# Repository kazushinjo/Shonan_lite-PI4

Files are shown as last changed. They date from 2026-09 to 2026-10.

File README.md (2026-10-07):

# Shonan for RasPI4

Raspberry Pi 4 + ADALM-Pluto+によるDVB-S2 DATV送受信タッチGUIシステム。
本体は`pi4/`配下(Python/PyQt5。DFRobot DFR0550は`linuxfb`、公式DSIタッチ画面は`eglfs`で描画)。同系統の別プラットフォーム
移植版(Android/iOS)は別リポジトリ(`Shonan_Lite-android`/`Shonan_Lite-iPad`等)
で管理している。

A touch-GUI DVB-S2 DATV transceiver system using a Raspberry Pi 4 and an ADALM-Pluto+.
The application lives under `pi4/` (Python/PyQt5; drawn with `linuxfb` on the DFRobot DFR0550 and with `eglfs` on the
official DSI touch display). Ports to other platforms (Android/iOS) are maintained in separate repositories
(`Shonan_Lite-android`, `Shonan_Lite-iPad`, etc.).

> [!IMPORTANT]
> **Plutoのユーザー名(`root`)・パスワード(`analog`)はデフォルト値のまま変更しないでください。**
> 本アプリとLangstone V2Modifyは、SSHでPlutoにログインしてリブートや設定ファイルの書き込みを行っています
> (アプリ再起動・機器試験・送受信開始時・Langstone終了時)。変更するとPlutoをリブートできなくなります。
>
> **Keep the Pluto's username (`root`) and password (`analog`) at their default values.**
> This app and Langstone V2Modify log in to the Pluto via SSH to reboot it and write its settings file
> (at app restart, equipment test, TX/RX start and Langstone exit). If they are changed, the Pluto cannot be rebooted.

## 主な機能 / Features

- **送信**: 周波数・シンボルレート(250k〜2 Msym/s)・FEC・変調方式(QPSK/8PSK)・出力減衰量を画面で設定し、
  UDP-TSでPluto+へ送ってPluto内蔵の変調器(`pluto_dvb`)で送信する(Plutoの設定はSSHで`/www/settings.txt`へ
  書き込み、送信先ポートは8282固定)。FECは変調方式ごとに動作する組み合わせだけを選べる
  (QPSK: 1/2・3/5・8/9、8PSK: 3/5・8/9)。H.264はPi 4内蔵のハードウェアエンコーダ(`h264_v4l2m2m`)で符号化し、
  送信映像はフルHD(1920x1080)固定。音声はカメラ内蔵マイクをAAC(モノラル16kbps)で映像と一緒に送信する(マイクが無ければ無音)。送信画面には出力減衰(dB)、
  Plutoへ送ったUDPパケット数、符号化したフレーム数を表示する。
- **映像ソース**: USBカメラ・画像ファイル(静止画を反復送信)・テストパターンから選ぶ。USBカメラは
  1280x720で取り込む(対応していればMJPEG・30fps、非対応カメラは既定の解像度)。カメラ選択時は
  「撮影」ボタンで静止画(JPG、`~/Pictures/Shonan_Lite/`)を撮り、そのまま送信画像に使える。
  コールサイン・備考を文字サイズ・文字色を選んで映像へ焼き込める(日時も表示)。
- **受信**: 外部復調機器からのUDP-TS受信、またはGNU Radio(gr-dvbs2rx)によるPi 4上でのオンデバイス復調。
- **RSSI測定**: 周波数を掃引して受信レベルをグラフ表示する。オンデバイス復調OFF(通常運用)では
  相手局の電波を測り、ON(テスト用)では自局もテストパターンで自動送信して自分の信号を測る。
- **プリセット**: 現在の設定を5件まで登録・呼び出し(プリセット1は未登録の間RFループバック試験用)。
- **機器試験**: 「全体試験」でPlutoを再起動したうえで、Pluto SDR接続・送信テスト・受信テスト・
  温度センサー(Pi 4のCPU温度)の4項目を順に確認し、TX/RXの総合結果を表示する。実行中のボタンは赤で表示する。
- **10GHz受信(LNB)**: Home画面の衛星をタップすると、Langstone V2Modifyを10236.5 MHz表示・
  Pluto受信486.5 MHz(LNB局部発振9750 MHz)の受信専用バンドで開く。Shonan_Lite(DATV)でも、
  周波数画面で「10GHz帯」を押すとLNBを使用するか確認し、使用する場合は表示周波数10.2365 GHz・
  Pluto受信486.5 MHzで受信する(受信専用、送信不可。「いいえ」なら従来どおり10180 MHz)。下記参照。
- **PA/LNAの送受信切替**: 送信中はPi 4のGPIO21(40番ピン)がHIGHになる。ESP32 W5500
  (PA_Power/PTTコントローラ)を使わなくても、この信号でPA・LNAを切り替えられる。下記参照。
- **その他**: Pluto URIの自動検出、日本語/英語表示、日本語オンスクリーンキーボード、アプリ内Help、
  起動時のアプリ選択(Shonan_Lite / Langstone)。DFRobot DFR0550(`linuxfb`)と公式DSIタッチ画面(`eglfs`)に対応。

<!-- English -->

- **Transmit**: Set the frequency, symbol rate (250k–2 Msym/s), FEC, modulation (QPSK/8PSK) and attenuation on screen,
  send UDP-TS to the Pluto+ and transmit with the Pluto's built-in modulator (`pluto_dvb`) (the Pluto settings are
  written to `/www/settings.txt` via SSH; the destination port is fixed at 8282). Only FEC rates that work with each
  modulation can be selected (QPSK: 1/2, 3/5, 8/9; 8PSK: 3/5, 8/9). H.264 is encoded with the Pi 4's hardware encoder
  (`h264_v4l2m2m`), and the transmitted video is fixed at Full HD (1920x1080). Audio from the camera's built-in microphone is sent with the video as AAC (mono, 16 kbps); silence if no microphone is found. The TX screen shows
  the attenuation (dB), the number of UDP packets sent to the Pluto and the number of encoded frames.
- **Video source**: Choose from a USB camera, an image file (a still image transmitted repeatedly) or a test pattern.
  The USB camera is captured at 1280x720 (MJPEG at 30 fps if supported, otherwise the camera's default resolution).
  With the camera selected, the "Capture" button takes a still image (JPG, `~/Pictures/Shonan_Lite/`) that can be used
  directly as the transmit image. A callsign and a note can be burned into the video with a selectable text size and
  color (the date and time are shown as well).
- **Receive**: UDP-TS reception from an external demodulator, or on-device demodulation on the Pi 4 with GNU Radio (gr-dvbs2rx).
- **RSSI measurement**: Sweeps the frequency and graphs the received level. With on-device demodulation OFF (normal
  operation) it measures the other station's signal; with it ON (for testing) the station also transmits a test
  pattern automatically and measures its own signal.
- **Presets**: Save and recall up to 5 sets of settings (preset 1 is used for the RF loopback test while it is empty).
- **Equipment test**: "Full test" reboots the Pluto and then checks the Pluto SDR connection, TX test, RX test and
  temperature sensor (Pi 4 CPU temperature) in turn, and shows the overall TX/RX result. The running button is shown in red.
- **10 GHz reception (LNB)**: Tapping the satellite on the Home screen opens Langstone V2Modify on a receive-only band
  showing 10236.5 MHz, with the Pluto receiving at 486.5 MHz (LNB local oscillator 9750 MHz). In Shonan_Lite (DATV) as
  well, pressing "10GHz Band" on the Frequency screen asks whether to use an LNB; if so, it receives with the displayed
  frequency 10.2365 GHz and the Pluto receiving at 486.5 MHz (receive only, no transmit; "No" keeps 10180 MHz as before). See below.
- **PA/LNA TX/RX switching**: GPIO21 (pin 40) of the Pi 4 goes HIGH while transmitting. The PA and LNA can be switched
  with this signal even without the ESP32 W5500 (PA_Power/PTT controller). See below.
- **Other**: Automatic Pluto URI detection, Japanese/English display, Japanese on-screen keyboard, in-app Help, and
  application selection at boot (Shonan_Lite / Langstone). Supports the DFRobot DFR0550 (`linuxfb`) and the official DSI
  touch display (`eglfs`).

## スクリーンショット / Screenshots

実機(DFR0550、800x480)の画面(2026-09-25撮影)。映像はすべてテストパターンで撮影している。
送信画面は送信中、RSSI測定はオンデバイス復調ONで「1回」実行した結果(自局のテストパターン信号)。

Screens on the device (DFR0550, 800x480, taken on 2026-09-25). All video was taken with the test pattern.
The TX screen is shown while transmitting, and RSSI measurement shows the result of a "Once" run with on-device
demodulation ON (the station's own test-pattern signal).

| Home画面 / Home | 送信画面 / TX | 受信画面 / RX | RSSI測定 / RSSI |
| --- | --- | --- | --- |
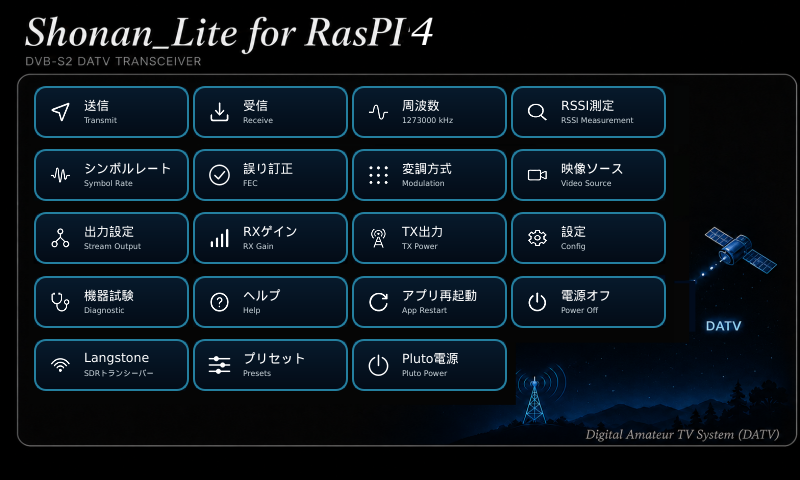
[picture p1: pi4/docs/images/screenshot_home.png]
Home画面
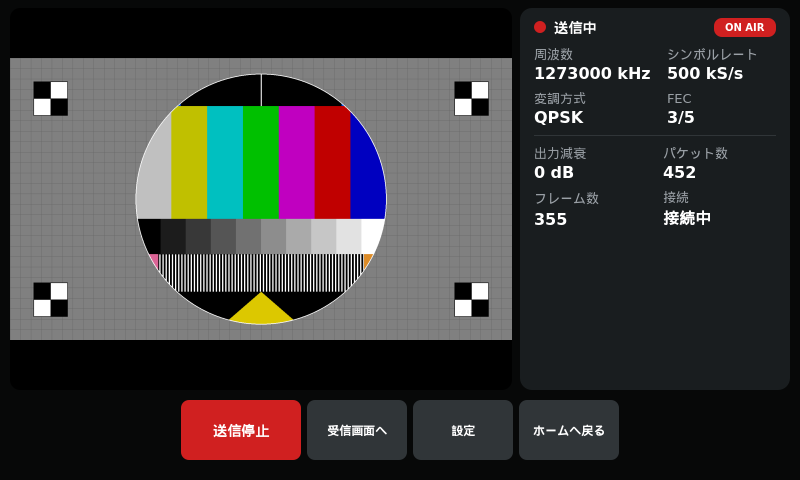
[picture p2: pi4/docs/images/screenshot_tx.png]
送信画面
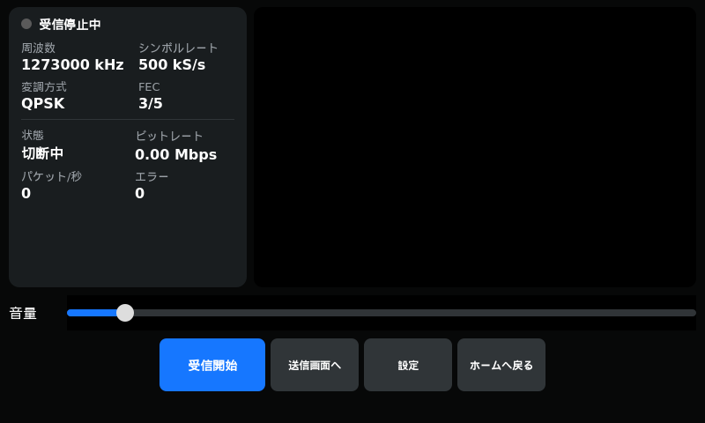
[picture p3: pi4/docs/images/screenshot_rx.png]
受信画面
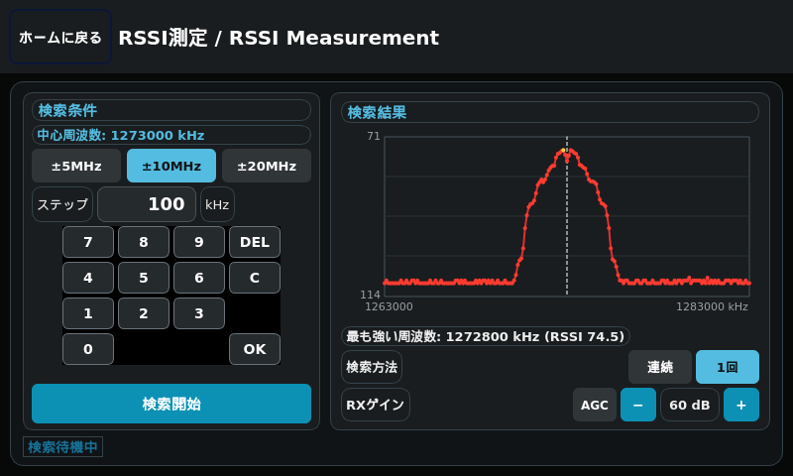
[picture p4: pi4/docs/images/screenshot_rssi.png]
RSSI測定
|  |  |  |  |

| 映像ソース / Video Source | 変調方式 / Modulation | 出力設定 / Stream Output | プリセット / Presets |
| --- | --- | --- | --- |
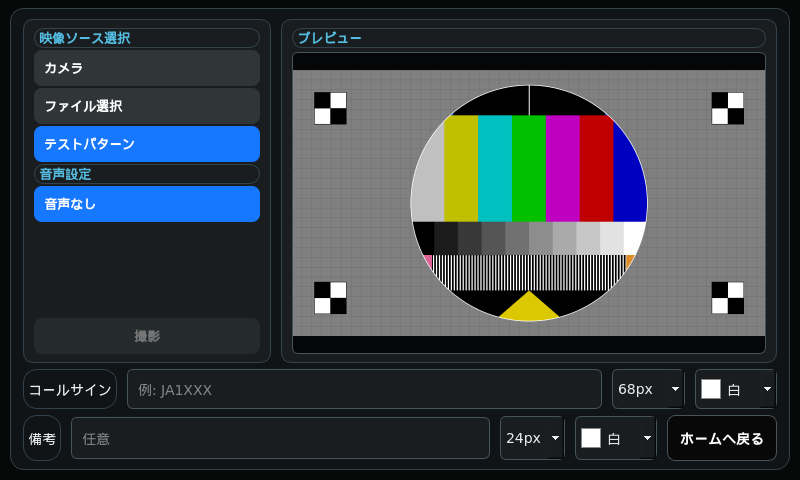
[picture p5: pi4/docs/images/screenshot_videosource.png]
映像ソース
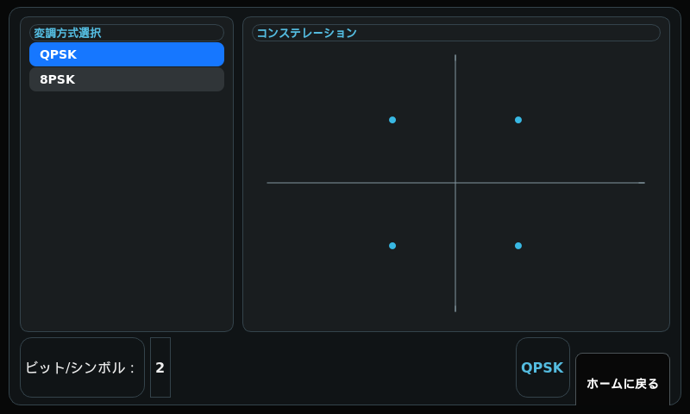
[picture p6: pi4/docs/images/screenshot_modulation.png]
変調方式
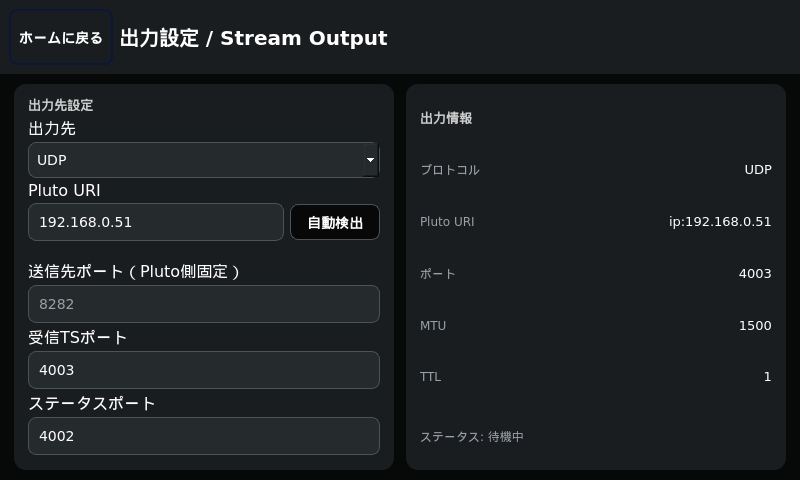
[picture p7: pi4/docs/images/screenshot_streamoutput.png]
出力設定
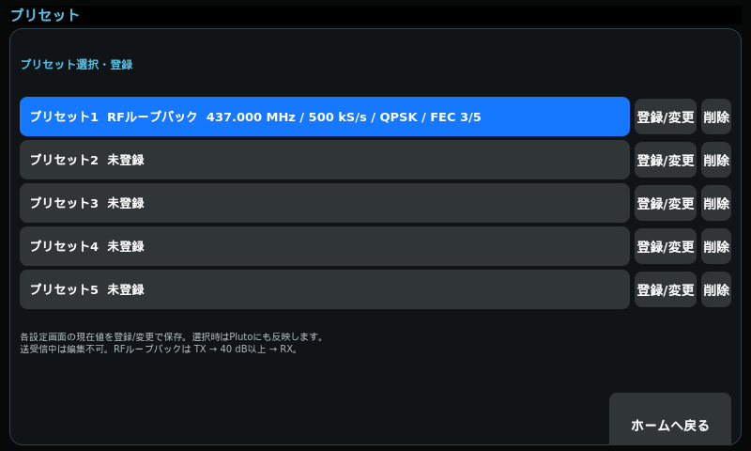
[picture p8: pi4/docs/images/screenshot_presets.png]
プリセット
|  |  |  |  |

| 機器試験 / Diagnostic | 設定 / Config | 周波数 / Frequency | 電源オフ / Power Off |
| --- | --- | --- | --- |
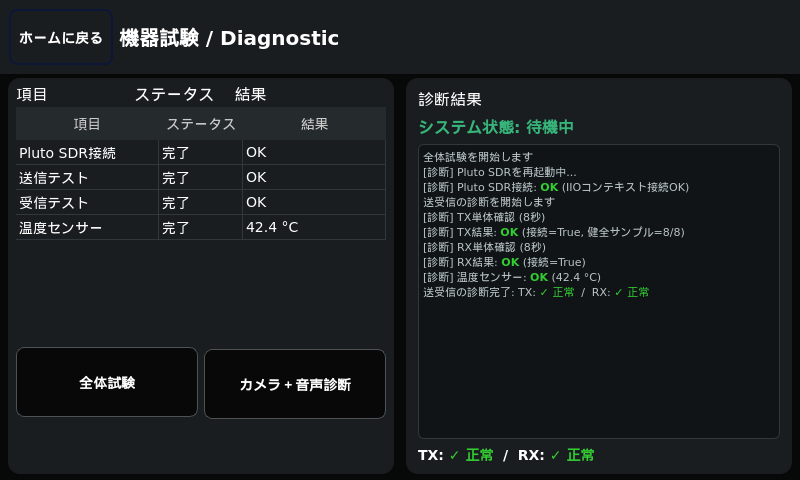
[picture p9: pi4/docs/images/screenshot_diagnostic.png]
機器試験
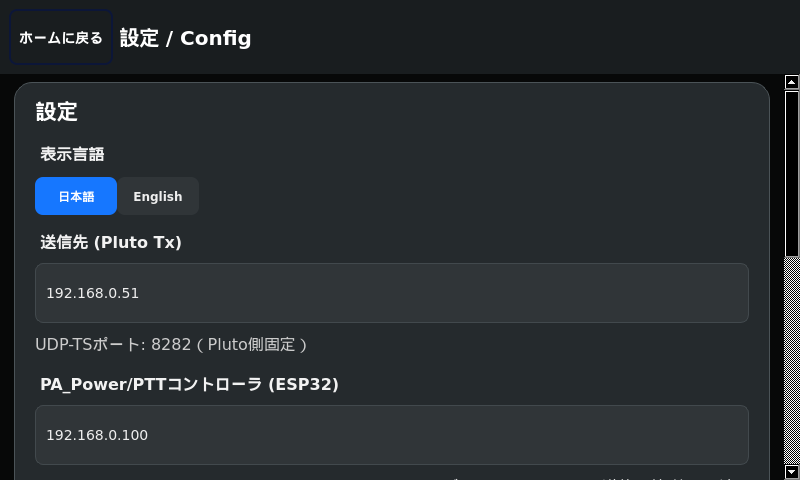
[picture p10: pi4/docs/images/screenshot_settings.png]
設定
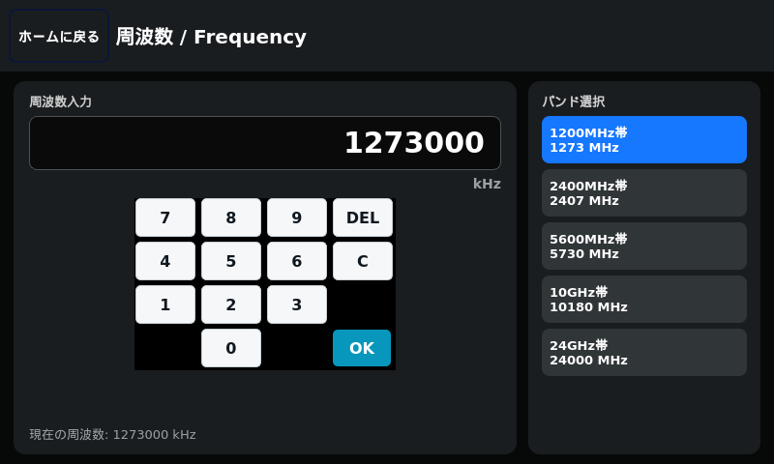
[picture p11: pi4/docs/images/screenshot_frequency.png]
周波数
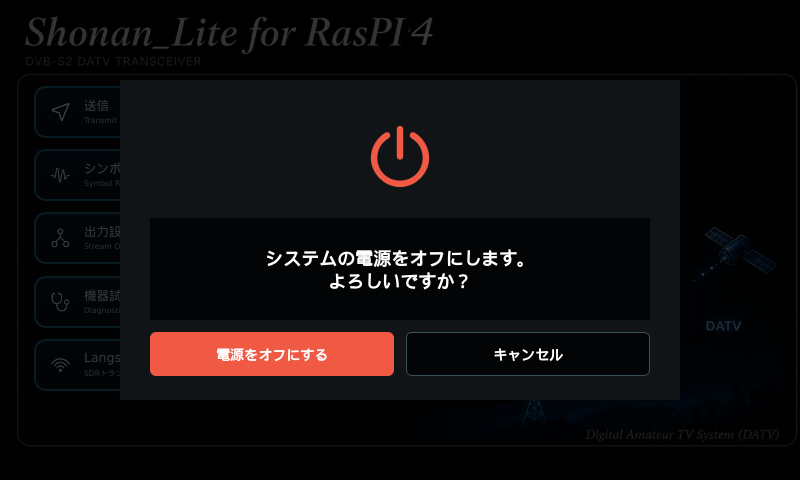
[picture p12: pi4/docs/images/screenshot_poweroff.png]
電源オフ
|  |  |  |  |

各画面の操作方法は、アプリ内の「ヘルプ」または操作説明書
[`pi4/docs/shonan_pi4_operation_manual.docx`](pi4/docs/shonan_pi4_operation_manual.docx)を参照。

For how to operate each screen, see the in-app "Help" or the operation manual
[`pi4/docs/shonan_pi4_operation_manual.docx`](pi4/docs/shonan_pi4_operation_manual.docx).

## インストール / Installation

### 0. Raspberry Pi OSのインストール / Installing Raspberry Pi OS

Pi4本体に、あらかじめRaspberry Pi OSをインストールしておく。

1. PCで[Raspberry Pi Imager](https://www.raspberrypi.com/software/)を起動する。
2. 「デバイスを選択」で **Raspberry Pi 4** を選ぶ。
3. 「OSを選択」で **Raspberry Pi OS (64-bit)** を選ぶ
   (★32bit版は不可。下記「実行条件」参照)。
4. 「ストレージを選択」で書き込み先のmicroSD/NVMeを選ぶ。
5. 歯車アイコン(詳細設定)で、ホスト名・ユーザー名/パスワード・Wi-Fi・SSH有効化を
   事前設定しておくと、初回起動後すぐSSH接続できる。
6. 「書き込む」を実行し、完了後microSD/NVMeをPi4に取り付けて起動する。
7. PCから`ssh <ユーザー名>@<ホスト名>.local`で接続できることを確認する。

Install Raspberry Pi OS on the Pi 4 beforehand.

1. Start [Raspberry Pi Imager](https://www.raspberrypi.com/software/) on a PC.
2. Under "Choose Device", select **Raspberry Pi 4**.
3. Under "Choose OS", select **Raspberry Pi OS (64-bit)**
   (★the 32-bit version does not work; see "Requirements" below).
4. Under "Choose Storage", select the microSD/NVMe to write to.
5. In the gear icon (advanced options), pre-configure the hostname, username/password, Wi-Fi and SSH
   so that you can connect via SSH right after the first boot.
6. Run "Write", then attach the microSD/NVMe to the Pi 4 and boot it.
7. Check that you can connect from the PC with `ssh <username>@<hostname>.local`.

### 1. install.shの実行 / Running install.sh

SSH接続したPi4上で / On the Pi 4 connected via SSH:

```sh
git clone https://github.com/kazushinjo/Shonan_lite-PI4.git
cd Shonan_lite-PI4
./pi4/scripts/install.sh          # HTTPSでclone(既定) / clone via HTTPS (default)
# ./pi4/scripts/install_ssh.sh    # GitHubにSSH鍵を登録済みならこちらでも可 / or this if your SSH key is registered on GitHub
```

日本語入力ビルド・受信(RX)用GNU Radio/gr-dvbs2rxビルド・Langstone V2Modifyビルドは
それぞれ省略して時間短縮できる(省略した機能は使えなくなる):

The Japanese input build, the GNU Radio/gr-dvbs2rx build for RX and the Langstone V2Modify build can each be
skipped to save time (the skipped features will not be available):

```sh
SKIP_JA_KEYBOARD=1 SKIP_GNURADIO_BUILD=1 SKIP_LANGSTONE_BUILD=1 ./pi4/scripts/install.sh
```

★OSを新規インストールした直後の初回実行では、DFR0550をfirmwareのレガシーDSI表示で
動かすため、`install.sh`が最初に`/boot/firmware/config.txt`の`dtoverlay=vc4-kms-v3d`・
`display_auto_detect=1`・`disable_fw_kms_setup=1`をコメントアウトし、`dtparam=i2c_arm=on`を
追記して終了する。案内に従ってPi4を再起動(`sudo reboot`)し、同じコマンドを再実行すると
ビルドへ進む(KMS有効のままビルドすると画面・タッチが使えないうえ、実機が再起動して
パッケージが破損することを確認している)。

★On the first run right after a fresh OS install, to drive the DFR0550 with the firmware's legacy DSI display,
`install.sh` first comments out `dtoverlay=vc4-kms-v3d`, `display_auto_detect=1` and `disable_fw_kms_setup=1` in
`/boot/firmware/config.txt`, adds `dtparam=i2c_arm=on`, and exits. Reboot the Pi 4 as instructed (`sudo reboot`) and
run the same command again to proceed to the build (building with KMS enabled leaves the display and touch unusable,
and we confirmed that the device reboots and packages get corrupted).

完了後、`shonan-gui.service`がsystemdに登録されGUIが自動起動する。あわせて
`/boot/firmware/config.txt`へ`avoid_warnings=1`(電源電圧警告アイコンの表示抑制)
を未設定なら自動で追記する(反映には再起動が必要)。

When finished, `shonan-gui.service` is registered with systemd and the GUI starts automatically. It also adds
`avoid_warnings=1` (suppresses the under-voltage warning icon) to `/boot/firmware/config.txt` if not already set
(a reboot is required for it to take effect).

### 実行条件 / Requirements

一般ユーザーが実行して`install.sh`が正常完了するには、以下が必要。

- **Raspberry Pi OS 64bit(aarch64)であること**(32bit版不可)
- **`git`が事前にインストール済み**であること
- **GitHub/apt配布ミラーへのインターネット到達性**
- **sudoが使える対話的な実行**(パスワード入力に応答できるtty)
- **`patch`コマンドが使えること**

For `install.sh` to complete successfully when run as a normal user, the following are required.

- **Raspberry Pi OS 64-bit (aarch64)** (the 32-bit version does not work)
- **`git` installed beforehand**
- **Internet access to GitHub and the apt mirrors**
- **Interactive execution with sudo** (a tty that can answer the password prompt)
- **The `patch` command available**

詳細な各手順の解説・トラブルシュートは
[`pi4/docs/install_script_guide.md`](pi4/docs/install_script_guide.md)
(DOCX版: `pi4/docs/install_script_guide.docx`)を参照。

For a detailed explanation of each step and troubleshooting, see
[`pi4/docs/install_script_guide.md`](pi4/docs/install_script_guide.md)
(DOCX version: `pi4/docs/install_script_guide.docx`).

## オプション: ESP32 W5500(PA_Power/PTTコントローラ) / Option: ESP32 W5500 (PA_Power/PTT controller)

ESP32とW5500(有線LAN)で、PA等の12 V電源とPTTをLAN経由でON/OFFするオプションの制御基板。
使わなくてもShonan_Liteは動作する(PTTだけなら下記のPi 4 GPIO21で切替できる)。
ファームウェアは[`hardware/W5500_PA_PTT_Control/W5500_PA_PTT_Control.ino`](hardware/W5500_PA_PTT_Control/W5500_PA_PTT_Control.ino)、
基板は[`hardware/W5500_PA_PTT_Control/kicad/`](hardware/W5500_PA_PTT_Control/kicad/)(KiCad、Rev.1.0)。基板とファームウェアはShonan_Lite-RasPI5版と共通。

| 基板の3D表示 / 3D view of the board | 基板レイアウト(KiCad) / PCB layout (KiCad) | ケース(OpenSCAD) / Case (OpenSCAD) |
| --- | --- | --- |
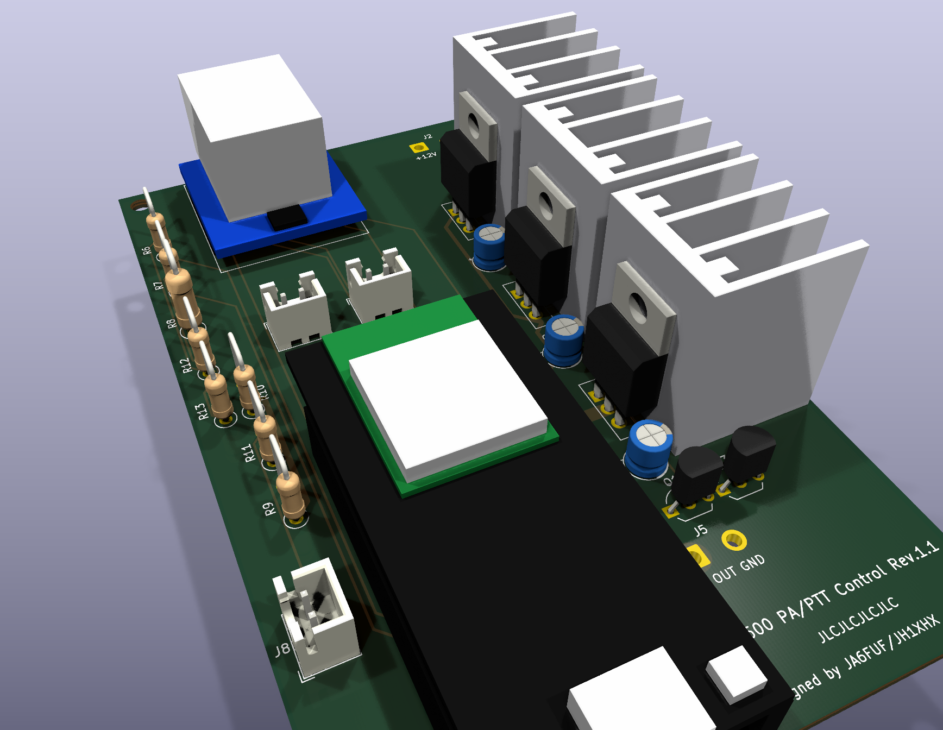
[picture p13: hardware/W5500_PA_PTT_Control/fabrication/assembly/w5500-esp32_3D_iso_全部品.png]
基板の3D表示
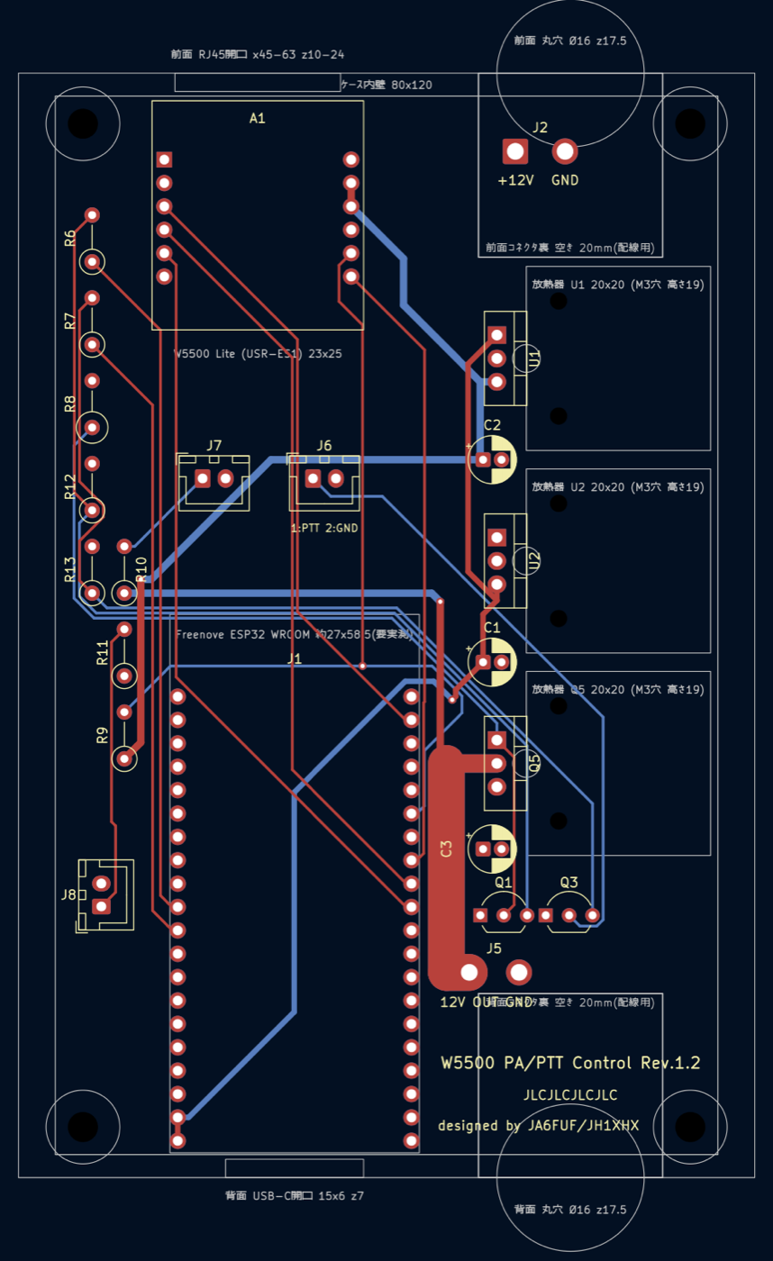
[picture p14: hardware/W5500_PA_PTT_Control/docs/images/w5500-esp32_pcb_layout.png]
基板レイアウト
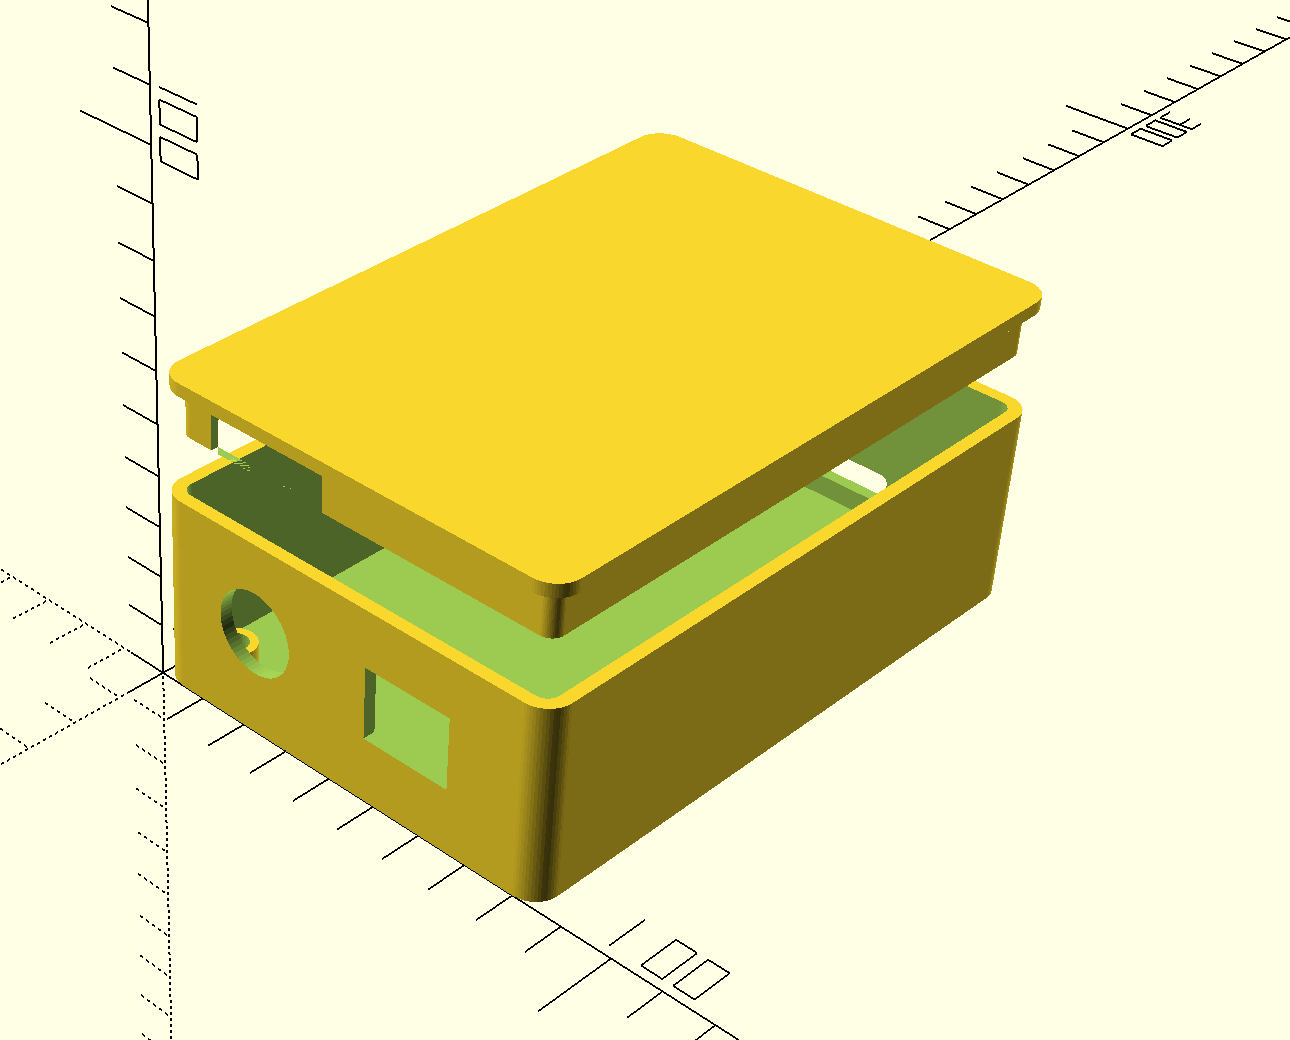
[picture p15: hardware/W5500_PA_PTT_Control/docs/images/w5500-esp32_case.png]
ケース
|  |  |  |

| 項目<br>Item | 内容<br>Details |
| --- | --- |
| 構成<br>Configuration | Freenove ESP32-WROOM-32E DevKitC(ソケットに差し込み)+W5500 Lite(SPI接続)<br>Freenove ESP32-WROOM-32E DevKitC (plugged into a socket) + W5500 Lite (SPI) |
| 12 V電源<br>12 V power | 2SJ334(Pチャネル MOSFET)のハイサイドスイッチでJ5の12 V出力をON/OFF。放熱器付きで目安は約7 Aまで<br>J5's 12 V output is switched by a 2SJ334 (P-channel MOSFET) high-side switch; with its heatsink, up to about 7 A |
| PTT<br>PTT | 2SC1815で無線機のPTT端子をGNDへ落とす(J6)<br>A 2SC1815 pulls the radio's PTT line to GND (J6) |
| 電源入力<br>Power input | +12 V(13.8 V系)をJ2へ。L7805で5 V(ESP32)、TA48033Sで3.3 V(W5500)を作る<br>+12 V (13.8 V class) to J2; an L7805 makes 5 V (ESP32) and a TA48033S makes 3.3 V (W5500) |
| 表示LED<br>Indicator LEDs | 外付け。J7=12 V出力(赤)、J8=12 V入力(緑)(JST XH)<br>External; J7 = 12 V output (red), J8 = 12 V input (green) (JST XH) |
| ネットワーク<br>Network | 固定IP(初期値`192.168.0.100`)。ブラウザで`http://<IP>/`を開くと手動でON/OFFでき、`http://<IP>/config`でIPや遅延時間を変更できる<br>Static IP (default `192.168.0.100`); open `http://<IP>/` in a browser to switch ON/OFF manually, and `http://<IP>/config` to change the IP and delays |
| 基板<br>Board | 72×115 mm、4層(内層はGNDと+12Vのベタ)、部品はすべてスルーホール。JLCPCBの発注データは[`fabrication/jlcpcb/`](hardware/W5500_PA_PTT_Control/fabrication/jlcpcb/)<br>72×115 mm, 4 layers (inner layers are GND and +12 V planes), all through-hole parts. JLCPCB order data is in [`fabrication/jlcpcb/`](hardware/W5500_PA_PTT_Control/fabrication/jlcpcb/) |
| ケース<br>Case | OpenSCAD(LAN_PTT.scad)、内寸80×120×35 mm。前面にRJ45の角穴と+12V入力の丸型コネクタ、背面にUSBの穴と12 V出力・PTTの丸型コネクタ<br>OpenSCAD (LAN_PTT.scad), inside 80×120×35 mm. RJ45 opening and +12 V input circular connector on the front; USB opening and 12 V output/PTT circular connector on the back |

Shonan_Liteでの使い方:

- 設定画面の「PA_Power/PTTコントローラ (ESP32)」で「ESP32 W5500を使用する」をONにし、ESP32のIPアドレスを入力する。
- アプリの起動/終了に連動して12 V電源(Pluto含む)を、送信開始/終了に連動してPTTを自動でON/OFFする(Langstone V2Modifyの送信でもPTTが切り替わる)。
- ホーム画面の「Pluto電源」カードで、12 V系統を手動で電源サイクル(OFF→3秒待機→ON)できる。

詳しくは[仕様書](hardware/W5500_PA_PTT_Control/docs/W5500_PA_PTT_Control_仕様書.md)と
[接続一覧](hardware/W5500_PA_PTT_Control/docs/MCU1_J1_W5500_接続一覧.md)を参照(どちらも日英併記。Word版・PDF版も同じフォルダにある)。
回路図: [`w5500-esp32.pdf`](hardware/W5500_PA_PTT_Control/kicad/w5500-esp32.pdf)、
実装図: [`w5500-esp32_実装図_部品番号.pdf`](hardware/W5500_PA_PTT_Control/fabrication/assembly/w5500-esp32_実装図_部品番号.pdf)。

> [!NOTE]
> ESP32への書き込みと起動は確認済み。12 V電源・PTTの駆動回路と無線機をつないだ実地試験はまだ行っていない。

<!-- English -->

An optional control board that uses an ESP32 and a W5500 (wired LAN) to switch the 12 V power for the PA etc.
and the PTT ON/OFF over the LAN. Shonan_Lite works without it (PTT alone can be switched with the Pi 4 GPIO21 below).
The firmware is [`hardware/W5500_PA_PTT_Control/W5500_PA_PTT_Control.ino`](hardware/W5500_PA_PTT_Control/W5500_PA_PTT_Control.ino)
and the board is in [`hardware/W5500_PA_PTT_Control/kicad/`](hardware/W5500_PA_PTT_Control/kicad/) (KiCad, Rev.1.0). The board and firmware are shared with the
Shonan_Lite-RasPI5 edition.

How to use it with Shonan_Lite:

- On the Settings screen, turn on "Use ESP32 W5500" under "PA_Power/PTT Controller (ESP32)" and enter the ESP32's IP address.
- The 12 V power (including the Pluto) is switched ON/OFF with app start/exit, and the PTT with TX start/stop (PTT also follows TX in Langstone V2Modify).
- The "Pluto Power" card on the Home screen power-cycles the 12 V line manually (OFF → wait 3 s → ON).

For details, see the [specification](hardware/W5500_PA_PTT_Control/docs/W5500_PA_PTT_Control_仕様書.md) and the
[connection list](hardware/W5500_PA_PTT_Control/docs/MCU1_J1_W5500_接続一覧.md) (both in Japanese and English;
Word and PDF versions are in the same folder).
Schematic: [`w5500-esp32.pdf`](hardware/W5500_PA_PTT_Control/kicad/w5500-esp32.pdf);
assembly drawing: [`w5500-esp32_実装図_部品番号.pdf`](hardware/W5500_PA_PTT_Control/fabrication/assembly/w5500-esp32_実装図_部品番号.pdf).

> [!NOTE]
> Flashing and booting the ESP32 have been confirmed. A field test with the 12 V power/PTT drive circuits
> connected to a radio has not been done yet.

## PA/LNAの送受信切替(ESP32 W5500なしでも可) / PA/LNA TX/RX switching (possible without ESP32 W5500)

ESP32 W5500(PA_Power/PTTコントローラ、[`hardware/W5500_PA_PTT_Control`](hardware/W5500_PA_PTT_Control))は
使わなくても、RasPI4からのPTT ON信号でPA・LNAの送受信切替を制御できる。

| 項目<br>Item | 内容<br>Details |
| --- | --- |
| 出力ピン<br>Output pin | Pi 4 GPIO21(40番ピン)、GNDは39番ピン<br>Pi 4 GPIO21 (pin 40), GND on pin 39 |
| 論理<br>Logic | 送信中HIGH(3.3 V)、受信中LOW<br>HIGH (3.3 V) while transmitting, LOW while receiving |
| 対象<br>Applies to | Shonan_Liteの送信・Langstone V2Modifyの送信(Langstone標準のTx Output)のどちらも同じピン<br>Both Shonan_Lite TX and Langstone V2Modify TX (Langstone's standard Tx Output) use the same pin |

- GPIO21は3.3 Vロジックで電流を取れないため、トランジスタやリレードライバ等でバッファしてから
  PA・LNA(同軸リレー等)を駆動すること。
- Shonan_Liteは送信開始時(映像送出の前)にHIGH、送信停止時とアプリ起動時にLOWにする
  ([`pi4/gui/backend.py`](pi4/gui/backend.py)の`_set_pi_tx_gpio()`、`pinctrl`で出力)。
- ESP32 W5500を併用する場合は、送信の開始/停止に連動してESP32のPTT出力(J6)も同時に切り替わる
  (`/tx?state=on|off`)。12 V電源のON/OFFとホーム画面の「Pluto電源」カードはESP32 W5500が必要。
  ESP32を使うかどうかは設定画面の「ESP32 W5500を使用する」で選ぶ(OFFにしてもIPアドレスは保持される)。

<!-- English -->

The PA and LNA can be switched between TX and RX by the PTT ON signal from the RasPI4, even without the
ESP32 W5500 (PA_Power/PTT controller, [`hardware/W5500_PA_PTT_Control`](hardware/W5500_PA_PTT_Control)).

- GPIO21 is a 3.3 V logic output that cannot supply current. Buffer it with a transistor, relay driver or
  similar before driving the PA and LNA (coax relays, etc.).
- Shonan_Lite sets it HIGH when TX starts (before the video is sent) and LOW when TX stops and at app startup
  (`_set_pi_tx_gpio()` in [`pi4/gui/backend.py`](pi4/gui/backend.py), driven with `pinctrl`).
- When the ESP32 W5500 is also used, its PTT output (J6) switches together with TX start/stop (`/tx?state=on|off`).
  Switching the 12 V power ON/OFF and the "Pluto Power" card on the Home screen require the ESP32 W5500. Whether to use
  the ESP32 is selected with "Use ESP32 W5500" on the Settings screen (the IP address is kept even when OFF).

## Langstone V2Modify(SDRトランシーバー)への切替 / Switching to Langstone V2Modify (SDR transceiver)

Home画面の「Langstone」カードから、`kazushinjo/Langstone-V2Modify`
(VHF/UHF/マイクロ波帯SDRトランシーバー、ADALM-Pluto対応)へ切り替えられる。
Langstone V2ModifyはQt eglfsとは別に`/dev/fb0`を直接描画する独立アプリのため、
DATV送受信アプリとは同時起動できない。`shonan-gui.service`/`langstone.service`/
`shonan-boot-menu.service`はsystemdの`Conflicts=`で互いに排他制御されるため、
Pi4自体は再起動せず、サービスを直接切り替える。

- Shonan_Lite Home画面の「Langstone」カード → DATVの送受信を止めてLangstone V2Modifyが起動
- Langstone V2Modifyの設定メニュー内「GOTO SHONAN_LITE」ボタン → Shonan_Lite Home画面に戻る

切替時間を短くするため、切替のときはPluto+を再起動しない(Pi5版で、再起動しなくても両アプリの
送受信が正常に動くことを確認済み)。ただしLangstoneは受信中に送信LOを止めたまま終了するため、
戻るときはLangstone側・Shonan_Lite側の両方で送信LOを元に戻す。Shonan_Liteは起動時(電源投入時を含む)に
Pluto+を再起動しない(ホーム画面の「アプリ再起動」と、Langstoneを「GOTO SHONAN_LITE」以外で終了したときは再起動する)。
Langstone側は`/tmp/langstone_goto_shonan`、Shonan_Lite側は`/tmp/shonan_switch_from_langstone`
の印で切替かどうかを判断する。

Langstone V2Modify is a standalone app that draws directly to `/dev/fb0` separately from Qt eglfs, so it cannot run at
the same time as the DATV app. `shonan-gui.service`, `langstone.service` and `shonan-boot-menu.service` are mutually
exclusive through systemd's `Conflicts=`, so the services are switched directly without rebooting the Pi 4.

- "Langstone" card on the Shonan_Lite Home screen → DATV TX/RX is stopped and Langstone V2Modify starts
- "GOTO SHONAN_LITE" button in the Langstone V2Modify settings menu → returns to the Shonan_Lite Home screen

To shorten the switching time, the Pluto+ is not rebooted when switching (confirmed on the Pi 5 version that both apps
transmit and receive normally without a reboot). However, Langstone exits with the TX LO powered down while receiving,
so the TX LO is restored on both the Langstone side and the Shonan_Lite side when returning. Shonan_Lite does not
reboot the Pluto+ when it starts (including at power-up); it is rebooted by "App Restart" on Home and when Langstone
exits other than via "GOTO SHONAN_LITE".
The Langstone side uses the `/tmp/langstone_goto_shonan` marker and the Shonan_Lite side uses
`/tmp/shonan_switch_from_langstone` to tell whether it is a switch.

内部的には`~/.pi4_boot_mode_langstone`マーカーファイルの有無をsystemdの
`ConditionPathExists`で判定し、`shonan-gui.service`/`langstone.service`の
どちらを起動すべきかを決める。

Internally, systemd's `ConditionPathExists` checks for the `~/.pi4_boot_mode_langstone` marker file to decide whether
`shonan-gui.service` or `langstone.service` should start.

ウォーターフォール/スペクトラム表示は幅約512px→約790pxへ拡張済み
(FFT点数自体はGNU Radio側のfft_size=512のまま、SCALEPX()マクロで描画のみ
引き伸ばしている。帯域インジケータ・目盛り・タッチ判定も含め一貫して変換)。
横方向にはSQLボタン(x=30〜130)/Volボタン(x=660〜)と同じY帯で重なり広げる
余地が無かったため、スペクトラム欄の高さ(80→55px)とウォーターフォールの
表示履歴行数(130→90行)を縮めて表示位置を上に詰め、SQL/Vol/RITいずれとも
Y方向に重ならない帯(Y=130〜295)に収めることで横方向をほぼ画面全幅まで
広げた(実機で確認)。
統合元は`kazushinjo/Langstone-V2Modify`で、Pi 4 + DFRobot DFR0550 +
ADALM-Pluto向けの修正を含む。

The waterfall/spectrum display has been widened from about 512 px to about 790 px (the number of FFT points stays at
fft_size=512 on the GNU Radio side; only the drawing is stretched by the SCALEPX() macro, applied consistently to the
bandwidth indicator, scale and touch detection). Since there was no room to widen it horizontally in the same Y band as
the SQL button (x=30–130) and Vol button (x=660–), the spectrum area height (80 → 55 px) and the number of waterfall
history rows (130 → 90) were reduced and the display moved up into a band (Y=130–295) that does not overlap SQL/Vol/RIT
vertically, which allows it to extend to nearly the full screen width (confirmed on the device). It is integrated from
`kazushinjo/Langstone-V2Modify` and includes fixes for the Pi 4 + DFRobot DFR0550 + ADALM-Pluto.

`kazushinjo/Langstone-V2Modify`が更新された場合は、
[`pi4/scripts/update_langstone_from_upstream.sh`](pi4/scripts/update_langstone_from_upstream.sh)
で同梱コピーを更新できる。更新後はShonan切替用のマーカー処理・受信専用バンド(`bandRxOnly`)など、
統合固有の差分を確認してから使用すること。

When `kazushinjo/Langstone-V2Modify` is updated, the bundled copy can be updated with
[`pi4/scripts/update_langstone_from_upstream.sh`](pi4/scripts/update_langstone_from_upstream.sh).
After updating, check the integration-specific differences, such as the Shonan switching markers and the receive-only
band (`bandRxOnly`), before use.

### 10GHz受信(LNB) — Home画面の衛星をタップ / 10 GHz reception (LNB) — tap the satellite on the Home screen

Home画面の背景右側の衛星をタップすると、Langstone V2Modifyを**10GHz受信用のバンド**で
開く(普通の「Langstone」カードと同じく、Plutoは再起動しない)。アンテナ側で
LNB(局部発振9750 MHz)を使い、10 GHz帯を486.5 MHzへ下げて受信する前提。

Tapping the satellite on the right side of the Home screen background opens Langstone V2Modify on a
**band for 10 GHz reception** (as with the normal "Langstone" card, the Pluto is not rebooted).
This assumes an LNB (local oscillator 9750 MHz) on the antenna side that converts the 10 GHz band down to 486.5 MHz.

| 項目<br>Item | 値<br>Value |
| --- | --- |
| 画面の表示周波数<br>Displayed frequency | 10236.500 MHz(10.2365 GHz)<br>10236.500 MHz (10.2365 GHz) |
| Plutoの受信周波数<br>Pluto receive frequency | 486.5 MHz(= 10236.5 − 9750) |
| 受信オフセット<br>Receive offset | −9750 MHz(LNB 局部発振 9750 MHz)<br>−9750 MHz (LNB local oscillator 9750 MHz) |
| 送信<br>Transmit | **不可**(受信専用)<br>**Not possible** (receive only) |

- Langstoneの24バンドのうち、通常使われない最後のバンド(番号23、画面上は24番目)を
  このために使う。衛星をタップするたびに、Shonan_Liteが`~/Langstone/Langstone_Pluto.conf`
  のこのバンドを上の値に設定し直してから開く([`pi4/gui/langstone_config.py`](pi4/gui/langstone_config.py))。
- 486.5 MHzはアマチュアバンド外のため、このバンドは**受信専用**
  (設定ファイルの`bandRxOnly23 1`、Langstone側の改造)。画面のPTT・ハードウェアPTT・
  CWキー・ビーコンのいずれでも送信せず、PA_Power/PTTコントローラも送信に切り替えない。
  PTTボタンは灰色の「RX ONLY」表示になり、Plutoの送信LOも停止させる。
- 普通の「Langstone」カードで開いたときは、衛星から開く前に使っていたバンドに戻して開く
  (Langstone上で別のバンドに切り替えていた場合は、そのバンドのまま)。
- Shonan_Lite(DATV)で10GHzをLNB受信する場合は、衛星ではなく周波数画面の「10GHz帯」を押し、
  「LNBを使用しますか?」で「はい」を選ぶ(表示10.2365 GHz、Pluto受信486.5 MHz、受信専用で送信不可。
  受信画面・RSSI測定もPluto受信周波数で動作する)。他のバンドを選ぶとLNBは解除される。
- LNBへの電源供給(同軸経由のバイアスT、12〜18 V)はShonan_Lite/Langstoneでは扱わない。
  別途用意すること。

<!-- English -->

- Of Langstone's 24 bands, the last one, which is not normally used (number 23, the 24th on screen), is used for this.
  Every time the satellite is tapped, Shonan_Lite resets this band in `~/Langstone/Langstone_Pluto.conf` to the values
  above before opening ([`pi4/gui/langstone_config.py`](pi4/gui/langstone_config.py)).
- Because 486.5 MHz is outside the amateur bands, this band is **receive only** (`bandRxOnly23 1` in the configuration
  file, a modification on the Langstone side). It does not transmit from the on-screen PTT, hardware PTT, CW key or
  beacon, and does not switch the PA_Power/PTT controller to transmit. The PTT button is shown grayed out as "RX ONLY",
  and the Pluto's TX LO is also stopped.
- When opened from the normal "Langstone" card, it returns to the band that was in use before opening from the
  satellite (if you switched to another band in Langstone, it stays on that band).
- To receive 10 GHz via an LNB in Shonan_Lite (DATV), press "10GHz Band" on the Frequency screen (not the satellite)
  and answer "Yes" to "Use an LNB?" (displayed 10.2365 GHz, Pluto RX 486.5 MHz, receive only with no transmit; the RX
  screen and RSSI measurement also use the Pluto RX frequency). Selecting another band cancels the LNB.
- Power for the LNB (bias-T over the coax, 12–18 V) is not handled by Shonan_Lite/Langstone. Provide it separately.

## 関連ドキュメント / Related documents

- [`pi4/docs/install_script_guide.md`](pi4/docs/install_script_guide.md) — install.shの詳細ガイド / Detailed guide to install.sh(英語版 / English: [`install_script_guide_en.md`](pi4/docs/install_script_guide_en.md))
- [`pi4/docs/qtvirtualkeyboard_ja_build.md`](pi4/docs/qtvirtualkeyboard_ja_build.md) — 日本語オンスクリーンキーボードのビルド手順・ハマりどころ / Build steps and pitfalls for the Japanese on-screen keyboard
- [`pi4/docs/shonan_pi4_operation_manual.docx`](pi4/docs/shonan_pi4_operation_manual.docx) / [`pi4/gui/manual_content.py`](pi4/gui/manual_content.py) — GUIの操作説明書(アプリ内Helpと同内容。英語のHelpは`pi4/gui/screens/manual.py`) / Operation manual for the GUI (same content as the in-app Help; the English Help is in `pi4/gui/screens/manual.py`)
- [`pi4/docs/build_operation_manual.py`](pi4/docs/build_operation_manual.py) — 操作説明書(DOCX)の生成スクリプト(`python pi4/docs/build_operation_manual.py`、python-docxが必要) / Script that generates the operation manual (DOCX) (requires python-docx)
- [`hardware/W5500_PA_PTT_Control/docs/W5500_PA_PTT_Control_仕様書.md`](hardware/W5500_PA_PTT_Control/docs/W5500_PA_PTT_Control_仕様書.md) — ESP32 W5500(PA_Power/PTTコントローラ)の仕様書 / Specification of the ESP32 W5500 (PA_Power/PTT controller)(日英併記 / Japanese and English)
  - 仕様書・接続一覧のWord版・PDF版は[`hardware/W5500_PA_PTT_Control/docs/tools/build_docs.py`](hardware/W5500_PA_PTT_Control/docs/tools/build_docs.py)でMarkdownから作る(macOSで実行) / The Word and PDF versions of the specification and connection list are generated from Markdown with this script (run on macOS)
- [`hardware/W5500_PA_PTT_Control/docs/MCU1_J1_W5500_接続一覧.md`](hardware/W5500_PA_PTT_Control/docs/MCU1_J1_W5500_接続一覧.md) — ESP32・W5500の接続一覧 / Connection list of the ESP32 and W5500(日英併記 / Japanese and English)
- [`hardware/W5500_PA_PTT_Control/kicad/`](hardware/W5500_PA_PTT_Control/kicad/) — ESP32 W5500制御基板のKiCad回路図・基板 / KiCad schematic and PCB of the ESP32 W5500 control board
- [`pi4/third_party/rpi-dvbs2-receiver-gui/`](pi4/third_party/rpi-dvbs2-receiver-gui/) — GNU Radio/gr-dvbs2rx受信フローグラフの参考実装(kazushinjo/rpi-dvbs2-receiver-guiより取り込み) / Reference implementation of the GNU Radio/gr-dvbs2rx receive flowgraph (imported from kazushinjo/rpi-dvbs2-receiver-gui)

## 免責事項 / Disclaimer

1. **無保証・自己責任 / No warranty; use at your own risk**  
   本ソフトウェアは現状のまま(AS IS)で提供され、動作、品質、特定の目的への適合性を含め、いかなる保証もありません。本ソフトウェアの使用または使用できないことによって生じた、機器の破損、データの消失、電波障害、その他一切の損害について、開発者は責任を負いません。ご自身の責任においてご利用ください。  
   This software is provided "AS IS" without warranty of any kind, including any warranty of operation, quality or fitness for a particular purpose. The developers accept no liability for any damage arising from the use of, or inability to use, this software, including damage to equipment, loss of data and radio interference. Use it at your own risk.
2. **免許と法令の順守 / Licensing and compliance with the law**  
   本ソフトウェアは、アマチュア無線のDATV(デジタルATV)実験のための送受信ソフトウェアです。電波を送信するには、運用する国・地域の法令に基づく免許が必要です(日本国内ではアマチュア局の免許)。周波数、空中線電力、電波の型式、運用できる範囲などの法令(日本国内では電波法および関係規則)を守ってください。免許のない送信や、免許の範囲を超えた送信は、法令違反となることがあります。本ソフトウェアは、設定された周波数・出力・変調方式が法令に適合していることを確認も保証もしません。送信の内容と結果は、すべて使用者の責任です。  
   This software is for amateur-radio DATV (digital ATV) experiments. Transmitting requires a license under the laws of the country or region where you operate (in Japan, an amateur station license). Observe the applicable laws on frequency, transmitter power, emission type and permitted operation (in Japan, the Radio Act and related regulations). Transmitting without a license, or beyond the scope of your license, may violate the law. This software neither checks nor guarantees that the configured frequency, power and modulation comply with the law. You are solely responsible for what you transmit and for the results.
3. **機器の取り扱い / Handling of equipment**  
   PlutoのTXとRXの接続、外部アンプ(PA)・アッテネータ・アンテナの接続、送信出力の設定、GPIO21やPA_Power/PTTコントローラ(ESP32 W5500)の12 V電源・PTTの配線を誤ると、機器を破損したり、他の無線局へ障害を与えたりするおそれがあります。機器の仕様を確認し、使用者の責任で行ってください。特に、TXをRXへ直接接続せず、40 dB以上の減衰器を介してください。  
   Wrong connections between the Pluto's TX and RX, wrong external amplifier (PA), attenuator or antenna connections, wrong transmit power settings, or wrong wiring of GPIO21 or of the 12 V power/PTT of the PA_Power/PTT controller (ESP32 W5500) may damage equipment or interfere with other stations. Check the specifications of your equipment and do this at your own responsibility. In particular, never connect TX directly to RX; use an attenuator of 40 dB or more.
4. **第三者ソフトウェアとライセンス / Third-party software and license**  
   本ソフトウェアは、GNU Radio、gr-dvbs2rx、libiio、FFmpeg、Qt(PyQt5・Qt Virtual Keyboard)、Langstone V2(Langstone-V2Modify)などの第三者ソフトウェアを利用・同梱します。それぞれのライセンスに従います。本ソフトウェア自体は GNU General Public License v3.0(GPLv3)の下で提供されます(下記「License」参照)。  
   This software uses and bundles third-party software such as GNU Radio, gr-dvbs2rx, libiio, FFmpeg, Qt (PyQt5, Qt Virtual Keyboard) and Langstone V2 (Langstone-V2Modify), each under its own license. This software itself is provided under the GNU General Public License v3.0 (GPLv3); see "License" below.
5. **動作について / About behavior**  
   ご使用のRaspberry Pi・環境によって動作が異なる場合や、未発見の不具合が含まれる可能性があります。  
   Behavior may differ depending on your Raspberry Pi and environment, and undiscovered defects may remain.

## クレジット / Credits

- 受信部の方式考案・受信部原システム設計: 山崎慎慈氏(JE1BTA)
  rpi-dvbs2-receiver-guiの設計に基づきます
- 受信部安定化調査修正・再捕捉修正・本アプリ開発: 真城和一
- 本アプリは、Dave Crump氏(G8GKQ)が開発したDATV送受信機プロジェクト「Portsdown」に啓発され、開発したものです。同氏の先駆的な取り組みに感謝いたします。
- Langstone V2(SDRトランシーバー): Colin Durbridge氏(G4EML)の[g4eml/Langstone-V2](https://github.com/g4eml/Langstone-V2)
  (Pi 4 + DFRobot DFR0550 + ADALM-Pluto向けに改造した`kazushinjo/Langstone-V2Modify`を
  [`pi4/third_party/Langstone-V2Modify/`](pi4/third_party/Langstone-V2Modify/)に同梱)

<!-- English -->

- Reception method and original reception system design: Shinji Yamazaki (JE1BTA),
  based on the design of rpi-dvbs2-receiver-gui
- Reception stability investigation and fixes, re-acquisition fixes, and development of this app: Kazuichi Shinjo
- This application was developed inspired by "Portsdown", the DATV transceiver project created by Dave Crump (G8GKQ). We extend our deep gratitude for his pioneering work.
- Langstone V2 (SDR transceiver): [g4eml/Langstone-V2](https://github.com/g4eml/Langstone-V2) by Colin Durbridge (G4EML)
  (`kazushinjo/Langstone-V2Modify`, modified for the Pi 4 + DFRobot DFR0550 +
  ADALM-Pluto, is bundled in [`pi4/third_party/Langstone-V2Modify/`](pi4/third_party/Langstone-V2Modify/))

## License

本ソフトウェアはGNU General Public License v3.0(GPLv3)の下で提供されます。
ライセンス全文: [LICENSE](LICENSE)

This software is licensed under the GNU General Public License v3.0 (GPLv3).
Full license text: [LICENSE](LICENSE)

- Langstone V2 (SDR transceiver, [g4eml/Langstone-V2](https://github.com/g4eml/Langstone-V2); bundled as `kazushinjo/Langstone-V2Modify`): GPLv3
- Reception subsystem design (Shinji Yamazaki, JE1BTA): GPLv3
- Application development, reception stability fixes (Kazuichi Shinjo): GPLv3

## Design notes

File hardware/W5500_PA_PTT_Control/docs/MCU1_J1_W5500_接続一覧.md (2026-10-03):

---
title: MCU1 / J1 / W5500(A1) 接続一覧 / MCU1 / J1 / W5500 (A1) Connection List
---

# MCU1 / J1 / W5500(A1) 接続一覧 / MCU1 / J1 / W5500 (A1) Connection List

本書は日本語と英語を併記している。各節で日本語の後に英語が続く。表は各欄に日本語と英語を並べて書く。

This document is written in both Japanese and English. In each section, the Japanese text is followed by the English text.
In the tables, each cell gives the Japanese and then the English.

KiCad回路図(`hardware/W5500_PA_PTT_Control/kicad/w5500-esp32.kicad_sch`)の
netlistから抽出した、MCU1(ESP32 DevKitC、参考表示のみ・DNP)・J1(実体のDevKitC
ソケット)・A1(W5500_Lite)間の対応表。

MCU1は回路図上の参考表示シンボルでDNP(実装しない)。実体はJ1に挿し込むFreenove
DevKitC基板のため、SPI信号(CS/SCK/MISO/MOSI)はMCU1側では別ネット名(ラベルのみ)
であり、実際の結線はJ1-A1間の直接ワイヤ。

J1は2026-08-30に実機(Freenove ESP32-WROOM-32E DevKitC)の実ピン配列に合わせて
2x19(38ピン)から2x20(40ピン)へ修正した。さらに2026-08-31、MCU1もJ1と同じ
`project_symbols:ESP32_DevKitC_Socket_40P`シンボルに置き換え、**MCU1のピン番号・
信号名はJ1と完全に一致**するようになった（従来はMCU1がESP32-WROOM-32モジュール
自体のパッド番号(KiCad標準`RF_Module:ESP32-WROOM-32`ライブラリ)を使っていたため、
J1のソケットピン番号と一致しなかった）。以下の表のピン番号はMCU1・J1共通。

A mapping table between MCU1 (ESP32 DevKitC, reference display only, DNP), J1 (the actual DevKitC socket) and A1
(W5500_Lite), extracted from the netlist of the KiCad schematic (`hardware/W5500_PA_PTT_Control/kicad/w5500-esp32.kicad_sch`).

MCU1 is a reference-display symbol on the schematic and is DNP (not populated). The actual part is the Freenove
DevKitC board plugged into J1, so the SPI signals (CS/SCK/MISO/MOSI) have separate net names (labels only) on the MCU1
side, and the actual wiring is direct wires between J1 and A1.

On 2026-08-30, J1 was corrected from 2x19 (38 pins) to 2x20 (40 pins) to match the actual pinout of the real board
(Freenove ESP32-WROOM-32E DevKitC). Furthermore, on 2026-08-31 MCU1 was also replaced with the same
`project_symbols:ESP32_DevKitC_Socket_40P` symbol as J1, so **MCU1's pin numbers and signal names now match J1
exactly** (previously MCU1 used the pad numbers of the ESP32-WROOM-32 module itself (KiCad standard
`RF_Module:ESP32-WROOM-32` library), which did not match J1's socket pin numbers). The pin numbers in the table below
are common to MCU1 and J1.

> 2026-09-30、フットプリントを実物の資料に合わせて2点修正した。
> - A1(W5500 Lite)は、USR-ES1データシート(Jinan USR IOT「3.3 Dimensions」)に合わせて、ピン列の間隔を15.24mmから20.32mmへ、
>   7〜12番の並びを1〜6番と同じくRJ45側から数える順に修正した(従来は7番がRJ45と反対側で、右列の信号が逆につながっていた)。
>   フットプリント名は`W5500_Lite_USR-ES1_2x06_P2.54mm_20.32mm`。
> - J1(DevKitCソケット)は、Freenove公式のピン配置図(部品面から見た図)に合わせて、ピンの並びを上下反転した。
>   1番(5V)・21番(GND)がUSB-C側、20番(3V3)・40番(GND)がアンテナ側になる(従来は鏡像の並びで、5Vが3V3やGNDのピンにつながる配置だった)。

> On 2026-09-30, two footprints were corrected to match the documentation of the actual parts.
> - A1 (W5500 Lite): per the USR-ES1 datasheet (Jinan USR IOT, "3.3 Dimensions"), the row spacing was changed from 15.24 mm to 20.32 mm,
>   and pins 7–12 now count from the RJ45 end like pins 1–6 (previously pin 7 was at the end opposite the RJ45, so the right-row signals were
>   connected in reverse). The footprint name is `W5500_Lite_USR-ES1_2x06_P2.54mm_20.32mm`.
> - J1 (DevKitC socket): per Freenove's official pinout diagram (seen from the component side), the pin order was flipped vertically.
>   Pins 1 (5V) and 21 (GND) are at the USB-C end and pins 20 (3V3) and 40 (GND) at the antenna end (previously the order was a mirror image,
>   placing 5V on the 3V3 or GND pins).

| 信号<br>Signal | MCU1/J1ピン<br>MCU1/J1 pin | W5500(A1)ピン<br>W5500 (A1) pin | 備考<br>Notes |
|---|---|---|---|
| SPI CS | GPIO5 (31) | CS (5) | MCU1側は別ネット名(ラベルのみ)、実配線はJ1-A1間<br>Separate net name on the MCU1 side (label only); actual wiring is between J1 and A1 |
| SPI SCK | GPIO18 (32) | SCK (4) | 同上<br>Same as above |
| SPI MISO | GPIO19 (33) | MISO (12) | 同上<br>Same as above |
| SPI MOSI | GPIO23 (39) | MOSI (3) | 同上<br>Same as above |
| W5500 RST | GPIO21 (35) | RST (11) | 3者同一ネット(GPIO制御リセット。ファームウェアで起動時にパルス送出)。R9(10kΩ)で+3V3_Aへプルアップ<br>Same net for all three (GPIO-controlled reset; the firmware sends a pulse at startup). Pulled up to +3V3_A by R9 (10 kΩ) |
| POWER(12V電源)制御<br>POWER (12 V power) control | GPIO26 (11) | — | W5500非接続。ネットラベルは`GPIO26_PA`だが、実体は12V電源のON/OFF制御（下表参照）<br>Not connected to the W5500. The net label is `GPIO26_PA`, but it actually controls the 12 V power ON/OFF (see the table below) |
| PTT制御<br>PTT control | GPIO27 (10) | — | W5500非接続。ネットラベルは`GPIO27_PTT`。無線機PTT端子をGND側へ落とす方式（下表参照）<br>Not connected to the W5500. The net label is `GPIO27_PTT`. Pulls the radio's PTT terminal to GND (see the table below) |
| GND | GND (7, 21〜24, 40) | 1, 2, 7 | 共通GND。J1は7・21〜24・40番をGNDに接続(34番のみ未結線。ボード内部でつながっている)<br>Common GND. On J1, pins 7, 21–24 and 40 are connected to GND (only pin 34 is left unconnected; it is connected inside the board) |
| +5V(`+5v0`、DevKitC基板給電)<br>+5 V (`+5v0`, DevKitC board supply) | 5V (1, 2) | — | U2(L7805、+12V→+5V)から供給。MCU1(ESP32モジュール自体)は3.3V駆動のため対応ピンなし。DevKitC基板上のオンボードLDOがこの5VをESP32モジュール用3.3Vへ変換する<br>Supplied from U2 (L7805, +12 V → +5 V). MCU1 (the ESP32 module itself) runs on 3.3 V and has no corresponding pin. The on-board LDO of the DevKitC board converts this 5 V to 3.3 V for the ESP32 module |
| +3.3V(ESP32系)<br>+3.3 V (ESP32 side) | 3.3V (3) | — | DevKitC基板のオンボードLDO出力(上記+5Vから生成)。MCU1(ESP32モジュール)のVDDピンへの供給元。J1・MCU1とも他に3.3Vピンが4,5,20にあるが未結線<br>Output of the DevKitC board's on-board LDO (generated from the +5 V above). The supply for the VDD pin of MCU1 (the ESP32 module). J1 and MCU1 also have 3.3 V pins at 4, 5 and 20, which are unconnected |
| +3V3_A(W5500専用)<br>+3V3_A (W5500 only) | — | VCC (8, 9) | 上記と同じ`+5v0`(U2の出力)をU1(LM2940T-3.3、+5V→+3.3V)が受けて生成。ESP32側3.3V(DevKitC基板内蔵LDO経由)とは生成回路が別だが、元の5Vは共通<br>Generated by U1 (LM2940T-3.3, +5 V → +3.3 V) from the same `+5v0` (U2 output) as above. The generating circuit is separate from the ESP32 side's 3.3 V (via the DevKitC board's built-in LDO), but the source 5 V is common |

未使用: A1のINT(6)・NC(10)、J1・MCU1の残りGPIOピン(GPIO13,GPIO12,GPIO14,GPIO33,GPIO32,
GPIO35,GPIO34,VN,VP,EN,GPIO15,GPIO2,GPIO0,GPIO4,GPIO16,GPIO17,RX,TX,GPIO22)は
今回未接続。

Unused: A1's INT (6) and NC (10), and the remaining GPIO pins of J1/MCU1 (GPIO13, GPIO12, GPIO14, GPIO33, GPIO32,
GPIO35, GPIO34, VN, VP, EN, GPIO15, GPIO2, GPIO0, GPIO4, GPIO16, GPIO17, RX, TX, GPIO22) are not connected this time.

> MCU1シンボルは回路図上「参考表示のみ・DNP」であり、実体はJ1に挿さるFreenove
> DevKitC基板そのものを表す。2026-08-31以降はJ1と同じ`project_symbols:
> ESP32_DevKitC_Socket_40P`シンボルを使っており、DevKitC基板自体には無いESP32
> モジュール固有のフラッシュ用ピン(SD0〜SD3/CMD/CLK等)は表示されない。
>
> ESP32モジュールチップ自体は3.3V駆動で5V入力ピンを持たないため、+5V系統に
> MCU1側の対応ピンは存在しない……という制約は旧シンボルの話であり、現行の
> DevKitCソケット表示では「5V」ピンも(実際にDevKitC基板が受電する電源として)
> 表示されるが、本回路では未結線のまま。実際に+5Vを受電するのはJ1に挿さる
> Freenove DevKitC基板側であり、基板上のオンボードLDOでの5V→3.3V変換は
> この回路図の範囲外（DevKitC基板内部）である。
>
> W5500(A1)用の+3V3_Aは、MCU1(DevKitC基板)用の+5Vと**同じ`+5v0`ネット**
> （U2=L7805の出力）をU1(LM2940T-3.3)がさらに3.3Vへ降圧して生成する。
> すなわち12V→5Vへの降圧はU2(L7805)1系統のみで、そこからMCU1用とW5500用の
> 2方向に分岐する構成（外付けDCDCバックコンバータモジュールは使用しない）。

> The MCU1 symbol is "reference display only, DNP" on the schematic and represents the Freenove DevKitC board itself
> plugged into J1. Since 2026-08-31 it uses the same `project_symbols:ESP32_DevKitC_Socket_40P` symbol as J1, so the
> ESP32-module-specific flash pins (SD0–SD3/CMD/CLK, etc.) that the DevKitC board itself does not have are not shown.
>
> The constraint that "the ESP32 module chip itself runs on 3.3 V and has no 5 V input pin, so there is no corresponding
> MCU1 pin for the +5 V system" applied to the old symbol. With the current DevKitC socket display, the "5V" pin is also
> shown (as the power the DevKitC board actually receives), but it remains unconnected in this circuit. What actually
> receives the +5 V is the Freenove DevKitC board plugged into J1, and the 5 V → 3.3 V conversion by its on-board LDO is
> outside the scope of this schematic (inside the DevKitC board).
>
> The +3V3_A for the W5500 (A1) is generated by U1 (LM2940T-3.3) further stepping down to 3.3 V **the same `+5v0` net**
> (U2 = L7805 output) as the +5 V for MCU1 (DevKitC board). In other words, the 12 V → 5 V step-down is a single system
> through U2 (L7805), which branches in two directions from there, for MCU1 and for the W5500 (no external DC-DC buck
> converter module is used).

GPIO25(J1・MCU1ピン12)はRev.1.1時点でLNA制御用ネット(`GPIO25_LNA`)としてラベル付けされていたが、
本表・下表いずれの駆動回路にも接続されておらず、現行回路では未使用（PA_Power/PTTコントローラ
の対象外）。2026-10-01、回路図に残っていた`GPIO25_LNA`ラベルを削除し、J1・MCU1の12番ピンを未接続(×)にした。

GPIO25 (J1/MCU1 pin 12) was labeled as the LNA control net (`GPIO25_LNA`) as of Rev.1.1, but it is not connected to any
drive circuit in this table or the table below and is unused in the current circuit (outside the scope of the
PA_Power/PTT controller). On 2026-10-01 the leftover `GPIO25_LNA` label was removed from the schematic, and pin 12 of J1
and MCU1 was marked as no-connect (×).

## POWER(12V電源)・PTT 駆動回路の接続詳細 / POWER (12 V Power) and PTT Drive Circuit Connection Details

GPIO26・GPIO27はW5500とは独立に、以下の駆動回路経由でJ5(Power)・J6(PTT_ON)へ接続される。

GPIO26 and GPIO27 are connected to J5 (Power) and J6 (PTT_ON) through the following drive circuits, independently of
the W5500.

| GPIO | 経路<br>Path | 部品<br>Parts | 備考<br>Notes |
|---|---|---|---|
| GPIO26 (POWER) | GPIO26 → R6 → Q1(B)、R12でGNDへプルダウン<br>GPIO26 → R6 → Q1 (B), pulled down to GND by R12 | R6: 510Ω、R12: 10kΩ、Q1: 2SC1815(NPN)<br>R6: 510 Ω, R12: 10 kΩ, Q1: 2SC1815 (NPN) | GPIO26 HIGHでQ1がONし、Q5のゲートをGND側へ引く。GPIO26が確定しない間はR12でQ1をOFFに保つ<br>When GPIO26 is HIGH, Q1 turns ON and pulls Q5's gate toward GND. While GPIO26 is undetermined, R12 keeps Q1 OFF |
| ↳ | Q1(C) → Q5(G)、R8でプルアップ<br>Q1 (C) → Q5 (G), pulled up by R8 | R8: 1kΩ(+12Vへプルアップ、1/2W)、Q5: 2SJ334(PMOS, TO-220、足は1=G・2=D・3=S、放熱器付き)<br>R8: 1 kΩ (pull-up to +12 V, 1/2 W), Q5: 2SJ334 (PMOS, TO-220, pins 1 = G, 2 = D, 3 = S, with heatsink) | Q1 OFF時はR8でゲートが+12Vにプルアップされ、Q5(ハイサイドスイッチ)はOFF<br>When Q1 is OFF, R8 pulls the gate up to +12 V and Q5 (high-side switch) is OFF |
| ↳ | Q5(S)=+12V、Q5(D) → J5(Power)<br>Q5 (S) = +12 V, Q5 (D) → J5 (Power) | J5: Power出力コネクタ<br>J5: Power output connector | Q5 ONで+12VがJ5(Power)へ導通（旧リレーK3の置き換え）<br>When Q5 is ON, +12 V conducts to J5 (Power) (replaces the former relay K3) |
| GPIO27 (PTT) | GPIO27 → R7 → Q3(B)、R13でGNDへプルダウン<br>GPIO27 → R7 → Q3 (B), pulled down to GND by R13 | R7: 510Ω、R13: 10kΩ、Q3: 2SC1815(NPN)<br>R7: 510 Ω, R13: 10 kΩ, Q3: 2SC1815 (NPN) | GPIO27 HIGHでQ3がONする。GPIO27が確定しない間はR13でQ3をOFFに保つ<br>When GPIO27 is HIGH, Q3 turns ON. R13 keeps Q3 OFF while GPIO27 is undetermined |
| ↳ | Q3(C) → J6(PTT_ON)<br>Q3 (C) → J6 (PTT_ON) | — | Q3(オープンコレクタ的動作)ONでJ6(PTT_ON)をGND側へ落とす（無線機PTT端子への接続を想定。Q3 OFF時はハイインピーダンス）<br>When Q3 (acting like an open collector) is ON, it pulls J6 (PTT_ON) to GND (intended for connection to the radio's PTT terminal; high impedance when Q3 is OFF) |

Q1・Q3のエミッタ(pin1)は共通GNDに接続。

The emitters (pin 1) of Q1 and Q3 are connected to the common GND.

## 電源系統の接続詳細 / Power System Connection Details

外部から供給される+12V(13.8V)を起点に、**U2(L7805)が生成する+5V(`+5v0`)を
MCU1(DevKitC基板)とU1(LM2940T-3.3)の両方に分岐供給**する。12V→5Vへの降圧は
U2の1系統のみで、外付けのDCDCバックコンバータモジュールは使用しない。

Starting from the externally supplied +12 V (13.8 V), **the +5 V (`+5v0`) generated by U2 (L7805) is branched to both
MCU1 (DevKitC board) and U1 (LM2940T-3.3)**. The 12 V → 5 V step-down is a single system through U2, and no external DC-DC
buck converter module is used.

| 経路<br>Path | 部品<br>Parts | 備考<br>Notes |
|---|---|---|
| 電源入力: J2(DC_IN_13V8) → +12Vネット<br>Power input: J2 (DC_IN_13V8) → +12 V net | J2: 2ピン(+12V, GND)<br>J2: 2 pins (+12 V, GND) | 外部電源(13.8V)の入力コネクタ<br>Input connector for the external power supply (13.8 V) |
| +12V → U2(IN) → U2(OUT)=`+5v0` | U2: L7805(TO-220、12V→5V) | C3(0.33µF、25V以上)が+12V-GND間のバイパス<br>C3 (0.33 µF, 25 V or higher) bypasses +12 V to GND |
| `+5v0` → J1(1,2) | — | MCU1(DevKitC基板)へ供給。基板上のオンボードLDOで3.3Vに変換されESP32モジュールへ渡る<br>Supplies MCU1 (DevKitC board). Converted to 3.3 V by the on-board LDO and passed to the ESP32 module |
| `+5v0` → U1(IN) → U1(OUT)=`+3V3_A` → A1(VCC) | U1: LM2940T-3.3(TO-220、5V→3.3V) | C1(0.47µF)が`+5v0`-GND間のバイパス(LM2940の入力コンデンサ)、C2(33µF電解、10V以上)が`+3V3_A`-GND間の出力コンデンサ(LM2940の発振防止に必要。22µF以上・ESR 0.1〜1Ω)<br>C1 (0.47 µF) bypasses `+5v0` to GND (the LM2940 input capacitor), and C2 (33 µF electrolytic, 10 V or higher) is the output capacitor on `+3V3_A` (needed to keep the LM2940 from oscillating: at least 22 µF, ESR 0.1–1 Ω) |

`+5v0`(U2の出力)は、J1(MCU1用)とU1(W5500用3.3Vレギュレータの入力)の**共通の
供給源**であり、この2つは同一ネットで並列に分岐している点に注意（Rev.2.0時点
では外付けDCDCバックコンバータ用のJ3が別系統として存在したが、2026-08-30の
Rev.2.1で廃止しU2からの単一系統に統合した）。

Note that `+5v0` (U2 output) is the **common supply** for J1 (for MCU1) and U1 (input of the 3.3 V regulator for the
W5500), and the two branch in parallel from the same net (as of Rev.2.0, J3 for an external DC-DC buck converter
existed as a separate system, but it was removed in Rev.2.1 on 2026-08-30 and merged into the single system from U2).

## 関連ファイル / Related Files

- 回路図 / Schematic: `hardware/W5500_PA_PTT_Control/kicad/w5500-esp32.kicad_sch`
- SPI配線の簡易表(ESP32 GPIO番号のみ) / Simple SPI wiring table (ESP32 GPIO numbers only): [`W5500_PA_PTT_Control_仕様書.md`](W5500_PA_PTT_Control_仕様書.md) 2.2節 / section 2.2
- ファームウェア / Firmware: `hardware/W5500_PA_PTT_Control/W5500_PA_PTT_Control.ino`

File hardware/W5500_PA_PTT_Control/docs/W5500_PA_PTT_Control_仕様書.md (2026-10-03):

---
title: ESP32+W5500 12V電源/PTT制御 開発仕様書 / ESP32+W5500 12 V Power/PTT Control Development Specification
---

# ESP32+W5500 12V電源/PTT制御 開発仕様書 / ESP32+W5500 12 V Power/PTT Control Development Specification

本書は日本語と英語を併記している。各節で日本語の後に英語が続く。表は各欄に日本語と英語を並べて書く。

This document is written in both Japanese and English. In each section, the Japanese text is followed by the English text.
In the tables, each cell gives the Japanese and then the English.

本書はShonan_Lite-RasPI5の同名文書(同じ基板・同じファームウェア)を、Shonan_lite-PI4向けに連携部分を置き換えたものである。

This document is the same-named document of Shonan_Lite-RasPI5 (same board, same firmware) with the integration parts replaced for Shonan_lite-PI4.

| 項目<br>Item | 内容<br>Details |
|---|---|
| 版数<br>Revision | Rev.2.8 |
| 基板の版数(シルク表記)<br>Board revision (silkscreen) | Rev.1.2(仕様書の版数とは別の番号。対応は下の「版数の対応表」を参照)<br>Rev.1.2 (a number separate from this document's revision; see "Revision Correspondence" below) |
| 作成日<br>Created | 2026-08-07（Rev.2.0更新: 2026-08-30、実機回路(KiCad)に合わせて全面改訂／Rev.2.1更新: 2026-08-30、電源系統を訂正。J3(外付けDCDCバックコンバータ)は廃止し、U2(L7805)の+5VをMCU1とU1(TA48033S)の両方に供給する単一系統に修正／Rev.2.2更新: 2026-08-31、J1をFreenove実機の40pin DevKitCソケット配列に修正しMCU1もJ1と同じピン番号・信号名に統一。Power(スイッチ後12V)系統に赤色LED(D1)、+12V(入力側)系統に緑色LED(D2)の表示回路を追加／Rev.2.3更新: 2026-09-30、R8を100Ωに変更(KiCad回路図に合わせる)しR9を追記、IPアドレスの記述を固定IP方式に統一、12V電源ONまでの遅延を実装値(5秒)に訂正、Shonan_lite-PI4側の「ESP32 W5500を使用する」設定とPi4 GPIO21によるPTT出力を追記／Rev.2.4更新: 2026-09-30、R8を1kΩ(1/2W推奨)に変更、Q1のベースをGNDへプルダウンするR12(10kΩ)を追加、KiCadのQ5シンボルを2SJ334の足の並び(1=G、2=D、3=S)に合わせて修正、U1・U2・Q5に放熱器を追加／Rev.2.5更新: 2026-09-30、前面・背面の丸型コネクタの裏に配線用の空き(内壁から20mm)を確保するため、放熱器の列を下へ移し(間隔22mm)、トランジスタ・LED・J5・J6を空きの手前へ移動／Rev.2.6更新: 2026-09-30、回路図の一部のGND記号の値が空で別ネットになっていたのを修正、内層をGND・+12Vの全面ベタにし12V出力を幅4mmで引いたうえで残りを自動配線、Q1・Q3を足の間隔2.54mmのTO-92に変更、Power表示LED(D1)・+12V表示LED(D2)を外付けにしてそれぞれJ7・J8で接続、J6・J7・J8をJST XHコネクタ(B2B-XH-A)に変更、R8の基板の穴を1/2W抵抗用に変更、C2をTA48033Sのデータシートどおり33µF・C1とC3を0.33µFに変更、Q3のベースにプルダウン抵抗R13(10kΩ)を追加、J1のGNDピン21〜24・40を接続、Q5の発熱の目安を高温時のオン抵抗で見直し／2026-10-01追記: J1の35番ピン(W5500 RST)の配線が+5Vのビアに0.3mmまで近づいていたため、+5V(`/+5v0`)を信号線から0.5mm以上離し(線幅0.6mm)、J1のピンとピンの間に配線を通さないよう再配線(基板の版数表記はRev.1.0)／Rev.2.7更新: 2026-10-01、放熱器(20PB020)の取付ピン(φ1.4mm、間隔12.5mm)用のめっき無し穴(φ1.8mm、周囲1mmは全層で銅箔なし)を追加し、M3穴の高さを基板から19mmに訂正(基板の版数をRev.1.1に変更)／Rev.2.8更新: 2026-10-03、3.3VレギュレータU1をTA48033SからLM2940T-3.3(TO-220、1=IN・2=GND・3=OUT)に変更。足の並びが違うためU1の2番をGND・3番を+3V3_Aにつなぎ替えて裏面の配線を引き直し、C1をLM2940のデータシートどおり0.47µFに変更(基板の版数をRev.1.2に変更)）<br>2026-08-07 (Rev.2.0 update: 2026-08-30, fully revised to match the actual circuit (KiCad) / Rev.2.1 update: 2026-08-30, power system corrected: J3 (external DC-DC buck converter) removed, and the +5 V from U2 (L7805) now feeds both MCU1 and U1 (TA48033S) as a single system / Rev.2.2 update: 2026-08-31, J1 corrected to the pinout of the actual Freenove 40-pin DevKitC socket and MCU1 unified with J1's pin numbers and signal names; indicator circuits added: a red LED (D1) on the Power (switched 12 V) line and a green LED (D2) on the +12 V (input side) line / Rev.2.3 update: 2026-09-30, R8 changed to 100 Ω (to match the KiCad schematic) and R9 added, IP address description unified to the fixed-IP method, the delay until the 12 V power turns ON corrected to the implemented value (5 seconds), and the "Use ESP32 W5500" setting and PTT output via Pi 4 GPIO21 on the Shonan_lite-PI4 side added / Rev.2.4 update: 2026-09-30, R8 changed to 1 kΩ (1/2 W recommended), R12 (10 kΩ) added to pull Q1's base down to GND, the KiCad symbol of Q5 corrected to the 2SJ334 pinout (1 = G, 2 = D, 3 = S), and heatsinks added to U1, U2 and Q5 / Rev.2.5 update: 2026-09-30, to leave 20 mm of wiring space (from the inner wall) behind the front and back round connectors, the heatsink column moved down (22 mm pitch) and the transistors, LEDs, J5 and J6 moved in front of that space / Rev.2.6 update: 2026-09-30, fixed GND symbols in the schematic whose value was empty (they formed a separate net), made the inner layers full GND and +12 V planes, laid the 12 V output as a 4 mm trace and autorouted the rest, changed Q1 and Q3 to the TO-92 footprint with 2.54 mm lead pitch, made the Power indicator LED (D1) and the +12 V indicator LED (D2) external, connected through J7 and J8, changed J6, J7 and J8 to JST XH connectors (B2B-XH-A), changed the R8 footprint to one for a 1/2 W resistor, changed C2 to 33 µF as in the TA48033S datasheet and C1 and C3 to 0.33 µF, added a pull-down resistor R13 (10 kΩ) on Q3's base, connected J1's GND pins 21–24 and 40, and revised the Q5 heat estimate using the on-resistance at high temperature / added 2026-10-01: because the trace from J1 pin 35 (W5500 RST) came within 0.3 mm of a +5 V via, re-routed so that +5 V (`/+5v0`) is at least 0.5 mm from signal traces (0.6 mm wide) and no trace passes between the pins of J1 (the board is marked Rev.1.0) / Rev.2.7 update: 2026-10-01, added non-plated holes (1.8 mm, no copper on any layer within 1 mm) for the heatsink (20PB020) mounting pins (1.4 mm dia., 12.5 mm pitch), and corrected the M3 hole height to 19 mm above the board (board revision changed to Rev.1.1) / Rev.2.8 update: 2026-10-03, the 3.3 V regulator U1 changed from the TA48033S to the LM2940T-3.3 (TO-220, 1 = IN, 2 = GND, 3 = OUT); because the pinout differs, U1 pin 2 was reconnected to GND and pin 3 to +3V3_A and the bottom-layer trace re-routed, and C1 changed to 0.47 µF as in the LM2940 datasheet (board revision changed to Rev.1.2)) |
| 対象ボード<br>Target board | ESP32 (WROVER系、無印ESP32) + W5500 イーサネットモジュール<br>ESP32 (WROVER family, plain ESP32) + W5500 Ethernet module |
| 対象スケッチ<br>Target sketch | `hardware/W5500_PA_PTT_Control/W5500_PA_PTT_Control.ino` |
| 連携先<br>Connected apps | shonan-android（DATV送信アプリ）、Shonan_lite-PI4（pi4/gui、送信画面のTX開始/終了およびアプリ起動/終了に連動）<br>shonan-android (DATV transmit app), Shonan_lite-PI4 (pi4/gui; linked to TX start/stop on the transmit screen and to app start/exit) |
| ステータス<br>Status | 実機ESP32(ESP32-D0WD-V3)へ書き込み・起動確認済み（2026-08-30）。無線機を含めた実地テスト（12V電源/PTT駆動回路との結合試験）は未実施<br>Written to and boot-confirmed on an actual ESP32 (ESP32-D0WD-V3) (2026-08-30). Field testing including the radio (integration test with the 12 V power/PTT drive circuits) not yet done |

---

## 版数の対応表 / Revision Correspondence

仕様書の版数と基板の版数(シルク表記)は別の番号で管理する。基板を変更して製造し直すときは基板の版数を上げ、
この表に行を追加する。

The revision of this document and the revision of the board (silkscreen) are managed as separate numbers. When the
board is changed and manufactured again, raise the board revision and add a row to this table.

| 仕様書の版数<br>Document revision | 日付<br>Date | 基板の版数(シルク表記)<br>Board revision (silkscreen) | 備考<br>Notes |
|---|---|---|---|
| Rev.1.0〜1.1 | 2026-08-07〜 | —(プリント基板なし)<br>— (no PCB) | LNA/PTT/PAの3チャンネル構成の旧仕様。KiCadで回路図を作る前<br>Old specification with three channels (LNA/PTT/PA), before the schematic was drawn in KiCad |
| Rev.2.0〜2.5 | 2026-08-30〜2026-09-30 | —(未製造)<br>— (not manufactured) | KiCadで回路図・基板を設計中<br>Schematic and PCB being designed in KiCad |
| Rev.2.6 | 2026-09-30(2026-10-01追記を含む)<br>2026-09-30 (including the 2026-10-01 additions) | Rev.1.0 | 放熱器の取付ピン用の穴なし<br>No holes for the heatsink mounting pins |
| Rev.2.7 | 2026-10-01 | Rev.1.1 | 放熱器の取付ピン用のめっき無し穴を追加。U1はTA48033S(1=IN・2=OUT・3=GND)の足の並び<br>Non-plated holes for the heatsink mounting pins added. U1 uses the TA48033S pinout (1 = IN, 2 = OUT, 3 = GND) |
| Rev.2.8 | 2026-10-03 | **Rev.1.2** | U1をLM2940T-3.3(1=IN・2=GND・3=OUT)に変更し配線を引き直し、C1を0.47µFに変更。`fabrication/jlcpcb/`の発注データはこの版。Rev.1.1の基板にLM2940T-3.3を載せると出力とGNDが逆になるので使わない<br>U1 changed to the LM2940T-3.3 (1 = IN, 2 = GND, 3 = OUT) with re-routed traces, and C1 changed to 0.47 µF. The order data in `fabrication/jlcpcb/` is for this revision. Do not fit an LM2940T-3.3 on a Rev.1.1 board, as its output and GND would be swapped |

---

## 1. 目的・スコープ / Purpose and Scope

shonan-android の送信ボタン操作に連動して **PTT** を、Shonan_lite-PI4(pi4/gui)アプリの起動/終了操作に連動して **12V電源(PA等の外部機器用)** を、それぞれイーサネット経由でON/OFF制御する。

Rev.1.1まではLNA/PTT/PAの3ch・シーケンス制御（送信時にLNAを切り離してからPTT/PAを立ち上げる等）を想定していたが、実機回路(KiCad)ではLNA用の駆動回路が存在せず、**12V電源ON/OFF（2SJ334によるハイサイドスイッチ）とPTT ON/OFFの2機能のみ**が実装されている。本書はこの実機回路に合わせて全面改訂した。

Control, via Ethernet, **PTT** in conjunction with the transmit button of shonan-android, and the **12 V power (for external equipment such as a PA)** in conjunction with starting/exiting the Shonan_lite-PI4 (pi4/gui) app.

Up to Rev.1.1, 3-channel LNA/PTT/PA sequence control was assumed (e.g. disconnecting the LNA before raising PTT/PA when transmitting), but the actual circuit (KiCad) has no LNA drive circuit and implements **only two functions: 12 V power ON/OFF (high-side switch with a 2SJ334) and PTT ON/OFF**. This document has been fully revised to match the actual circuit.

**スコープに含むもの / In scope**
- ESP32 + W5500 による12V電源／PTT 2チャンネルのON/OFF制御 / 2-channel ON/OFF control of 12 V power / PTT with ESP32 + W5500
- shonan-androidからのHTTPリクエストによるPTTのTX/RX切替 / PTT TX/RX switching by HTTP requests from shonan-android
- Shonan_lite-PI4(pi4/gui)アプリの起動/終了に連動した12V電源のON/OFF / 12 V power ON/OFF linked to starting/exiting the Shonan_lite-PI4 (pi4/gui) app
- ブラウザによる手動確認・デバッグ用UI / Browser UI for manual checking and debugging

**スコープに含まないもの / Out of scope**
- shonan-androidアプリ側での送信ボタン実装・HTTPリクエスト送出処理（別途アプリ側での対応が必要） / Implementing the transmit button and sending HTTP requests in the shonan-android app (must be handled separately on the app side)
- 12V電源の供給先となるPA・LNA等自体の回路設計（利用者の無線機構成に依存） / Circuit design of the PA, LNA, etc. that receive the 12 V power (depends on the user's radio configuration)

---

## 2. ハードウェア構成 / Hardware Configuration

### 2.1 使用部品 / Parts

| 部品<br>Part | 備考<br>Notes |
|---|---|
| ESP32 (WROVERモジュール等)<br>ESP32 (WROVER module, etc.) | 無印ESP32。ESP32-C3等のネイティブUSBチップとは別物<br>Plain ESP32. Not the same as native-USB chips such as the ESP32-C3 |
| W5500 イーサネットモジュール<br>W5500 Ethernet module | SPI接続。MACアドレス内蔵なしのためスケッチ内で任意設定<br>SPI connection. Has no built-in MAC address, so it is set arbitrarily in the sketch |
| Q5 (2SJ334) | P-ch パワーMOSFET。12V電源のハイサイドスイッチ（旧リレーK3を置き換え）<br>P-channel power MOSFET. High-side switch for the 12 V power (replaces the former relay K3) |
| Q1 (2SC1815) | Q5のゲート駆動用NPNトランジスタ（GPIO26でON/OFF）<br>NPN transistor driving Q5's gate (switched by GPIO26) |
| R8 (1kΩ、1/2W)<br>R8 (1 kΩ, 1/2 W) | Q5のゲートを+12Vへプルアップする抵抗（Q1 OFF時にQ5をOFFに保つ）。Q1 ON中は約12〜14mAが流れ、約0.14〜0.2Wを消費するため1/2Wとする(1/4Wでは定格の約8割で余裕がない)。基板の穴は直径3.2mm・長さ9mmの1/2W抵抗の縦置き用(足の間隔5.08mm)<br>Pull-up resistor from Q5's gate to +12 V (keeps Q5 OFF while Q1 is OFF). About 12–14 mA flows while Q1 is ON, dissipating about 0.14–0.2 W, so a 1/2 W part is used (a 1/4 W part would run at about 80% of its rating, with no margin). The PCB footprint is for a 1/2 W resistor 3.2 mm in diameter and 9 mm long, mounted vertically (5.08 mm lead pitch) |
| R12 (10kΩ)<br>R12 (10 kΩ) | Q1のベースをGNDへプルダウンする抵抗(ESP32の起動中などGPIO26が確定しない間もQ1を確実にOFFにする)<br>Pull-down resistor from Q1's base to GND (keeps Q1 reliably OFF even while GPIO26 is undetermined, e.g. during ESP32 startup) |
| R13 (10kΩ)<br>R13 (10 kΩ) | Q3のベースをGNDへプルダウンする抵抗(ESP32の起動中や書き込み中などGPIO27が確定しない間もQ3をOFFにし、PTTが勝手にONにならないようにする)<br>Pull-down resistor from Q3's base to GND (keeps Q3 OFF, so PTT does not turn ON by itself, even while GPIO27 is undetermined, e.g. during ESP32 startup or programming) |
| Q3 (2SC1815) | PTT_ON信号駆動用NPNトランジスタ（GPIO27でON/OFF、オープンコレクタ的にGND側へ落とす）<br>NPN transistor driving the PTT_ON signal (switched by GPIO27; pulls down to GND like an open collector) |
| R9 (10kΩ)<br>R9 (10 kΩ) | W5500(A1)のRST(GPIO21と同一ネット)を+3V3_Aへプルアップする抵抗<br>Pull-up resistor from the W5500 (A1) RST (same net as GPIO21) to +3V3_A |
| J2 (DC_IN_13V8) | 外部電源(13.8V/12V系)の入力コネクタ<br>Input connector for the external power supply (13.8 V/12 V) |
| U2 (L7805) | +12V→+5Vのリニアレギュレータ(TO-220)。生成した+5V(`+5v0`)はMCU1(J1)とU1の両方に供給される<br>+12 V → +5 V linear regulator (TO-220). The generated +5 V (`+5v0`) feeds both MCU1 (J1) and U1 |
| U1 (LM2940T-3.3) | U2出力の+5V→+3.3Vのリニアレギュレータ(TO-220、1A、足は1=IN・2=GND・3=OUT)。W5500(A1)のVCC(+3V3_A)専用<br>+5 V (U2 output) → +3.3 V linear regulator (TO-220, 1 A, pins 1 = IN, 2 = GND, 3 = OUT). Dedicated to the W5500 (A1) VCC (+3V3_A) |
| C3 (0.33µF、25V以上)<br>C3 (0.33 µF, 25 V or higher) | U2(L7805)の入力(+12V)側コンデンサ<br>Input (+12 V) capacitor of U2 (L7805) |
| C1 (0.47µF、16V以上)<br>C1 (0.47 µF, 16 V or higher) | U2の出力・U1の入力(+5V)側コンデンサ(LM2940データシートのCIN=0.47µF。U1が電源のフィルタから離れているときは必要)<br>Capacitor on U2's output / U1's input (+5 V) (CIN = 0.47 µF in the LM2940 datasheet; required when U1 is far from the supply filter) |
| C2 (33µF、10V以上の電解コンデンサ)<br>C2 (33 µF, electrolytic, 10 V or higher) | U1(LM2940T-3.3)の出力(+3.3V)側コンデンサ。LM2940は出力コンデンサが22µF以上でESRが0.1〜1Ωでないと発振するおそれがあるため、33µFの電解コンデンサとする(0.1µFのセラミックでは不足)。+側が+3.3V<br>Output (+3.3 V) capacitor of U1 (LM2940T-3.3). The LM2940 may oscillate unless the output capacitor is at least 22 µF with an ESR of 0.1–1 Ω, so a 33 µF electrolytic capacitor is used (a 0.1 µF ceramic is not enough). The + side goes to +3.3 V |
| J1 (ESP32_DevKitC_Socket_40P) | Freenove ESP32-WROOM-32E DevKitC(40pin、25.4mm幅)を直接プラグインするメスソケット<br>Female socket into which a Freenove ESP32-WROOM-32E DevKitC (40 pins, 25.4 mm wide) plugs directly |
| J7 (LED_PWR) + R10 (10kΩ)<br>J7 (LED_PWR) + R10 (10 kΩ) | Power(Q5出力・スイッチ後12V)系統の通電表示。表示LED(赤)は基板に載せず外付けとし、JST XHコネクタ(J7)で接続する。J7の1番=LEDのアノード(R10(10kΩ)で電流制限)、2番=カソード(GND)<br>Power indicator for the Power line (Q5 output, switched 12 V). The indicator LED (red) is not mounted on the board; it is external and connected through J7, a JST XH connector. J7 pin 1 = LED anode (current-limited by R10, 10 kΩ), pin 2 = cathode (GND) |
| J8 (LED_12V) + R11 (10kΩ)<br>J8 (LED_12V) + R11 (10 kΩ) | +12V(J2入力・未スイッチ)系統の通電表示。表示LED(緑)は基板に載せず外付けとし、JST XHコネクタ(J8)で接続する。J8の1番=LEDのアノード(R11(10kΩ)で電流制限)、2番=カソード(GND)<br>Power indicator for the +12 V line (J2 input, unswitched). The indicator LED (green) is not mounted on the board; it is external and connected through J8, a JST XH connector. J8 pin 1 = LED anode (current-limited by R11, 10 kΩ), pin 2 = cathode (GND) |

### 2.2 SPI配線（ESP32 ⇔ W5500） / SPI Wiring (ESP32 ⇔ W5500)

| W5500 | ESP32 GPIO |
|---|---|
| SCK | GPIO 18 |
| MISO | GPIO 19 |
| MOSI | GPIO 23 |
| CS (SS) | GPIO 5 |
| RST | GPIO 21（active-LOW。起動時にESP32からパルスを出してハードリセット）<br>GPIO 21 (active-LOW. The ESP32 sends a pulse at startup for a hard reset) |
| VCC | 3.3V |
| GND | GND |

### 2.3 出力ピン割り当て / Output Pin Assignment

| チャンネル<br>Channel | ESP32 GPIO | 論理<br>Logic | 起動時状態<br>State at startup | 駆動回路<br>Drive circuit | 出力先<br>Output |
|---|---|---|---|---|---|
| POWER (12V電源)<br>POWER (12 V power) | GPIO 26 | active-HIGH | OFF | R6→Q1(2SC1815、ベースはR12でGNDへプルダウン)→Q5(2SJ334, PMOSハイサイドスイッチ、ゲートはR8で+12Vへプルアップ)<br>R6 → Q1 (2SC1815, base pulled down to GND by R12) → Q5 (2SJ334, PMOS high-side switch, gate pulled up to +12 V by R8) | J5 (Power) |
| PTT | GPIO 27 | active-HIGH | OFF | R7→Q3(2SC1815)<br>R7 → Q3 (2SC1815) | J6 (PTT_ON、無線機PTT端子をGND側へ落とす方式)<br>J6 (PTT_ON; pulls the radio's PTT terminal to GND) |

> GPIO25は旧仕様(Rev.1.1)でLNA制御用として予約されていたが、実機回路では駆動回路が実装されておらず未接続(回路図でもJ1の12番ピンを未接続(×)にしている)。現行スケッチ・本書では扱わない。
>
> POWER(GPIO26)・PTTともにラッチ式のON/OFF出力であり、送信/受信の自動切替シーケンス（100ms待機等）は行わない。POWERとPTTは完全に独立したチャンネルとして扱う。
>
> GPIO25 was reserved for LNA control in the old specification (Rev.1.1), but the actual circuit has no drive circuit for it and it is unconnected (pin 12 of J1 is marked as no-connect (×) in the schematic). It is not handled by the current sketch or this document.
>
> Both POWER (GPIO26) and PTT are latched ON/OFF outputs; no automatic TX/RX switching sequence (such as a 100 ms wait) is performed. POWER and PTT are treated as completely independent channels.

### 2.4 電源系統 / Power System

外部から供給される+12V(13.8V)を起点に、**U2(L7805)が生成する+5V(`+5v0`)を
MCU1(DevKitC基板)とU1(LM2940T-3.3)の両方に分岐供給**する、単一系統の構成である。

Starting from the externally supplied +12 V (13.8 V), it is a single-system configuration in which **the +5 V (`+5v0`)
generated by U2 (L7805) is branched to both MCU1 (DevKitC board) and U1 (LM2940T-3.3)**.

```
J2(+12V,13.8V)
   │
   U2(L7805、12V→5V)
   │
   +5V(`+5v0`ネット / net) ──┬── J1(1) → MCU1(DevKitC基板 / board) ※基板内蔵LDOで3.3Vに変換しESP32モジュールへ
                               │                                     (converted to 3.3 V by the on-board LDO for the ESP32 module)
                               └── U1(LM2940T-3.3、5V→3.3V) → A1(VCC、W5500)
```

| 供給先<br>Supplied to | 経路<br>Path | 備考<br>Notes |
|---|---|---|
| MCU1(DevKitC)用<br>MCU1 (DevKitC) | +12V → U2(L7805、12V→5V) → J1(1) | DevKitC基板上のオンボードLDOがこの5Vを3.3Vに変換しESP32モジュールへ供給する<br>The on-board LDO of the DevKitC converts this 5 V to 3.3 V for the ESP32 module |
| W5500用<br>W5500 | +12V → U2(L7805、12V→5V) → U1(LM2940T-3.3、5V→3.3V) → A1(VCC) | U2出力の`+5v0`をU1がさらに3.3Vへ降圧しW5500(A1)のVCCへ供給<br>U1 further steps the `+5v0` output of U2 down to 3.3 V for the W5500 (A1) VCC |

MCU1用・W5500用いずれも起点はU2(L7805)の+5V出力であり、外付けのDCDCバックコンバータ
モジュールは使用しない（旧Rev.2.0で存在したJ3は廃止）。詳細な接続関係は
[`MCU1_J1_W5500_接続一覧.md`](MCU1_J1_W5500_接続一覧.md)「電源系統の接続詳細」を参照。

Both the MCU1 and W5500 supplies start from the +5 V output of U2 (L7805); no external DC-DC buck converter module is
used (J3, which existed in the old Rev.2.0, has been removed). For detailed connections, see "Power System Connection
Details" in [`MCU1_J1_W5500_接続一覧.md`](MCU1_J1_W5500_接続一覧.md).

### 2.5 放熱器 / Heatsinks

U2(L7805)・U1(LM2940T-3.3)・Q5(2SJ334)には、それぞれ放熱器を付ける。

A heatsink is attached to each of U2 (L7805), U1 (LM2940T-3.3) and Q5 (2SJ334).

| 項目<br>Item | 内容<br>Details |
|---|---|
| 放熱器<br>Heatsink | 秋月電子 [105054] 放熱器(ヒートシンク)20×20×25mm(型番20PB020-01025)<br>Akizuki Denshi [105054] heatsink 20×20×25 mm (part number 20PB020-01025) |
| 寸法<br>Dimensions | 20×20mm、高さ25mm。部品取付用のM3タップ穴は、基板から19mm・横は端から10mm(幅の中央)の位置にあり、M3ねじで部品のタブを固定する。TO-220のタブの穴は本体下端から約13mm(品種により差があり、実物で要確認)なので、部品は本体下端が基板から約6mm浮いた高さで取り付ける。基板取付用の金属ピン(φ1.4mm、基板下へ約4.5mm)が2本あり、間隔は12.5mm(幅の中央から±6.25mm)、部品取付面から3.5mm奥の位置。基板にはφ1.8mmのめっき無し穴を開け、ピンが内層のGND・+12Vのベタや配線とショートしないよう、穴の縁から1mm以内は全層で銅箔を置かない(ピンははんだ付けしない。放熱器はM3ねじと部品の足で固定)。U1・U2はタブがGNDのため放熱器もGND電位、Q5(TO-220NIS)は絶縁。基板上では、放熱器の部品側の面をタブの裏面にそろえ、放熱器の中央(穴の位置)が各部品の中央の足に来るように置いた<br>20×20 mm, 25 mm high. With pins for PCB mounting. The M3 tapped hole for the part is 19 mm above the board and 10 mm from the side (center of the width), and the part's tab is fixed with an M3 screw. The tab hole of a TO-220 is about 13 mm above the bottom of the body (varies by part; check against the actual part), so each part is mounted with the bottom of its body about 6 mm above the board. The heatsink has two metal mounting pins (1.4 mm dia., about 4.5 mm below the board) at 12.5 mm pitch (±6.25 mm from the center of the width), 3.5 mm behind the part-mounting face. The board has 1.8 mm non-plated holes for them, and no copper is placed on any layer within 1 mm of the hole edge so the pins cannot short to the inner GND/+12 V planes or traces (the pins are not soldered; the heatsink is held by the M3 screw and the part's leads). The tabs of U1 and U2 are GND, so their heatsinks are at GND potential; Q5 (TO-220NIS) is isolated. On the PCB, the part-side face of each heatsink is aligned with the back of the tab, and the center of the heatsink (the hole position) is aligned with the part's middle lead |
| 熱抵抗<br>Thermal resistance | 15.8℃/W |
| 基板上の配置<br>Placement on the PCB | 基板外形は横72mm×縦115mm(従来の手配線基板95×72mmを縦に20mm延長)。左上にW5500モジュール(RJ45は上端側)、その下にESP32 DevKitC(J1、USBは下端側)、右側にTO-220の3部品(U1・U2・Q5)を22mm間隔で縦に並べて放熱タブを右端側に向け、放熱器(20×20mm)を右端側に置く。左端に抵抗、右下にトランジスタ・LEDを配置。大電流の外部配線は電線はんだ付け用パッドで、J2(+12V入力、1mm²線用)は右上(前面の丸型コネクタ側)、J5(12V出力、1mm²線用)は右下(背面の丸型コネクタ側)に置く。小電流のJ6(PTT出力)・J7(外付けPower表示LED)・J8(外付け+12V表示LED)はJST XHコネクタ(B2B-XH-A、2ピン、ピッチ2.5mm、定格3A)とし、J7(左)・J6(右)はW5500モジュールとESP32ソケットの間の空きに横に並べ、J8は左端(R11の下)に置く(KiCadの基板データのDwgs.Userレイヤーに各範囲を記入。W5500モジュール等の寸法は実物のデータで更新予定)。4層基板で、内層1をGNDの全面ベタ、内層2を+12V(入力側)の全面ベタとし、GNDと+12Vは配線せずに内層で接続する。スイッチ後の12V出力(/Power、5A以上)はQ5のドレインからJ5まで表裏両面に幅4mm(Q5の足の間は2mm)の太いパターンで引く。J2・J5・Q5のパッドはベタ面へ直結(サーマルなし)。それ以外の信号はFreerouting(自動配線)で表裏2層に配線した(信号0.3mm、+3.3V・LED用の/Power分岐は0.8mm、+5Vは0.6mm)。+5V(`/+5v0`)はネットクラスSupply5Vで信号線から0.5mm以上離す(C1自身の足の間だけは部品の寸法で0.4mmのため、`kicad/w5500-esp32.kicad_dru`の例外ルールで0.25mmとする)。J1(ESP32ソケット)のピンとピンの間には、はんだブリッジを避けるため表裏とも配線禁止領域を置き、配線を通さない(同じ+5Vの1番・2番の間だけは除く)。Q1・Q3は足の間隔2.54mmのTO-92(Inline_Wide)。放熱器の取付ピンはめっき無し穴(φ1.8mm、周囲1mm銅箔なし)<br>The board outline is 72 mm wide × 115 mm tall (the previous hand-wired 95×72 mm board extended by 20 mm vertically). The W5500 module is at the top left (RJ45 toward the top edge), the ESP32 DevKitC (J1, USB toward the bottom edge) below it, and the three TO-220 parts (U1, U2, Q5) are stacked vertically on the right at 22 mm pitch with their tabs facing the right edge and the heatsinks (20×20 mm) on the right-edge side. The resistors are on the left edge and the transistors and LEDs at the bottom right. High-current external wiring uses solder-wire pads: J2 (+12 V input, for 1 mm² wire) is at the top right (front round connector side), and J5 (12 V output, for 1 mm² wire) is at the bottom right (back round connector side). The low-current J6 (PTT output), J7 (external Power indicator LED) and J8 (external +12 V indicator LED) are JST XH connectors (B2B-XH-A, 2-pin, 2.5 mm pitch, rated 3 A); J7 (left) and J6 (right) are placed side by side in the space between the W5500 module and the ESP32 socket, and J8 is on the left edge (below R11) (each area is drawn on the Dwgs.User layer of the KiCad PCB data; the dimensions of the W5500 module, etc. will be updated with data from the actual parts). The board is 4-layer: inner layer 1 is a full GND plane and inner layer 2 is a full +12 V (input side) plane, so GND and +12 V are connected through the inner layers without traces. The switched 12 V output (/Power, 5 A or more) runs from Q5's drain to J5 as a wide trace on both outer layers (4 mm, narrowing to 2 mm between Q5's leads). The J2, J5 and Q5 pads connect to the planes solidly (no thermal relief). All other signals are routed on the two outer layers with Freerouting (autorouter): 0.3 mm for signals, 0.8 mm for +3.3 V and the /Power branch to the LED, and 0.6 mm for +5 V. +5 V (`/+5v0`) is kept at least 0.5 mm from signal traces by the Supply5V net class (only between C1's own pads, which are 0.4 mm apart by the part's dimensions, an exception rule in `kicad/w5500-esp32.kicad_dru` allows 0.25 mm). Between the pins of J1 (ESP32 socket), keepout areas on both layers prevent traces from passing, to avoid solder bridges (except between pins 1 and 2, which are both +5 V). Q1 and Q3 use the TO-92 footprint with 2.54 mm lead pitch (Inline_Wide). The heatsink mounting pins go into non-plated holes (1.8 mm, no copper within 1 mm) |
| ケースと取付穴<br>Case and mounting holes | ケース(OpenSCAD「LAN_PTT.scad」)は内寸80×120×35mm。底のボス(外径8mm、高さ5mm)にM3インサートを埋め込み、基板をM3ねじで固定する。基板の取付穴はM3用φ3.2mmで、ボスと同じ66×109mm間隔(基板の各辺から3mm内側)。ボスが当たる穴の周り半径4mmには部品の足を置かない。前面(基板上端側)にRJ45用の角穴とφ16の丸穴、背面(基板下端側)にUSB用の角丸穴とφ16の丸穴があり、W5500のRJ45とDevKitCのUSBがそれぞれの開口に来るよう配置した。前面の丸型コネクタ(WTN-11-1253 8P)には+12VとGND、背面の丸型コネクタには12V出力・GND・PTTをつなぐ。丸型コネクタはパネルの裏へ約10mm出るため、配線の余裕を含めて内壁から20mm(基板の上端・下端から17.5mm)、幅20mm(基板のx=46〜66mm、左端基準)の範囲には背の高い部品を置かない。この範囲にあるのは前面側のJ2(電線はんだ付け用パッド)だけ<br>The case (OpenSCAD "LAN_PTT.scad") has inner dimensions of 80×120×35 mm. M3 inserts are embedded in the bosses on the bottom (8 mm OD, 5 mm high), and the board is fixed with M3 screws. The mounting holes on the board are φ3.2 mm for M3 at the same 66×109 mm pitch as the bosses (3 mm inside each board edge). No component leads within a 4 mm radius around the holes where the bosses touch. The front (board top edge side) has a rectangular opening for RJ45 and a φ16 round hole, and the back (board bottom edge side) has a rounded opening for USB and a φ16 round hole; the board is laid out so that the W5500's RJ45 and the DevKitC's USB line up with their openings. The front round connector (WTN-11-1253 8P) carries +12 V and GND, and the back round connector carries the 12 V output, GND and PTT. Because each round connector extends about 10 mm behind the panel, an area 20 mm deep from the inner wall (17.5 mm from the board's top and bottom edges) and 20 mm wide (board x = 46–66 mm from the left edge) is kept free of tall parts to leave room for wiring. The only item in that area is J2 (solder-wire pads) on the front side |

発熱の目安(入力14V時):

- U2(L7805): 出力電流を最大約0.25A(ESP32 DevKitCとW5500の合計の目安)とすると、損失は(14V−5V)×0.25A≒2.3W。
  放熱器15.8℃/W+接合部〜ケース間(約5℃/W)で温度上昇は約50℃。
- U1(LM2940T-3.3): (5V−3.3V)×約0.13A(W5500)≒0.2Wと小さい。
- Q5(2SJ334): 損失はオン抵抗(最大38mΩ@VGS=−10V)×電流²。放熱器15.8℃/W+接合部〜ケース間2.78℃/Wで約19℃/Wとして、5Aで約1W。高温時はオン抵抗が約1.5倍になるので約1.4Wとみると、温度上昇は約27℃。閉じたケース内の気温を約45℃(室温30℃+L7805等の発熱による上昇約15℃)として、接合部は約70℃(上限150℃)、放熱器表面は約65〜70℃で余裕がある。
  10Aでは高温時に約5.7W・温度上昇約110℃となりこの放熱器では不足するため、この放熱器での目安は約7Aまで。タブと放熱器の間には放熱グリスを塗る。PA等の実際の負荷電流に合わせて確認すること。

Rough heat estimate (at 14 V input):

- U2 (L7805): with a maximum output current of about 0.25 A (rough total of the ESP32 DevKitC and the W5500), the loss is
  (14 V − 5 V) × 0.25 A ≈ 2.3 W. With the heatsink's 15.8 °C/W plus junction-to-case (about 5 °C/W), the temperature rise is about 50 °C.
- U1 (LM2940T-3.3): (5 V − 3.3 V) × about 0.13 A (W5500) ≈ 0.2 W, which is small.
- Q5 (2SJ334): the loss is on-resistance (max 38 mΩ at VGS = −10 V) × current². Taking about 19 °C/W (heatsink 15.8 °C/W plus junction-to-case 2.78 °C/W),
  about 1 W at 5 A. The on-resistance rises to about 1.5 times at high temperature, so taking about 1.4 W, the rise is about 27 °C. Assuming the air inside the closed case is about 45 °C (30 °C room plus about 15 °C from the heat of L7805, etc.), the junction is about 70 °C (limit 150 °C) and the heatsink surface about 65–70 °C, which leaves margin.
  At 10 A the loss at high temperature is about 5.7 W with a rise of about 110 °C, which this heatsink cannot handle, so the guideline with this heatsink is up to about 7 A. Apply thermal grease between the tab and the heatsink. Check against the actual load current of the PA, etc.

---

## 3. 動作仕様 / Operation

Rev.1.1までの「LNA off→100ms待機→PTT/PA on」のようなシーケンス制御は廃止し、POWERとPTTはそれぞれ独立したON/OFFイベントに連動する。

Sequence control such as "LNA off → wait 100 ms → PTT/PA on" used up to Rev.1.1 has been abolished; POWER and PTT each follow independent ON/OFF events.

### 3.1 PTT（shonan-android 送信ボタン連動） / PTT (linked to the shonan-android transmit button)

- 送信ボタンON: `GET /tx?state=on` → 設定した遅延時間(`ptt_delay_ms`、デフォルト50ms)後にPTT(GPIO27) ON
- 送信ボタンOFF: `GET /tx?state=off` → PTT(GPIO27) 即時OFF（保留中のON遅延はキャンセルされる）
- 12V電源には一切触れない。

- Transmit button ON: `GET /tx?state=on` → PTT (GPIO27) ON after the configured delay (`ptt_delay_ms`, default 50 ms)
- Transmit button OFF: `GET /tx?state=off` → PTT (GPIO27) OFF immediately (a pending ON delay is cancelled)
- The 12 V power is never touched.

### 3.2 12V電源（Shonan_lite-PI4アプリ起動/終了連動） / 12 V Power (linked to Shonan_lite-PI4 app start/exit)

- アプリ起動から5秒後: `GET /ch?idx=0&state=on` → 設定した遅延時間(`power_delay_sec`、デフォルト3秒)後にPOWER(GPIO26) ON
- アプリ終了時: 先に `GET /ch?idx=0&state=off` → POWER(GPIO26) 即時OFF（保留中のON遅延はキャンセルされる）、その後3秒待ってからアプリを終了

- 5 seconds after app start: `GET /ch?idx=0&state=on` → POWER (GPIO26) ON after the configured delay (`power_delay_sec`, default 3 seconds)
- At app exit: first `GET /ch?idx=0&state=off` → POWER (GPIO26) OFF immediately (a pending ON delay is cancelled), then the app exits after waiting 3 seconds

### 3.3 設計意図 / Design Intent

- LNA駆動回路が実機に存在しないため、送受信切替に伴う保護シーケンス（LNA切り離し等）は不要と判断し廃止した。
- 12V電源はPA等の外部機器向けの主電源に相当するため、TX/RXの都度切り替えるのではなく、アプリの起動/終了という粒度の大きいタイミングでON/OFFする運用とする。
- PTTのみを送信ボタンに連動させることで、TX切替の応答を遅延なく行う。
- ON要求のみ設定した遅延時間を挟み、OFF要求は安全のため常に即時反映する（保留中のON遅延もOFF要求でキャンセルされる）。

- Since the actual hardware has no LNA drive circuit, the protective sequence accompanying TX/RX switching (such as disconnecting the LNA) was judged unnecessary and abolished.
- The 12 V power corresponds to the main power for external equipment such as a PA, so it is switched ON/OFF at coarse-grained timing (app start/exit) rather than on every TX/RX change.
- Linking only PTT to the transmit button makes TX switching respond without delay.
- Only ON requests are preceded by the configured delay; OFF requests always take effect immediately for safety (a pending ON delay is also cancelled by an OFF request).

---

## 4. ネットワーク・HTTP API仕様 / Network and HTTP API Specification

### 4.1 ネットワーク設定 / Network Settings

- 固定IPアドレス方式（初期値 `192.168.0.100`/24、ゲートウェイ `192.168.0.1`）。DHCPは使用しない
- IP/ゲートウェイ/サブネットはNVS(Preferences)に保存され、電源断後も保持される。`/config/network`（下記4.2）で変更可能で、保存後は自動再起動して新設定を反映する
- MACアドレスはスケッチ内で固定値を指定（同一LAN内で重複しないこと）

- Fixed IP address (default `192.168.0.100`/24, gateway `192.168.0.1`). DHCP is not used
- The IP/gateway/subnet are stored in NVS (Preferences) and retained after power loss. They can be changed with `/config/network` (see 4.2 below); after saving, the ESP32 restarts automatically to apply the new settings
- The MAC address is fixed in the sketch (it must not be duplicated on the same LAN)

### 4.2 API一覧 / API List

| エンドポイント<br>Endpoint | メソッド<br>Method | 説明<br>Description | レスポンス<br>Response |
|---|---|---|---|
| `/` | GET | ステータス確認用HTML（手動ON/OFFボタン付き）<br>HTML status page (with manual ON/OFF buttons) | HTML |
| `/tx?state=on` | GET | **PTT ON**（shonan-androidから呼び出し）<br>**PTT ON** (called from shonan-android) | `TX`（プレーンテキスト）<br>`TX` (plain text) |
| `/tx?state=off` | GET | **PTT OFF**（shonan-androidから呼び出し）<br>**PTT OFF** (called from shonan-android) | `RX`（プレーンテキスト）<br>`RX` (plain text) |
| `/toggle?ch=0..1` | GET | 個別チャンネル手動トグル（配線確認用デバッグ機能。0=POWER,1=PTT）<br>Manual toggle of an individual channel (debug feature for checking wiring; 0 = POWER, 1 = PTT) | `/` へリダイレクト<br>Redirect to `/` |
| `/ch?idx=0..1&state=on\|off` | GET | 個別チャンネル明示ON/OFF（0=POWER,1=PTT。Shonan_lite-PI4 GUI起動/終了時のGPIO26制御用）<br>Explicit ON/OFF of an individual channel (0 = POWER, 1 = PTT; used for GPIO26 control at Shonan_lite-PI4 GUI start/exit) | `ON`/`OFF`（プレーンテキスト）<br>`ON`/`OFF` (plain text) |
| `/api/status` | GET | 現在状態をJSONで取得<br>Get the current state as JSON | `{"power":bool,"ptt":bool,"tx_active":bool}` |
| `/config` | GET | 遅延時間・IP設定画面（HTML）<br>Delay time and IP settings page (HTML) | HTML |
| `/config/delay?power_delay_sec=..&ptt_delay_ms=..` | GET | POWER/PTTのON遅延時間を保存<br>Save the ON delay times for POWER/PTT | 設定画面へリダイレクト等<br>Redirect to the settings page, etc. |
| `/config/network?ip=..&gateway=..&subnet=..` | GET | 固定IPアドレスを保存し自動再起動<br>Save the fixed IP address and restart automatically | 設定画面へリダイレクト等<br>Redirect to the settings page, etc. |

### 4.3 呼び出し例 / Call Examples

```
送信開始時 / At TX start: GET http://<ESP32のIPアドレス / ESP32 IP address>/tx?state=on
送信終了時 / At TX end:   GET http://<ESP32のIPアドレス / ESP32 IP address>/tx?state=off
```

ESP32のIPアドレスは固定IP(初期値`192.168.0.100`、4.1参照)のため、shonan-android・Shonan_lite-PI4(pi4/gui)
いずれも設定画面で利用者が同じIPアドレスを入力・保持する運用とする。ESP32側のIPを`/config/network`で
変更した場合は、アプリ側の設定も合わせて変更すること（★DDNS/mDNS等による自動検出は本版では未実装）。

Since the ESP32 uses a fixed IP address (default `192.168.0.100`, see 4.1), the user enters and keeps the same IP address
on the settings screen of both shonan-android and Shonan_lite-PI4 (pi4/gui). If the ESP32's IP is changed with
`/config/network`, change the app settings accordingly (★automatic discovery via DDNS/mDNS, etc. is not implemented in
this revision).

### 4.4 Shonan_lite-PI4(pi4/gui)側の連携 / Integration on the Shonan_lite-PI4 (pi4/gui) Side

- 設定画面(`pi4/gui/screens/settings.py`)の「PA_Power/PTTコントローラ (ESP32)」欄で「ESP32 W5500を使用する」を
  ONにし、ESP32のIPアドレスを設定する。OFFまたは空欄の場合は連携自体を行わない（OFFにしてもIPアドレスは
  保持される。未接続環境でもTX/RXの動作に影響しない）。
- `pi4/gui/backend.py` の `TxController.start()` 冒頭で `/tx?state=on`、`stop()` 冒頭で
  `/tx?state=off` をGETする（PTTのみをON/OFFする）。タイムアウトは短く(1.5秒)設定し、
  ESP32が未接続/未応答でも例外を握りつぶしてTX本体の動作を妨げない（ログにのみ記録）。
- ESP32(MCU1)とPluto+の間に直接の通信経路はない。Pi4(pi4/gui)がPluto+へはSSHで`/www/settings.txt`を
  書き込み(`_push_pluto_settings()`)、ESP32へはHTTPで`/tx?state=`(`_send_ptt_request()`)を送る、
  それぞれ独立した構成であり、ESP32はPi4からのTX開始/終了通知のみを扱う。
- 上記PTT切替とは別に、Pi4アプリ(`pi4/gui/main.py`)自体の起動/終了に連動して
  GPIO26(POWERチャンネル、idx=0)を明示的に制御する（`_send_ptt_channel_state()`、
  `/ch?idx=0&state=on|off`を使用）。
  - アプリ起動から5秒後にGPIO26をON(Langstone V2Modifyへの切替時・起動メニューでLangstoneを選んだ時もON)
  - アプリ終了時、先にGPIO26をOFFにしてから3秒待って実際に終了
  - 12V電源の制御にPi4本体(Raspberry Pi4)のGPIOは使用しない。あくまでMCU1側のGPIO26を
    ネットワーク経由で制御する。
- ★ESP32 W5500(本コントローラ)は必須ではない。Pi4本体のGPIO21(40番ピン、GNDは39番ピン)が
  送信中HIGH(3.3V)・受信中LOWになるため、これをトランジスタ/リレードライバ等でバッファすれば
  ESP32なしでもPA・LNAの送受信切替ができる(Langstone V2ModifyのTx Outputと同じピン。Shonan_Lite側は
  `pi4/gui/backend.py`の`_set_pi_tx_gpio()`で`pinctrl`により出力)。ESP32を併用する場合は
  本コントローラのPTT(J6)も同時に切り替わる。12V電源のON/OFFは本コントローラが必要。

- In the "PA_Power/PTT Controller (ESP32)" field of the settings screen (`pi4/gui/screens/settings.py`), turn ON
  "Use ESP32 W5500" and set the ESP32's IP address. When it is OFF or the address is empty, no integration is performed
  (the IP address is kept even when OFF; TX/RX operation is not affected even without a controller connected).
- `TxController.start()` in `pi4/gui/backend.py` sends GET `/tx?state=on` at its beginning and `stop()` sends
  `/tx?state=off` at its beginning (only PTT is switched ON/OFF). The timeout is short (1.5 seconds), and even if the
  ESP32 is not connected or does not respond, the exception is swallowed so that TX itself is not disturbed (it is only logged).
- There is no direct communication path between the ESP32 (MCU1) and the Pluto+. The Pi 4 (pi4/gui) writes `/www/settings.txt`
  on the Pluto+ via SSH (`_push_pluto_settings()`) and sends `/tx?state=` (`_send_ptt_request()`) to the ESP32 via HTTP,
  independently of each other; the ESP32 only handles the TX start/stop notifications from the Pi 4.
- Separately from the PTT switching above, GPIO26 (POWER channel, idx=0) is explicitly controlled in conjunction with
  starting/exiting the Pi 4 app (`pi4/gui/main.py`) itself (`_send_ptt_channel_state()`, using `/ch?idx=0&state=on|off`).
  - GPIO26 is turned ON 5 seconds after app start (also when switching to Langstone V2Modify and when Langstone is selected in the boot menu)
  - At app exit, GPIO26 is turned OFF first, and the app actually exits after waiting 3 seconds
  - The Pi 4's own (Raspberry Pi 4) GPIO is not used for controlling the 12 V power. Only GPIO26 on the MCU1 side is
    controlled over the network.
- ★The ESP32 W5500 (this controller) is not required. GPIO21 of the Pi 4 (pin 40; GND on pin 39) is HIGH (3.3 V) while
  transmitting and LOW while receiving, so by buffering it with a transistor/relay driver, etc., the PA and LNA can be
  switched between TX and RX without the ESP32 (the same pin as Langstone V2Modify's Tx Output; on the Shonan_Lite side it is
  driven with `pinctrl` by `_set_pi_tx_gpio()` in `pi4/gui/backend.py`). When the ESP32 is also used, this controller's
  PTT (J6) switches at the same time. This controller is required for switching the 12 V power ON/OFF.

---

## 5. 未確定・今後の課題 / Open Items and Future Work

- ★ 12V電源／PTTの実際の駆動回路との結合試験（Q1/Q3/Q5の実機動作確認）は未実施。
- ★ mDNS対応（`http://shonan-ptt.local/` 等）による自動検出は未実装（IPアドレスは固定IP方式で、アプリ側に手入力する）。運用上必要であれば追加検討。
- ★ shonan-androidアプリ側でのHTTPリクエスト送出実装は本スケッチのスコープ外。アプリ側の送信ボタンハンドラに追加が必要。
- 実機ESP32への書き込みは完了（2026-08-30、MAC: `70:4b:ca:7b:eb:94`）。ただしW5500・12V電源/PTT駆動回路を実際に接続した結合試験、Pi4(pi4/gui)側との通信確認は未実施。
- GPIO25(旧LNA)は物理的に未接続のまま。今後LNA制御が必要になった場合は、駆動回路の追加とスケッチ・本書の再改訂が必要。

- ★ Integration testing with the actual 12 V power/PTT drive circuits (checking Q1/Q3/Q5 on real hardware) has not been done.
- ★ Automatic discovery via mDNS (such as `http://shonan-ptt.local/`) is not implemented (the IP address uses the fixed-IP method and is entered manually in the app). To be considered if needed in operation.
- ★ Sending HTTP requests from the shonan-android app is outside the scope of this sketch. It must be added to the app's transmit button handler.
- Writing to the actual ESP32 is complete (2026-08-30, MAC: `70:4b:ca:7b:eb:94`). However, the integration test with the W5500 and the 12 V power/PTT drive circuits actually connected, and the communication check with the Pi 4 (pi4/gui) side, have not been done.
- GPIO25 (former LNA) remains physically unconnected. If LNA control becomes necessary in the future, a drive circuit must be added and the sketch and this document revised again.

---

## 6. 関連ファイル / Related Files

- スケッチ本体 / Sketch: `hardware/W5500_PA_PTT_Control/W5500_PA_PTT_Control.ino`
- 回路図 / Schematic: `hardware/W5500_PA_PTT_Control/kicad/w5500-esp32.kicad_sch`（KiCad原本 / KiCad original）／`hardware/W5500_PA_PTT_Control/docs/W5500_PA_PTT_Control_回路図.svg`（KiCadから書き出したSVG。旧Rev.1.0の手書き概略図は実機と内容が乖離していたため2026-08-30に廃止し、KiCad原本からの書き出しに置き換えた / SVG exported from KiCad. The hand-drawn outline schematic of the old Rev.1.0 diverged from the actual hardware, so it was abolished on 2026-08-30 and replaced with an export from the KiCad original）
- MCU1/J1/W5500ピン対応の詳細表 / Detailed MCU1/J1/W5500 pin mapping table: [`MCU1_J1_W5500_接続一覧.md`](MCU1_J1_W5500_接続一覧.md)

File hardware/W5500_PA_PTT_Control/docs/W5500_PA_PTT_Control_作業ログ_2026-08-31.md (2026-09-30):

---
title: W5500_PA_PTT_Control 作業ログ（2026-08-31）
---

# W5500_PA_PTT_Control 作業ログ（2026-08-31）

本書は2026-08-31のセッションで行った作業内容の記録である。恒久的な仕様は
`W5500_PA_PTT_Control_仕様書.md`（Rev.2.2、本書作成時点）を正とし、本書は
その後の変更点と作業経緯のログとして扱う。仕様書側は本書の内容を踏まえて
別途Rev.3として改訂予定。

---

## 1. 経緯・調査

### 1.1 raspi5側の設定画面調査

「raspi5の設定画面にPAのIPアドレスを設定する項目を追加してほしい」という
依頼を受けて調査した結果、**既に実装済み**であることが判明した。

- `pi5/gui/screens/settings.py`（91〜101行目）に「PA_Power/PTTコントローラ
  (ESP32)」セクションがあり、`ptt_controller_ip_edit`（QLineEdit）でIPを
  入力・保存できる。
- 保存先は `~/.config/shonan-pi5/settings.json` の `ptt_controller_host`
  キー（`pi5/gui/settings_store.py`）。空欄なら連携無効。

→ 追加作業は不要と判断し、この件はクローズ。

### 1.2 ファームウェアの不整合の発覚

作業開始時点で使っていた独立検証用ディレクトリ
`/Users/kazuichishinjo/AppDev/W5500_PA_PTT_Control/`（本リポジトリ外）と、
本リポジトリの本番ファームウェア `hardware/W5500_PA_PTT_Control/W5500_PA_PTT_Control.ino`
とでGPIOピン配置・HTTP API名が食い違っていることが判明した。

| | 独立検証版（リポジトリ外） | 本番版（本リポジトリ） |
|---|---|---|
| GPIO25 | LNA（受信プリアンプ） | 未接続・廃止 |
| GPIO26 | PTT | POWER（12V電源） |
| GPIO27 | 12V電源 | PTT |
| API | `/power`, `/ptt`（新設） | `/tx`, `/ch`（既存仕様） |
| IP | 固定IP化 | DHCP（当時） |

**方針決定：本番版（本リポジトリのファイル）を正とし、以後の作業は本番版に対して行う。**
独立検証版ディレクトリには以後手を加えない。

---

## 2. 本番ファームウェアへの機能追加

`hardware/W5500_PA_PTT_Control/W5500_PA_PTT_Control.ino` に対し、以下の機能を追加した。

### 2.1 12V電源 / PTT の遅延ON機能

- `GET /ch?idx=0&state=on`（12V電源ON要求）を受信してから、設定した秒数
  （既定 **3秒**）待ってから実際にGPIO26をONにする。
- `GET /tx?state=on` および `GET /ch?idx=1&state=on`（PTT ON要求）を受信
  してから、設定したミリ秒（既定 **50ms**）待ってから実際にGPIO27をONにする。
- OFF要求（`state=off`）は安全のため**常に即時反映**し、保留中のON要求は
  キャンセルする。
- 実装は `delay()` によるブロッキングではなく、`millis()` を使った
  非ブロッキングのタイマー予約方式（`servicePendingOutputs()` を `loop()`
  内で毎回呼び出す）。HTTPサーバーは遅延待ち中も他のリクエストに応答できる。

### 2.2 遅延時間の設定機能（Web UI / HTTP API）

- `GET /config` … 遅延時間・IPアドレス設定用のHTML設定画面。
- `GET /config/delay?power_delay_sec=<秒>&ptt_delay_ms=<ms>` … 遅延時間を
  変更しNVS(Preferences、namespace `w5500cfg`)に保存。以後はNVSの値が
  優先され、電源断・再起動後も保持される。

### 2.3 IPアドレス変更機能（DHCP廃止・固定IP化）

- 従来のDHCP方式を廃止し、**固定IP方式**に変更した。初期値は
  `IP=192.168.0.100` / `Gateway=192.168.0.1` / `Subnet=255.255.255.0`。
- `GET /config/network?ip=<IP>&gateway=<GW>&subnet=<MASK>` でIP設定を
  変更しNVSに保存。保存後は `ESP.restart()` で自動再起動し新しいIPで
  起動し直す（Ethernetライブラリの制約上、動的な再初期化ではなく再起動で
  反映する方式とした）。
- MACアドレスは変更していない（`02:AA:BB:CC:DE:01`のまま。既存仕様書
  2.1節参照）。

### 2.4 `/api/status` の拡張

JSONレスポンスに以下のキーを追加した。

```json
{
  "power": true,
  "power_pending": false,
  "ptt": false,
  "ptt_pending": false,
  "tx_active": false,
  "power_delay_ms": 3000,
  "ptt_delay_ms": 50,
  "ip": "192.168.0.100"
}
```

`*_pending` は遅延ON待ち中（要求は受けたがまだGPIOに反映していない状態）
であることを示す。ステータスページ（`/`）の表示にも「ON待ち」状態を
反映済み。

---

## 3. WiFiテスト版の新規追加

W5500（イーサネットモジュール）が未実装の段階でもHTTPロジック
（GPIO制御・遅延処理・設定画面）だけを実機で検証できるよう、通信層のみ
ESP32内蔵WiFi（APモード）に置き換えたテスト用スケッチを新規に追加した。

- 配置場所: `hardware/W5500_PA_PTT_Control_WiFiTest/W5500_PA_PTT_Control_WiFiTest.ino`
- GPIO制御・HTTPハンドラ・遅延設定・NVS保存のロジックは本番版と完全に同一。
  Ethernet(W5500) → WiFi(ESP32内蔵AP) の置き換えのみ。
- 接続情報:
  - SSID: `PA-PTT-Test`
  - パスワード: `ptttest123`
  - 既定IP: `192.168.4.1`（`/config`から変更可、`WiFi.softAPConfig()`使用）
- W5500実装後は本番版に書き込み直すこと。本ディレクトリは削除して構わない。

### 3.1 動作確認結果

MacをSSID `PA-PTT-Test` に接続し、`http://192.168.4.1/` へのアクセスに
成功。ステータス画面・`/config`設定画面・`/api/status`のJSON取得を確認済み。

---

## 4. 実機書き込み作業

使用ツール: `arduino-cli`（`esp32:esp32:esp32` ボード、ESP32-D0WD-V3、
MAC(Wi-Fi/BT側チップMAC): `70:4b:ca:7b:eb:94`）。

### 4.1 転送速度のトラブルシューティング

初回、既定の転送速度（921600bps）で書き込みを試みたところ、
`A fatal error occurred: The chip stopped responding.` で失敗した。
`UploadSpeed=115200` を明示指定して再試行したところ成功した。以後の
書き込みはすべて115200bpsで実施している。

```
arduino-cli upload -p /dev/cu.usbserial-110 \
  --fqbn "esp32:esp32:esp32:UploadSpeed=115200" \
  <スケッチディレクトリ>
```

### 4.2 書き込み履歴

1. 本番版（旧・遅延/IP変更機能追加前）を書き込み、動作確認。
2. 遅延設定・IP変更機能を追加したWiFiテスト版を書き込み、
   `http://192.168.4.1/` にアクセスして動作確認（3節参照）。
3. 遅延設定・IP変更機能を追加した**本番版**を書き込み。起動ログは以下の通り
   （W5500未接続のため想定通りリンクアップに失敗している）。

```
=== W5500_PA_PTT_Control 起動 ===
[CFG] 12V電源ON遅延=3000ms, PTT ON遅延=50ms
[OUT] POWER 12V (GPIO26) -> OFF
[OUT] PTT (GPIO27) -> OFF
固定IPで初期化中... IP=192.168.0.100 GW=192.168.0.1 MASK=255.255.255.0
W5500が検出できません。配線を確認してください。
IPアドレス: 0.0.0.0
Webサーバー起動 (port 80)
```

設定値（遅延3000ms/50ms、固定IP 192.168.0.100/24）は正しく読み込まれて
いる。W5500配線完了後、同一LAN上のPCから `http://192.168.0.100/` への
アクセスで動作確認を行う必要がある（本書作成時点で未実施）。

---

## 5. Git操作

以下の変更をコミット・pushした（リポジトリ: `kazushinjo/Shonan_Lite-RasPI5`、
ブランチ: `main`）。

- コミット: `26137ba`
  - `hardware/W5500_PA_PTT_Control/W5500_PA_PTT_Control.ino`（変更）
  - `hardware/W5500_PA_PTT_Control_WiFiTest/W5500_PA_PTT_Control_WiFiTest.ino`（新規）
- push: `8dada17..26137ba main -> main`

---

## 6. 現状と今後の課題

- 本番ファームウェアはESP32実機に書き込み済み。ただしW5500ハードウェアの
  配線が未完了のため、実際のEthernet通信（`http://192.168.0.100/`への
  アクセス）は本書作成時点でまだ確認できていない。
- W5500配線完了後にやるべきこと:
  1. Macを192.168.0.0/24のLAN（ESP32と同一LAN）に接続。
  2. `http://192.168.0.100/` にアクセスし、ステータス画面・`/config`・
     `/api/status`が本番仕様書通りに動作することを確認。
  3. 12V電源／PTTの実駆動回路（Q1/Q3/Q5）との結合試験（仕様書5節の
     既存の未確定事項）。
- `W5500_PA_PTT_Control_仕様書.md`（Rev.2.2）は本書の変更内容
  （DHCP→固定IP化、遅延設定機能、`/config`系API追加）を反映していない。
  次回改訂時にRev.3として統合することが望ましい。
- WiFiテスト版（`hardware/W5500_PA_PTT_Control_WiFiTest/`）はW5500実装・
  結合試験が完了した時点で削除して構わない。

---

## 7. 関連ファイル

- 本番スケッチ: `hardware/W5500_PA_PTT_Control/W5500_PA_PTT_Control.ino`
- WiFiテスト用スケッチ: `hardware/W5500_PA_PTT_Control_WiFiTest/W5500_PA_PTT_Control_WiFiTest.ino`
- 既存仕様書（Rev.2.2、本書作成時点で本番版と一部内容が乖離）:
  `hardware/W5500_PA_PTT_Control/docs/W5500_PA_PTT_Control_仕様書.md`
- raspi5側の連携設定: `pi5/gui/screens/settings.py`（IP入力欄）、
  `pi5/gui/backend.py`（`_send_ptt_request()`, `_send_ptt_channel_state()`）

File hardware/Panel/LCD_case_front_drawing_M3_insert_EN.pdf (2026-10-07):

# LCD Case Drawing (15 mm bezel, back cover, 1 mm panel)

Front part of the case for a 5-inch LCD. The bezel border, from the window edge to the outline as
seen from the front, is 15 on all four sides. The four corner bosses take M3 threaded inserts, and
the back cover screws into them. L-shaped guides locate a DFR0550. All dimensions in mm.
5_in_lcd_case_front_bezel15.scad 2026-10-07

Window (display area)

front 111.55 × 68.29 / back 109.55 × 66.29 (C1)

4× Ø5.0 × 5 deep (from boss top) For M3 threaded inserts

Boss Ø6.62 ×4 (corners, merged into both inner walls)

A A

141.55
131.93

98.29
88.67

4.81
15
111.55

15

4.81
15

68.29

15

DFR0550 outline 120.8 × 75.8 (top toward −Y, FPC side toward +Y)

guide inside 121.4

guide inside 76.4

### Section A-A (top-right boss)

Ø5.0
for M3 insert

Ø6.62

depth 5

1.5

1.5

8

6.5

0.81 1.5

front face (Z=0)

back side (Z=8)

Ø5.0 × 5 deep holes are for M3 threaded inserts. All four bosses are the same.

The plan view is seen from the back (boss side, +Z). The dashed line in the section marks the inner wall. Coordinates match the STL / OpenSCAD model; the origin is offset from the outline center by X −1.365, Y −1.49.

### Bosses and insert holes

Item | Dimension | Notes
Insert hole | 4× Ø5.0 × 5 deep | For M3 threaded inserts. From boss top (Z=8) down to Z=3
Boss | Ø6.62 × 6.5 high | From plate top (Z=1.5) to Z=8. Corner side filled square and merged into the walls
Hole pitch | 131.93 × 88.67 | 4.81 from each outer edge to the boss center

Boss centers
(STL)

(67.331, 45.824) (−64.601, 45.824) (67.331, −42.844) (−64.601, −42.844)

| | Top right, top left, bottom right, bottom left

Material under
hole

### 1.5 Hole bottom Z=3 to plate top Z=1.5 (3.0 to the front face)

Boss wall | 0.81 | On the window side. The corner side is joined to the walls

### Outline

Item | Dimension | Notes
Outline | 141.55 × 98.29 × 8 | Corners R1, front outer edge C1
Inner wall | 138.55 × 95.29 | Wall 1.5 thick
Front plate | 1.5 thick
Window | back 109.55 × 66.29 front 111.55 × 68.29 | C1 chamfer. From outer edges: 15 on all sides (front), 16 (back). Window center (1.365, 1.49)

### DFR0550 locating guides

L-shaped guides that hold a DFRobot DFR0550 (5-inch DSI touchscreen) in line with the window. The DFR0550 mounting holes (113 × 68, M2.5) are covered by the LCD on the front, and two of them fall inside the display area, so the panel has no holes for them. Use them from the back through the standoffs.

Item | Dimension | Notes
Guides | 4× L, arm 12 / 1.2 thick / 4 high | At the four DFR0550 corners, from plate top (Z=1.5) to Z=5.5. Lower than the 5.7 LCD stack
Inside of guides | 121.4 × 76.4 | X −59.335 to 62.065, Y −34.35 to 42.05. 0.3 clearance per side around the 120.8 × 75.8 outline
DFR0550 center | (1.365, 3.85) | Center of the 113 × 68 holes. Puts the 108 × 64.8 display area in the middle of the window (about 0.75 margin)
Orientation | top → −Y | Narrow display margin (3.14) toward −Y, FPC and connector side toward +Y
FPC and connectors | 27 to 94 from left | Stick out up to 1.2 from the +Y edge. Guides are only at the corners, so they clear
DFR0550 holes (reference) | X −55.135 / 57.865 Y −30.15 / 37.85 | Dotted circles in the drawing. Not drilled in the panel

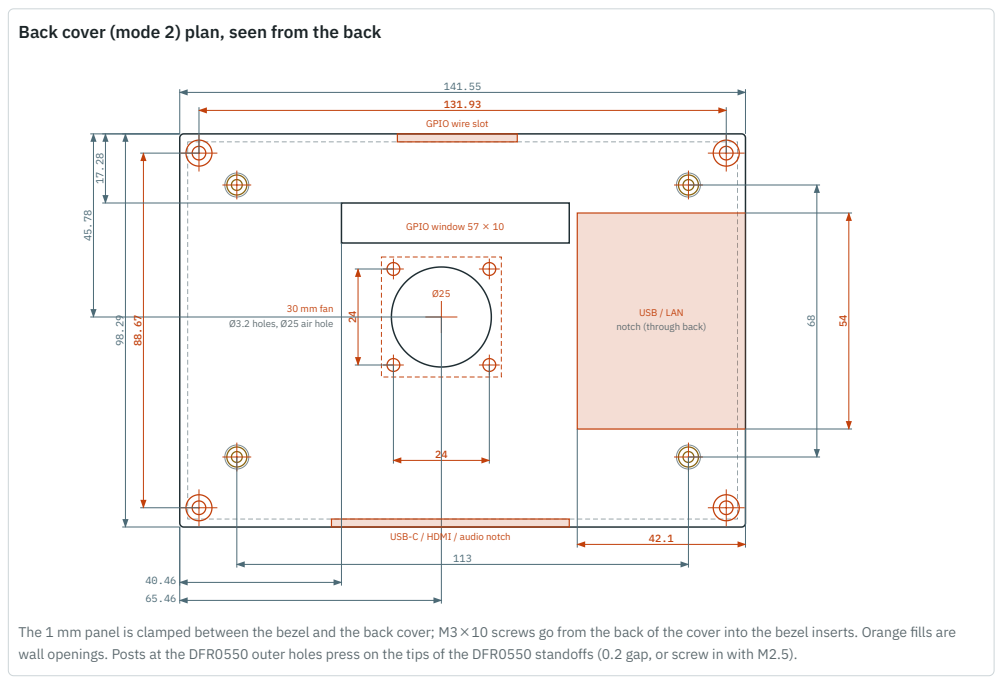
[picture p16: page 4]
GPIO window 57 × 10; 30 mm fan; GPIO wire slot

Back cover (mode 2) plan, seen from the back

USB / LAN
notch (through back)

Ø3.2 holes, Ø25 air hole

USB-C / HDMI / audio notch

The 1 mm panel is clamped between the bezel and the back cover; M3×10 screws go from the back of the cover into the bezel inserts. Orange fills are
wall openings. Posts at the DFR0550 outer holes press on the tips of the DFR0550 standoffs (0.2 gap, or screw in with M2.5).

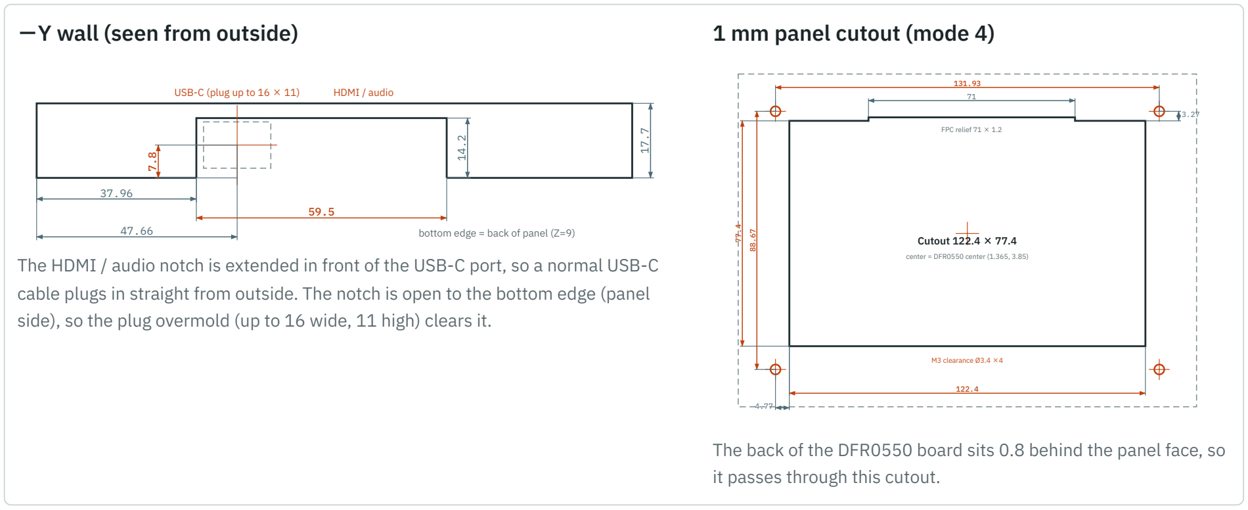
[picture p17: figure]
−Y wall (seen from outside); USB-C (plug up to 16 × 11); HDMI / audio; bottom edge = back of panel (Z=9); 1 mm panel cutout (mode 4); Cutout 122.4 × 77.4; center = DFR0550 center (1.365, 3.85); FPC relief 71 × 1.2; M3 clearance Ø3.4 ×4; it passes through this cutout.

The HDMI / audio notch is extended in front of the USB-C port, so a normal USB-C cable plugs in straight from outside. The notch is open to the bottom edge (panel side), so the plug overmold (up to 16 wide, 11 high) clears it.

The back of the DFR0550 board sits 0.8 behind the panel face, so

### Back cover and assembly

Item | Dimension | Notes
Back cover outline | 141.55 × 98.29 × 17.7 | Same outline as the bezel. Walls 2, back plate 2. Depth set by the GPIO header
M3 screw holes | Ø3.4, counterbore Ø6.5 | 131.93 × 88.67. 5 under the counterbore, counterbore 12.7 deep
M3 screws (cover → bezel) | M3 × 10 (11 max) | 5 under the head + 1 panel + 4 into the insert. 12 or longer hits the bottom of the 5-deep insert hole
M2.5 screws (DFR0550 hold- down, optional) | M2.5 × 6 | 3 post + 0.2 gap + about 2.8 into the DFR0550 standoff. Counterbore Ø5, 9.7 deep
DFR0550 hold-down posts | Ø6, hole Ø2.7, counterbore Ø5 113 × 68. Post ends 0.2 from the DFR0550 standoff tips (Z=13.8)
USB-C / HDMI / audio | 59.5 × 14.2 | −Y wall, open to the bottom edge. USB-C plugs in straight from outside (center X −21.755, Z 16.8, about 22 to the port)
USB / LAN | 42.1 × 54 notch | Back plate and wall cut away from the +X edge (Y −23.15 to 30.85). USB/LAN stick out about 4.5 past the back
GPIO window | 57 × 10 | Back plate, right above the header. Plug connectors in from outside with the cover on
30 mm fan | Ø3.2 holes × 4, 24 pitch | Mounted on the outside of the back. Center (−3.955, 4.85), over the Pi4 CPU. Ø25 air hole under the fan
GPIO wire slot | 30 × 6.5 | +Y wall (Z 17.7 to 24.2)
Panel cutout | 122.4 × 77.4 | Center (1.365, 3.85). FPC relief 71 × 1.2 on the +Y edge, M3 clearance Ø3.4 ×4
Height (from front, Z=0) | Z | Notes
Bezel rim, panel front face | 8

Height (from front, Z=0) | Z | Notes
Panel back, back cover seat | 9 | Panel 1 thick
Back of DFR0550 board | 8.8 | LCD 5.7 + board 1.6 (DFRobot CAD)
DFR0550 standoff tips, Pi4 board underside | 13.8 | Standoffs 5
Top of GPIO header | 23.7 | Board 1.4 + 8.5. Tallest part inside the cover
Back face of cover | 26.7 | 1 clearance + 2 plate

ThTeopPio4fiPsia4sUsuSmB/eLdAtNo sit on the DFR0550 inner holes (58 × 4391) .w2ith its Bcoomarpdo1ne.4nt+s1fa6c.inSgticokust,oUuStB4/.L5ApNastotwthaerdb+aXck, UthSrBo-uCg/hHDthMeIntootwcahrd −Y and GPIO toward +Y (check on the real hardware). SCAD mode: 1 bezel, 2 back cover, 3 assembly check, 4 panel cutout (DXF).

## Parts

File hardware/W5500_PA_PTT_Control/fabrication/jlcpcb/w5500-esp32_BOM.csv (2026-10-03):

Comment | Designator | Footprint | Qty | Note
W5500_Lite | A1 | W5500_Lite_USR-ES1_2x06_P2.54mm_20.32mm | 1 | W5500 Lite (USR-ES1互換) 2x6ピン
0.47uF | C1 | CP_Radial_D5.0mm_P2.00mm | 1 | 0.47µF 16V以上(LM2940データシートの入力コンデンサ。フィルムまたはセラミック、電解でも可)
0.33uF | C3 | CP_Radial_D5.0mm_P2.00mm | 1 | 0.33µF 25V以上(フィルムまたはセラミック、電解でも可)
33uF | C2 | CP_Radial_D5.0mm_P2.00mm | 1 | 33µF 10V以上 電解(極性あり、+側=+3.3V。LM2940は22µF以上・ESR 0.1〜1Ωが必要)
ESP32_DevKitC_Socket_40P_25.4mm | J1 | Socket_2x20_P2.54mm_25.4mm_DevKitC | 1 | 2.54mm 1x20 ピンソケット×2(列間隔25.4mm)でFreenove ESP32 WROOMを挿す
DC_IN_13V8 | J2 | SolderWire-1sqmm_1x02_P5.4mm_D1.4mm_OD2.7mm | 1 | 電線直付け(1mm²)
Power | J5 | SolderWire-1sqmm_1x02_P5.4mm_D1.4mm_OD2.7mm | 1 | 電線直付け(1mm²)
PTT_ON | J6 | JST_XH_B2B-XH-A_1x02_P2.50mm_Vertical | 1 | JST B2B-XH-A
LED_PWR | J7 | JST_XH_B2B-XH-A_1x02_P2.50mm_Vertical | 1 | JST B2B-XH-A(外付け赤LED)
LED_12V | J8 | JST_XH_B2B-XH-A_1x02_P2.50mm_Vertical | 1 | JST B2B-XH-A(外付け緑LED)
2SC1815 | Q1,Q3 | TO-92_Inline_Wide | 2
2SJ334 | Q5 | TO-220-3_Vertical | 1 | 放熱器 秋月105054(TO-220NIS)
510 | R6,R7 | R_Axial_DIN0207_L6.3mm_D2.5mm_P5.08mm_Vertical | 2
1k | R8 | R_Axial_DIN0309_L9.0mm_D3.2mm_P5.08mm_Vertical | 1 | 1/2W
10k | R9,R10,R11,R12,R13 | R_Axial_DIN0207_L6.3mm_D2.5mm_P5.08mm_Vertical | 5
LM2940T-3.3 | U1 | TO-220-3_Vertical | 1 | 3.3V 1A LDO(足 1=IN/2=GND/3=OUT)。放熱器 秋月105054
L7805 | U2 | TO-220-3_Vertical | 1 | 放熱器 秋月105054

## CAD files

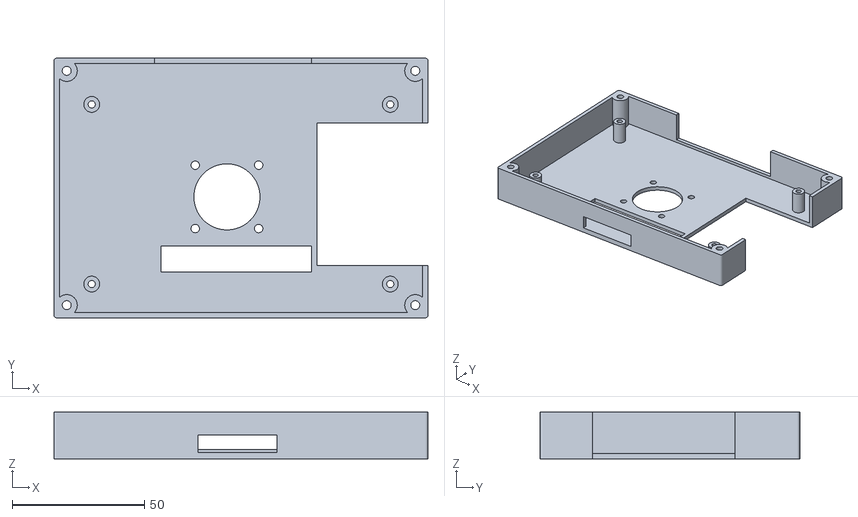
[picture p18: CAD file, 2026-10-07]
hardware/Panel/5_in_lcd_case_back_cover.stl
141.6 x 98.3 x 17.7

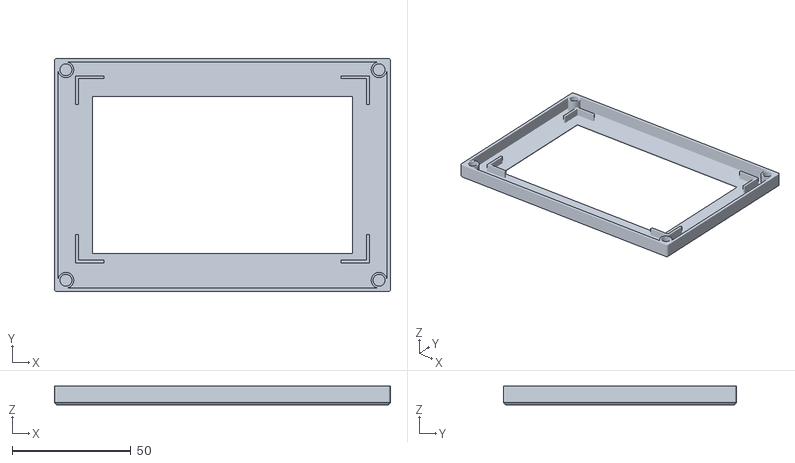
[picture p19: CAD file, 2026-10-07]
hardware/Panel/5_in_lcd_case_front_bezel15.stl
141.6 x 98.3 x 8.00

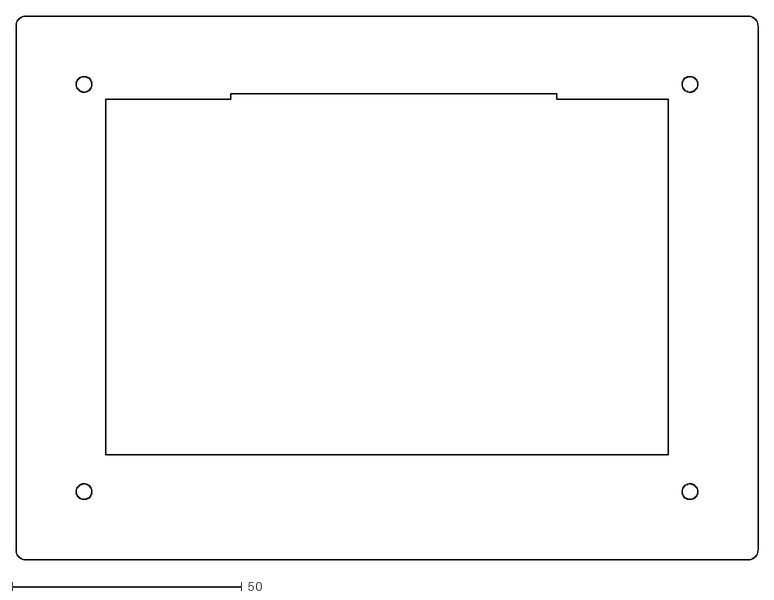
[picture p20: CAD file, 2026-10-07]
hardware/Panel/5_in_lcd_panel_cutout_1mm.dxf
161.6 x 118.3

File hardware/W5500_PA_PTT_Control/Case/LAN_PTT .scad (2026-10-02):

// ==========================================
// パラメータ設定
// ==========================================

// --- ケースのパラメータ ---

//  - mode = 1：本体のみ
//  - mode = 2：蓋のみ
//  - mode = 3：組立状態
//  - mode = 4：分解図

mode = 2;            // 1:本体のみ 2:蓋のみ 3:組立状態 4:分解図
inner_x = 80;       // 内寸 X (幅)
inner_y = 120;      // 内寸 Y (奥行)
inner_z = 35;       // 内寸 Z (高さ)
thickness = 2.5;    // 肉厚
corner_r = 5.0;     // 外側の角丸の半径 (R)

// --- ボスのパラメータ ---
pitch_x = 66;       // ボス配置のX方向間隔
pitch_y = 109;      // ボス配置のY方向間隔
boss_od = 8.0;      // ボス外径
boss_id = 5.0;      // ボス内径（ビス穴）
boss_h  = 5.0;      // ボスの高さ

// --- 穴のパラメータ ---
hole_d  = 16.0;     // 丸穴の直径

// 1つ目の穴 (前面の丸穴)
hole1_x = 20.0;     // X座標 (内寸基準)
hole1_z = 17.5;     // Z座標 (内寸基準)

// 2つ目の穴 (背面の丸穴)
hole2_x = 20.0;     // X座標 (内寸基準)
hole2_y = 120.0;    // Y座標 (内寸基準・背面の壁)
hole2_z = 17.5;     // Z座標 (内寸基準)

// --- 角穴のパラメータ (前面の切り欠き) ---
notch_x_start = 45.0; // X開始位置
notch_z_start = 10.6; // Z開始位置 RJ45下端=基板面+5 → Z11.6、下に1.0mm余裕
notch_w       = 18.0; // 幅 (63 - 45)
notch_h       = 14.9; // 高さ (25.5 - 10.6) RJ45上端=基板面+18 → Z24.6、上に0.9mm余裕

// --- はめ込み蓋のパラメータ ---
lid_top_t       = 2.5; // 蓋の天板厚
lid_lip_h       = 9.0; // 差し込みリップの高さ
lid_lip_wall    = 1.5; // リップの壁厚
lid_clearance   = 0.0; // 本体との片側クリアランス
explode_offset  = 20.0; // 分解図で蓋を持ち上げる距離

// --- 蓋リップの切り欠き ---
lid_notch_x = 20.0;     // X中心座標（内寸基準）
lid_notch_w = 25.0;     // 横幅
lid_notch_h = 8.0;      // 高さ（リップ下端から上方向）

// --- 蓋のエンボス文字 ---
// [文字, X座標(左端), Y座標, 縦の揃え, 文字の大きさ] 座標は内寸基準。
// 縦の揃え "baseline"=Yが文字の下端、"top"=Yが文字の上端（背面の縁で外へはみ出さないように）
lid_labels = [
    ["+12V INPUT",         3.0,  10.0, "baseline", 4.0],  // 前面側 (+12V入力コネクタの上)
    ["PA/PTT Control",  5.0,  60.0, "baseline", 7.0],  // 中央
    ["+12V OUTPUT",        3.0, 115.0, "top",      4.0],  // 背面側 (12V出力コネクタの上)
];
// 文字の大きさはOpenSCADのtext()のsize (大文字の高さはその約0.7倍)
lid_text_h      = 1.0;    // 天板からの盛り上げ高さ
lid_text_font   = "Liberation Sans:style=Bold";

// 3つ目の穴 (背面の角丸長方形穴・中心座標)
hole3_x = 50.0;
hole3_y = 120.0;
hole3_z = 13.6;       // ボス5 + 基板1.6 + 基板面からType-C中心7 (旧7.0)
hole3_w = 15.0;       // 横幅
hole3_h = 6.0;        // 高さ
hole3_r = 1.5;        // 角丸半径

$fn = 60;           // 円や角丸の滑らかさ

// ==========================================
// 自動計算される値
// ==========================================
outer_x = inner_x + (thickness * 2);
outer_y = inner_y + (thickness * 2);
outer_z = inner_z + thickness;

inner_corner_r = max(0.1, corner_r - thickness);

// ボス群をケース中央に配置するためのX/Yオフセット量
offset_x = thickness + (inner_x - pitch_x) / 2;
offset_y = thickness + (inner_y - pitch_y) / 2;

// ==========================================
// モジュール定義
// ==========================================

// --- 角丸の直方体 ---
module rounded_box(w, d, h, r) {
    translate([r, r, 0])
    linear_extrude(height = h)
    offset(r = r)
    square([w - 2*r, d - 2*r]);
}

// --- ボス単体 ---
module mounting_boss() {
    difference() {
        cylinder(d=boss_od, h=boss_h);
        // 内側のくり抜き
        translate([0, 0, -0.5])
            cylinder(d=boss_id, h=boss_h + 1.0);
    }
}

// --- XZ面の角丸長方形をY方向に押し出した穴あけ用形状 ---
module rounded_hole_xz(w, depth, h, r) {
    hull() {
        for (x = [r, w - r])
            for (z = [r, h - r])
                translate([x, 0, z])
                    rotate([-90, 0, 0])
                    cylinder(r = r, h = depth);
    }
}

// --- 4隅のボスレイアウト ---
module boss_layout() {
    translate([0,       0,       0]) mounting_boss(); // 左下
    translate([pitch_x, 0,       0]) mounting_boss(); // 右下
    translate([pitch_x, pitch_y, 0]) mounting_boss(); // 右上
    translate([0,       pitch_y, 0]) mounting_boss(); // 左上
}

// ==========================================
// 本体
// ==========================================
module body() {
    union() {
    // 1. ケース本体
    difference() {
        // 外形
        rounded_box(outer_x, outer_y, outer_z, corner_r);
        
        // 内側のくり抜き
        translate([thickness, thickness, thickness])
            rounded_box(inner_x, inner_y, inner_z + 1, inner_corner_r); 
            
        // --- 1つ目の穴あけ (前面の丸穴) ---
        translate([thickness + hole1_x, -1, thickness + hole1_z])
            rotate([-90, 0, 0])
            cylinder(d=hole_d, h=thickness + 2);
            
        // --- 2つ目の穴あけ (背面の丸穴) ---
        translate([thickness + hole2_x, thickness + hole2_y - 1, thickness + hole2_z])
            rotate([-90, 0, 0])
            cylinder(d=hole_d, h=thickness + 2);

        // --- 3つ目の穴あけ (背面の角丸長方形穴) ---
        translate([
            thickness + hole3_x - hole3_w / 2,
            thickness + hole3_y - 1,
            thickness + hole3_z - hole3_h / 2
        ])
            rounded_hole_xz(hole3_w, thickness + 2, hole3_h, hole3_r);

        // --- 4つ目の穴あけ (前面の角穴) ---
        translate([thickness + notch_x_start, -1, thickness + notch_z_start])
            cube([notch_w, thickness + 2, notch_h]);
    }
    
        // 2. ボス部品の配置
        translate([offset_x, offset_y, thickness]) {
            boss_layout();
        }
    }
}

// ==========================================
// はめ込み蓋
// ==========================================
module lid() {
    lid_outer_x = outer_x + lid_clearance * 2;
    lid_outer_y = outer_y + lid_clearance * 2;
    lid_outer_r = corner_r + lid_clearance;

    // 差し込みリップは本体の内側に入るリング状の形状
    lip_outer_x = inner_x - lid_clearance * 2;
    lip_outer_y = inner_y - lid_clearance * 2;
    lip_outer_r = max(0.1, inner_corner_r - lid_clearance);

    difference() {
        union() {
            // 蓋の天板（z=0から上向き）
            rounded_box(lid_outer_x, lid_outer_y, lid_top_t, lid_outer_r);

            // 天板の上面に盛り上げた文字（前面側から読める向き）
            for (label = lid_labels)
                translate([thickness + label[1], thickness + label[2], lid_top_t - 0.01])
                    linear_extrude(height = lid_text_h + 0.01)
                    text(label[0], size = label[4], font = lid_text_font,
                         halign = "left", valign = label[3]);

            // 蓋の裏側へ伸びる差し込みリップ（z=0より下）
            translate([lid_clearance + (outer_x - inner_x) / 2,
                       lid_clearance + (outer_y - inner_y) / 2,
                       -lid_lip_h])
                difference() {
                    rounded_box(lip_outer_x, lip_outer_y, lid_lip_h, lip_outer_r);
                    translate([lid_lip_wall, lid_lip_wall, -0.5])
                        rounded_box(lip_outer_x - lid_lip_wall * 2,
                                    lip_outer_y - lid_lip_wall * 2,
                                    lid_lip_h + 1,
                                    max(0.1, lip_outer_r - lid_lip_wall));
                }
        }

        // 前面リップの切り欠き（X=20、Y=0）
        translate([thickness + lid_notch_x - lid_notch_w / 2,
                   -1,
                   -lid_lip_h])
            cube([lid_notch_w, lid_lip_wall + 4, lid_notch_h]);

        // 背面リップの切り欠き（X=20、Y=120）
        translate([thickness + lid_notch_x - lid_notch_w / 2,
                   lid_outer_y - lid_lip_wall - 4,
                   -lid_lip_h])
            cube([lid_notch_w, lid_lip_wall + 4, lid_notch_h]);
    }
}

// ==========================================
// 表示モード
// ==========================================
if (mode == 1) {
    body();
} else if (mode == 2) {
    // 蓋だけを正のZ範囲に表示
    translate([0, 0, lid_lip_h])
        lid();
} else if (mode == 3) {
    // 組立状態
    body();
    translate([0, 0, outer_z])
        lid();
} else if (mode == 4) {
    // 分解図：蓋を本体の上方へ移動
    body();
    translate([0, 0, outer_z + explode_offset])
        lid();
}

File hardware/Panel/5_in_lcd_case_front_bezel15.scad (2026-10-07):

// 5インチLCDケース前面(ベゼル) 縁15mm版
// 窓は v18+2mm と同じ大きさ・位置。窓の縁から外形まで(前面から見た幅)を上下左右とも bezel にし、
// 4隅のボスに M3 インサートナット用の穴をあける。DFR0550 用に4隅の L 字ガイドを付ける。
// 裏蓋は 1mm のパネルを挟んでベゼルのインサートに M3 で締める。DFR0550 の裏に Pi4 を載せる前提。座標は元の STL と同じ(窓の中心 = (1.365, 1.49))

/* [出力] */
// 1: ベゼル(印刷用)  2: 裏蓋(印刷用、背面を下に置いた向き)  3: 組み立て確認(パネル・DFR0550・Pi4 は半透明)
// 4: 1mm パネルの切り抜き(2D、DXF 書き出し用)
mode = 1;

/* [ベゼル] */
bezel_x = 15;        // 左右の縁の幅 (窓の表面側の縁から外形まで)
bezel_y = 15;        // 上下の縁の幅

/* [取り付け穴] */
hole_d     = 5;      // 穴径 (M3 インサートナット用)
hole_depth = 5;      // 穴深さ (ボス上面から)
boss_d     = 6.62;   // ボス外径
wall_gap   = 0;      // 壁とボスのすき間 (0 で壁に接し、隅を四角く埋める)

/* [DFR0550 位置決めガイド] */
dfr_guide = true;            // DFR0550 (DFRobot 5" DSI) の位置決めガイドを付ける
dfr_size  = [120.8, 75.8];   // DFR0550 の外形
dfr_c     = [1.365, 3.85];   // DFR0550 の中心 (= 取付穴 113×68 の中心)。表示領域が窓の中央に来る位置
guide_gap = 0.3;             // DFR0550 とガイドのすき間 (片側)
guide_t   = 1.2;             // ガイドの厚さ
guide_len = 12;              // L字の腕の長さ (外側の角から)
guide_h   = 4;               // ガイドの高さ (板の上面から。液晶部の厚さ 5.7 より低くする)

/* [裏蓋 (1mm パネルを挟んで M3 で締める)] */
panel_t     = 1;       // 挟むパネルの厚さ
bc_wall     = 2;       // 裏蓋の壁厚
bc_plate    = 2;       // 裏蓋の背面の板の厚さ
bc_clear    = 1;       // 裏蓋の中で一番高い部品と背面の板のすき間
m3_clear_d  = 3.4;     // M3 ネジの通し穴
m3_head_d   = 6.5;     // M3 ネジ頭の座ぐり
m3_seat     = 5;       // 座ぐりの底の厚さ (ネジは M3×10。座ぐり底 5 + パネル 1 + インサートに 4。最長 11)
col_d       = 8;       // M3 ネジ用の柱の径
dfr_post    = true;    // DFR0550 の外側取付穴(113×68)の支柱を裏から押さえる柱を付ける
post_d      = 6;       // その柱の径
post_gap    = 0.2;     // 柱の先と DFR0550 の支柱の先のすき間
m25_clear_d = 2.7;     // M2.5 ネジの通し穴 (柱から DFR0550 の支柱にネジ止めもできる)
m25_head_d  = 5;       // M2.5 ネジ頭の座ぐり
vent        = false;   // 背面の板に通気用の小さい丸穴をあける (千鳥配置)。ファンの φ25 の穴だけにするので使わない
vent_d      = 3;       // 丸穴の径
vent_pitch  = 5;       // 丸穴の間隔
fan         = true;    // 背面に 30mm ファンを付ける穴 (ネジ穴 4 つと、風を通す大きな丸穴)
fan_hole_d  = 25;      // ファンの下の風を通す丸穴の径
fan_size    = 30;      // ファンの外形
fan_pitch   = 24;      // ファンのネジ穴の間隔
fan_screw_d = 3.2;     // ファンのネジ穴 (M3 の通し穴。タッピングなら 2.6 くらい)
fan_keepout = 6;       // ファンのネジ穴の中心からこの半径の中には通気穴をあけない (ファンの外形の中にも小さい通気穴はあけない)
gpio_slot   = true;    // GPIO の配線を出すスリット (+Y の壁)
gpio_window = true;    // GPIO ヘッダーの真上の背面に窓をあけ、裏蓋を付けたまま外からコネクタを差せるようにする
usb_notch   = true;    // 裏蓋を浅くし、背の高い USB/LAN の上は背面ごと切り欠いて外へ出す (false で USB/LAN が入る深さ)
usbc_notch  = true;    // HDMI・音声の切り欠きを USB-C の前まで延ばし、外からまっすぐ差せるようにする
usbc_direct = false;   // 切り欠きの代わりに、USB-C の正面に筒状の穴を作る
usbc_tunnel = [16, 11];// 筒の内側の幅・高さ (プラグの根元のモールドが通る大きさ)
usbc_tube_t = 1.5;     // 筒の壁厚
usbc_panel  = false;   // パネル取り付け型 USB-C 延長ケーブルのメス側を -Y の壁に付ける穴 (筒を使わないとき)
usbc_cut    = [11, 5]; // メス側の本体を通す穴 (角丸の長穴)。使う延長ケーブルに合わせて変える
usbc_pitch  = 28;      // 固定ネジの間隔 (0 でネジ穴なし)
usbc_screw  = 3.2;     // 固定ネジの穴径
usbc_x      = -42;     // 取り付け位置 X。Pi4 の USB-C の正面を避け、ケーブルを曲げて回せる位置にする

/* [DFR0550・Pi4 の高さ (DFRobot 公式 CAD の値)] */
dfr_lcd_t = 5.7;       // 液晶部の厚さ (パネルに当たる面から基板まで)
dfr_pcb_t = 1.6;       // 基板の厚さ
dfr_so_h  = 5;         // 裏の支柱の長さ (M2.5)
pi_pcb_t  = 1.4;       // Pi4 の基板の厚さ
pi_tall   = 16;        // Pi4 の一番高い部品 (USB) の基板からの高さ
pi_low    = 8.5;       // USB/LAN 以外で一番高い部品 (GPIO ヘッダー) の基板からの高さ
pi_usb_l  = 21;        // USB/LAN の部分の長さ (基板の +X 端から)
// Pi4 は DFR0550 の内側取付穴(58×49)に、部品面を裏蓋側に向けて付ける。
// DSI コネクタが DFR0550 の DISPLAY コネクタ(-X 側)に近い向きで、USB/LAN は +X、USB-C/HDMI は -Y を向く。
pi_org = [dfr_c[0] - 34.32, dfr_c[1] - 28.0];   // Pi4 の基板の角 (USB-C/HDMI 側・DSI 側) の位置

/* [固定値: 元形状] */
win_c     = [1.365, 1.49];     // 窓の中心
win_front = [111.552, 68.288]; // 窓 表面側 (Z=0)
win_cham  = 1;                 // 窓の面取り C1 (奥側は 109.552 × 66.288)
plate     = 1.5;               // 前面の板の厚さ
wall      = 1.5;               // 壁厚
height    = 8;                 // 全高 (ボス上面)
edge_cham = 1;                 // 前面外周の面取り C1
corner_r  = 1;                 // 外形の角 R
$fn = 72;

outer = [win_front[0] + 2*bezel_x, win_front[1] + 2*bezel_y];
inner = [outer[0] - 2*wall, outer[1] - 2*wall];
off   = boss_d/2 + wall_gap;
boss_pos = [for (sx=[1,-1], sy=[1,-1]) [win_c[0] + sx*(inner[0]/2 - off), win_c[1] + sy*(inner[1]/2 - off)]];
echo(str("外形 = ", outer[0], " x ", outer[1], " x ", height));
echo(str("穴ピッチ = ", inner[0] - 2*off, " x ", inner[1] - 2*off));
for (p=boss_pos) echo(str("ボス中心 = ", p));
if (dfr_guide) echo(str("DFR0550 ガイドの内側 = X ", dfr_c[0]-dfr_size[0]/2-guide_gap, " 〜 ", dfr_c[0]+dfr_size[0]/2+guide_gap,
                        "  Y ", dfr_c[1]-dfr_size[1]/2-guide_gap, " 〜 ", dfr_c[1]+dfr_size[1]/2+guide_gap));

module rrect(size, r) {
  if (r <= 0) square(size, center=true);
  else offset(r=r) square([size[0]-2*r, size[1]-2*r], center=true);
}

module outer_body() {   // 前面外周 C1、角 R1
  hull() {
    linear_extrude(0.01) rrect([outer[0]-2*edge_cham, outer[1]-2*edge_cham], max(corner_r-edge_cham, 0));
    translate([0,0,edge_cham]) linear_extrude(height-edge_cham) rrect(outer, corner_r);
  }
}

module window_cut() {   // 表面側が広い C1 の面取り
  hull() {
    translate([0,0,-0.01]) linear_extrude(0.01) square(win_front, center=true);
    translate([0,0,win_cham]) linear_extrude(0.01) square([win_front[0]-2*win_cham, win_front[1]-2*win_cham], center=true);
  }
  translate([0,0,win_cham]) linear_extrude(plate) square([win_front[0]-2*win_cham, win_front[1]-2*win_cham], center=true);
}

// DFR0550 の4隅に置く L 字のガイド。下側(+Y、FPC 側)の FPC・コネクタ(左端から 27〜94)を避けるため隅だけにする
module dfr_guides() {
  g = [dfr_size[0]/2 + guide_gap, dfr_size[1]/2 + guide_gap];
  for (sx=[1,-1], sy=[1,-1]) translate([dfr_c[0] + sx*g[0], dfr_c[1] + sy*g[1], plate-0.01])
    mirror([sx<0 ? 1 : 0, 0, 0]) mirror([0, sy<0 ? 1 : 0, 0]) {
      translate([-(guide_len-guide_t), 0, 0]) cube([guide_len, guide_t, guide_h+0.01]);
      translate([0, -(guide_len-guide_t), 0]) cube([guide_t, guide_len, guide_h+0.01]);
    }
}

module bezel() {
  difference() {
    union() {
      if (dfr_guide) dfr_guides();
      translate(win_c) difference() {
        outer_body();
        translate([0,0,plate]) linear_extrude(height) square(inner, center=true);   // 内側の空間
        window_cut();
      }
      for (p=boss_pos) translate([p[0],p[1],plate-0.01]) {
        cylinder(d=boss_d, h=height-plate+0.01);                                     // ボス
        if (wall_gap == 0)   // 隅側を四角く埋めて壁と一体にする
          let(sx=sign(p[0]-win_c[0]), sy=sign(p[1]-win_c[1]))
            translate([sx<0 ? -off-0.05 : 0, sy<0 ? -off-0.05 : 0, 0]) cube([off+0.05, off+0.05, height-plate+0.01]);
      }
    }
    for (p=boss_pos) translate([p[0],p[1],height-hole_depth]) cylinder(d=hole_d, h=hole_depth+0.1);  // M3 インサート穴
  }
}

// ---------------- 裏蓋 ----------------
z_panel  = height;                                   // パネルの表面 (ベゼルの縁)
z_bc     = height + panel_t;                         // 裏蓋がパネルに当たる面
z_dfr_so = plate + dfr_lcd_t + dfr_pcb_t + dfr_so_h; // DFR0550 の支柱の先 (Pi4 の基板の下面)
z_pi_top = z_dfr_so + pi_pcb_t + pi_tall;            // Pi4 の一番高い部品の上
z_bc_in  = (usb_notch ? z_dfr_so + pi_pcb_t + pi_low : z_pi_top) + bc_clear;   // 裏蓋の内側の天井
z_bc_top = z_bc_in + bc_plate;                       // 裏蓋の背面
dfr_holes = [for (sx=[1,-1], sy=[1,-1]) [dfr_c[0] + sx*56.5, dfr_c[1] + sy*34]];
echo(str("裏蓋の高さ = ", z_bc_top - z_bc, "  (パネル裏から背面まで)"));

// 開口 [x0, x1, y0, y1, z0, z1] (STL の座標)
pi_x1 = pi_org[0] + 85;
// プラグの根元のモールドが当たらないよう、壁の開口は下の縁(パネル側)まで切り欠く
op_usb   = [pi_x1 - 1, outer[0], pi_org[1] + 1, pi_org[1] + 55, z_bc - 1, z_pi_top + 1.3];                    // USB/LAN (+X)
op_power = [pi_org[0] + (usbc_notch ? 1.5 : 21.5), pi_org[0] + 61, -outer[1], pi_org[1] + 1, z_bc - 1, z_dfr_so + pi_pcb_t + 8];      // USB-C・HDMI・音声 (-Y)
fan_c    = [pi_org[0] + 29, pi_org[1] + 29];                  // ファンの中心 (Pi4 の CPU の上。GPIO の窓から 3.5 離す)
vent_area = [pi_org[0] + 12, pi_org[0] + 60, pi_org[1] + 6, pi_org[1] + 44.5];   // 丸穴をあける範囲 [x0, x1, y0, y1]
z_usbc   = (z_bc + z_bc_in) / 2;                                                                               // USB-C 延長のメス側の高さ
usbc_c   = [pi_org[0] + 11.2, z_dfr_so + pi_pcb_t + 1.6];   // Pi4 の USB-C の中心 (X, Z)
usbc_y1  = pi_org[1] - 1.5;                                  // 筒の奥の端 (Pi4 の基板の縁の少し手前)
op_gpio  = [pi_org[0] + 18, pi_org[0] + 48, pi_org[1] + 40, outer[1], z_bc_in - 7, z_bc_in - 0.5];          // GPIO の配線 (+Y)

module box_cut(o) { translate([o[0], o[2], o[4]]) cube([o[1]-o[0], o[3]-o[2], o[5]-o[4]]); }
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

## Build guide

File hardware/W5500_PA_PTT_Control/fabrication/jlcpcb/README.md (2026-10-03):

# JLCPCB 発注データ (W5500 PA/PTT 制御基板 Rev.1.2)

基板 Rev.1.2 は仕様書 Rev.2.8 に対応する(版数の対応表は `docs/W5500_PA_PTT_Control_仕様書.md` を参照)。

KiCad 10 の `kicad/w5500-esp32.kicad_pcb` から出力した JLCPCB 向けの製造データ。
部品はスルーホールだけなので、基板のみを発注して手はんだで組み立てる想定(PCBA は使わない)。

## ファイル

| ファイル | 内容 |
|---|---|
| `w5500-esp32_jlcpcb_gerber.zip` | **JLCPCB にアップロードするファイル**(下記 `gerber/` の中身をまとめたもの) |
| `gerber/*.gtl` / `*.gbl` | 銅箔 表(F.Cu) / 裏(B.Cu) |
| `gerber/*.g1` / `*.g2` | 内層1(GND 全面ベタ) / 内層2(+12V 全面ベタ) |
| `gerber/*.gts` / `*.gbs` | レジスト 表 / 裏 |
| `gerber/*.gto` / `*.gbo` | シルク 表 / 裏 |
| `gerber/*.gm1` | 基板外形(Edge.Cuts) |
| `gerber/*-PTH.drl` / `*-NPTH.drl` | ドリル(Excellon、mm)。スルーホール103穴(部品99+ビア4) / めっきなし10穴(取付穴φ3.2が4穴、放熱器ピン用φ1.8が6穴) |
| `w5500-esp32_BOM.csv` | 部品表(手配用。JLCPCB の部品実装には使わない) |

## 発注時の設定

| 項目 | 設定 |
|---|---|
| Base Material | FR-4 |
| Layers | **4** |
| Dimensions | 72 × 115 mm(自動で読み取られる値を確認) |
| PCB Qty | 任意(最小5枚) |
| Product Type | Industrial/Consumer electronics |
| Different Design | 1 |
| Delivery Format | Single PCB |
| PCB Thickness | 1.6 mm |
| PCB Color | 任意(緑が最安・最短) |
| Silkscreen | 白 |
| Surface Finish | HASL(with lead) または LeadFree HASL |
| Outer Copper Weight | **1 oz**(12V出力は表裏とも幅4mmのパターン。1ozで5A以上に対応) |
| Inner Copper Weight | 0.5 oz(標準)。+12V/GND は全面ベタなので標準で足りる。余裕を持たせるなら 1 oz |
| Impedance Control | 不要 |
| Layer Stackup | 標準(JLC04161H-7628 など、既定のもの) |
| Via Covering | Tented(ビアは4個だけ、すべて信号・電源の細い配線用) |
| Min via hole size/diameter | 0.3mm/(0.4/0.45mm)(設計のビアは穴0.4mm・外径0.8mm) |
| Board Outline Tolerance | ±0.2mm(標準) |
| Confirm Production file | 任意 |
| Remove Order Number | **Specify a location**(シルクの `JLCJLCJLCJLC` の位置に注文番号が入る。背面側の空き領域) |
| Castellated Holes / Edge Plating など | 不要 |

## 設計ルール(JLCPCB の4層の製造能力内)

- 配線幅 最小 0.3mm(信号) / 0.8mm(+5V・+3.3V) / 2〜4mm(12V出力)
- クリアランス 最小 0.25mm、ベタとのクリアランス 0.4mm
- ビア 穴0.4mm / 外径0.8mm(4個)、最小の部品穴 0.8mm(抵抗・トランジスタ等)
- 基板端から銅箔まで 0.5mm以上
- 放熱器(秋月 105054)の取付ピン(φ1.4mm、間隔12.5mm)用の穴はφ1.8mmのめっき無しで、穴の縁から1mm以内は全層で銅箔なし(ピンと内層ベタのショート防止)
- KiCad の DRC(回路図との照合を含む)で違反0件・未接続0件を確認済み

## 発注前に確認すること(未確認の項目)

- **Freenove ESP32 WROOM ボードの外形と USB-C の位置**は公式ピン配置図から読み取った推定値(約27×58.5mm)。実物を測って、ケースの USB 開口と合うか確認すること。
- **W5500 Lite モジュールの寸法**もデータシートからの値。RJ45 がケース前面の角穴に合うか実物で確認すること。
- ESP32 ソケット(ピンソケット)の高さと、ケースの USB 開口の高さ(z=7mm)が合うか確認すること。

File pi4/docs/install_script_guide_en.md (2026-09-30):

# pi4/scripts/install.sh Detailed Guide

English translation of [`install_script_guide.md`](install_script_guide.md) (Japanese original).
If the two differ, the Japanese original takes precedence.

`install.sh` is a single script that sets up the whole shonan-pi4 suite (Shonan_Lite itself, GNU Radio for receiving,
Langstone V2Modify and the boot menu) on a fresh Raspberry Pi OS (Debian trixie based). This document explains in
detail what each step does and why it is needed. For primary information on the steps themselves, also see
`docs/qtvirtualkeyboard_ja_build.md` (the Qt Virtual Keyboard build part).

## Assumed Environment

- Raspberry Pi 4 + Raspberry Pi OS 64-bit (equivalent to Debian trixie; assumes apt/systemd)
- Display: DFRobot DFR0550 (5-inch DSI, 800x480), drawn with `linuxfb` (direct drawing to `/dev/fb0`)
- ADALM-Pluto+ (DATV firmware) connected to the same Ethernet network
- Run as a user who can use `sudo`, such as `pi` (the script runs `sudo` in front of individual commands, so the script
  itself does not need to be started as root)

## Requirements (Prerequisites)

For `install.sh` to complete successfully when run as a normal user, all of the following must be in place.

**Required**

1. **Raspberry Pi OS 64-bit (aarch64)** — the script hard-codes `/usr/lib/aarch64-linux-gnu/` as the destination for
   replacing the Qt libraries, so it does not work on the 32-bit (armhf) OS.
2. **`git` installed beforehand** — needed to clone the repository (the pi4 `install.sh` does not install git
   automatically). If it is missing, run `sudo apt-get install -y git` first.
3. **Internet access** — both GitHub (cloning Qt Virtual Keyboard, gr-dvbs2rx and the libraries for Langstone) and the
   Debian apt mirrors must be reachable.
4. **Interactive execution with sudo** — `sudo` is called many times for apt/tee/systemctl, etc., so it assumes a tty
   that can answer password prompts (no problem over SSH as long as there is an interactive tty).
5. **The `patch` command available** — used to apply the dark theme patch in 3/9.

The repository is public, so no GitHub authentication is needed (to clone via SSH, use `install_ssh.sh`).

**Time and resources**

6. The Japanese input build (when `SKIP_JA_KEYBOARD=1` is not specified), the gr-dvbs2rx build and the Langstone
   V2Modify build (including LimeSuite and libiio) each take from a few minutes to tens of minutes, so the network and
   power must not be cut off during them.

**Not required**

- The Pluto+ device does not need to be on the network at the time of running (this only installs software; it is
  needed separately for actual operation).
- A USB camera and audio devices are also not needed at installation time.

## How to Run

```sh
git clone https://github.com/kazushinjo/Shonan_lite-PI4.git
cd Shonan_lite-PI4
./pi4/scripts/install.sh          # clone/pull via HTTPS (default)
./pi4/scripts/install_ssh.sh      # clone/pull via SSH (if your SSH key is registered on GitHub)
```

- `install_ssh.sh` is a thin wrapper that only sets `REPO_URL` to `git@github.com:kazushinjo/Shonan_lite-PI4.git` and
  then calls `install.sh`; all other processing is exactly the same.
- By default the install directory is **the clone the script lives in** (`~/Shonan_lite-PI4` in the example above).
  The services also run `pi4/gui` directly inside this clone.

The behavior can be changed with environment variables.

| Variable | Default | Effect |
| --- | --- | --- |
| `REPO_URL` | `https://github.com/kazushinjo/Shonan_lite-PI4.git` | Where to clone from when the install directory has no source |
| `SHONAN_INSTALL_DIR` | The clone the script lives in | Install directory |
| `QTVK_BUILD_DIR` | `/tmp/qtvirtualkeyboard-src` | Working directory for building Qt Virtual Keyboard |
| `GR_DVBS2RX_BUILD_DIR` | `$HOME/gr-dvbs2rx` | Working directory for building gr-dvbs2rx |
| `LANGSTONE_INSTALL_DIR` | `$HOME/Langstone` | Where Langstone V2Modify is placed |
| `SKIP_JA_KEYBOARD` | `0` | Set to `1` to skip the whole Japanese input build (3/9) |
| `SKIP_GNURADIO_BUILD` | `0` | Set to `1` to skip the whole GNU Radio/gr-dvbs2rx build for RX (4/9) (the receive function will not work) |
| `SKIP_LANGSTONE_BUILD` | `0` | Set to `1` to skip the Langstone V2Modify build (5/9) and the creation of `langstone.service` (Langstone on the Home screen will not work) |

Because `set -euo pipefail` is at the top, the script stops immediately when any command fails (it does not continue in
a half-finished state).

---

## Preparation: Installing Raspberry Pi OS

Raspberry Pi OS must be installed beforehand on the Pi 4 on which `install.sh` will be run (this installation itself is
outside the scope of `install.sh`).

### What you need

- A Raspberry Pi 4
- A microSD card or NVMe SSD (the Pi 4's boot storage)
- A PC for writing (Windows/Mac/Linux) and a microSD card reader, etc.
- Raspberry Pi Imager (the official writing tool, available from https://www.raspberrypi.com/software/)

### Steps

1. Start Raspberry Pi Imager on the PC.
2. Under "Choose Device", select **Raspberry Pi 4**.
3. Under "Choose OS", select **Raspberry Pi OS (64-bit)** (★the 32-bit version does not work; see "Requirements
   (Prerequisites)"). Always choose one whose OS name shows "64-bit" (both 32-bit and 64-bit may appear in the list).
4. Under "Choose Storage", select the microSD/NVMe to write to.
5. Open the gear icon (advanced options) and pre-configure the following so that you can connect via SSH and run
   `install.sh` right after the first boot.
   - Hostname
   - Username and password
   - Wi-Fi (not needed if using wired LAN only)
   - Enable SSH (public-key or password authentication)
6. Run "Write" and wait for it to finish.
7. Attach the microSD/NVMe to the Pi 4 and power it on. The first boot takes a few minutes.
8. Check that you can connect from the PC with `ssh <username>@<hostname>.local` (or the IP address assigned to the
   Pi 4).

The following steps (display settings check to 9/9) are run on the Pi 4, which you can now connect to via SSH.

## Checking the Display Settings (DFRobot DFR0550)

With the default `/boot/firmware/config.txt` of the 2026-09 Raspberry Pi OS (`dtoverlay=vc4-kms-v3d`,
`display_auto_detect=1`, `disable_fw_kms_setup=1`), panel initialization on the KMS side (backlight and touch I2C) times
out on the DFR0550, and neither `/dev/fb0` nor the touch (`raspberrypi-ts`) can be used (confirmed on the device).
Moreover, putting the heavy build load on it in this state made the device reboot and corrupted packages being written
(libcairo2, etc.).

Therefore, it first comments out these three lines and adds `dtparam=i2c_arm=on` if missing, aligning the settings to
use the firmware's legacy DSI display (BCM2708 FB 800x480). **If it changes the settings, it shows "reboot the Pi 4 and
run this script again" and exits**, so run `sudo reboot` and then the same command again (the second time nothing
changes, so it proceeds to 1/9).

## 1/9 Getting the Source

```sh
if [ -d "$INSTALL_DIR/.git" ]; then
  git -C "$INSTALL_DIR" pull --ff-only
elif [ -f "$INSTALL_DIR/pi4/gui/main.py" ]; then
  echo "Using the locally transferred source: $INSTALL_DIR"
else
  git clone "$REPO_URL" "$INSTALL_DIR"
fi
```

- If the install directory is a git clone, it is updated with `git pull --ff-only`. `--ff-only` stops with an error
  when a fast-forward is not possible (e.g. there are local commits), a safety measure to avoid unintentionally
  overwriting or merging local changes.
- If there is no `.git` but `pi4/gui/main.py` exists, it is used as is as source transferred with scp, etc.
- Otherwise it clones fresh from `REPO_URL`.

## 2/9 Runtime Dependency Packages

Installs, with `apt`, the set of Debian packages needed to run the GUI itself (`pi4/gui/main.py`).

| Package | Purpose |
| --- | --- |
| `git`, `curl` | Used for getting the source and HTTP communication |
| `python3-pyqt5` | Qt bindings for the GUI |
| `python3-pyqt5.qtquick` | `QQuickWidget` (used to embed the on-screen keyboard) |
| `python3-pyqt5.sip` | Internal dependency of PyQt5 |
| `python3-pil` | Pillow. Used to composite the callsign/note overlay onto the camera video |
| `ffmpeg` | All video encoding (with the Pi 4's built-in H.264 hardware encoder `h264_v4l2m2m`), multiplexing, overlay compositing and decoding of received video |
| `v4l-utils` | Checking the USB camera's resolution and format (`v4l2-ctl`) |
| `alsa-utils` | Listing audio devices and adjusting volume (`aplay`/`arecord`/`amixer`) |
| `sshpass` | Used to SSH into the Pluto+ with a password to reboot it and write its settings file |
| `fonts-droid-fallback` | Font for drawing Japanese glyphs in the overlay (DroidSansFallbackFull) |
| `fonts-dejavu-core` | Font for drawing alphanumeric glyphs in the overlay (DejaVuSans-Bold) |
| `qtvirtualkeyboard-plugin`, `qml-module-qtquick-virtualkeyboard` | The on-screen keyboard itself (apt version; replaced with the Japanese-capable version in 3/9) |
| `qml-module-qt-labs-folderlistmodel`, `qml-module-qtquick-window2`, `qml-module-qtquick-layouts`, `qml-module-qtquick-controls2`, `qml-module-qtquick2` | Auxiliary modules the on-screen keyboard's QML implementation depends on (if missing, loading the keyboard panel's QML fails) |

★2/9 always runs even with `SKIP_JA_KEYBOARD=1` (the English keyboard itself works with the apt version installed here).

## 3/9 Building Qt Virtual Keyboard with Japanese Input (OpenWnn)

With `SKIP_JA_KEYBOARD=1`, this whole block is skipped; it only shows the message "only the English layout is available"
and proceeds to 4/9.

### Why it must be built from source

The `qtvirtualkeyboard-plugin` distributed via apt by Debian (Raspberry Pi OS) does not include a Japanese input engine
(the engines confirmed on the device were only Hangul, Hunspell (Western languages) and Thai). Even the OSS version of
Qt Virtual Keyboard can include OpenWnn (an open-source kana-kanji conversion engine from Android, Apache license) in
the build, but the Debian package build does not enable it. Therefore the official Qt source is fetched, built
ourselves with `CONFIG+=openwnn`, and the apt version's files are replaced.

### Installing additional development packages for the build

```sh
sudo apt-get install -y \
  qtbase5-dev qtbase5-private-dev qtdeclarative5-dev qtdeclarative5-private-dev \
  qtquickcontrols2-5-dev qt5-qmake build-essential libqt5svg5-dev
```

`libqt5svg5-dev` is especially important. The top-level `.pro` file of Qt Virtual Keyboard declares
`requires(qtHaveModule(svg))`, and if this is not satisfied the whole build silently does nothing **without even an
error message** (`qmake` only prints `Some of the required modules (qtHaveModule(svg)) are not available. Skipped.`, and
the following `make` finishes successfully in an instant). We got stuck on this once on the device, so do not remove
it from the package list.

### Matching the Qt version

```sh
QT_VERSION="$(qmake -query QT_VERSION)"
QT_TAG="v${QT_VERSION}-lts-lgpl"
```

The Qt installed on the Pi 4 (`libQt5Core`, etc.) and the Qt Virtual Keyboard build must be **exactly the same version
at the ABI level**. If the versions differ, it crashes at run time or does not even start. Therefore, instead of a
hard-coded tag, the device's Qt version is obtained dynamically with `qmake -query QT_VERSION`, and the corresponding
`v<version>-lts-lgpl` tag (the naming convention for the LTS/LGPL-license branches of the official Qt repository) is
cloned.

### Applying the dark theme patch

```sh
STYLE_PATCH="$INSTALL_DIR/pi4/docs/patches/qtvirtualkeyboard_style_dark_language_popup.patch"
if [ -f "$STYLE_PATCH" ]; then
  patch -p1 -d "$QTVK_BUILD_DIR" < "$STYLE_PATCH"
fi
```

The language-switching popup that appears when tapping the globe icon on Qt Virtual Keyboard's on-screen keyboard
(by default it lists as many entries as the fallback layouts included in the build, such as British English / American
English / Japanese / Korean / Thai; the list actually shown in the app is narrowed down to three, English GB/US and
Japanese, by `pi4/gui/qml/InputPanelWrapper.qml`; see "Narrowing down the language list" below) is **green text on a
white background** by default, which does not match the dark theme (white text on black) of the whole shonan-pi4 app.
`pi4/docs/patches/qtvirtualkeyboard_style_dark_language_popup.patch` is a diff that rewrites `languageListDelegate`
(text color), `languageListBackground` (background color) and the highlight color of the selected item in Qt Virtual
Keyboard's `src/virtualkeyboard/content/styles/default/style.qml` to the same dark colors as the app. If the `patch`
command is not available or the patch file cannot be found, it is simply skipped and the build continues with the
default colors (not a fatal problem).

★Even when this patch file does not exist in the repository (= e.g. an old commit just cloned locally), it is safely
skipped thanks to the `if [ -f ... ]` guard.

### The build itself

```sh
(
  cd "$QTVK_BUILD_DIR"
  qmake CONFIG+=openwnn CONFIG+=lang-ja_JP CONFIG+=lang-en_GB CONFIG+=lang-en_US \
    qtvirtualkeyboard.pro
  make -j"$(nproc)"
)
```

- `CONFIG+=openwnn`: include the Japanese kana-kanji conversion engine (OpenWnn). By the rule
  `contains(CONFIG, lang-ja.*)|lang-all: CONFIG += openwnn` in `src/config.pri`, specifying `lang-ja_JP` enables it
  implicitly as well, but it is specified explicitly to make the intent clear.
- `CONFIG+=lang-ja_JP CONFIG+=lang-en_GB CONFIG+=lang-en_US`: narrow down the keyboard layouts included in the build
  (if not specified, all languages = `lang-all` are built by default, which takes extra time and resources).
- The subshell `( ... )` keeps the change of the script's current directory by `cd` from leaking outside this step.
- `make -j"$(nproc)"` builds in parallel with as many jobs as there are cores. On the Pi 4 (4 cores), including the
  examples, it takes roughly 10–20 minutes (based on actual measurements on the device).

★Japanese does not become the keyboard's default selected language (it is English right after startup); this is known
behavior, detailed under "pitfalls" in `docs/qtvirtualkeyboard_ja_build.md`. Switch manually with the globe icon.

### Narrowing down the language list

Even with `CONFIG+=lang-ja_JP CONFIG+=lang-en_GB CONFIG+=lang-en_US`, the build still includes fallback layouts for
Korean and Thai, and these two appear unnecessarily in the globe icon's language popup. They cannot be excluded by the
build settings, so the displayed languages are narrowed down at run time with the
`VirtualKeyboardSettings.activeLocales` property of `QtQuick.VirtualKeyboard.Settings`.

`pi4/gui/main.py` loads `pi4/gui/qml/InputPanelWrapper.qml` as the keyboard panel instead of the plain
`InputPanel.qml`. This QML inherits `InputPanel` and sets
`VirtualKeyboardSettings.activeLocales = ["en_GB", "en_US", "ja_JP"]` in `Component.onCompleted`, limiting the language
popup list to three: English GB/US and Japanese.

★This narrowing is not done by `install.sh` but by the code in the repository (`pi4/gui/qml/InputPanelWrapper.qml` and
`pi4/gui/main.py`). Since `install.sh` only does `git clone`/`pull` of the repository, it is reflected as is (no change to
`install.sh` itself is needed).

### Backing up and replacing the apt version's files

```sh
BACKUP_DIR="$HOME/qtvk_backup_$(date +%Y%m%d%H%M%S)"
...
sudo cp -a "$QT5_LIB_DIR"/libQt5VirtualKeyboard.so* "$BACKUP_DIR/" 2>/dev/null || true
...
```

Before replacing, the existing files installed by apt in 2/9 are copied to `~/qtvk_backup_<timestamp>/`. The `|| true`
keeps `set -e` from stopping the whole script in the (normally impossible) case that a source file does not exist.

The following are replaced:

1. `libQt5VirtualKeyboard.so.<version>` — the core shared library itself (the keyboard's layout and style QML are also
   compiled into it as resources)
2. `qml/QtQuick/VirtualKeyboard/libqtquickvirtualkeyboardplugin.so` and `plugins.qmltypes` — the QML module
   `QtQuick.VirtualKeyboard` itself
3. `qml/QtQuick/VirtualKeyboard/Settings/libqtquickvirtualkeyboardsettingsplugin.so` —
   `QtQuick.VirtualKeyboard.Settings` (for settings such as the active locales)
4. `qml/QtQuick/VirtualKeyboard/Styles/libqtquickvirtualkeyboardstylesplugin.so` — `QtQuick.VirtualKeyboard.Styles`
5. `plugins/platforminputcontexts/libqtvirtualkeyboardplugin.so` — the platform input context plugin itself, loaded with
   `QT_IM_MODULE=qtvirtualkeyboard`
6. `plugins/virtualkeyboard/libqtvirtualkeyboard_openwnn.so` — the Japanese input engine itself, the main purpose of
   this step (it does not exist in the apt version, so it is newly placed after `mkdir -p`)

Finally, `sudo ldconfig` updates the shared library cache so that the change takes effect immediately.

### To restore (roll back)

```sh
BK=~/qtvk_backup_<timestamp>   # replace with the actual directory name
sudo cp -a $BK/libQt5VirtualKeyboard.so* /usr/lib/aarch64-linux-gnu/
sudo cp -a $BK/VirtualKeyboard_qml/. /usr/lib/aarch64-linux-gnu/qt5/qml/QtQuick/VirtualKeyboard/
sudo cp -a $BK/libqtvirtualkeyboardplugin.so /usr/lib/aarch64-linux-gnu/qt5/plugins/platforminputcontexts/
sudo cp -a $BK/virtualkeyboard_plugins/. /usr/lib/aarch64-linux-gnu/qt5/plugins/virtualkeyboard/
sudo ldconfig
sudo systemctl restart shonan-gui.service
```

Alternatively, simply `sudo apt-get install --reinstall qtvirtualkeyboard-plugin qml-module-qtquick-virtualkeyboard
libqt5virtualkeyboard5` also returns to the apt version (in this case Japanese input will no longer be available).

## 4/9 Installing GNU Radio + gr-dvbs2rx for Receive (RX)

With `SKIP_GNURADIO_BUILD=1`, this whole block is skipped (the receive function will not work).

```sh
sudo apt-get install -y gnuradio gnuradio-dev cmake pkg-config
git clone https://github.com/igorauad/gr-dvbs2rx.git "$GR_DVBS2RX_BUILD_DIR"   # pull --ff-only if it already exists
git -C "$GR_DVBS2RX_BUILD_DIR" submodule update --init --recursive
git -C "$GR_DVBS2RX_BUILD_DIR" apply "$RX_PATCH"   # only if it exists and is not yet applied
cmake .. -DCMAKE_BUILD_TYPE=Release && make -j"$(nproc)" && sudo make install
```

`pi4/rx/shonan_rx.py` needs `from gnuradio import gr, analog, blocks, iio, dvbs2rx` at run time. `gnuradio` itself
(including `libgnuradio-iio*` with the gr-iio functions) can be installed with Debian's apt, but `dvbs2rx` (the OOT
module for DVB-S2 demodulation, [igorauad/gr-dvbs2rx](https://github.com/igorauad/gr-dvbs2rx)) is not distributed via apt,
so its source is fetched, built and installed. The fixes made for stable reception on the device are applied as
`pi4/docs/patches/gr-dvbs2rx_pi4_bringup.patch` (automatically skipped if already applied). Also see
`pi4/third_party/rpi-dvbs2-receiver-gui/` (imported from kazushinjo/rpi-dvbs2-receiver-gui) as a reference implementation.

★Without this, reception fails at RX start with `ModuleNotFoundError: No module named 'gnuradio'` or
`ImportError: cannot import name 'dvbs2rx'` (found and fixed during a fresh installation on the device).

## 5/9 Building Langstone V2Modify (SDR Transceiver)

With `SKIP_LANGSTONE_BUILD=1`, this whole block is skipped.

- It copies `pi4/third_party/Langstone-V2Modify/` (kazushinjo/Langstone-V2Modify with modifications for integration with
  Shonan_Lite) to `~/Langstone` and runs the bundled installer for Pi 4/DFR0550/ADALM-Pluto, `install_dfr0550.sh`, with
  `SHONAN_INTEGRATION=1`.
- `install_dfr0550.sh` installs the apt packages needed for the build, wiringPi, LimeSuite and libiio 0.25, enables I2C
  and sets up sudoers entries for some commands Langstone uses (`/etc/sudoers.d/langstone`), then builds `GUI_Pluto`.
  With `SHONAN_INTEGRATION=1`, it does not set Langstone to start automatically at login (appending to `.bashrc`);
  starting is handled by the boot menu and `langstone.service`.
- ★`~/Langstone` is overwritten as a whole. Langstone's settings file (`~/Langstone/Langstone_Pluto.conf`) is written by
  Langstone when it exits and is not included in the repository, so it is not overwritten.

## 6/9 Suppressing the Boot Console Output

With a plain Raspberry Pi OS, the kernel boot log and the login prompt appear on the device's LCD when the Pi 4 boots
(confirmed on the device). It does the following three things (a reboot is needed for them to take effect).

- Disables `getty@tty1`.
- Adds `quiet loglevel=3 logo.nologo vt.global_cursor_default=0` to `/boot/firmware/cmdline.txt` (does nothing if
  `quiet` is already there).
- Changes `console=tty1` in `cmdline.txt` to `console=tty3`. With KMS disabled (`linuxfb`), systemd's boot log was
  written directly to the framebuffer and overlapped the Shonan_Lite/Langstone screens (confirmed on the device), so
  nothing is output to the device's LCD (tty1).

## 7/9 Allowing Reboot/Shutdown/App Switching Without a Password

"Power Off" on the Home screen, choosing an app in the boot menu, and switching between Shonan_Lite and Langstone run
`sudo` from systemd services without a TTY. With the standard sudo settings a password is requested, the PAM
conversation fails (`pam_unix: conversation failed`) and the action is not performed — a bug confirmed on the device.
Therefore a rule is written to `/etc/sudoers.d/shonan-pi4-reboot` that lets the running user execute only the following
commands without a password, and it is validated with `visudo -c`.

- `/sbin/reboot`, `/sbin/shutdown`
- `/bin/systemctl start --no-block shonan-gui.service`
- `/bin/systemctl start --no-block langstone.service`
- `/bin/systemctl stop shonan-display-off.service`

## 8/9 Suppressing the Under-Voltage Warning (Lightning Icon)

```sh
if [ -f "$BOOT_CONFIG" ] && ! grep -q '^avoid_warnings=' "$BOOT_CONFIG"; then
  echo "avoid_warnings=1" | sudo tee -a "$BOOT_CONFIG" > /dev/null
fi
```

Adds `avoid_warnings=1` to `/boot/firmware/config.txt` if it is not there (does nothing if it already is; idempotent).
`sudo reboot` is needed for it to take effect. This only suppresses the on-screen lightning icon and log warnings; it does
not solve the actual under-voltage itself (the permanent fix is to use a genuine 27 W USB-C PD power supply and a
good-quality USB cable; `vcgencmd get_throttled` shows whether throttling actually occurs).

## 9/9 Registering the systemd Services

The following four services are created in `/etc/systemd/system/` (`sudo tee` is used because the redirection `>`
itself does not inherit `sudo`'s privileges).

| Service | Contents | Auto start |
| --- | --- | --- |
| `shonan-boot-menu.service` | Full-screen menu at boot for choosing "Shonan_Lite / Langstone" (`pi4/gui/boot_menu.py`). Starts the chosen service with `systemctl start` | Enabled |
| `shonan-gui.service` | Shonan_Lite itself (`pi4/gui/main.py`). Restarted after 3 seconds if it exits abnormally | Disabled (started from the boot menu) |
| `langstone.service` | Langstone V2Modify (`~/Langstone/run_pluto`). Not created with `SKIP_LANGSTONE_BUILD=1` | Disabled (started from the boot menu or by switching) |
| `shonan-display-off.service` | Turns off the DSI display and backlight at shutdown (the DSI LCD keeps showing the last frame after the OS stops) | Enabled |

- `shonan-gui.service` and `shonan-boot-menu.service` run with `QT_QPA_PLATFORM=linuxfb:fb=/dev/fb0:nocursor` (direct
  drawing to `/dev/fb0`). With eglfs (KMS/DRM), panel initialization on the DFR0550 DSI panel could conflict depending on
  the combination with Langstone (legacy framebuffer), and it failed to start due to backlight initialization timeouts,
  garbled colors, `no screens available`, etc. (confirmed on the device).
- `shonan-gui.service`, `langstone.service` and `shonan-boot-menu.service` are mutually exclusive through `Conflicts=`.
  Only one process can use the display, so starting any one of them with `systemctl start` automatically stops the
  others. Apps are switched through this mechanism, without rebooting the Pi 4.
- `ConditionPathExists` checks for the marker file `~/.pi4_boot_mode_langstone`, and the side that should not start does
  nothing and is treated as a successful exit (skipped).
- `langstone.service` embeds the actual value in `Environment=HOME=...` and starts `run_pluto` via `/bin/bash` (because
  the first line of `run_pluto` is not a shebang; confirmed on the device).
- Finally, it runs `daemon-reload`, `stop`s a running `shonan-gui.service`/`langstone.service`, and then `enable`s and
  `restart`s `shonan-boot-menu.service` and `shonan-display-off.service`.

## Display After Completion

It shows the state of `shonan-boot-menu.service` and then the following notes.

1. **Assumption of passwordless sudo/ssh**: the "System Date & Time" setting on the settings screen (`timedatectl`) and
   screenshots of the device's LCD, etc., assume that `sudo` can be run without a password. 7/9 allows only the commands
   above, and no other changes are made to `/etc/sudoers.d/` (`/etc/sudoers.d/langstone` for Langstone is created by
   `install_dfr0550.sh` in 5/9). If needed, the operator decides and configures it individually.
2. **Default language for Japanese input**: the on-screen keyboard starts with the English layout, and can be switched to
   Japanese (romaji input) by tapping the globe icon (it does not switch automatically; known behavior).
3. **avoid_warnings**: if it was newly added in 8/9, `sudo reboot` is needed for it to take effect.

## Related Documents

- `pi4/docs/qtvirtualkeyboard_ja_build.md` — primary information on the 3/9 build steps and details of the pitfalls
  encountered on the device
- `pi4/docs/patches/qtvirtualkeyboard_style_dark_language_popup.patch` — the dark theme patch applied in 3/9 (unified
  diff format, equivalent to `git diff`)
- `pi4/docs/patches/gr-dvbs2rx_pi4_bringup.patch` — the RX stabilization patch applied in 4/9
- `pi4/third_party/Langstone-V2Modify/install_dfr0550.sh` — the Langstone V2Modify installer run in 5/9
- `pi4/docs/shonan_pi4_operation_manual.docx` / `pi4/gui/manual_content.py` — how to operate the GUI itself (how to use
  it after installation)
- `pi4/third_party/rpi-dvbs2-receiver-gui/` — reference implementation of the GNU Radio/gr-dvbs2rx receive flowgraph
  (imported from kazushinjo/rpi-dvbs2-receiver-gui)

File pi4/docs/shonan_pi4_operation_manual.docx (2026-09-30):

Shonan_Lite for RasPI4

DVB-S2 DATV送受信システム 操作説明書
Operation Manual

対象 / Target: Pi 4 + 無印ADALM-Pluto (plain ADALM-Pluto)
推奨運用 / Recommended: 500 kS/s / QPSK / FEC 3/5
版 / Edition: 2026-09-30
日本語編のあとに英語編(English)があります。 / The English edition follows the Japanese edition.

# 目次 / Contents

1. 重要
- Plutoのユーザー名・パスワード
2. 1. 画面構成
- このアプリでできること
- ホーム画面
- 画面の共通操作
3. 2. 起動と終了
- 起動前の接続
- 電源投入後の動作
- アプリの終了
- 安全上の注意
4. 3. 共通設定
- 設定を始める前に
- 1. 設定画面：基本設定
- ESP32 W5500なしでのPA/LNA制御
- 2. 周波数画面
- 10GHz帯とLNB
- 3. シンボルレート画面
- 4. 変調方式画面
- 5. 誤り訂正(FEC)画面
- 6. 映像ソース画面
- 7. 出力設定画面
- 8. RXゲイン画面
- 9. TX出力画面
- 10. オンデバイス復調と通常運用
- 設定完了の確認
5. 4. プリセット
- プリセットの適用
- 新規登録
- 既存プリセットの変更
6. 5. 送信
- 送信開始
- 送信中の確認
- 送信停止
7. 6. 受信
- 受信開始
- 受信中の確認
- 映像が表示されない場合
- 受信停止
8. 7. 通常運用の手順
- 相手局と接続する手順
- RSSI測定(相手局の周波数を探す)
- 送信運用
- 受信運用
- 送受信運用
9. 8. 送受信・RFループバック試験
- 試験前の設定値
- 設定の意味
- 試験手順
- 合格の目安
10. 9. Langstone
- 起動と切替
- 基本操作
- Shonan_Liteへ戻る
- 10GHz受信(衛星をタップ)
11. 10. Help・診断・アプリ再起動
- Help
- 機器試験
- アプリ再起動
12. 11. トラブルシューティング
- 送信できない
- 受信できない
- SOF・パケット数が増えない
- Plutoに接続できない
- 映像が黒い
13. 12. Plutoと接続情報
- Pluto設定の確認
- Pi4
- 試験の標準値
14. 13. 注意事項と検証範囲
- 検証について
- RF安全
- クレジット
15. English
- Important
- 1. Overview
- 2. Startup and shutdown
- 3. Operating parameters
- 4. Presets
- 5. Transmit
- 6. Receive
- 7. Normal operation
- 8. TX/RX and RF loopback test
- 9. Langstone
- 10. Help, diagnostics, and restart
- 11. Troubleshooting
- 12. Pluto and connection information
- 13. Notes and validation scope

# クイックスタート

本書に記載の内容は、実際に動作させて動作確認した内容です。ただし、まだバグが内在している可能性はあります。

16. Plutoを起動し、Pi 4とEthernet接続する。PlutoのURIは設定画面で指定する。
17. 設定画面で、周波数、シンボルレート、変調方式、FEC、映像ソース、出力、RXゲイン、TX出力を順に設定する。
18. 送信側と受信側の周波数437.000 MHz、500 kS/s、QPSK、FEC 3/5を一致させる。
19. 送信画面で映像を確認して送信開始を押し、受信画面で受信開始を押す。
20. 受信ではLOCK、SOF、パケット数、エラー数、映像表示を順に確認する。
21. 終了時は受信停止を先に押し、その後に送信停止を押す。RF試験の手順は後半の試験章を参照する。

# 重要

## Plutoのユーザー名・パスワード

Plutoのユーザー名(root)とパスワード(analog)は、デフォルト値のまま変更しないでください。本アプリとLangstoneは、SSHでPlutoにログインしてリブートや設定ファイルの書き込みを行っています(アプリ起動時・アプリ再起動・機器試験・送受信開始時・Langstone終了時)。変更するとPlutoをリブートできなくなります。

# 1. 画面構成


図: 1. 画面構成（Pi4画面）


図: 1. 画面構成（Pi4画面）

## このアプリでできること

Shonan_Liteは、無印ADALM-Plutoを使ってDVB-S2 DATVの送信・受信・RFループバック試験を行うアプリです。ホーム画面から各機能へ移動します。

## ホーム画面

「送信」「受信」「周波数」「RSSI測定」「シンボルレート」「誤り訂正(FEC)」「変調方式」「映像ソース」「出力設定」「RXゲイン」「TX出力」「設定」「機器試験」「ヘルプ」「アプリ再起動」「電源オフ」「Langstone」「プリセット」「Pluto電源」を表示します。各カードはアイコン・日本語名・英語名を同じ配置で表示します(英語表示では英語名のみ)。周波数カードには現在の周波数を表示します。背景右側の衛星をタップすると、Langstoneを10GHz受信用のバンドで開きます(9章参照)。

## 画面の共通操作

カードまたはボタンをタップして画面を開きます。各画面の「ホームへ戻る」でホーム画面へ戻ります。送受信中に設定を変更する場合は、先に送信・受信を停止してください。

# 2. 起動と終了


図: 2. 起動と終了（Pi4画面）

## 起動前の接続

Plutoを起動し、Pi 4とEthernet接続します。PlutoのIPアドレスは環境に合わせて設定します。TXとRXを試験する場合は、TXとRXを直結せず、必ず外部アッテネータを用意します。

## 電源投入後の動作

電源投入後は起動メニューでShonan_LiteまたはLangstoneを選択します。Shonan_Lite起動時は、ホーム画面表示前にPlutoの再起動、オフライン確認、再接続確認、設定再適用を行います。Pluto確認に20秒以上かかる場合は確認をスキップしてホーム画面を表示します。

## アプリの終了

送信中・受信中の場合は、先にそれぞれの停止ボタンを押します。停止を確認してからホーム画面の「電源オフ」を使用します。

## 安全上の注意

送信出力を受信入力へ直結しないでください。RFループバックでは TX → 40 dB以上の外部アッテネータ → RX の順に接続します。

# 3. 共通設定


図: 3. 共通設定（Pi4画面）


図: 3. 共通設定（Pi4画面）

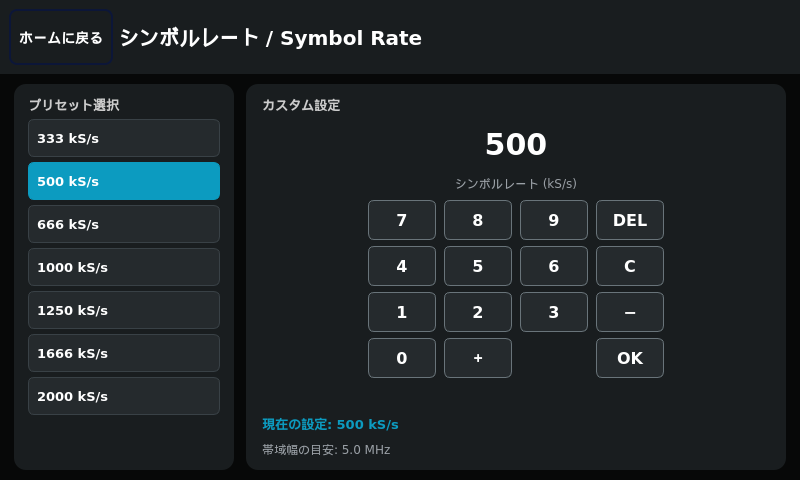
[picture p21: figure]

図: 3. 共通設定（Pi4画面）

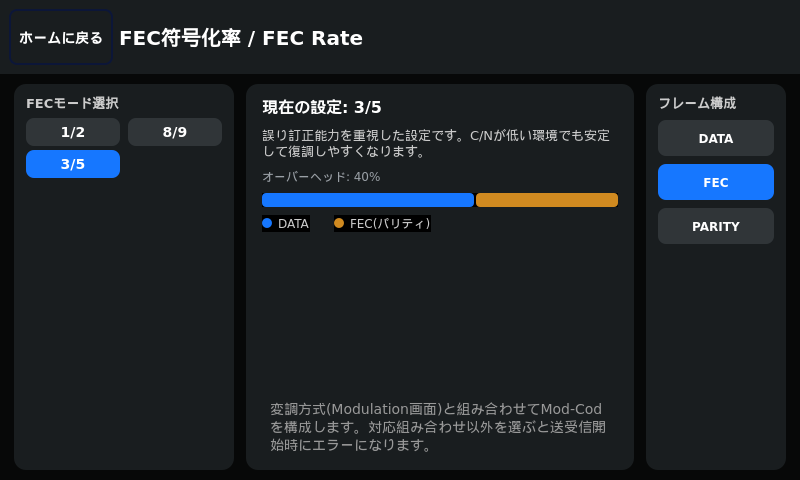
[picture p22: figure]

図: 3. 共通設定（Pi4画面）


図: 3. 共通設定（Pi4画面）


図: 3. 共通設定（Pi4画面）


図: 3. 共通設定（Pi4画面）

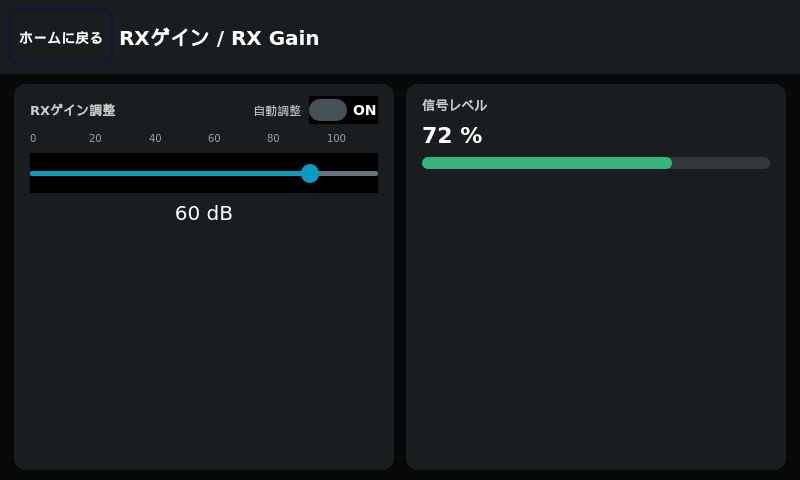
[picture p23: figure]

図: 3. 共通設定（Pi4画面）

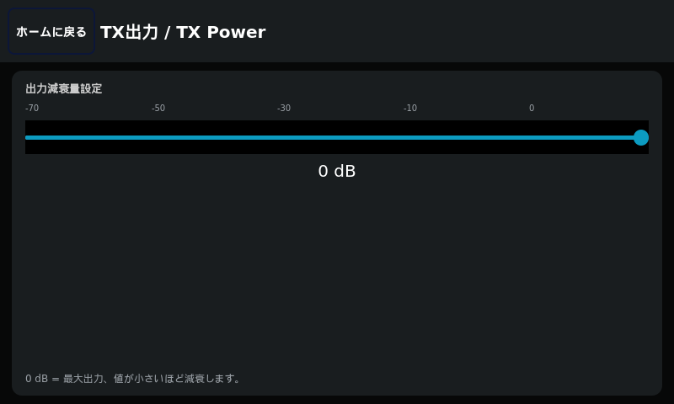
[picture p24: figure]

図: 3. 共通設定（Pi4画面）

## 設定を始める前に

相手局と先に次の共通値を決めます。周波数437.000 MHz、シンボルレート500 kS/s、変調QPSK、FEC 3/5、パイロットONを標準例とします。送信側と受信側でこの5項目が一致しないと受信できません。

## 1. 設定画面：基本設定

ホーム画面で「設定」をタップします。表示言語(日本語/English)を選び、送信先(Pluto Tx)にPlutoのIPアドレスを入力します(UDP-TSポートは8282固定)。PA_Power/PTTコントローラ(ESP32)を使う場合は「ESP32 W5500を使用する」をONにしてIPアドレスを入力します(OFFまたは空欄なら連携しません。OFFにしてもIPアドレスは保持されます)。使用する場合、送信開始/終了に連動してPTTを、アプリ起動/終了に連動して12V電源を自動でON/OFFします。入力後にキーボードを閉じ、入力欄からフォーカスが外れたことを確認します。PlutoのIPアドレスを相手局と混同しないようにしてください。

## ESP32 W5500なしでのPA/LNA制御

ESP32 W5500(PA_Power/PTTコントローラ)を使わなくても、RasPI4からのPTT ON信号でPA・LNAの送受信切替を制御できます。送信中はPi 4のGPIO21(40番ピン、GNDは39番ピン)がHIGH(3.3V)、受信中はLOWになります。Shonan_Liteの送信とLangstoneの送信(Langstone標準のTx Output)のどちらでも同じピンに出力されます。GPIO21は電流を取れないため、トランジスタやリレードライバ等でバッファしてからPA・LNA(同軸リレー等)を駆動してください。12V電源のON/OFFとホーム画面の「Pluto電源」カードはESP32 W5500が必要です。

## 2. 周波数画面

ホーム画面で「周波数」をタップします。相手局と決めた周波数を入力し、「OK」または確定ボタンをタップします。ホーム画面の周波数カードが同じ値に変わったことを確認します。標準例は437.000 MHzです。

## 10GHz帯とLNB

周波数画面のバンド選択で「10GHz帯」を押すと、LNBを使用するかどうかを確認します。「はい」を選ぶと表示周波数は10.2365 GHz(10,236,500 kHz)になり、受信時はLNB局部発振9750 MHzを引いた486.5 MHzでPlutoが受信します(受信画面・RSSI測定も同じ)。LNB使用中は受信専用で、送信はできません。「いいえ」を選ぶと従来どおり10,180 MHz(LNBなし)です。「10GHz帯」を押し直すと選び直せ、他のバンドを選ぶとLNBは解除されます。LNBへの電源供給(同軸経由のバイアスT)は別途用意してください。

## 3. シンボルレート画面

ホーム画面で「シンボルレート」をタップし、500 kS/sを選択します。確定後、カード表示が500 kS/sになったことを確認します。相手局と異なる値にしないでください。

## 4. 変調方式画面

ホーム画面で「変調方式」をタップし、相手局と同じ方式を選択します。初めて接続する場合はQPSKを使用します。選択肢はQPSK・8PSKです。選択後にホームへ戻り、変調方式カードを確認します。

## 5. 誤り訂正(FEC)画面

ホーム画面で「誤り訂正」をタップし、相手局と同じFECを選択します。標準例は3/5です。選択肢は選択中の変調方式で実際に動作する組み合わせのみに絞り込まれます(QPSK: 1/2・3/5・8/9、8PSK: 3/5・8/9)。FECだけを変更しても変調方式が合わなければ受信できません。

## 6. 映像ソース画面

ホーム画面で「映像ソース」をタップします。実映像を送る場合は「カメラ」(USBカメラを接続してから選択)、映像系を先に確認する場合は「テストパターン」を選びます。「ファイル選択」では静止画(png/jpg/jpeg/bmp)を選び、反復して送信します。右側のプレビューで選んだ映像を確認できます。カメラは1280x720で取り込みます(対応していればMJPEG・30fps。1280x720に対応しないカメラは既定の解像度)。暗い場所ではカメラが露出を優先してフレームレートを下げることがあります。カメラ選択時は「撮影」ボタンでカメラ映像をJPG(1920x1080)として撮影でき、ホームフォルダのPictures/Shonan_Liteに保存されます。保存した画像は「ファイル選択」(このフォルダから開きます)で送信画像として選べます。送信中は撮影できません。画面下部の「コールサイン」「備考」(任意)に入力した文字は映像に焼き込まれ、日時も右下に表示されます。各入力欄の右で文字サイズ(コールサイン36〜256px、備考16〜64px)と文字色(白・黄・赤・緑・青・水色・橙・黒)を選べます。カメラ映像と画像ファイルに適用され、テストパターンには適用されません。送信映像はフルHD(1920x1080)固定で、縦横比が異なる映像は黒帯を付けて収めます。送信は映像のみで、音声は送りません(音声なし)。

## 7. 出力設定画面

ホーム画面で「出力設定」をタップします。「Pluto URI」にPlutoのIPアドレスを入力するか、「自動検出」を押して同一LAN上のPlutoを探します(見つかると入力欄へ自動で反映します。見つからない場合は電源とLAN配線を確認してください)。「送信先ポート(Pluto側固定)」は8282固定で変更できません。「受信TSポート」「ステータスポート」は必要に応じて変更します。

## 8. RXゲイン画面

ホーム画面で「RXゲイン」をタップします。自動調整する場合はAGCをON、相手局と固定条件で試験する場合はAGCをOFFにして手動ゲインを設定します。標準試験値は60 dBです。

## 9. TX出力画面

ホーム画面で「TX出力」をタップし、接続するアンテナまたはアッテネータに合わせて出力減衰量を設定します。0 dBが最大出力で、値を小さく(-側に)するほど出力が下がります。設定値は送信画面の「出力減衰」にdBで表示されます。RFループバックでは必ず40 dB以上の外部アッテネータを使用します。

## 10. オンデバイス復調と通常運用

ホーム画面の「設定」でオンデバイス復調をONにするとTX/RX同時動作も自動的にONになります。ONにする操作をすると、PlutoのTX端子とRX端子の間に40 dB以上の外部アッテネータが入っているかを確認するポップアップが表示され、「はい」を選んだ場合のみONになります。受信開始時にTXは自動開始しません。通常の別々の送信・受信ではOFFにします。OFFではTXとRXは排他的に動作します。

## 設定完了の確認

ホーム画面に戻り、周波数、シンボルレート、FEC、変調方式、映像ソース、RXゲイン、TX出力のカードを順番に読み上げて確認します。相手局にも同じ値を読み上げてもらい、1項目ずつ一致を確認してから送信・受信を開始します。

# 4. プリセット

## プリセットの適用

ホーム画面の「プリセット」を開き、プリセット1～5から選択します。プリセット1は初期状態でRFループバック（437.000 MHz / 500 kS/s / QPSK / FEC 3/5）です。選択すると設定値を一括適用し、Plutoにも反映します。送信・受信は自動開始しません。

## 新規登録

各設定画面で周波数、シンボルレート、変調、FEC、映像ソースなどを手動設定します。プリセット画面へ戻り、登録したい行の「登録/変更」を押します。キーボードからプリセット名を入力して保存します。

## 既存プリセットの変更

設定値を手動で変更した後、変更したいプリセット行の「登録/変更」を押すと、現在の設定値で上書きできます。削除は「削除」ボタンを押します。登録・変更・削除は送受信停止中に行ってください。

# 5. 送信


図: 5. 送信（Pi4画面）

## 送信開始

ホーム画面の「送信」は送信画面を開くだけです。送信画面で映像プレビューと設定値を確認し、「送信開始」を押します。受信も動作中の場合は、アプリがRX停止 → TX設定反映 → TX開始 → RX再開の順で切り替えます。

## 送信中の確認

送信画面で映像プレビューと、周波数・シンボルレート・変調方式・FEC・出力減衰(dB)を確認します。「パケット数」はPlutoへ送ったUDPパケットの累計、「フレーム数」は符号化した映像フレーム数で、送信中は増え続けます(送信停止で0に戻ります)。「接続」が「接続中」ならPlutoへ送出できています。送信開始を押しても受信は自動開始しません。

## 送信停止

送信終了時は「送信停止」を押します。停止表示を確認してから設定や配線を変更します。

# 6. 受信


図: 6. 受信（Pi4画面）

## 受信開始

送信側と周波数、シンボルレート、変調方式、FEC、パイロットを一致させます。ホーム画面の「受信」を開き、「受信開始」を押します。

## 受信中の確認

LOCK、SOF、パケット数、ビットレート、エラー数を確認します。パケット数とSOFが増え、エラーが増えないことを確認してから映像表示を確認します。

## 映像が表示されない場合

まずLOCKとパケット数を確認します。RF受信が正常なら、映像ソース、H.264映像、送信開始状態、テストパターン設定を確認します。画面が黒い場合は、周波数、シンボルレート、FEC、変調方式、配線も再確認します。

## 受信停止

受信終了時は「受信停止」を押します。送信も行っている場合は、受信停止後に送信停止を押します。

# 7. 通常運用の手順


図: 7. 通常運用の手順（Pi4画面）

## 相手局と接続する手順

1) 相手局と共通値を決めます。2) 3章の各設定画面をPi 4側で順番に設定します。3) ホーム画面のカードを相手局と照合します。4) 相手局が送信する場合は、先に受信開始を押して待機します。5) 自局が送信する場合は、送信開始を押してから相手局へ送信開始を連絡します。6) 受信画面でLOCK、SOF、パケット数、エラー数、映像を確認します。

## RSSI測定(相手局の周波数を探す)

ホーム画面の「RSSI測定」で、中心周波数(周波数画面の値)の前後を±5/±10/±20MHzの範囲でスキャンし、受信レベル(RSSI)をグラフ表示します。ステップ(kHz)はテンキーで入力します。「検索開始」でスキャンし、「最も強い周波数」を表示します(RSSIは値が小さいほど強い信号です)。「検索方法」は「連続」(検索停止まで繰り返す)と「1回」から選び、RXゲイン(AGC/手動)も画面右側で調整できます。設定画面の「オンデバイス復調」がOFF(通常運用)のときは送信せず、相手局の電波を測ります(相手局が送信していなければグラフは平らです)。ONのときはテスト用の機能で、自局も映像ソースに関係なくテストパターンで自動送信し、自分の信号を測ります(必ず40 dB以上のアッテネータを介してください)。

## 送信運用

1) 3章の設定を完了します。2) ホーム画面で送信を開きます。3) 映像プレビューを確認します。4) 送信開始を押します。5) 送信中表示と映像を確認します。6) 終了時は送信停止を押します。

## 受信運用

1) 送信側と全パラメータを一致させます。2) ホーム画面で受信を開きます。3) 受信開始を押します。4) LOCK、SOF、パケット数、エラー数、映像を確認します。5) 終了時は受信停止を押します。

## 送受信運用

1) 送信を開始します。2) 受信を開始します。3) 受信画面でLOCK、SOF、パケット数、エラー数、映像を確認します。4) 終了時は受信停止、送信停止の順に停止します。

# 8. 送受信・RFループバック試験

## 試験前の設定値

周波数: 437.000 MHz、シンボルレート: 500 kS/s、変調方式: QPSK、FEC: 3/5、ロールオフ: 0.35、フレーム: Long Frame、RXゲイン: 60 dB、映像ソース: テストパターン、パイロット: ON、オンデバイス復調: ON、TX/RX同時動作: ON、RFループバック: ON。

## 設定の意味

オンデバイス復調は同一PlutoでTX/RX同時動作を許可する設定です。RFループバックは、送信RFをアッテネータ経由で受信RFへ戻す試験経路の設定です。オンデバイス復調ONだけではRF配線試験になりません。

## 試験手順

1) TX → 40 dB以上のアッテネータ → RXを接続、2) プリセット1または試験パラメータを適用、3) 送信画面で「送信開始」、4) 3～5秒待つ、5) 受信画面で「受信開始」、6) LOCK、SOF、パケット数、エラー数、映像表示を確認します。

## 合格の目安

LOCKが成立し、SOFとパケット数が継続して増加し、エラーが増えず、テストパターンが表示されればRFループバック試験は成功です。

# 9. Langstone

## 起動と切替

起動メニューまたはホーム画面のLangstoneカードを選択します。LangstoneとShonan_Liteは同じPlutoを使用するため、同時には起動しません。

## 基本操作

Langstone画面下部のBAND、MODE、SET、BEACON、PTTなどをタップして操作します。

## Shonan_Liteへ戻る

LangstoneのSET画面で「GOTO SHONAN_LITE」を押します。Langstoneを停止してShonan_Liteへ切り替えます。切替時間を短くするため、切替のときはPlutoを再起動しません(Langstoneが止めた送信LOは元に戻します)。電源投入時・アプリ再起動などでは従来どおりPlutoを再起動します。

## 10GHz受信(衛星をタップ)

ホーム画面の背景右側の衛星をタップすると、Langstoneを10GHz受信用のバンド(表示10236.5 MHz、Pluto受信486.5 MHz、LNB局部発振9750 MHz)で開きます。このバンドは受信専用で、PTTボタンは灰色の「RX ONLY」表示になり、PTT・CWキー・ビーコンのいずれでも送信しません。普通のLangstoneカードで開くと、衛星の前に使っていたバンドに戻ります。

# 10. Help・診断・アプリ再起動

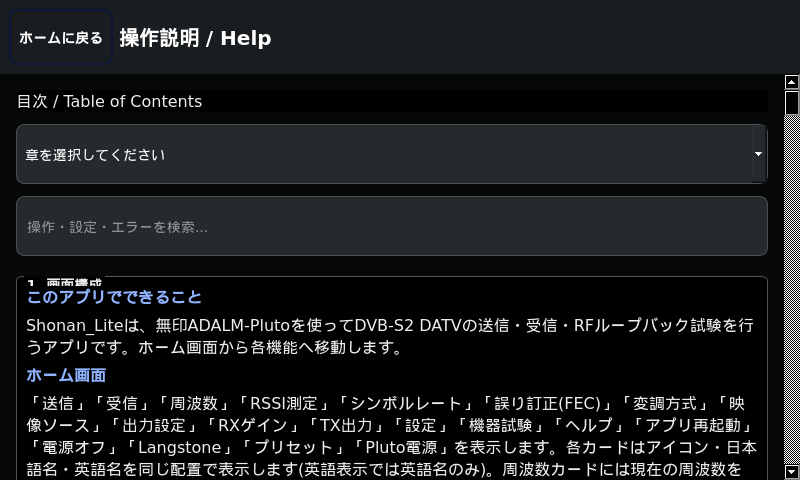
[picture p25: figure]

図: 10. Help・診断・アプリ再起動（Pi4画面）


図: 10. Help・診断・アプリ再起動（Pi4画面）

## Help

Helpでは章を選択して操作手順を確認できます。プリセットの登録・適用方法、送受信手順、RFループバック試験手順は本書と同じ順番で表示されます。

## 機器試験

機器試験の「全体試験」は、送信・受信を停止してから押します。最初にPlutoを再起動して接続を確認し、次の4項目を順に試験して結果を表に表示します: Pluto SDR接続(IIOコンテキスト接続)、送信テスト(8秒間の送出継続)、受信テスト(8秒間の受信継続)、温度センサー(Pi 4のCPU温度)。最後に「TX: 正常 / RX: 正常」のように総合結果を表示します。試験の実行中は、押したボタンが赤で表示されます。終了時は送信・受信とも自動で停止します。「カメラ＋音声診断」はUSBカメラの映像と内蔵マイクの音声を実際に取り込んで送出できるかを確認します。診断結果はアンテナ性能やRF環境を保証するものではありません。

## アプリ再起動

送受信を停止してから「アプリ再起動」を使用します。Plutoを再起動し、オフライン確認、Web UI・IIOの復旧確認、保存済み設定の再適用を順番に行います。確認できない場合はホーム画面を表示します。

# 11. トラブルシューティング

## 送信できない

送信画面へ移動しただけでは送信されません。「送信開始」を押し、Pluto IP、周波数、映像ソース、TX出力を確認します。

## 受信できない

送信側と受信側の周波数、シンボルレート、変調方式、FEC、パイロットを一致させ、TXが送信中であること、アッテネータと配線、RXゲインを確認します。

## SOF・パケット数が増えない

Plutoの設定値、周波数、シンボルレート、変調方式、FEC、パイロット、RXゲイン、TX出力、アッテネータを確認します。

## Plutoに接続できない

Plutoの電源、IPアドレス、Ethernet接続を確認します。アプリ再起動またはPluto再起動後は、設定再適用が完了してから送受信を開始します。

## 映像が黒い

LOCKとパケット数が正常なら、テストパターンへ切り替えて映像系を切り分けます。送信側のH.264エンコードと受信側の映像デコードが動作していることを確認します。

# 12. Plutoと接続情報

## Pluto設定の確認

Pluto無印でF5OEO製DATVカスタムファームウェアを使用します。周波数、変調、シンボルレート、FEC、パイロット、フレーム、ロールオフがアプリ設定と一致していることを確認します。

## Pi4

ホスト名: DVB-S2-PI4。IPアドレスとSSH接続先は使用環境に合わせて設定します。

## 試験の標準値

周波数437.000 MHz、500 kS/s、QPSK、FEC 3/5、テストパターン、RXゲイン60 dBを標準試験値とします。

# 13. 注意事項と検証範囲

## 検証について

本書の内容は実機で動作確認した内容に基づきます。ただし、使用するPluto、RF配線、電源、ネットワーク、映像機器の組み合わせによっては、まだバグが内在している可能性があります。

## RF安全

送信機と受信機の接続条件を確認し、指定値以上のアッテネータを使用してください。

## クレジット

受信部の方式考案・原システム設計: 山崎慎慈氏(JE1BTA)。受信部安定化調査・本アプリ開発: 真城和一。

# English

## Important

### Pluto username and password

Keep the Pluto's username (root) and password (analog) at their default values. This app and Langstone log in to the Pluto via SSH to reboot it and write its settings file (at app start, app restart, equipment test, TX/RX start and Langstone exit). If they are changed, the Pluto cannot be rebooted.

## 1. Overview

### What this app does

Shonan_Lite is a DVB-S2 DATV transmitter, receiver, and RF loopback test tool for ADALM-Pluto.

### Home screen

Use the cards for Transmit, Receive, Frequency, RSSI Measurement, Symbol Rate, FEC, Modulation, Video Source, Stream Output, RX Gain, TX Power, Settings, Diagnostic, Help, App Restart, Power Off, Langstone, Presets, and Pluto Power. Every card shows its icon and name in the same layout; the Frequency card also shows the current frequency. Tapping the satellite on the right of the background opens Langstone on the band for 10 GHz reception (see chapter 9).

### Common operation

Tap a card or button to open it. Use Back to Home to return. Stop transmit and receive before changing operating parameters.

## 2. Startup and shutdown

### Before startup

Power on Pluto and connect it to Pi 4 over Ethernet. Set the Pluto address for your network.

### Startup sequence

The startup menu selects Shonan_Lite or Langstone. Shonan_Lite restarts Pluto, checks the connection, and reapplies settings before showing Home. If confirmation takes over 20 seconds, it continues to Home.

### Shutdown

Stop transmit and receive, then use Power Off from Home.

### RF safety

Never connect TX directly to RX. Use TX → external attenuator of at least 40 dB → RX.

## 3. Operating parameters

### Standard example

Frequency 437.000 MHz, symbol rate 500 kS/s, QPSK, FEC 3/5, and Pilot ON. TX and RX must use the same values.

### Settings

Open Settings, choose the display language (Japanese/English), and enter the Pluto IP address under Destination (Pluto Tx); the UDP-TS port is fixed at 8282. To use the PA_Power/PTT controller (ESP32), turn on "Use ESP32 W5500" and enter its IP address (the link is disabled when it is OFF or the address is empty; the IP address is kept even when OFF). When used, PTT follows TX start/stop and the 12 V power is switched ON/OFF automatically at app start/exit.

### PA/LNA control without ESP32 W5500

Even without the ESP32 W5500 (PA_Power/PTT controller), the PA and LNA can be switched between TX and RX by the PTT ON signal from the RasPI4. GPIO21 on the Pi 4 (pin 40; GND on pin 39) is HIGH (3.3 V) while transmitting and LOW while receiving, both for Shonan_Lite and for Langstone (Langstone's standard Tx Output). GPIO21 cannot supply current, so buffer it with a transistor, relay driver or similar before driving the PA and LNA. Switching the 12 V power ON/OFF and the Pluto Power card still require the ESP32 W5500.

### Frequency

Enter the agreed frequency and press OK. Confirm that the Home card shows the same value.

### 10 GHz band and LNB

Pressing 10GHz Band in the band selection on the Frequency screen asks whether to use an LNB. Choosing Yes sets the displayed frequency to 10.2365 GHz (10,236,500 kHz), and when receiving the Pluto receives at 486.5 MHz, i.e. minus the 9750 MHz LNB local oscillator (the same applies to the RX screen and RSSI measurement). While the LNB is in use it is receive only and transmitting is not possible. Choosing No gives 10,180 MHz (no LNB) as before. Press 10GHz Band again to choose again; selecting another band cancels the LNB. Provide power for the LNB (bias-T over the coax) separately.

### Symbol Rate

Choose or enter the agreed symbol rate. The standard example is 500 kS/s.

### Modulation and FEC

Select the same modulation and FEC as the other station. Modulation is QPSK or 8PSK, and the FEC choices are limited to working combinations (QPSK: 1/2, 3/5, 8/9; 8PSK: 3/5, 8/9). QPSK and FEC 3/5 are the standard example.

### Video Source

Choose Camera for live video, Test Pattern for diagnostics, or File to send a still image (png/jpg/jpeg/bmp); the preview on the right shows the selected source. The camera is captured at 1280x720 (MJPEG at 30 fps when supported; cameras without 1280x720 use their default size), and in dim light the camera may lower its frame rate. With Camera, Capture saves a 1920x1080 JPG to Pictures/Shonan_Lite (not while transmitting), and File opens that folder. The Callsign and Note fields are burned into camera and image video with the date and time; choose their font size and color next to each field. The transmitted video is fixed at Full HD (1920x1080) with black bars when the aspect ratio differs. Only video is transmitted (No Audio).

### Stream Output

Enter the Pluto IP address in Pluto URI, or press Detect to find the Pluto on the same LAN automatically. The destination port is fixed at 8282 on the Pluto. Change the RX TS port and Status port only if needed.

### RX Gain and TX Power

Use AGC or set RX gain manually. The standard test gain is 60 dB. TX Power sets the output attenuation: 0 dB is maximum output, and the value is shown as TX Attenuation (dB) on the Transmit screen.

### On-device demodulation

ON automatically enables TX/RX simultaneous operation, but starting RX does not automatically start TX. Turning it ON first asks you to confirm that an attenuator of 40 dB or more is connected between the Pluto TX and RX ports. OFF keeps TX and RX exclusive.

### Final check

Read every Home card and compare frequency, symbol rate, modulation, FEC, source, RX gain, and TX power with the other station.

## 4. Presets

### Apply

Open Presets and select one of five entries. The values are applied to the app and Pluto; transmit and receive do not start automatically.

### Register or edit

Set values manually in the individual screens, return to Presets, press Save / Edit, and enter the preset name with the keyboard.

### Delete

Press Delete on the selected row. Edit and delete while transmit and receive are stopped.

## 5. Transmit

### Start

Open Transmit, check the preview and parameters, and press Start Transmit. Opening the screen does not start transmission.

### While transmitting

Check the preview, frequency, symbol rate, modulation, FEC, and TX attenuation (dB). Packets is the total number of UDP packets sent to the Pluto and Frames is the number of encoded video frames; both keep increasing while transmitting and return to 0 when stopped. Connection shows Connected while the stream is being sent to the Pluto.

### Stop

Press Stop Transmit before changing settings or wiring.

## 6. Receive

### Start

Match frequency, symbol rate, modulation, FEC, and Pilot with the transmitting station, then press Start Receive.

### Check

LOCK, SOF, packets, bitrate, errors, and the video image should be monitored. SOF and packets must continue to increase.

### No video

First check LOCK and packets, then check video source, H.264 encoding, transmitter state, test pattern, and wiring.

### Stop

Press Stop Receive when finished.

## 7. Normal operation

### Station-to-station procedure

Agree on all parameters, configure each screen in order, compare Home cards, start RX or TX as required, and verify LOCK, SOF, packets, errors, and video.

### RSSI Measurement

RSSI Measurement scans ±5/±10/±20 MHz around the center frequency (from the Frequency screen) and graphs the received level; a smaller RSSI value means a stronger signal. Choose Repeat or Once, and adjust RX gain (AGC/manual) on the right. With on-device demodulation OFF (normal operation) it does not transmit and measures the other station. With it ON (a test feature) your station also transmits the test pattern automatically and measures its own signal; always use an attenuator of 40 dB or more.

### TX/RX switching

When TX starts while RX is active, the app performs RX stop → TX configuration → TX start → RX restart.

## 8. TX/RX and RF loopback test

### Test values

437.000 MHz, 500 kS/s, QPSK, FEC 3/5, Long Frame, roll-off 0.35, RX gain 60 dB, Test Pattern, Pilot ON, on-device demodulation ON, and RF loopback ON.

### Important distinction

On-device demodulation permits simultaneous TX/RX in one Pluto. RF loopback describes the physical attenuated RF path; it is not enabled by on-device demodulation alone.

### Pass criteria

LOCK is established, SOF and packet counts increase continuously, errors remain stable, and the test pattern is displayed.

## 9. Langstone

### Switching

Select Langstone from the startup menu or Home. Only one application uses Pluto at a time.

### Return

Use GOTO SHONAN_LITE in Langstone to stop it and return to Shonan_Lite. To shorten the switching time, the Pluto is not rebooted when switching (the TX LO that Langstone powered down is restored). The Pluto is still rebooted at power-up and app restart.

### 10 GHz reception (tap the satellite)

Tapping the satellite on the right of the Home screen background opens Langstone on the band for 10 GHz reception (displayed 10236.5 MHz, Pluto RX 486.5 MHz, LNB local oscillator 9750 MHz). This band is receive only: the PTT button is shown grayed out as RX ONLY, and it does not transmit from PTT, the CW key or the beacon. Opening Langstone from the normal Langstone card returns to the band used before the satellite.

## 10. Help, diagnostics, and restart

### Help

Use the table of contents or search field to find an operating procedure.

### Diagnostic

Stop TX and RX, then press Full Test. It restarts the Pluto and checks four items in order: Pluto SDR connection (IIO context), TX test (8 s of continuous output), RX test (8 s of continuous reception), and temperature sensor (Pi 4 CPU temperature), then shows an overall TX/RX result. While a test is running, the pressed button is shown in red. TX and RX are stopped automatically at the end. Camera + Audio Diagnostic checks that the USB camera video and its microphone audio can actually be captured and sent. The result does not guarantee antenna or RF performance.

### App Restart

Stop TX/RX first. App Restart restarts Pluto, checks recovery, and reapplies saved settings in order.

## 11. Troubleshooting

### Cannot transmit

Check Pluto IP, frequency, video source, TX power, and that Start Transmit was pressed.

### Cannot receive

Match all five RF parameters and Pilot, confirm TX is active, and check attenuator, wiring, and RX gain.

### SOF does not increase

Recheck Pluto settings, frequency, symbol rate, modulation, FEC, Pilot, RX gain, TX power, and attenuation.

### Cannot connect to Pluto

Check power, IP address, and Ethernet. Wait for configuration reapplication after a restart.

## 12. Pluto and connection information

### Firmware

Use the F5OEO DATV custom firmware on an ADALM-Pluto. Pluto settings must match the app.

### Pi 4

Host name: DVB-S2-PI4. Configure the IP address and SSH destination for the operating environment.

### Standard test

437.000 MHz, 500 kS/s, QPSK, FEC 3/5, Test Pattern, and RX gain 60 dB.

## 13. Notes and validation scope

### Validation

This guide is based on actual equipment checks. Bugs may still exist depending on Pluto, RF wiring, power, network, and video equipment combinations.

### Credit

Receiver method and original system design: Shinji Yamazaki (JE1BTA). Receiver stabilization and application development: Kazuichi Shinjo.

# 付録A 表示メッセージ早見表 / Appendix A: Messages

表示 | 意味・対処
IIO preflight OK | RX DMAから4,096 byte取得成功。受信処理を開始できます。
IIO preflight FAILED | RF NO LOCKではなくIIO/RX DMA異常。Pluto再起動と接続確認を行います。
Sync: Locked | DVB-S2同期成功。TS packets増加も確認します。
Lost / Rate | TS continuity推定ロス数 / 直近の受信ビットレート。Lostの急増はTS欠落を示します。
Video Waiting | SPS/PPSと最初のIDRを待っています。
Video Ready (IDR) | SPS/PPS後のIDRを検出し、映像表示可能です。

受信部の方式考案・受信部原システム設計: 山崎慎慈氏(JE1BTA) rpi-dvbs2-receiver-guiの設計に基づきます 受信部安定化調査修正・再捕捉修正・本アプリ開発: 真城和一

Shonan_Lite for RasPI4 操作説明書 / Operation Manual

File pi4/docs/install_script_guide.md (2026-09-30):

# pi4/scripts/install.sh 詳細ガイド

英語版 / English version: [`install_script_guide_en.md`](install_script_guide_en.md)

`install.sh`は、まっさらなRaspberry Pi OS(Debian trixie系)にshonan-pi4一式
(Shonan_Lite本体・受信用GNU Radio・Langstone V2Modify・起動メニュー)を
セットアップするための単一スクリプトである。本ドキュメントは各処理の内容と、
なぜその手順が必要かを詳しく説明する。手順そのものの一次情報は
`docs/qtvirtualkeyboard_ja_build.md`(Qt Virtual Keyboardのビルド部分)も参照。

## 想定環境

- Raspberry Pi 4 + Raspberry Pi OS 64bit(Debian trixie相当、apt/systemd前提)
- 表示はDFRobot DFR0550(5インチDSI、800x480)。`linuxfb`(`/dev/fb0`直描画)で表示する
- ADALM-Pluto+(DATVファームウェア)がEthernet同一ネットワークに接続済み
- `pi`ユーザーなど、`sudo`が使えるユーザーで実行する(スクリプト自体は`sudo`を
  個別コマンドの前に付けて実行するので、スクリプト自体をrootで起動する必要はない)

## 実行条件(前提条件)

一般ユーザーが実行して`install.sh`が正常完了するには、以下がすべて揃っている必要がある。

**必須**

1. **Raspberry Pi OS 64bit(aarch64)であること** — スクリプト内でQtライブラリの
   差し替え先を`/usr/lib/aarch64-linux-gnu/`に決め打ちしているため、32bit
   (armhf)版OSでは動作しない。
2. **`git`が事前にインストール済み** — リポジトリをcloneするのに必要(pi4版の
   `install.sh`はgitを自動導入しない)。無ければ先に`sudo apt-get install -y git`を実行する。
3. **インターネット到達性** — GitHub(Qt Virtual Keyboard・gr-dvbs2rx・Langstone用の
   各ライブラリのclone)とDebianのapt配布ミラー両方に到達できること。
4. **sudoが使える対話的な実行** — apt/tee/systemctl等で何度も`sudo`を呼ぶため、
   パスワード入力を求められた際に応答できるttyでの実行が前提(SSH経由でも
   対話ttyがあれば問題ない)。
5. **`patch`コマンドが使えること** — 3/9のダークテーマパッチ適用に使用する。

リポジトリはpublicのため、GitHubの認証は不要(SSHでcloneしたい場合は`install_ssh.sh`を使う)。

**時間・リソース**

6. 日本語入力ビルド(`SKIP_JA_KEYBOARD=1`未指定時)・gr-dvbs2rxビルド・Langstone V2Modifyの
   ビルド(LimeSuite・libiioを含む)はそれぞれ数分〜数十分かかるため、途中で通信・電源が
   切れない環境であること。

**不要な条件**

- 実行時点でPluto+実機がネットワーク上にある必要はない(あくまでソフトウェア
  導入のみ。実運用時に別途必要)。
- USBカメラ・オーディオ機器も導入時点では不要。

## 実行方法

```sh
git clone https://github.com/kazushinjo/Shonan_lite-PI4.git
cd Shonan_lite-PI4
./pi4/scripts/install.sh          # HTTPSでclone/pull(既定)
./pi4/scripts/install_ssh.sh      # SSHでclone/pull(GitHubにSSH鍵を登録済みの場合)
```

- `install_ssh.sh`は`REPO_URL`を`git@github.com:kazushinjo/Shonan_lite-PI4.git`に
  設定してから`install.sh`を呼び出すだけの薄いラッパーで、それ以外の処理は完全に同一である。
- インストール先は、既定では**スクリプトが置かれているクローン自身**(上の例なら
  `~/Shonan_lite-PI4`)。サービスもこのクローン内の`pi4/gui`を直接起動する。

環境変数で挙動を変更できる。

| 変数 | 既定値 | 効果 |
| --- | --- | --- |
| `REPO_URL` | `https://github.com/kazushinjo/Shonan_lite-PI4.git` | インストール先にソースが無い場合のclone元 |
| `SHONAN_INSTALL_DIR` | スクリプトが置かれたクローン | インストール先ディレクトリ |
| `QTVK_BUILD_DIR` | `/tmp/qtvirtualkeyboard-src` | Qt Virtual Keyboardのビルド作業ディレクトリ |
| `GR_DVBS2RX_BUILD_DIR` | `$HOME/gr-dvbs2rx` | gr-dvbs2rxのビルド作業ディレクトリ |
| `LANGSTONE_INSTALL_DIR` | `$HOME/Langstone` | Langstone V2Modifyの配置先 |
| `SKIP_JA_KEYBOARD` | `0` | `1`にすると日本語入力ビルド(3/9)を丸ごとスキップする |
| `SKIP_GNURADIO_BUILD` | `0` | `1`にすると受信(RX)用GNU Radio/gr-dvbs2rxビルド(4/9)を丸ごとスキップする(受信機能は動作しなくなる) |
| `SKIP_LANGSTONE_BUILD` | `0` | `1`にするとLangstone V2Modifyのビルド(5/9)と`langstone.service`の作成をスキップする(Home画面のLangstoneは動作しなくなる) |

`set -euo pipefail`が先頭にあるため、いずれかのコマンドが失敗した時点でスクリプトは
即座に停止する(中途半端な状態のまま先へ進まない)。

---

## 事前準備: Raspberry Pi OSのインストール

`install.sh`実行対象のPi4に、あらかじめRaspberry Pi OSをインストールしておく
必要がある(このインストール自体は`install.sh`の範囲外)。

### 準備するもの

- Raspberry Pi 4本体
- microSDカードまたはNVMe SSD(Pi4の起動ストレージ)
- 書き込み用PC(Windows/Mac/Linuxいずれか)とmicroSDカードリーダー等
- Raspberry Pi Imager(公式書き込みツール、
  https://www.raspberrypi.com/software/ から入手)

### 手順

1. PCでRaspberry Pi Imagerを起動する。
2. 「デバイスを選択」で **Raspberry Pi 4** を選ぶ。
3. 「OSを選択」で **Raspberry Pi OS (64-bit)** を選ぶ(★32bit版は不可。
   「実行条件(前提条件)」参照)。OS名に必ず"64-bit"と表示されているものを
   選ぶこと(一覧に32bit/64bit両方が並ぶ場合があるため)。
4. 「ストレージを選択」で書き込み先のmicroSD/NVMeを選ぶ。
5. 歯車アイコン(詳細設定)を開き、以下を事前設定しておくと、初回起動後すぐ
   SSH接続して`install.sh`を実行できる。
   - ホスト名
   - ユーザー名・パスワード
   - Wi-Fi(有線LANのみで運用する場合は不要)
   - SSHを有効化(公開鍵認証 or パスワード認証)
6. 「書き込む」を実行し、完了を待つ。
7. microSD/NVMeをPi4に取り付け、電源を入れる。初回起動は数分かかる。
8. PCから`ssh <ユーザー名>@<ホスト名>.local`(またはPi4に割り当てられた
   IPアドレス)で接続できることを確認する。

以降の手順(表示設定の確認〜9/9)は、この時点でSSH接続できているPi4上で実行する。

## 表示設定の確認(DFRobot DFR0550)

2026-09版Raspberry Pi OSの既定の`/boot/firmware/config.txt`(`dtoverlay=vc4-kms-v3d`・
`display_auto_detect=1`・`disable_fw_kms_setup=1`)のままだと、DFR0550ではKMS側のパネル
初期化(バックライト・タッチのI2C)がタイムアウトし、`/dev/fb0`もタッチ(`raspberrypi-ts`)も
使えないことを実機で確認した。さらにこの状態でビルドの高負荷をかけると実機が再起動し、
書き込み途中のパッケージ(libcairo2等)が破損した。

そのため最初に、これら3行をコメントアウトし、`dtparam=i2c_arm=on`が無ければ追記して、
firmwareのレガシーDSI表示(BCM2708 FB 800x480)を使う設定にそろえる。**設定を変更した場合は
「Pi4を再起動してから再実行してください」と表示して終了する**ので、`sudo reboot`後に
同じコマンドを再実行する(2回目は変更が無いので1/9へ進む)。

## 1/9 ソース取得

```sh
if [ -d "$INSTALL_DIR/.git" ]; then
  git -C "$INSTALL_DIR" pull --ff-only
elif [ -f "$INSTALL_DIR/pi4/gui/main.py" ]; then
  echo "ローカル転送済みソースを使用します: $INSTALL_DIR"
else
  git clone "$REPO_URL" "$INSTALL_DIR"
fi
```

- インストール先がgitのクローンなら`git pull --ff-only`で最新化する。`--ff-only`は
  fast-forwardできない(ローカルに独自コミットがある等の)場合にエラーで止まり、
  意図せずローカルの変更を上書き・マージしてしまうことを防ぐ安全策。
- `.git`は無いが`pi4/gui/main.py`がある場合は、scp等で転送済みのソースとしてそのまま使う。
- どちらでもなければ`REPO_URL`から新規cloneする。

## 2/9 実行時依存パッケージ

GUI本体(`pi4/gui/main.py`)を動かすために必要な、Debianパッケージ一式を`apt`で
導入する。

| パッケージ | 用途 |
| --- | --- |
| `git`, `curl` | ソース取得・HTTP通信に使用 |
| `python3-pyqt5` | GUI本体のQtバインディング |
| `python3-pyqt5.qtquick` | `QQuickWidget`(オンスクリーンキーボードの埋め込みに使用) |
| `python3-pyqt5.sip` | PyQt5の内部依存 |
| `python3-pil` | Pillow。カメラ映像へのコールサイン・備考オーバーレイ合成に使用 |
| `ffmpeg` | 映像のエンコード(Pi 4内蔵のH.264ハードウェアエンコーダ`h264_v4l2m2m`)・多重化・オーバーレイ合成・受信映像デコード全般 |
| `v4l-utils` | USBカメラの解像度・フォーマット確認(`v4l2-ctl`) |
| `alsa-utils` | 音声デバイス列挙・音量調整(`aplay`/`arecord`/`amixer`) |
| `sshpass` | Plutoの再起動や設定ファイルの書き込みでPluto+へパスワード付きSSHするために使用 |
| `fonts-droid-fallback` | オーバーレイの日本語グリフ描画用フォント(DroidSansFallbackFull) |
| `fonts-dejavu-core` | オーバーレイの英数字グリフ描画用フォント(DejaVuSans-Bold) |
| `qtvirtualkeyboard-plugin`, `qml-module-qtquick-virtualkeyboard` | オンスクリーンキーボード本体(apt版。3/9で日本語対応版に差し替える) |
| `qml-module-qt-labs-folderlistmodel`, `qml-module-qtquick-window2`, `qml-module-qtquick-layouts`, `qml-module-qtquick-controls2`, `qml-module-qtquick2` | オンスクリーンキーボードのQML実装が依存する補助モジュール群(不足しているとキーボードパネルのQML読み込みに失敗する) |

★`SKIP_JA_KEYBOARD=1`でも2/9は必ず実行される(英語キーボード自体はここで
入るapt版で動作するため)。

## 3/9 日本語入力(OpenWnn)対応版Qt Virtual Keyboardのビルド

`SKIP_JA_KEYBOARD=1`の場合はこのブロック全体をスキップし、「英語配列のみ利用可」
というメッセージだけ表示して4/9へ進む。

### なぜソースからビルドする必要があるのか

Debian(Raspberry Pi OS)がapt配布している`qtvirtualkeyboard-plugin`には、
日本語入力エンジンが同梱されていない(実機で確認できたエンジンはHangul/
Hunspell(欧文系)/Thaiのみ)。Qt Virtual KeyboardはOSS版でもOpenWnn
(Android由来のオープンソースかな漢字変換エンジン、Apacheライセンス)を
ビルドに含めることができるが、Debianのパッケージビルドではこれが有効化
されていない。そのためQt公式ソースを取得し、`CONFIG+=openwnn`を指定して
自前でビルドし、apt版のファイルを差し替える。

### ビルド用開発パッケージの追加導入

```sh
sudo apt-get install -y \
  qtbase5-dev qtbase5-private-dev qtdeclarative5-dev qtdeclarative5-private-dev \
  qtquickcontrols2-5-dev qt5-qmake build-essential libqt5svg5-dev
```

`libqt5svg5-dev`が特に重要。Qt Virtual Keyboardのトップレベル`.pro`ファイルは
`requires(qtHaveModule(svg))`を宣言しており、これが満たされないと**エラーメッセージ
すら出さずに**ビルド全体が空振りする(`qmake`は`Some of the required modules
(qtHaveModule(svg)) are not available. Skipped.`とだけ出力し、続く`make`は
一瞬で正常終了してしまう)。実機で一度ハマった問題なので、パッケージリストから
外さないこと。

### Qtバージョンの一致

```sh
QT_VERSION="$(qmake -query QT_VERSION)"
QT_TAG="v${QT_VERSION}-lts-lgpl"
```

Pi4にインストール済みのQt本体(`libQt5Core`等)とQt Virtual Keyboardのビルドは
**ABIレベルで完全に一致するバージョン**でなければならない。バージョンがずれると
実行時にクラッシュする、または起動すらしない。そのため、決め打ちのタグではなく
`qmake -query QT_VERSION`で実機のQtバージョンを動的に取得し、対応する
`v<バージョン>-lts-lgpl`タグ(Qt公式リポジトリのLTS/LGPLライセンスブランチの
命名規則)でcloneする。

### ダークテーマパッチの適用

```sh
STYLE_PATCH="$INSTALL_DIR/pi4/docs/patches/qtvirtualkeyboard_style_dark_language_popup.patch"
if [ -f "$STYLE_PATCH" ]; then
  patch -p1 -d "$QTVK_BUILD_DIR" < "$STYLE_PATCH"
fi
```

Qt Virtual Keyboードのオンスクリーンキーボードで、globeアイコンをタップすると
出る言語切替ポップアップ(既定ではBritish English / American English / 日本語 /
한글 / ไทย等がビルドに含まれるフォールバックレイアウトの数だけ並ぶ。実際に
アプリで表示される一覧は`pi4/gui/qml/InputPanelWrapper.qml`で
English GB/US・日本語の3つに絞り込んでいる。後述「言語一覧の絞り込み」参照)は、
既定では**白背景+緑文字**で、shonan-pi4アプリ全体の黒背景+白文字のダーク
テーマと見た目が合わない。`pi4/docs/patches/
qtvirtualkeyboard_style_dark_language_popup.patch`は、Qt Virtual Keyboardの
`src/virtualkeyboard/content/styles/default/style.qml`内の
`languageListDelegate`(文字色)・`languageListBackground`(背景色)・選択中の
アイテムの強調色を、アプリと同じダーク配色に書き換える差分である。
`patch`コマンドが利用できない/パッチファイルが見当たらない場合は単にスキップし、
既定配色のままビルドを継続する(致命的な問題ではない)。

★このパッチファイルがリポジトリに存在しない状態(=手元でcloneしたばかりの
古いコミット等)でも、`if [ -f ... ]`のガードにより安全にスキップされる。

### ビルド本体

```sh
(
  cd "$QTVK_BUILD_DIR"
  qmake CONFIG+=openwnn CONFIG+=lang-ja_JP CONFIG+=lang-en_GB CONFIG+=lang-en_US \
    qtvirtualkeyboard.pro
  make -j"$(nproc)"
)
```

- `CONFIG+=openwnn`: 日本語かな漢字変換エンジン(OpenWnn)を含める。
  `src/config.pri`の`contains(CONFIG, lang-ja.*)|lang-all: CONFIG += openwnn`
  というルールにより、`lang-ja_JP`を指定すれば暗黙的にも有効化されるが、
  明示しておくことで意図を明確にしている。
- `CONFIG+=lang-ja_JP CONFIG+=lang-en_GB CONFIG+=lang-en_US`: ビルドに含める
  キーボード配列を絞り込む(指定しない場合は既定で全言語=`lang-all`が
  ビルドされ、時間もリソースも余分にかかる)。
- サブシェル`( ... )`で囲んでいるのは、`cd`によるスクリプトのカレント
  ディレクトリ変化を、この処理の外へ漏らさないため。
- `make -j"$(nproc)"`は搭載コア数ぶん並列ビルドする。Pi4(4コア)で
  examplesも含めて概ね10〜20分程度かかる(実機での実測ベース)。

★日本語がキーボードの既定選択言語にはならない(起動直後は英語)点は既知の
挙動で、`docs/qtvirtualkeyboard_ja_build.md`の「ハマりどころ」に詳細がある。
globeアイコンで手動切替が必要。

### 言語一覧の絞り込み

`CONFIG+=lang-ja_JP CONFIG+=lang-en_GB CONFIG+=lang-en_US`を指定しても、
ビルドには韓国語(한글)・タイ語(ไทย)向けのフォールバックレイアウトが
含まれてしまい、globeアイコンの言語切替ポップアップにこの2つが不要に
表示される。これはビルド設定では除外できないため、実行時に
`QtQuick.VirtualKeyboard.Settings`の`VirtualKeyboardSettings.activeLocales`
プロパティで表示対象を絞り込む。

`pi4/gui/main.py`は素の`InputPanel.qml`ではなく`pi4/gui/qml/
InputPanelWrapper.qml`をキーボードパネルとして読み込む。このQMLは
`InputPanel`を継承し、`Component.onCompleted`で
`VirtualKeyboardSettings.activeLocales = ["en_GB", "en_US", "ja_JP"]`を
設定することで、言語切替ポップアップの一覧をEnglish GB/US・日本語の3つに
限定する。

★この絞り込みは`install.sh`側の処理ではなく、リポジトリに含まれる
`pi4/gui/qml/InputPanelWrapper.qml`と`pi4/gui/main.py`のコード側の対応であり、
`install.sh`はリポジトリを`git clone`/`pull`するだけなのでそのまま反映される
(`install.sh`自体の変更は不要)。

### apt版ファイルのバックアップと差し替え

```sh
BACKUP_DIR="$HOME/qtvk_backup_$(date +%Y%m%d%H%M%S)"
...
sudo cp -a "$QT5_LIB_DIR"/libQt5VirtualKeyboard.so* "$BACKUP_DIR/" 2>/dev/null || true
...
```

差し替え前に、2/9でaptインストールされた既存ファイル一式を
`~/qtvk_backup_<タイムスタンプ>/`へコピーしておく。`|| true`が付いているのは、
(通常発生しないはずだが)コピー元ファイルが万一存在しない場合でも
`set -e`によってスクリプト全体が止まらないようにするため。

差し替え対象は次の5系統:

1. `libQt5VirtualKeyboard.so.<バージョン>` — コア共有ライブラリ本体
   (キーボードのレイアウト・スタイルQMLもリソースとしてここにコンパイルされている)
2. `qml/QtQuick/VirtualKeyboard/libqtquickvirtualkeyboardplugin.so`
   および`plugins.qmltypes` — QMLモジュール`QtQuick.VirtualKeyboard`本体
3. `qml/QtQuick/VirtualKeyboard/Settings/libqtquickvirtualkeyboardsettingsplugin.so`
   — `QtQuick.VirtualKeyboard.Settings`(アクティブロケール等の設定用)
4. `qml/QtQuick/VirtualKeyboard/Styles/libqtquickvirtualkeyboardstylesplugin.so`
   — `QtQuick.VirtualKeyboard.Styles`
5. `plugins/platforminputcontexts/libqtvirtualkeyboardplugin.so` —
   `QT_IM_MODULE=qtvirtualkeyboard`で読み込まれるプラットフォーム入力
   コンテキストプラグイン本体
6. `plugins/virtualkeyboard/libqtvirtualkeyboard_openwnn.so` — 今回の主目的である
   日本語入力エンジン本体(apt版には存在しないため`mkdir -p`してから新規配置)

最後に`sudo ldconfig`で共有ライブラリキャッシュを更新し、変更を即座に
反映させる。

### 復元(切り戻し)したい場合

```sh
BK=~/qtvk_backup_<タイムスタンプ>   # 実際のディレクトリ名に置き換える
sudo cp -a $BK/libQt5VirtualKeyboard.so* /usr/lib/aarch64-linux-gnu/
sudo cp -a $BK/VirtualKeyboard_qml/. /usr/lib/aarch64-linux-gnu/qt5/qml/QtQuick/VirtualKeyboard/
sudo cp -a $BK/libqtvirtualkeyboardplugin.so /usr/lib/aarch64-linux-gnu/qt5/plugins/platforminputcontexts/
sudo cp -a $BK/virtualkeyboard_plugins/. /usr/lib/aarch64-linux-gnu/qt5/plugins/virtualkeyboard/
sudo ldconfig
sudo systemctl restart shonan-gui.service
```

または単純に`sudo apt-get install --reinstall qtvirtualkeyboard-plugin
qml-module-qtquick-virtualkeyboard libqt5virtualkeyboard5`でもapt版へ戻せる
(この場合は日本語入力ができなくなる)。

## 4/9 受信(RX)用GNU Radio + gr-dvbs2rxの導入

`SKIP_GNURADIO_BUILD=1`の場合はこのブロック全体をスキップする(受信機能は動作しない)。

```sh
sudo apt-get install -y gnuradio gnuradio-dev cmake pkg-config
git clone https://github.com/igorauad/gr-dvbs2rx.git "$GR_DVBS2RX_BUILD_DIR"   # 既にあればpull --ff-only
git -C "$GR_DVBS2RX_BUILD_DIR" submodule update --init --recursive
git -C "$GR_DVBS2RX_BUILD_DIR" apply "$RX_PATCH"   # 存在し未適用の場合のみ
cmake .. -DCMAKE_BUILD_TYPE=Release && make -j"$(nproc)" && sudo make install
```

`pi4/rx/shonan_rx.py`は`from gnuradio import gr, analog, blocks, iio, dvbs2rx`を
実行時に必要とする。`gnuradio`本体(gr-iio機能を含む`libgnuradio-iio*`も同梱)は
Debianのaptで導入できるが、`dvbs2rx`(DVB-S2復調のOOT module、
[igorauad/gr-dvbs2rx](https://github.com/igorauad/gr-dvbs2rx))はapt未配布のため、
ソースを取得しビルド・インストールする。実機での受信安定化のために加えた修正は
`pi4/docs/patches/gr-dvbs2rx_pi4_bringup.patch`として適用する(既に適用済みなら
自動でスキップされる)。参考実装として`pi4/third_party/rpi-dvbs2-receiver-gui/`
(kazushinjo/rpi-dvbs2-receiver-guiより取り込み)も参照。

★これがないとRX開始時に`ModuleNotFoundError: No module named 'gnuradio'`または
`ImportError: cannot import name 'dvbs2rx'`で受信が失敗する(実機の新規インストール
で発見・修正)。

## 5/9 Langstone V2Modify(SDRトランシーバー)のビルド

`SKIP_LANGSTONE_BUILD=1`の場合はこのブロック全体をスキップする。

- `pi4/third_party/Langstone-V2Modify/`(kazushinjo/Langstone-V2Modifyに
  Shonan_Lite連携の改造を加えたもの)を`~/Langstone`へコピーし、同梱の
  Pi 4/DFR0550/ADALM-Pluto向けインストーラ`install_dfr0550.sh`を
  `SHONAN_INTEGRATION=1`で実行する。
- `install_dfr0550.sh`は、ビルドに必要なaptパッケージ、wiringPi、LimeSuite、libiio 0.25の
  導入、I2Cの有効化、Langstoneが使う一部コマンドのsudoers設定(`/etc/sudoers.d/langstone`)を
  行ってから`GUI_Pluto`をビルドする。`SHONAN_INTEGRATION=1`のときは、ログイン時に
  Langstoneを自動起動する設定(`.bashrc`への追記)を行わない(起動は起動メニューと
  `langstone.service`が担う)。
- ★`~/Langstone`は丸ごと上書きされる。Langstoneの設定ファイル
  (`~/Langstone/Langstone_Pluto.conf`)はLangstoneが終了時に書き出すもので、
  リポジトリには含まれないため上書きされない。

## 6/9 起動時コンソール表示の抑制

素のRaspberry Pi OSのままだと、Pi4の起動時にカーネルの起動ログやログインプロンプトが
実機LCDに映り込む(実機で確認)。次の3つを行う(いずれも反映には再起動が必要)。

- `getty@tty1`を無効化する。
- `/boot/firmware/cmdline.txt`に`quiet loglevel=3 logo.nologo vt.global_cursor_default=0`を
  追記する(既に`quiet`があれば何もしない)。
- `cmdline.txt`の`console=tty1`を`console=tty3`に変える。KMS無効(`linuxfb`)環境では
  systemdの起動ログがフレームバッファへ直接書き込まれ、Shonan_Lite/Langstoneの画面に
  文字が重なって映り込む不具合を実機で確認したため、実機LCD(tty1)には何も出さない。

## 7/9 reboot/shutdown/起動アプリ切替のパスワード無し実行を許可

Home画面の「電源オフ」、起動メニューでのアプリ選択、Shonan_Lite⇔Langstoneの切替は、
TTYの無いsystemdサービスから`sudo`を実行する。標準のsudo設定ではパスワード入力を
求められてPAM会話が成立せず(`pam_unix: conversation failed`)、処理が実行されない
不具合を実機で確認した。そこで`/etc/sudoers.d/shonan-pi4-reboot`に、実行ユーザーが
次のコマンドだけをパスワード無しで実行できるルールを書き込み、`visudo -c`で検証する。

- `/sbin/reboot`、`/sbin/shutdown`
- `/bin/systemctl start --no-block shonan-gui.service`
- `/bin/systemctl start --no-block langstone.service`
- `/bin/systemctl stop shonan-display-off.service`

## 8/9 電源電圧警告(稲妻アイコン)表示の抑制

```sh
if [ -f "$BOOT_CONFIG" ] && ! grep -q '^avoid_warnings=' "$BOOT_CONFIG"; then
  echo "avoid_warnings=1" | sudo tee -a "$BOOT_CONFIG" > /dev/null
fi
```

`/boot/firmware/config.txt`に`avoid_warnings=1`が無ければ追記する(既にあれば
何もしない、冪等)。反映には`sudo reboot`が必要。これは画面上の稲妻アイコン・
ログ警告の表示を抑制するだけで、実際の電圧不足自体を解消するものではない
(恒久対策は正規の27W USB-C PD電源・良質なUSBケーブルの使用。
`vcgencmd get_throttled`で実際のスロットリング有無を確認できる)。

## 9/9 systemdサービス登録

次の4つのサービスを`/etc/systemd/system/`に作成する(`sudo tee`を使うのは、
リダイレクト`>`自体は`sudo`の権限を引き継がないため)。

| サービス | 内容 | 自動起動 |
| --- | --- | --- |
| `shonan-boot-menu.service` | 起動時に「Shonan_Lite / Langstone」を選ぶ全画面メニュー(`pi4/gui/boot_menu.py`)。選んだ側のサービスを`systemctl start`で起動する | 有効 |
| `shonan-gui.service` | Shonan_Lite本体(`pi4/gui/main.py`)。異常終了時は3秒後に再起動 | 無効(起動メニューから起動) |
| `langstone.service` | Langstone V2Modify(`~/Langstone/run_pluto`)。`SKIP_LANGSTONE_BUILD=1`なら作らない | 無効(起動メニュー・切替から起動) |
| `shonan-display-off.service` | シャットダウン時にDSI画面とバックライトを消灯する(DSI液晶はOS停止後も最後のフレームを保持するため) | 有効 |

- `shonan-gui.service`と`shonan-boot-menu.service`は、`QT_QPA_PLATFORM=linuxfb:fb=/dev/fb0:nocursor`
  (`/dev/fb0`への直接描画)で動かす。eglfs(KMS/DRM)ではDFR0550のDSIパネルでLangstone
  (レガシーフレームバッファ)との組み合わせ次第でパネル初期化が競合し、バックライト初期化の
  タイムアウトや画面の色化け、`no screens available`等で起動できなくなる不具合を実機で確認したため。
- `shonan-gui.service`・`langstone.service`・`shonan-boot-menu.service`は`Conflicts=`で
  互いに排他制御される。画面は1つのプロセスしか使えないため、どれか1つを`systemctl start`すると
  他は自動的に停止する。アプリの切替はこの仕組みで行い、Pi4自体は再起動しない。
- マーカーファイル`~/.pi4_boot_mode_langstone`の有無を`ConditionPathExists`で見て、
  起動すべきでない側は何もせず正常終了(skipped)扱いになる。
- `langstone.service`は`Environment=HOME=...`を実際の値で埋め込み、`run_pluto`を
  `/bin/bash`経由で起動する(`run_pluto`の先頭行がシェバングでないため。実機で確認)。
- 最後に`daemon-reload`し、稼働中の`shonan-gui.service`/`langstone.service`を`stop`してから、
  `shonan-boot-menu.service`と`shonan-display-off.service`を`enable`・`restart`する。

## 完了後の表示

`shonan-boot-menu.service`の状態を表示し、続けて次の注意書きを表示する。

1. **パスワードなしsudo/sshの前提**: 設定画面の「システム日時」設定(`timedatectl`)や、
   実機LCDのスクリーンショット取得等は、`sudo`をパスワードなしで実行できることを前提に
   している。7/9で許可するのは上記のコマンドだけで、それ以外の`/etc/sudoers.d/`への変更は
   行わない(Langstone用の`/etc/sudoers.d/langstone`は5/9の`install_dfr0550.sh`が作る)。
   必要であれば運用者が判断して個別に設定する。
2. **日本語入力の既定言語**: オンスクリーンキーボードは起動直後は英語配列で、
   globeアイコンをタップすることで日本語(ローマ字入力)へ切り替えられる
   (自動では切り替わらない、既知の仕様)。
3. **avoid_warnings**: 8/9で新規に追記した場合、反映には`sudo reboot`が必要。

## 関連ドキュメント

- `pi4/docs/qtvirtualkeyboard_ja_build.md` — 3/9のビルド手順の一次情報、
  実機で遭遇したハマりどころの詳細
- `pi4/docs/patches/qtvirtualkeyboard_style_dark_language_popup.patch` —
  3/9で適用されるダークテーマパッチの実体(unified diff形式、`git diff`相当)
- `pi4/docs/patches/gr-dvbs2rx_pi4_bringup.patch` — 4/9で適用される受信安定化
  パッチの実体
- `pi4/third_party/Langstone-V2Modify/install_dfr0550.sh` — 5/9で実行するLangstone V2Modifyのインストーラ
- `pi4/docs/shonan_pi4_operation_manual.docx` / `pi4/gui/manual_content.py` —
  GUIの操作方法そのもの(インストール後の使い方)
- `pi4/third_party/rpi-dvbs2-receiver-gui/` — GNU Radio/gr-dvbs2rx受信フロー
  グラフの参考実装(kazushinjo/rpi-dvbs2-receiver-guiより取り込み)

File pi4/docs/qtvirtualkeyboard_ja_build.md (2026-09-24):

# Qt Virtual Keyboard 日本語(OpenWnn)対応ビルド手順

Raspberry Pi OS(Debian trixie)の`apt`版`qtvirtualkeyboard-plugin`には
日本語入力エンジンが同梱されていない(確認できたエンジンはHangul/Hunspell/Thaiのみ)。
`pi4/gui/main.py`のオンスクリーンキーボード(コールサイン・備考欄などのテキスト入力用)
で日本語入力を使うには、Qt公式ソースをOpenWnnエンジン有効でビルドし、
apt版のファイルを差し替える必要がある。

## 前提

- Pi4実機のQtバージョンと完全一致するタグでビルドすること(ズレるとABI不整合でクラッシュする)。
  ```
  qmake -query QT_VERSION   # 例: 5.15.15
  ```

## 手順

```sh
# 1. Qt5開発パッケージ(ビルドに必要。svgのdev版が抜けやすいので注意)
sudo apt-get install -y \
  qtbase5-dev qtbase5-private-dev qtdeclarative5-dev qtdeclarative5-private-dev \
  qtquickcontrols2-5-dev qt5-qmake build-essential libqt5svg5-dev \
  qml-module-qt-labs-folderlistmodel qml-module-qtquick-window2 \
  qml-module-qtquick-layouts qml-module-qtquick-controls2 qml-module-qtquick2

# 2. ソース取得(インストール済みQtバージョンと同じタグ)
git clone --depth 1 --branch v5.15.15-lts-lgpl \
  https://github.com/qt/qtvirtualkeyboard.git qtvirtualkeyboard-src
cd qtvirtualkeyboard-src

# 3. ビルド設定。CONFIG+=openwnnが日本語エンジンを有効化する
#    (src/config.priの`contains(CONFIG, lang-ja.*)|lang-all: CONFIG += openwnn`)。
#    requires(qtHaveModule(svg))を満たさないと全体が無言でSkippedになるので注意。
qmake CONFIG+=openwnn CONFIG+=lang-ja_JP CONFIG+=lang-en_GB CONFIG+=lang-en_US \
  qtvirtualkeyboard.pro

# 4. ビルド(examplesも一緒にビルドされるが本体には不要、examples関連の
#    ビルドだけ後でCtrl-Cしても問題ない)
make -j$(nproc)

# 5. apt版ファイルをバックアップしてから差し替え
BK=~/qtvk_backup_$(date +%Y%m%d%H%M%S)
mkdir -p $BK
sudo cp -a /usr/lib/aarch64-linux-gnu/libQt5VirtualKeyboard.so* $BK/
sudo cp -a /usr/lib/aarch64-linux-gnu/qt5/qml/QtQuick/VirtualKeyboard $BK/VirtualKeyboard_qml
sudo cp -a /usr/lib/aarch64-linux-gnu/qt5/plugins/platforminputcontexts/libqtvirtualkeyboardplugin.so $BK/
mkdir -p $BK/virtualkeyboard_plugins
sudo cp -a /usr/lib/aarch64-linux-gnu/qt5/plugins/virtualkeyboard/. $BK/virtualkeyboard_plugins/

SRC=$(pwd)
sudo cp -a $SRC/lib/libQt5VirtualKeyboard.so.5.15.15 /usr/lib/aarch64-linux-gnu/
sudo cp -a $SRC/qml/QtQuick/VirtualKeyboard/libqtquickvirtualkeyboardplugin.so \
  /usr/lib/aarch64-linux-gnu/qt5/qml/QtQuick/VirtualKeyboard/
sudo cp -a $SRC/qml/QtQuick/VirtualKeyboard/plugins.qmltypes \
  /usr/lib/aarch64-linux-gnu/qt5/qml/QtQuick/VirtualKeyboard/
sudo cp -a $SRC/qml/QtQuick/VirtualKeyboard/Settings/libqtquickvirtualkeyboardsettingsplugin.so \
  /usr/lib/aarch64-linux-gnu/qt5/qml/QtQuick/VirtualKeyboard/Settings/
sudo cp -a $SRC/qml/QtQuick/VirtualKeyboard/Styles/libqtquickvirtualkeyboardstylesplugin.so \
  /usr/lib/aarch64-linux-gnu/qt5/qml/QtQuick/VirtualKeyboard/Styles/
sudo cp -a $SRC/plugins/platforminputcontexts/libqtvirtualkeyboardplugin.so \
  /usr/lib/aarch64-linux-gnu/qt5/plugins/platforminputcontexts/
sudo mkdir -p /usr/lib/aarch64-linux-gnu/qt5/plugins/virtualkeyboard
sudo cp -a $SRC/plugins/virtualkeyboard/libqtvirtualkeyboard_openwnn.so \
  /usr/lib/aarch64-linux-gnu/qt5/plugins/virtualkeyboard/
sudo ldconfig

sudo systemctl restart shonan-gui.service
```

## 復元(切り戻し)

```sh
sudo cp -a $BK/libQt5VirtualKeyboard.so* /usr/lib/aarch64-linux-gnu/
sudo cp -a $BK/VirtualKeyboard_qml/. /usr/lib/aarch64-linux-gnu/qt5/qml/QtQuick/VirtualKeyboard/
sudo cp -a $BK/libqtvirtualkeyboardplugin.so /usr/lib/aarch64-linux-gnu/qt5/plugins/platforminputcontexts/
sudo cp -a $BK/virtualkeyboard_plugins/. /usr/lib/aarch64-linux-gnu/qt5/plugins/virtualkeyboard/
sudo ldconfig
sudo systemctl restart shonan-gui.service
```
または `sudo apt-get install --reinstall qtvirtualkeyboard-plugin qml-module-qtquick-virtualkeyboard libqt5virtualkeyboard5` でも同等。

## ハマりどころ

- **eglfsは複数トップレベルウィンドウを扱えない**: `QT_IM_MODULE=qtvirtualkeyboard`だけを
  設定してGUI本体を起動すると、キーボードが独立したQML/Quickウィンドウとして表示されようと
  し、`EGLFS: OpenGL windows cannot be mixed with others`でクラッシュする。
  `pi4/gui/main.py`では`QQuickWidget`+`InputPanel.qml`を`QMainWindow`に埋め込む方式で回避した
  (`MainWindow._build_keyboard_panel()`参照)。
- **`requires(qtHaveModule(svg))`**: `libqt5svg5-dev`が無いとqmakeが警告なしに
  ビルド全体をスキップする(`Some of the required modules (qtHaveModule(svg)) are not
  available. Skipped.`とだけ出て`make`が即0で終わる)。
- **日本語は既定の選択言語にならない**: `layoutsModel`(`en_GB,en_US,fallback,ja_JP,ko_KR,th_TH`)
  には正しく含まれるが、`Keyboard.qml`の`updateDefaultLocale()`の優先順位により起動直後は
  英語が選ばれる。キーボード左下のglobeアイコンをタップすれば日本語配列に切り替わる
  (`VirtualKeyboardSettings.activeLocales`/`.locale`をコード側で明示指定しても、
  タイミングの都合で既定選択には反映されなかった)。
- **`strings`でリソースが見えない**: Qtのコンパイル済みリソース内のパス名はUTF-16LEで
  格納されるため、`strings`で確認するときは`strings -e l`を使う(通常の`strings`では
  何も出ずヒットしない)。
- **言語切替ポップアップと単語予測ポップアップは別スタイルプロパティ**: globeアイコンで
  開く言語一覧は`style.qml`の`languageListDelegate`/`languageListBackground`
  (`Keyboard.qml`の`languagePopupList`が使用)が担当する。似た名前の
  `popupListDelegate`/`popupListBackground`は単語補完等の別ポップアップ用で、
  こちらを変更しても言語一覧の見た目は変わらない(実機で誤って前者を変更し、
  反映されず気づいた)。配色変更は`src/virtualkeyboard/content/styles/default/style.qml`の
  該当箇所(`languageListDelegate`のTextの`color`、`languageListBackground`の
  `Rectangle`の`color`、`states: State { name: "current" ... }`の選択中の色)を編集し、
  `cd src/virtualkeyboard && make`でコアライブラリだけ再ビルドすれば十分
  (openwnnプラグイン等は再ビルド不要)。

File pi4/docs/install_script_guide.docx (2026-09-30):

Shonan_Lite for RasPI4

セットアップガイド

対象: pi4/scripts/install.sh
新規Pi4への一括セットアップ手順(README.md相当)
版: 2026-09-30

# 目次

概要

0. Raspberry Pi OSのインストール

1. install.shの実行

実行条件(前提条件)

関連ドキュメント

# 概要

Raspberry Pi 4 + ADALM-Pluto+によるDVB-S2 DATV送受信タッチGUIシステム。本体はpi4/配下(Python/PyQt5、DFR0550はlinuxfb直描画)。同系統の別プラットフォーム移植版(Android/iOS)は別リポジトリ(Shonan_Lite-android/Shonan_Lite-iPad等)で管理している。

# 0. Raspberry Pi OSのインストール

Pi4本体に、あらかじめRaspberry Pi OSをインストールしておく。

1. PCでRaspberry Pi Imager(https://www.raspberrypi.com/software/)を起動する。
2. 「デバイスを選択」でRaspberry Pi 4を選ぶ。
3. 「OSを選択」でRaspberry Pi OS (64-bit)を選ぶ(32bit版は不可。「実行条件」参照)。
4. 「ストレージを選択」で書き込み先のmicroSD/NVMeを選ぶ。
5. 歯車アイコン(詳細設定)で、ホスト名・ユーザー名/パスワード・Wi-Fi・SSH有効化を事前設定しておくと、初回起動後すぐSSH接続できる。
6. 「書き込む」を実行し、完了後microSD/NVMeをPi4に取り付けて起動する。
7. PCからssh <ユーザー名>@<ホスト名>.localで接続できることを確認する。

# 1. install.shの実行

SSH接続したPi4上で:

git clone https://github.com/kazushinjo/Shonan_lite-PI4.git

cd Shonan_lite-PI4

./pi4/scripts/install.sh # HTTPSでclone/pull(既定)

# ./pi4/scripts/install_ssh.sh # GitHubにSSH鍵を登録済みならこちらでも可

日本語入力ビルド・受信(RX)用GNU Radio/gr-dvbs2rxビルド・Langstone V2Modifyビルドはそれぞれ省略して時間短縮できる(省略した機能は使えなくなる):

SKIP_JA_KEYBOARD=1 SKIP_GNURADIO_BUILD=1 SKIP_LANGSTONE_BUILD=1 ./pi4/scripts/install.sh

★OSを新規インストールした直後の初回実行では、DFR0550をfirmwareのレガシーDSI表示で動かすため、install.shが/boot/firmware/config.txtの表示設定を書き換えて終了する。案内に従ってPi4を再起動(sudo reboot)し、同じコマンドを再実行するとビルドへ進む。

処理は表示設定の確認と1/9〜9/9(ソース取得、依存パッケージ、日本語入力、受信用GNU Radio、Langstone V2Modify、起動時コンソール表示の抑制、sudoers設定、電源電圧警告の抑制、systemdサービス登録)。完了後は起動メニュー(shonan-boot-menu.service)が自動起動し、Shonan_LiteかLangstoneを選んで起動する。あわせて/boot/firmware/config.txtへavoid_warnings=1(電源電圧警告アイコンの表示抑制)を未設定なら自動で追記する(反映には再起動が必要)。

# 実行条件(前提条件)

一般ユーザーが実行してinstall.shが正常完了するには、以下が必要。

- Raspberry Pi OS 64bit(aarch64)であること(32bit版不可)
- gitが事前にインストール済みであること
- GitHub/apt配布ミラーへのインターネット到達性
- sudoが使える対話的な実行(パスワード入力に応答できるtty)
- patchコマンドが使えること

詳細な各手順の解説・トラブルシュートはpi4/docs/install_script_guide.md(英語版: install_script_guide_en.md)を参照。

# 関連ドキュメント

- pi4/docs/install_script_guide.md — install.shの詳細ガイド
- pi4/docs/qtvirtualkeyboard_ja_build.md — 日本語オンスクリーンキーボードのビルド手順・ハマりどころ
- pi4/docs/shonan_pi4_operation_manual.docx / pi4/gui/manual_content.py — GUIの操作説明書(アプリ内Helpと同内容)
- pi4/third_party/rpi-dvbs2-receiver-gui/ — GNU Radio/gr-dvbs2rx受信フローグラフの参考実装(kazushinjo/rpi-dvbs2-receiver-guiより取り込み)

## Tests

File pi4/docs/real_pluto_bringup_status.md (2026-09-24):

# Pi4実機PlutoSDRブリングアップ 調査報告書

作成日: 2026-08-09
対象: `pi4/rx/shonan_rx.py`(gr-dvbs2rx RX)+ `pi4/src/tx_main.cpp`(aff3ct TX)、
      同一PlutoSDR上でのTX→40dBアッテネータ→RXループバック試験

## 追記(2026-08-20): PL-syncロック不安定・映像デコード失敗の原因と恒久対策

### 現象
40dBアッテネータでのRFループバック試験で、RXが`locked=True`/`False`を
頻繁に繰り返し(以前は約50%の頻度で瞬断)、映像が0フレームしかデコード
できない事象が発生した。RXゲイン(45〜65dB手動/AGC)を振っても改善せず、
Pi4側送出のリアルタイム優先度(`chrt`)・`-muxrate`指定でも変化なし。

### 根本原因1: Pluto+上の`tsp`受信バッファが小さすぎる
`/root/udpts.sh`内の`tsp -r --buffer-size-mb 0.01`(=10KB)がPlutoの
Zynq(非力なARMコア)上でUDP受信→analyze/pcrextractプラグイン→
`pluto_dvb`へのパイプ、という処理チェーンに対して小さすぎ、内部で
詰まってPL-sync自体を不安定にしていた。**`0.2`(200KB)に拡大したところ
ロックがほぼ完全に安定した**(locked=True比率が劇的に改善)。
併せてtsp `-I ip`側のUDPソケット受信バッファも`--buffer-size 4194304`
(4MB)に拡大した(input側の受信キュー溢れ対策、ロック安定への寄与は
buffer-size-mbほど大きくないが実害はないため残置)。

### 根本原因2: 手動テストコマンドの`pkt_size`欠落(実機GUIには影響なし)
上記対策後もRXは安定ロックしたが映像は依然0フレームだった。原因は
**手動SSHテストで使っていたffmpeg TXコマンドに`?pkt_size=1316`が
付いていなかった**ため(実機の`backend.py`の`_build_udp_ts_url()`は
最初から`pkt_size=1316`付きで送信しており、この問題を元々抱えていない)。
`pkt_size=1316`を付けた途端に映像デコードが成功した(実機GUIでも
カラーバー映像の表示を確認済み)。**Pi4/Pi5間の違いではなく、調査時の
手動テストスクリプトの不備だった**と判断できる。

### 永続化の落とし穴: Plutoのルートファイルシステムは再起動でリセットされる
このPlutoSDR機はルートファイルシステムが`rootfs`(RAM上)で、
`/root`・`/etc`配下は電源断/再起動のたびに出荷時状態へ完全リセットされる。
`/etc/init.d/S89patchfirm`が毎起動時に唯一の永続化フラッシュ領域
`/mnt/jffs2/patch.zip`を`/`へ自動展開する仕組みが元々用意されていたが、
`patch.zip`自体が存在しなかったため機能していなかった。
**上記の`udpts.sh`修正(buffer-size-mb/UDPバッファ拡大)は
`root/udpts.sh`として`/mnt/jffs2/patch.zip`に格納し、再起動後も
自動再適用されることを確認済み。**

同様に`/www/settings.txt`(周波数/シンボルレート等のDVB-S2パラメータ)も
再起動でリセットされるが、こちらは**GUI側`TxController.start()`が
送信開始のたびに`_push_pluto_settings()`で毎回再送信する既存動作の
ため、追加対応は不要**(手動SSHテスト時のみ都度手動POSTが必要)。

### 検討したが見送った変更
- `rtmppluto.sh`(Android版が実際に使うRTMP経路、`RTMPTxController.kt`
  参照)は、Pi4/Pi5では未使用と誤認して一時無効化したが、**同一Pluto
  実機をAndroid版で使う際に支障が出るため再度有効化した**(CPU負荷は
  待受時0%で実害がないため、無効化するメリット自体がなかった)。
  複数プラットフォームで同一Pluto実機を共用する場合、片方専用の
  最適化のつもりで他方の経路を無効化しないよう注意すること。
- `pluto_dvb -L`(バッファ待機時間、既定400ms)を2000msへ拡大する案は
  効果が確認できなかったため見送り、400msのまま。

### 再発防止のポイント
- Pluto実機の設定変更(`/root/*.sh`, `/etc/init.d/*`)を行う際は、
  必ず`/mnt/jffs2/patch.zip`(`root/...`, `etc/...`の相対パス構成)に
  反映してから再起動で永続化を検証すること。ライブ編集のみで
  満足すると次回再起動で消える。
- 手動SSHでのTXテストでは`pkt_size=1316`を必ず付与すること
  (`udp://<host>:8282?pkt_size=1316`)。付け忘れると実機では
  発生しない映像破損を誤診断する。
- 複数プラットフォーム(Pi4/Pi5/Android)で同一Pluto実機を共用する
  前提を忘れず、片方の都合だけで起動スクリプトの経路を無効化しない。

## 追記(2026-08-09、同日6回目セッション追加3): パイロット有無も明確な傾向なし

ユーザーから「Android版ではパイロット信号はどうなっているか」の指摘を受け確認。
**`rtmppluto.sh`(Pluto+側、Android版が実際に使う経路)の`pluto_dvb`起動行には
`-p`フラグが一切存在しない=Android版の本番経路はパイロット信号OFFで動作している**
ことが判明した(それまでのRF検証テストは一貫してパイロットON`-p`/`--pilots`で
実施していた、報告書内の「rtmppluto.shの実際のpluto_dvb起動行」参照)。

パイロットOFF(`-p`なし・RX側`--no-pilots`、frame_len=32490)で同条件のRF
ループバック試験を実施したところ、**49件(22秒間)** — パイロットON時の
baseline(52件)とほぼ同水準だった。`errors=0`(パイロットON時は24〜164件)と
パケット単位のデータ整合性は改善したが、**周期的なロック喪失自体の頻度は
パイロット有無で変わらなかった**。

**まとめ(更新): calib_mode、RXトラッキングキャリブレーション、`pluto_dvb -q`、
unlock_thresh、TXデータ生成方法、TX/RXゲイン、パイロット有無のいずれも、
1.4秒周期のロック瞬断の原因ではないか、効果が限定的と切り分けが完了した。
Android版との設定差異(パイロット)を解消しても瞬断自体は解消しなかったため、
「Android版で問題が起きないのはパイロット設定の違いのため」という仮説も
否定された。**

---

## 追記(2026-08-09、同日6回目セッション追加2): TX/RXゲインの組み合わせも明確な傾向なし

ユーザーから「送受信のゲイン設定は影響していないか」の指摘を受け検証。ループバック
(TX SMA→40dBアッテネータ→RX SMA)構成で、TXゲイン(`-g`)とRXゲイン
(`--gain-db`)の組み合わせを振り、22秒間のロック喪失イベント数を比較した。

| TXゲイン | RXゲイン | ロック喪失イベント数 | 備考 |
|---|---|---|---|
| 0dB(既定・最大出力) | 60dB(既定) | 52件 | baseline |
| -10dB | 60dB | 58件 | |
| -20dB | 60dB | 43件 | |
| -40dB | 60dB | (ロック自体不成立) | 信号が弱すぎてmetricが閾値付近(42〜43)まで低下、SN比不足による別の失敗モード |
| 0dB | 40dB | 48件 | |

`-40dB`のような極端な減衰では信号強度不足で別の失敗モード(ロック不成立)になるが、
それ以外の組み合わせ(0/-10/-20dB × 40/60dB)は**43〜58件の狭いレンジに収まり、
単調な傾向が見られなかった**。これは、これまで確認してきた試行ごとの自然な
ばらつきの範囲内である可能性が高く、TX/RXゲインの調整では明確な改善は
得られないと判断した。ただし相関検出の`metric`値自体はAGC非依存に正規化
されているため(`pl_frame_sync.cc`参照)、信号レベルの変化を直接読み取る
指標としては使えない点に注意。

**まとめ: calib_mode、RXトラッキングキャリブレーション、`pluto_dvb -q`、
unlock_thresh、TXデータ生成方法(ライブ/静的)、TX/RXゲインの組み合わせの
いずれも、1.4秒周期のロック瞬断の決定的な原因ではないか、効果が限定的と
切り分けが完了した。実機で試せる現実的な選択肢はほぼ尽きたと考えられる。**

---

## 追記(2026-08-09、同日6回目セッション追加): TXデータ(ライブエンコード)は原因ではないと確定

ユーザーからの「TXデータの問題ではなかったのか」という指摘を受け、それまでの
RF系再検証が全てffmpegによる**ライブエンコード**(testsrc→libx264リアルタイム
変換)をTXソースに使っていたことに気づいた。エンコーダ自身のタイミング揺らぎ
(キーフレーム挿入・CBR fillerの挙動等)が原因である可能性を切り分けていなかった。

**検証: 事前に20秒分のTSファイルを1回だけ生成し(`-c:v libx264 ... /tmp/static_test.ts`)、
それを`ffmpeg -re -stream_loop -1 -i static_test.ts -c copy`で再エンコードなし・
実時間ペーシングのみでループ再生してpluto_dvbへ送信した。**

結果: **52件のロック喪失(22秒間)** — ライブエンコード時(55〜72件)とほぼ同水準。
**TXデータ生成方法(ライブエンコード有無)を変えても瞬断の頻度は変わらないことが
確定した。TXデータの内容・生成タイミングは原因ではない。**

これにより、原因は「ライブエンコードの揺らぎ」ではなく、より低レベルな要因
(RFフロントエンド・AD9361チップ内部・pluto_dvb変調プロセス自体の何らかの周期動作)
にあることがさらに裏付けられた。

---

## 追記(2026-08-09、同日6回目セッション): unlock_thresh実験も効果なし

「今後の課題」①(1.4秒周期のPLロック瞬断)の調査を再開。`gr-dvbs2rx`の
`pl_frame_sync`の`unlock_thresh`(既定3、`plsync_cc_impl.cc`で
`new frame_sync(debug_level)`と呼ばれ明示指定なし=既定値のまま使われている
ことを確認)を6に引き上げてリビルドし、同一セッション内で3と6を直接比較した。

| unlock_thresh | ロック喪失イベント数(22秒間) |
|---|---|
| 6 | 55件 |
| 3(既定) | 72件 |

閾値を上げるとやや減る(3→6でおよそ24%減)ものの、大きな改善にはならなかった。
これは基礎となるRF振幅ドロップアウト(生IQダンプで確認済み)自体が、6シンボル
分の連続ミスでも吸収しきれないほど長く/頻繁に発生していることを示唆する。
実験後はunlock_threshを既定値3に復元済み。

**AD9361の全デバイス属性(`iio_attr -d ad9361-phy`)も再確認したが
(`dcxo_tune_*`, `ensm_mode`, `gain_table_config`, `rssi_gain_step_error`,
`trx_rate_governor`等)、新たな有力な手がかりは見つからなかった。
`ensm_mode`には`pinctrl_fdd_indep`という別のFDD動作モードが存在するが、
実機を壊すリスクがあるため未検証のまま。**

**現時点の結論: calib_mode・RXトラッキングキャリブレーション・`pluto_dvb -q`
フラグ・unlock_thresh・AD9361属性一式のいずれも原因ではないか、効果が
限定的と切り分けが完了した。生IQダンプで実際のRF振幅ドロップアウトが
存在することは実証済みだが、その発生源はソフトウェア側の設定調整では
到達できない領域(AD9361チップ内部の非公開動作、FDD運用時のRFフロントエンドの
物理的な制約等)にある可能性が高い。次の一手として現実的なのは、
`pinctrl_fdd_indep`モードの慎重な検証、またはこの問題を「既知の制約」として
一旦棚上げし、Pi4のCPU実時間マージン確認など他の項目に移ることだと考えられる。**

---

## 追記(2026-08-09、同日5回目セッション): SSH直接パイプを廃止しRTMP方式へ

**下記「4回目セッション」で導入したSSH直接パイプ方式(`ffmpeg | ssh ... pluto_dvb`)は
廃止し、shonan-android版RTMPTxController.ktと全く同じRTMP方式に切り替えた。**
カメラ+音声診断で長時間悩まされたUnderflowの真因が判明したため。

### 真因判明の経緯

ユーザーから「Android版は同じPlutoでpluto_dvbを使っているのに問題ないのはなぜか」
という指摘を受け、Android版のTX実装(`RTMPTxController.kt`)を調査した。
結果、**Android版はSSHを一切使わずRTMPで
Pluto+上の`rtmppluto.sh`(常駐RTMP受信デーモン、`/etc/init.d/S90datv`起点)へ
プッシュしている**ことが判明。SSH方式ではpluto_dvbの標準入力が直接ネットワークに
晒されるのに対し、RTMP方式ではPluto上の頑丈なffmpeg(rtmppluto.sh)がネットワークの
揺らぎを吸収し、pluto_dvb自体はPluto内部のローカルパイプからしかデータを受け取らない
構造になっている。

実機調査の結果、以下が判明した:

1. **`rtmppluto.sh`は実際には機能する。** 過去のセッションで「このPlutoのffmpegには
   `"match up:"`という文字列が存在しない」と結論していたが、これは誤りだった。
   `"match up:"`はPluto独自パッチではなく、標準的なRTMPプロトコルの警告メッセージ
   `"App field don't match up: <値> <-> "`の一部で、実際に存在する。
2. **原因はFEC値に含まれる`/`だった。** DVB-S2パラメータはRTMP接続URLのパス部分
   (例: `rtmp://host:7272/,437,DVBS2,QPSK,1500,3/5,-40,nocalib,800,64,,`)に
   カンマ区切りで埋め込まれ、`rtmppluto.sh`はffmpegの上記警告メッセージに
   そのパス全体がエコーされる挙動を利用してパラメータを取り出す。しかしFEC値を
   `"3/5"`のようにスラッシュ付きで書くと、RTMPのapp/playpath区切り(`/`)と衝突し
   パラメータが分断される。Android版は`FECRate.plutoParameter`でスラッシュを
   除いた表記(`"3/5"`→`"35"`)を使っており、これが回避策になっていた。
3. **カメラ+音声診断のUnderflowの主因は、単純なビットレート不足だった。**
   `pluto_dvb -m DVBS2 -c QPSK -s 1500000 -f 3/5 -d`のdry-run出力で確認したところ、
   このシンボルレート/変調方式構成が要求する実ネットビットレートは約
   **1,782,456bps(≈1.78Mbps)**。旧診断機能の映像800kbps+音声64kbps≈864kbpsは
   これを大きく下回っており、慢性的なUnderflowの直接原因だった。通常送信
   (`start()`)は既に1.9Mbps程度を供給していたため問題が起きていなかった。
4. RTMP方式でも、テスト間でログファイルをクリアせずに累積カウントを見ていたために
   誤って「大量のUnderflowが残っている」と誤診した場面があった。ログを都度クリアし
   十分なビットレートで計測し直すと、**2回連続で0 Underflowを確認**できた。

### 実装

- `pi4/gui/backend.py`: `TxController`を全面書き換え。SSH関連コード(sshpass、
  リモートpluto_dvbのkillall等)を全て削除し、ffmpegを`setsid bash -c "..."`経由
  ではなく**直接QProcessで起動**(`-f flv rtmp://<pluto>:7272/,...`へプッシュ)する
  シンプルな構成にした。これによりプロセスグループ管理(setsid/os.killpg)も
  不要になった(ffmpeg単一プロセスなのでQProcess.terminate()がそのまま効く)。
  Pluto側のpluto_dvbライフサイクルは`rtmppluto.sh`が自律管理するため、Pi4側から
  リモートプロセスを気にする必要が一切なくなった。
  - ステータス判定: RTMP方式ではPluto側のUnderflow等がPi4から見えなくなる
    (Android版も同様の制約)ため、`status_updated`は`{"connected": bool}`のみに
    簡略化。ffmpeg自身の進捗行(`frame=...`)の出現を"connected"とみなす。
  - ウォッチドッグ再接続を追加: Android版のコメントに「Pluto+側RTMP受信が
    接続後20〜30秒程度で自発的に切断する」既知の挙動が記載されていたため、
    `stop()`が呼ばれていないのにffmpegプロセスが終了したら0.5秒後に自動的に
    再起動する仕組みを追加(RxControllerの既存ウォッチドッグと同様の設計)。
  - カメラ+音声診断のビットレートを800k/64k→symbol_rate_hzに比例した値
    (既定1.9Mbps程度)に引き上げ。
- `pi4/gui/screens/testequipment.py`/`tx.py`: `underflow_count`を参照する箇所を
  全て削除し、`connected`のみで健全性判定するよう簡略化。

### 実機検証結果

`start()`(映像のみ)・`start_camera_audio()`(カメラ+音声)とも、実機eglfs上で
`TxController`を通して複数回実行し、いずれも`connected=True`・エラーなしで
安定動作を確認した。Pluto側も`rtmppluto.sh`のループが正しく待受状態へ戻ることを
確認済み(孤児プロセスなし)。

**注意: `rtmppluto.sh`はPluto+の`/etc/init.d/S90datv`起点で起動する常駐サービス。
本セッション中に調査のため手動で何度も停止・再起動したため、既に正規の起動方法
(`/root/rtmppluto.sh >/dev/null </dev/null 2>/dev/null &`)で復旧済みだが、
Pluto+を再起動すれば通常通り自動起動する。**

---

## 追記(2026-08-09、同日4回目セッション): TX経路をaff3ctからpluto_dvbへ切り替え

**GUIのTX経路を、下記「解決」節で実証済みの`pluto_dvb`(Pluto内蔵変調器、SSH経由)を
正式経路とするよう変更した。理由: `pluto_dvb`は単独でDVB-S2符号化・変調まで完結する
独立したモジュレータであり、aff3ctが行っていた符号化+変調を丸ごと代替できる
(むしろこちらが実証済みの経路)。shonan-android版の実績あるTXパスも元々
`pluto_dvb`を使っており、Pi4版のaff3ct実装(未解決のBBHEADER CRC8不具合を抱えたまま)
の方が他の兄弟プロジェクトとは異なる独自路線だった。旧`shonan_tx`(aff3ct、
`pi4/src/tx_main.cpp`)・`run_tx.sh`はソースを削除せずGUIからの呼び出しのみ停止した
(手動CLI利用や将来の参照用に残す)。**

### 変更内容

- `pi4/gui/backend.py`: `TxController.start()`/`start_camera_audio()`を
  `run_tx.sh`(aff3ct)経由から`ffmpeg | sshpass ssh root@Pluto 'pluto_dvb ...'`
  (SSHパイプ)経由に変更。ステータス判定もaff3ct固有の`starved`/`dmaRms`から、
  pluto_dvbの出力(`PlutoDVB Init`等の起動バナー検出=`connected`、`Underflow`行の
  カウント)ベースに変更。
- `pi4/gui/settings_store.py`: `bandwidth_hz`/`rf_port`/`runtime_dir`は
  pluto_dvbが使わないため削除(GUI設定・streamoutput.py画面からも撤去)。
  `sample_rate_hz`の既定値を`1_500_000`→`3_000_000`に変更(実IQサンプルレート、
  symbol_rate=sample_rate_hz/2としてpluto_dvbの`-s`へ渡す。3.0Msps=symbol_rate
  1.5Msym/sは実機で繰り返し検証済みの値)。
- `pi4/gui/screens/testequipment.py`/`tx.py`: TX単体診断・カメラ+音声診断の
  健全性判定を`connected`かつ累積`underflow_count`が増えていないことに変更。
- `pi4/rx/shonan_rx.py`: CLI既定値を`pluto_dvb`向け(`--framesize normal`
  `--rolloff 0.35` `--sample-rate-hz 3000000`)に変更(旧aff3ct向けの
  `short`/`0.20`から)。

### 実機検証: 通常送信は解決、カメラ+音声診断は原因不明のまま残存

**通常送信(`start()`、映像のみ。testsrcまたは実カメラ、音声キャプチャなし)は
QProcess経由・実機eglfsで繰り返し`underflow_count=0`を確認**、問題なし。

**カメラ+音声同時キャプチャの診断(`start_camera_audio()`)のみ、QProcess経由だと
断続的にUnderflow(100〜160件/10秒程度)が発生する現象が残っている。** 生の
`ffmpeg | ssh ... pluto_dvb`をPi4上でbashスクリプトとして直接実行すると
毎回`Underflow=0`で安定するのに対し、全く同じコマンドをPyQt5の`QProcess`から
起動すると高頻度でUnderflowが発生する、という差が繰り返し確認された。

以下を切り分けたが、**いずれも決定的な原因ではなかった**:

- `QProcess`が既定でstdinを開いたパイプのままにする問題
  (`setStandardInputFile(QProcess.nullDevice())`で対策、単体切り分けでは
  効果があったがTxController全体に組み込むと再現)
- `status_updated`/`log_line`シグナルの発行自体(スロット未接続でも`emit()`する
  こと自体が悪影響、という切り分け結果が単体テストでは複数回再現したが、
  TxControllerへ組み込んで`quiet_mode`(シグナルを一切発行せずポーリングのみ)に
  変更しても解消しなかった)
- `refresh_camera_audio_frame_counts()`のログファイル全読み込み
  (差分読み込みに変更、さらに完全に呼ばないパターンでも試したが変化なし)
- `pluto_dvb`出力を`QProcess`のstdout(`2>&1`)へ合流させていたのをやめ、
  ffmpegログと同様ファイルへ落としてポーリングする方式に変更(有力な仮説
  だったが、実装後の実機検証でも改善しなかった)
- Pluto側の孤児プロセス(`stop()`がリモートのpluto_dvbを確実に終了できて
  おらず、`ps aux`で最大6個の`pluto_dvb`が同時残存していたことを発見。
  `killall pluto_dvb`による同期クリーンアップをTX開始時・非同期クリーンアップを
  停止時に追加。これ自体は実在する重大なバグで修正済みだが、完全クリーンな
  状態から実行してもUnderflowは再現した)
- USB Audio(C920 PRO)のカーネルレベルのサンプルレート不整合警告
  (`dmesg`に`current rate 16000 is different from the runtime rate 32000`
  `cannot set freq 32000 to ep 0x82`が多数記録されているのを発見、USBデバイスを
  unbind/rebindでリセットしたが変化なし)
- `QtWidgets.QApplication`(実機eglfs、カーソル管理あり)と`QtCore.QCoreApplication`
  (ヘッドレス)の違い(どちらでも再現)

**最終的に、「0件を安定して再現していたはずの最小テストスクリプト」自体が、
コード変更なしに同一セッション内で0件→150件に振れることを確認し、
これまでの「コードの違いが原因」という切り分け結果の少なくとも一部が
セッション中の環境/ハードウェア側の変動(時間経過・連続試験による劣化等)と
たまたま相関していただけだった可能性が高いと判断し、この方向のコード調査は
打ち切った。**

**この過程で実装した以下の修正は、原因の全容解明には至らなかったものの、
いずれも独立して正当な改善であり保持する**: stdinの明示的nullDevice化、
Pluto側孤児プロセスの確実なクリーンアップ(TX開始時の同期killall+停止時の
非同期killall)、カメラ+音声診断のシグナル発行をやめポーリング方式にした
`quiet_mode`アーキテクチャ、ffmpeg/pluto_dvb両ログの差分読み込み化。

### 次回セッションで検討すべきこと

1. カメラ+音声診断のUnderflowが真に環境要因(熱・USB劣化・電源等)なのか、
   長時間・複数回の反復試行(統計的手法)で再現性を検証する。
2. USB Audio(C920 PRO)のカーネル警告(`cannot set freq 32000 to ep 0x82`)が
   実際の音声キャプチャ品質に影響しているか、専用の切り分け試験を行う。
3. 診断機能自体の必要性を見直す(通常送信は健全なので、カメラ+音声の
   同時キャプチャという診断シナリオ自体が実運用よりも過酷すぎる可能性がある)。

**現状(2026-08-09更新): `gr-dvbs2rx`(RX)自体は完全に正しいことを実機で証明済み
(Pluto内蔵変調器`pluto_dvb`との組み合わせでTSパケット抽出・エラー0件まで到達)。
一方、`shonan_tx`(aff3ct)をTXに使った場合はBBHEADER(CRC8)以降でデータが壊れ、
TSパケット出力に至らない。原因は`gr-dvbs2rx`ではなく`aff3ct`側にある可能性が
極めて高いところまで切り分けられた(詳細は「解決: gr-dvbs2rxの正しさをPluto内蔵
変調器で実証」節を参照)。**

---

## クイックスタート(次回セッション用)

### 実機の現在の状態(2026-08-09セッション終了時点)

- Pi4の`shonan-gui.service`は**通常稼働に復元済み**(タッチGUIが使える状態)。
  今回のセッション中は表示テストのため一時停止していたが、再開している。
- Pluto上の`pluto_dvb`テスト送信は**停止済み**。`rtmppluto.sh`由来の壊れた
  待ち受けプロセス(PID 1059/1144/30080相当、無害・パラメータ空)が残っている
  可能性があるが、実害はないので放置してよい。
- `~/gr-dvbs2rx`(Pi実機)のビルド・インストールは完了済みの状態
  (`pi4/docs/patches/gr-dvbs2rx_pi4_bringup.patch`の内容が反映済み)。
  Pi実機を再起動しても`/usr/local/lib/`にインストール済みの`.so`はそのまま
  残るため、**再ビルドは不要**(`~/gr-dvbs2rx`のワークツリー自体を作り直した
  場合のみ、上記パッチを再適用してビルドし直すこと)。
- `~/shonan-pi4/pi4/rx/shonan_rx.py`はこのリポジトリの最新版と同一
  (`--framesize`/`--pilots`オプション反映済み)。

### 最後に成功した検証手順の再現(pluto_dvbリファレンスTX経由)

```sh
# 1. Pi4からSSH(パスワード: raspberry、鍵認証は使わずパスワード認証で)
ssh pi@192.168.0.142
# (毎回 -o PreferredAuthentications=password -o PubkeyAuthentication=no
#  を付けないと鍵認証の試行で固まることがある。sshpass -p raspberry推奨)

# 2. shonan-gui.serviceが起動中なら一旦停止(画面を使う場合)
sudo systemctl stop shonan-gui.service

# 3. Pluto側でpluto_dvbを起動(SSH経由でTSを直接パイプ、rtmppluto.shは使わない)
#    ffmpegはPi4側で実行し、パイプの先でPlutoへSSHログイン(root/analog)して
#    pluto_dvbへ渡す。カメラ映像を使う場合:
ffmpeg -f v4l2 -i /dev/video0 -c:v libx264 -preset ultrafast -tune zerolatency \
  -x264-params nal-hrd=cbr:force-cfr=1 -b:v 1.9M -maxrate 1.9M -bufsize 1.9M \
  -g 15 -pix_fmt yuv420p -f mpegts -muxrate 1900k -mpegts_flags +resend_headers - | \
  ssh root@192.168.2.1 "/root/pluto_dvb -s 1500000 -f 3/5 -m DVBS2 -c QPSK -p \
  -t 437000000 -g 0 -L 800 -T 8"
# (Pluto側ログイン: root/analog。-pでパイロット有効化必須。
#  nal-hrd=cbr+muxrateを付けないとUnderflowが発生するので必須)

# 4. 別ターミナル(またはPi4上の別セッション)でRX起動
python3 ~/shonan-pi4/pi4/rx/shonan_rx.py --pluto-uri ip:192.168.2.1 \
  --lo-hz 437000000 --sample-rate-hz 3000000 --mod-cod QPSK-S_3/5 \
  --framesize normal --pilots --rolloff 0.35 --no-agc --gain-db 60 \
  --output-fifo /tmp/rx.ts --status-interval-sec 2
# (sample-rate-hzはシンボルレート1.5Msym/sの2倍=3000000であること、
#  rolloffは0.35固定、gain-dbは60が反復的に最も安定)

# 5. 作業終了後はGUIサービスを再開しておく
sudo systemctl start shonan-gui.service
```

**期待される結果**: `locked=True`が断続的に出つつ`frame`/`packets`が
着実に増加、`errors`は0〜数十件程度(実行ごとに変動、詳細は
「pluto_dvb経路での映像品質改善」節参照)。約1.4秒周期で一瞬
`locked=False`に戻るのは既知の制約で、映像自体は表示可能
(視覚確認済み)。

### 次にやること(優先順)

1. ~~1.4秒周期のロック瞬断の原因調査(calib_mode manual実験)~~ →
   **2026-08-09追記: calib_mode=manualは逆効果、RX側トラッキングキャリブレーション
   無効化・`pluto_dvb -q 0`明示指定もいずれも効果なしと判明(いずれも
   実機で切り分け済み)。生IQダンプで実際のRF振幅ドロップアウトが存在する
   ことは確認済みだが、AD9361キャリブレーション周りでは説明できなかった。
   `manual_tx_quad`への自動遷移(pluto_dvb起動時に無条件発生)が本当に
   関係あるのか、それとも無関係な副産物なのか未確定のまま。次はpluto_dvb
   ソース自体の確認、またはこの方向性を打ち切ってaff3ct側TX精査へ切り替える
   ことを検討(下記「追記」節参照)。**
2. aff3ct側TX(`shonan_tx`)のBBHEADER/スクランブラ関連コード精査

---

## 追記(2026-08-09、同日後続セッション): Pluto接続がUSB→LANに変更・新規リグレッションと対処

**重要: 本セッション中にPlutoの接続方式がUSB直結(192.168.2.1)から
LAN経由(192.168.0.136、Pi4と同一eth0セグメント)に変更された。
TX SMA→40dBアッテネータ→RX SMAの物理ループバックは同一Pluto上で従前通り
接続されたまま。以降のクイックスタート手順は`--pluto-uri ip:192.168.0.136`
に読み替えること。**

### 新規リグレッション: LAN接続化でPLロックが一度も成立しなくなっていた

上記「クイックスタート」の手順をLAN接続後に再現したところ、SOF相関自体は
健全(metric≈53、閾値42を安定して上回る)にもかかわらず、`found`状態のまま
一度も`locked`に遷移しなくなっていた(旧USB接続時は安定してlocked可能だった)。

**原因: `gr-iio`の`fmcomms2_source_fc32`のIIOバッファサイズ(`0x8000`=32768
サンプル)がLAN経由の読み出しには小さすぎ、毎秒10回近くバッファオーバーフロー
(gr-iioが無改行で出す`O`マーカーがログに混入して発覚)していた。** USB-CDC-ECM
直結時はこの頻度でも問題なかったが、実Ethernet経由になったことで読み出し
オーバーヘッドが増え、サンプル取りこぼしが頻発しPLフレーム境界のシンボル
カウントが同期しなくなっていた。

**対処(コミット済み)**: `pi4/rx/shonan_rx.py`のバッファサイズを`0x8000`→
`0x40000`(262144サンプル)に拡大。これによりオーバーフロー頻度が大幅に減り、
`locked=True`への到達・複数フレーム連続デコードが再び可能になった
(ただし完全に0件にはならず、後述の1.4秒周期問題は残存)。

### 除外できた仮説: `[fsdbg]`デバッグ計装のオーバーヘッド

`pl_frame_sync.cc`の`[fsdbg]`(is_peak時に毎秒9〜10回発火するfprintf)を
一時的に無効化してリビルドしても、オーバーフロー頻度・ロック不能症状は
一切改善しなかった。**計装のオーバーヘッドが原因ではないと確定**、その後
`[fsdbg]`は復元済み(現在のビルドに反映済み)。

### 【重要・危険】calib_mode=manualはpluto_dvb自体を壊す(この方向性は放棄)

上記バッファサイズ修正後、当初の最優先課題だった「1.4秒周期のロック瞬断」の
原因調査として`ad9361-phy`の`calib_mode`を`auto`→`manual`に切り替えて
比較実験を行った。結果:

- `calib_mode=manual`にした状態で`pluto_dvb`を起動すると、TX側で
  `Underflow`カウンタが特定の値(例: 2784, 3876)に固着したまま
  進まなくなり、最終的に**`Plutodvb exiting..`で異常終了**した。
  RX側もSOF相関が一度も検出されない(`sof=0`のまま)状態になった。
- **`calib_mode`を`auto`に書き戻すだけでは復旧しなかった**(AD9361の
  ドライバは`auto`書き込み時に即座に再校正をトリガーするわけではない
  ため、キャリブレーション状態が壊れたまま残る)。
- **Plutoの`reboot`で完全復旧を確認**(起動後`calib_mode=auto`、
  `pluto_dvb`正常起動、`locked=True`まで到達)。

**結論: `calib_mode=manual`への切り替えは1.4秒周期問題の解決策ではなく、
むしろTXチェーン自体を破壊する。実機実験としてはこの1回で十分な証拠が
得られたため、この仮説は放棄する。**

### 生IQダンプでの波形観測: 実際のRFレベル振幅ドロップアウトを確認

`pl_frame_sync.cc`の`[unlockdbg]`ログにエポックms単位の絶対時刻(`t_ms`)を追加、
`shonan_rx.py`に`symbol_sync_cc`出力(plsync_ccへの直接入力、シンボルレート
1.5Msym/s)を生complex64でファイルへ記録する`--raw-iq-dump`オプションを一時的に
追加して(共に未コミットの一時計装)、アンロック発生時刻付近の波形を直接観測した。

**結果: 記録した5件のアンロックイベント全てで、該当時刻付近(±100ms窓)に
振幅(RMS)が中央値の約1%まで落ち込む区間が存在することを確認した
(dip_ratio≈0.01、全件で一致)。** これはソフトウェア/タイミング側の
問題(バーストで処理が遅延して見かけ上ロックが飛ぶ等)ではなく、**実際に
RF信号のパワーが一瞬失われている**ことを示す直接証拠であり、
「RF/AD9361チップレベルの周期性を疑う」という当初の仮説の方向性自体は
正しかったことが実機データで裏付けられた(ただし対処法としての
`calib_mode=manual`は誤りだった、という点が上記の教訓)。

### 有力な原因候補: pluto_dvbによるAD9361の自動TX直交(quadrature)再校正

上記振幅ドロップアウトの原因調査中、`pluto_dvb`を一度でも起動すると、
**明示的に触っていないにもかかわらず`ad9361-phy`の`calib_mode`が
`auto`から`manual_tx_quad`へ勝手に遷移している**ことに気づいた
(`iio_attr`で複数回再現確認)。これは`pluto_dvb`(またはその配下の
AD9361ドライバ)が動作中に**TX直交キャリブレーションを自発的に実行し、
完了後の状態を`calib_mode`に残している**ことを示唆する。

`pluto_dvb --help`には`-q {0,1} 0:Use a calibration file 1:Process
calibration (!HF peak!)`というオプションが存在し(未指定時の既定値は
未検証)、"!HF peak!"という警告文言から、有効時にRF較正用のテスト信号
(高周波ピーク)を実際に送出する動作である可能性が高い。ただし今回の
全試験で`-q`は一度も明示指定していないため、この特定のCLIオプションが
直接の引き金かどうかは未確認(既定動作の可能性、あるいはAD9361ドライバの
バックグラウンドtracking calibration機能が`pluto_dvb`の初期化と独立に
働いている可能性も残る)。Pluto上に既存の較正ファイルは見つからなかった
(`find / -iname '*calib*'`で該当ファイルなし)。

**2026-08-09追記(同日3回目セッション): 上記1・2を実施、いずれも効果なしと判明**

- **RX側トラッキングキャリブレーション3種の無効化(`quadrature_tracking_en`/
  `rf_dc_offset_tracking_en`/`bb_dc_offset_tracking_en`を`voltage0`(入力)
  チャンネルで`0`に設定)**: `calib_mode=manual`のような破壊的な影響は一切なく
  安全に切り替えられたが、`unlockdbg`件数は有効時(78件/22秒)→無効時
  (78件/22秒)と**完全に同数**。RX側トラッキングは原因ではないと確定。
- **`pluto_dvb -q 0`明示指定**: 3回試行(18件/22秒、0件/接続断で無効試行、
  150件/22秒)し、結果は有効時と同程度〜それ以上に大きくばらついた
  (既知の「同一設定でも試行ごとに大きくばらつく」現象の範囲内と判断)。
  さらに重要な点として、**`-q 0`を指定してもTX起動後の`calib_mode`は
  やはり`manual_tx_quad`へ自動遷移する**ことを確認した。つまり`-q`フラグは
  この遷移の発生条件ではない(常に発生する、`pluto_dvb`起動シーケンスに
  組み込まれた無条件の一回限りの校正と見られる)。
- **副次的に判明した既知の挙動**: `iio_attr`で`ad9361-phy`の`calib_mode`
  属性へ書き込む(`auto`書き込みも含む)と、直後の数秒間Plutoのiiodが
  一時的に無応答になることがある(ping自体は生きている場合が多く、
  ネットワーク断ではなくiiod/AD9361ドライバ側の処理待ちと見られる)。
  次回セッションでスクリプトから`iio_attr`を呼ぶ際は、書き込み直後に
  十分な待機時間を入れること。

**結論: RX側トラッキングキャリブレーション・`pluto_dvb -q`フラグのいずれも
原因ではないと切り分けられた。`manual_tx_quad`への自動遷移自体は
`pluto_dvb`起動時に無条件で発生する既知の副作用であり、これが本当に
アンロックの直接原因なのか、単に無害な副産物なのかは依然未確定。**

**残る次回セッションでの候補**:
1. pluto_dvbのソース(`fmc_perfom_calibration`/`bandwidth_calibrating`という
   シンボルがバイナリ内に存在することを確認済み)が公開されていれば、
   周期的な再校正のトリガー条件を直接確認する。

### 実機の状態(このセッション終了時点)

- Plutoは`calib_mode=auto`・`ip:192.168.0.136`で正常動作確認済み。
- `~/gr-dvbs2rx`の`pl_frame_sync.cc`は`[unlockdbg]`にt_ms(絶対時刻)を追加した
  状態でビルド・インストール済み(一時計装、`fsdbg`同様に問題解決後に
  削除すること。`pi4/docs/patches/gr-dvbs2rx_pi4_bringup.patch`は
  未更新なので、次回セッションでこの追加分も含めてエクスポートし直すこと)。
- `pi4/rx/shonan_rx.py`のIIOバッファサイズ拡大(`0x40000`)はリポジトリに
  コミット済み。Pi実機側も同期済み。`--raw-iq-dump`オプション付きの
  一時コピー(`/tmp/shonan_rx_iqdump.py`)は削除済み・未コミット
  (再度波形観測する場合は本節の記述を参考に作り直すこと)。
- `shonan-gui.service`は通常稼働に復元済み。
- テスト用一時スクリプト・ログ・生IQダンプファイル(`/tmp/rf_test*`,
  `/tmp/rf_iqdump*`)は削除済み。

---

## ハードウェア構成

- Pi4 + PlutoSDR無印(Pluto+ではない)、F5OEO製DATVカスタムファームウェア(`datvplutofrm` v0.32-dirty)
- TX SMA出力 → 40dBアッテネータ → RX SMA入力 のケーブル自己ループバック
- 周波数: 437MHz(カスタムLO設定)、帯域幅1.2MHz、サンプルレート1.5Msps
- Mod-Cod: `QPSK-S_3/5`(実体はDVB-S2 Short FECFRAME、後述)
- 映像ソース: Logicool C920 PRO(USB UVCカメラ、`/dev/video0`)
- TX送信パワー: 0dB(最大出力、アッテネータ側で減衰)
- RXゲイン: 手動55dB固定(**AGC OFF必須**、後述)

## 再現・試験コマンド

```sh
# TX(GUI外、手動起動する場合)
ffmpeg -f v4l2 -i /dev/video0 -c:v libx264 -preset ultrafast -tune zerolatency \
  -b:v 1.5M -maxrate 1.5M -bufsize 1.5M -g 15 -pix_fmt yuv420p -f mpegts \
  -mpegts_flags +resend_headers - | \
  /home/pi/shonan-pi4/pi4/scripts/run_tx.sh --pluto-uri ip:192.168.2.1 \
  --lo-hz 437000000 --bandwidth-hz 1200000 --sample-rate-hz 1500000 \
  --mod-cod QPSK-S_3/5 --rf-port A_BALANCED --tx-power-db 0.0 --tmp-dir /tmp

# RX(GUI外、手動起動する場合。--agcは絶対に付けないこと、後述)
python3 ~/shonan-pi4/pi4/rx/shonan_rx.py --pluto-uri ip:192.168.2.1 \
  --lo-hz 437000000 --sample-rate-hz 1500000 --mod-cod QPSK-S_3/5 \
  --no-agc --gain-db 55 --output-fifo /tmp/rx.ts --status-interval-sec 1
```

ステータス行 `[shonan_rx] locked=... sof=... frame=... rejected=... freq_off=... packets=... errors=...`
で状態を確認する。

---

## 修正済みの実バグ

### 1. gr-dvbs2rxのビルド済み修正が一度もインストールされていなかった

`~/gr-dvbs2rx`(third-party、`igorauad/gr-dvbs2rx`のクローン)に、PLSフィルタ誤検出を直す
未コミットのソース修正が存在していたが、`sudo make install`が一度も実行されておらず、
システムにインストールされた`.so`は修正前のまま(ビルド時刻とインストール済み`.so`の
mtimeを比較して発覚)。`make install`を実行して解消。

**教訓: `~/gr-dvbs2rx/build`でビルド成功しても、`sudo make install`を忘れると
`/usr/local/lib/aarch64-linux-gnu/libgnuradio-dvbs2rx.so.*`は更新されない。**

### 2. AGC使用時にsymbol_sync_ccがSIGSEGV

Pluto内蔵AGC(`slow_attack`)使用時、ゲイン変動により`symbol_sync_cc`のタイミング
補間ループ(`polyphase_interpolator::operator()`、`loop()`内のW1/W2/d_jump計算)が
不安定化し、バッファ範囲外アクセスでクラッシュする。

**回避策(必須)**: RXは必ず`--no-agc --gain-db <値>`で起動すること。`--agc`は使わない。

根本修正として、`portsdown5-ipad`(同じユーザーの別プロジェクト、iOS版・同じ
gr-dvbs2rxライブラリ使用)の実機ブリングアップで見つかっていた修正パッチ
(`docs/patches/gr-dvbs2rx_ios_real_pluto_bringup.patch`)を`~/gr-dvbs2rx/lib/symbol_sync_cc_impl.cc`
に移植済み(`idx_subfilt`のクランプ、W1/W2の正値クランプ、`d_jump`の`[1,4*sps]`クランプ)。

### 3. PLSフィルタのしきい値が振幅非正規化のまま

`pl_frame_sync.cc`のSOF/PLSC相関に使う差分値`diff`が、AGC/ゲインの実スケールに
直接依存する未正規化の値のまま、振幅非依存であるべき固定しきい値
(`threshold_u`/`threshold_l`)と比較されていた。これも上記iOS版で解決済みの
問題で、同じ修正を移植:

- `diff`を単位振幅に正規化(`pl_frame_sync.cc`)
- found状態(ロック確認待ち)のゲート条件を`is_locked()`単体から`is_locked_or_almost()`
  (found or locked)に変更 — found状態のまま毎シンボル相関計算し続けていたバグ
- しきい値を`30/25`→`42/36`に引き上げ(`pl_frame_sync.h`)

移植前は誤検出が秒間数十万〜100万回のオーダーで発生していたが、この修正で
解消(正常な相関ピークのみが検出されるようになった)。

### 4. 【最重要・本セッションで新規発見】RXのPLS想定が実際のTX出力と不一致

`shonan_rx.py`は「Normal FECFRAME(64800bit)・パイロットなし」を前提に
`dvbs2rx.dvbs2_pls(mod, rate, "normal", False)`を呼んでいたが、実際のTX
(`aff3ct`の`DVBS2.hpp`、`N_ldpc=16200`)は**QPSK-S_3/5に対して常にShort
FECFRAME(16200bit)・パイロット付き**で送信する(`aff3ct`側にオン/オフの
選択肢は存在せず、コードレートによって固定)。

正しいPLS値は以下で確認済み:

```python
from gnuradio import dvbs2rx
target_pls = dvbs2rx.dvbs2_pls("QPSK", "3/5", "short", True)  # => 23
```

真のPLFRAME長は8370シンボル(RXが誤って想定していた32490ではない)。
この不一致のせいで、PL相関自体は強く成立する(相関値50台後半、理論最大値57に近い)
にもかかわらず、found→locked遷移に必要な「次のSOFがちょうど1フレーム後に来る」
という条件が絶対に成立せず、**一度も真のロックに到達できなかった**。

`shonan_rx.py`側の修正(コミット済み):
```python
framesize = dvbs2rx.FECFRAME_SHORT  # 旧: FECFRAME_NORMAL
target_pls = dvbs2rx.dvbs2_pls(pls_const_str, pls_code_str, "short", True)  # 旧: "normal", False
```

この修正により、`locked=True`が安定して継続し、`frame`カウンタが理論値に近い
速度(~85fps)で増加するようになった。**PLフレーム同期はこれで実用上完全に解決**。

### 5. TXのUSBカメラが物理的に故障していた

古いカメラ(`046d:0825`)が`ioctl(VIDIOC_DQBUF): No such device`で1フレームも
取得できず、TX入力映像がほぼ空(`throughput=0.07Mbps`程度)のまま、TXリング
バッファが慢性的に`starved=100%`になっていた。これがPLロックが数十〜百数十
フレームごとに一瞬外れる不安定性の直接原因だった(TXが実際に送信データを
欠落させていたため)。

**C920 PRO(`046d:08e5`)に交換して解決**。交換後は`starved=0%`が継続し、
RXのPLロックも(#4の修正と合わせて)ほぼ完全に安定した。

### 6. RXウォッチドッグの追加

`pi4/gui/backend.py`の`RxController`に、`frame`カウンタが8秒間進まなければ
RXプロセスを自動再起動するウォッチドッグを追加(shonan-android版
`RxController.kt`のロック状態ポーリングの考え方を参考にしつつ、あちらには
なかった「実際に再起動する」動作を追加。Android版はUIフラグ更新のみで
プロセス再起動はしない)。

---
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

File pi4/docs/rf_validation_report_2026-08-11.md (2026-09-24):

# Tanzawa Pi4 DVB-S2 RF送受信評価レポート

作成日: 2026-08-11  
対象: `kazushinjo/tanzawa-pi4` Pi4送受信GUI、PlutoSDR `v0.32-dirty`

## 1. 目的

Pi4でH.264/AACを生成し、PlutoSDRでDVB-S2変調した信号を、40 dB外部アッテネータを介して同一PlutoSDRで受信する。シンボルレート、FEC、パイロット、RXゲインを変更し、DVB-S2ロック条件と映像受信可否を確認する。

## 2. 構成

```text
Raspberry Pi 4 (H.264/AACエンコード)
  -> RTMP
PlutoSDR TX (DVB-S2変調、TX出力 0 dB)
  -> 40 dB外部アッテネータ
PlutoSDR RX
  -> IIO/IP
Raspberry Pi 4 (dvbs2-rx、TS受信、映像デコード)
```

RF周波数は437 MHz。変調はQPSK、Normal FECFRAME、roll-off 0.35、2 samples/symbol、RXバッファ32768 samplesとした。

映像条件はH.264、1280×720、30 fps、400 kbps、GOP 30。音声はAAC、44.1 kHz、mono、Pi4入力16 kbps、Pluto側出力32 kbpsとした。

## 3. Pi4プログラムの修正内容

- 0.5 Msym/sを含むRXを2 samples/symbolへ統一
- Pluto RXバッファを32768 samplesに設定
- RXパイロット判定をAUTOに設定
- TSバイト数ではなく`dvbs2-rx`の`Lock=True/False`をGUIへ反映
- IIOタイムアウトをGUIログへ転送
- TSデータと診断ログを別FDへ分離
- 不足していた`udp_relay.py`をPi4へ配置
- H.264 GOPを30へ変更
- TX出力の既定値と保存設定を0 dBへ変更

Python構文確認、シェル構文確認、既存単体テスト5件はすべて成功した。

## 4. IIOタイムアウト調査

初期試験では、受信開始約3秒後に次のエラーが発生した。

```text
Unable to refill buffer: Connection timed out (110)
```

Pi4 GUI、`watchdog_rx.sh`、`dvbs2-rx`、Ethernet転送を外し、Pluto本体上で`iio_readdev`を実行しても0 byteで同じタイムアウトが再現した。このときRX DMA割り込みも増加しなかった。

Plutoを再起動した後、Pluto本体で8秒間に260,902,912 byteのIQデータを取得できた。以後の基準RF試験ではIIOタイムアウトは解消した。このことから、当該IIO障害はPluto内部RX DMAの一時的な停止・固着と判断した。

IIOエラーが発生した測定値はRFのNO LOCKとして扱わず、Pluto再起動後に再測定する必要がある。

## 5. 基準RF・映像試験

| 項目 | 結果 |
|---|---:|
| シンボルレート | 0.5 Msym/s |
| FEC | 1/2 |
| TXパイロット | OFF |
| RXパイロット | AUTO |
| TX出力 | 0 dB |
| RX | `slow_attack` AGC |
| DVB-S2ロック | 成功 |
| SNR | 約13.9 dB |
| FER / PER | 0 / 0 |
| TSサイズ | 約3.67 MB |
| TS時間 | 約61.97秒 |
| 映像 | H.264 1280×720、30 fps |
| デコードフレーム数 | 1,831 |

受信開始がH.264 GOP途中だったため、冒頭にPPS未取得と一部マクロブロックエラーが記録されたが、次のキーフレーム以降はデコードできた。

## 6. 72条件試験

次の組み合わせを各条件60秒間測定した。

```text
4 symbol rates × 3 FEC × 2 pilot modes × 3 manual RX gains = 72条件
```

- シンボルレート: 0.5、1.0、1.5、2.0 Msym/s
- FEC: 1/2、3/5、2/3
- TXパイロット: OFF、ON
- RXゲイン: manual 40、50、60 dB

合格条件は、複数回の`Lock=True`、TSデータ増加、IIOエラーなしとした。正常にロックした条件は、60回のログ取得中59回で`Lock=True`を維持した。

### 6.1 シンボルレート別集計

| シンボルレート | PASS | NO LOCK | 備考 |
|---:|---:|---:|---|
| 0.5 Msym/s | 18 | 0 | 全条件成功、最大SNR約13.99 dB |
| 1.0 Msym/s | 18 | 0 | 全条件成功、最大SNR約18.02 dB |
| 1.5 Msym/s | 0 | 18 | 全条件で60/60回Lock=False |
| 2.0 Msym/s | 0 | 18 | 全条件で60/60回Lock=False |
| 合計 | 36 | 36 | 72条件すべて確定 |

### 6.2 0.5～2.0 Msym/s全条件一覧

記号: `PASS`=60秒間の継続ロックとTS受信を確認、`NO LOCK`=60回すべてLock=False

| FEC | Pilot | RX gain | 0.5M | 1.0M | 1.5M | 2.0M |
|---|---|---:|---:|---:|---:|---:|
| 1/2 | OFF | 40 dB | PASS | PASS | NO LOCK | NO LOCK |
| 1/2 | OFF | 50 dB | PASS | PASS | NO LOCK | NO LOCK |
| 1/2 | OFF | 60 dB | PASS | PASS | NO LOCK | NO LOCK |
| 1/2 | ON | 40 dB | PASS | PASS | NO LOCK | NO LOCK |
| 1/2 | ON | 50 dB | PASS | PASS | NO LOCK | NO LOCK |
| 1/2 | ON | 60 dB | PASS | PASS | NO LOCK | NO LOCK |
| 3/5 | OFF | 40 dB | PASS | PASS | NO LOCK | NO LOCK |
| 3/5 | OFF | 50 dB | PASS | PASS | NO LOCK | NO LOCK |
| 3/5 | OFF | 60 dB | PASS | PASS | NO LOCK | NO LOCK |
| 3/5 | ON | 40 dB | PASS | PASS | NO LOCK | NO LOCK |
| 3/5 | ON | 50 dB | PASS | PASS | NO LOCK | NO LOCK |
| 3/5 | ON | 60 dB | PASS | PASS | NO LOCK | NO LOCK |
| 2/3 | OFF | 40 dB | PASS | PASS | NO LOCK | NO LOCK |
| 2/3 | OFF | 50 dB | PASS | PASS | NO LOCK | NO LOCK |
| 2/3 | OFF | 60 dB | PASS | PASS | NO LOCK | NO LOCK |
| 2/3 | ON | 40 dB | PASS | PASS | NO LOCK | NO LOCK |
| 2/3 | ON | 50 dB | PASS | PASS | NO LOCK | NO LOCK |
| 2/3 | ON | 60 dB | PASS | PASS | NO LOCK | NO LOCK |

### 6.3 0.5 Msym/s再測定結果

初回にIIOエラー、パイロット不一致、またはロックログ未取得だった8条件を、IIOプリフライトと実パイロット確認後に再測定した。全条件が1回目の再測定でPASSした。

| 元条件 | FEC | Pilot | Gain | Lock | 最大SNR | TS byte | 結果 |
|---:|---|---|---:|---:|---:|---:|---|
| 1 | 1/2 | OFF | 40 | 59/60 | 13.84 dB | 3,574,068 | PASS |
| 2 | 1/2 | OFF | 50 | 59/60 | 13.98 dB | 3,594,184 | PASS |
| 3 | 1/2 | OFF | 60 | 59/60 | 13.97 dB | 3,598,320 | PASS |
| 4 | 1/2 | ON | 40 | 59/60 | 13.97 dB | 3,509,772 | PASS |
| 5 | 1/2 | ON | 50 | 59/60 | 13.99 dB | 3,533,836 | PASS |
| 6 | 1/2 | ON | 60 | 59/60 | 13.98 dB | 3,529,888 | PASS |
| 7 | 3/5 | OFF | 40 | 59/60 | 13.99 dB | 4,290,160 | PASS |
| 8 | 3/5 | OFF | 50 | 59/60 | 13.97 dB | 4,319,112 | PASS |

### 6.4 1.0 Msym/s結果

FEC 1/2・3/5・2/3、パイロットON/OFF、RXゲイン40/50/60 dBの18条件すべてでPASSした。

- Lock: 各条件59/60
- 最大SNR: 17.47～18.02 dB
- TSサイズ: 約7.04～9.62 MB/60秒
- PER: 多くの条件で0、一部最大約2.2e-4

今回の72条件範囲では、1.0 Msym/sが最も広い条件で安定してロックした。

### 6.5 1.5および2.0 Msym/s結果

1.5 Msym/sと2.0 Msym/sは、それぞれ18条件すべてで60回のログが取得されたが、全回`Lock=False`、FECFRAME 0、TS 0 byteだった。RXゲイン、FEC、パイロットのいずれを変更してもロックしなかった。

これはIIOタイムアウトではなく、IQ受信は動作している状態でのDVB-S2 NO LOCKである。高シンボルレート時の送受信サンプルレート、Pluto FIR/帯域、`dvbs2-rx`同期条件を追加調査する必要がある。

## 7. 結論

1. Pluto RX DMA固着を再起動で解消後、0.5 Msym/s・QPSK 1/2・TX 0 dB・40 dB外部アッテネータでRFロックし、HD映像1,831フレームをデコードできた。
2. 1.0 Msym/sはFEC、パイロット、RXゲインの全18条件で安定してロックした。
3. 0.5 Msym/sは再測定を含む全18条件で安定してロックした。
4. 1.5および2.0 Msym/sは全36条件で正常な60秒測定を行ったが、ロックしなかった。
5. 最終集計はPASS 36、NO LOCK 36で、72条件すべて確定した。

## 8. 追加調査・対策結果

### 8.1 1.5/2.0 Msym/s受信設定

| Symbol rate | RX実サンプルレート | RX RF帯域 | FIR | 受信スペクトラム(-30 dB概算) | 結果 |
|---:|---:|---:|---|---:|---|
| 1.5 Msym/s | 3.0 MS/s | 2.025 MHz | ON | 約3.0 MHz | NO LOCK |
| 2.0 Msym/s | 4.0 MS/s | 2.700 MHz | ON | 約4.0 MHz | NO LOCK |

指定値はPlutoへ正しく反映され、IQも各4,194,304 byte取得できた。いずれもフレーム同期候補には一時到達するが同期を維持できず、スペクトラムはほぼNyquist幅を占有した。したがって未設定やIIO停止ではなく、高レート時の波形品質または同期処理が今後の調査対象である。

### 8.2 IIOプリフライト

GUIの受信開始前に短いIIO DMA読出しを追加した。4,096 byteを6秒以内に取得できない場合は受信処理を開始せず、`RF NO LOCK`ではなくPluto RX DMA/IIO異常として通知する。実機では4,096 byte取得に成功した。

### 8.3 H.264映像表示判定

MPEG-TS内のH.264 Annex-B NALを監視し、SPS (NAL 7) とPPS (NAL 8) の受信後、最初のIDR (NAL 5)を検出した時点で`video_ready=1`をGUIへ通知するよう変更した。RFループ試験（0.5 Msym/s、QPSK 1/2、pilot OFF、RX gain 40 dB）では、受信開始約2秒後にSPS/PPS/IDRを検出し、DVB-S2 Lock=True、20秒で約1.02 MBのTS受信を確認した。

## 9. 生データ

- 72条件初回結果: Pi4 `/home/pi/rf_sweep_72_results.csv`
- 条件1・6・8再測定: Pi4 `/home/pi/rf_retest_1_6_8.csv`
- 条件2・3・4・5・7再測定: Pi4 `/home/pi/rf_retest_remaining5.csv`

## 10. 無印ADALM-Pluto Rev.C 72条件再試験

### 10.1 試験対象

- 機種: 無印ADALM-Pluto Rev.C (Z7010/AD9363、IIO稼働時AD9364表示)
- IPアドレス: 192.168.0.136
- RF接続: TX - 40 dB外部アッテネータ - RX
- TX出力: 0 dB
- 周波数: 437 MHz
- 判定時間: 各条件60秒（送信安定待ち10秒を別途確保）

### 10.2 再試験結果

| シンボルレート | PASS | NO LOCK | IIO ERROR | 結果 |
|---:|---:|---:|---:|---|
| 0.5 Msym/s | 18 | 0 | 0 | 全条件PASS |
| 1.0 Msym/s | 18 | 0 | 0 | 全条件PASS |
| 1.5 Msym/s | 0 | 18 | 0 | 全条件NO LOCK |
| 2.0 Msym/s | 0 | 18 | 0 | 全条件NO LOCK |
| 合計 | 36 | 36 | 0 | 72条件確定 |

FEC 1/2・3/5・2/3、Pilot ON/OFF、RX gain 40/50/60 dBを組み合わせた72条件をすべて再試験した。各条件でPilot要求値と実際の`pluto_dvb`設定が一致し、不一致は0件だった。0.5/1.0 Msym/sのPASS条件では継続した`Lock=True`とTS byte増加を確認した。1.5/2.0 Msym/sは全判定で`Lock=False`、TS 0 byteだったが、IIOプリフライト異常は発生していない。

### 10.3 再試験データ

- CSV: `pi4/docs/rf_sweep_72_rerun_2026-08-11.csv`
- 行数: 72、条件番号: 1～72（一意）
- 最終集計: PASS 36、NO LOCK 36、IIO ERROR 0、Pilot不一致 0

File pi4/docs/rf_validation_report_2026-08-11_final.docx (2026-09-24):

RF VALIDATION REPORT

Tanzawa Pi5 DVB-S2
RF送受信評価レポート

Pi5 H.264/AAC送信・PlutoSDR RFループバック評価

作成日 2026年8月11日

対象 kazushinjo/tanzawa-pi5 | PlutoSDR v0.32-dirty

作成日: 2026-08-11

対象: kazushinjo/tanzawa-pi5 Pi5送受信GUI、PlutoSDR v0.32-dirty

# 1. 目的

Pi5でH.264/AACを生成し、PlutoSDRでDVB-S2変調した信号を、40 dB外部アッテネータを介して同一PlutoSDRで受信する。シンボルレート、FEC、パイロット、RXゲインを変更し、DVB-S2ロック条件と映像受信可否を確認する。

# 2. 構成

Raspberry Pi 5 (H.264/AACエンコード)
-> RTMP
PlutoSDR TX (DVB-S2変調、TX出力 0 dB)
-> 40 dB外部アッテネータ
PlutoSDR RX
-> IIO/IP
Raspberry Pi 5 (dvbs2-rx、TS受信、映像デコード)

RF周波数は437 MHz。変調はQPSK、Normal FECFRAME、roll-off 0.35、2 samples/symbol、RXバッファ32768 samplesとした。

映像条件はH.264、1280×720、30 fps、400 kbps、GOP 30。音声はAAC、44.1 kHz、mono、Pi5入力16 kbps、Pluto側出力32 kbpsとした。

# 3. Pi5プログラムの修正内容

- 0.5 Msym/sを含むRXを2 samples/symbolへ統一
- Pluto RXバッファを32768 samplesに設定
- RXパイロット判定をAUTOに設定
- TSバイト数ではなくdvbs2-rxのLock=True/FalseをGUIへ反映
- IIOタイムアウトをGUIログへ転送
- TSデータと診断ログを別FDへ分離
- 不足していたudp_relay.pyをPi5へ配置
- H.264 GOPを30へ変更
- TX出力の既定値と保存設定を0 dBへ変更

Python構文確認、シェル構文確認、既存単体テスト5件はすべて成功した。

# 4. IIOタイムアウト調査

初期試験では、受信開始約3秒後に次のエラーが発生した。

Unable to refill buffer: Connection timed out (110)

Pi5 GUI、watchdog_rx.sh、dvbs2-rx、Ethernet転送を外し、Pluto本体上でiio_readdevを実行しても0 byteで同じタイムアウトが再現した。このときRX DMA割り込みも増加しなかった。

Plutoを再起動した後、Pluto本体で8秒間に260,902,912 byteのIQデータを取得できた。以後の基準RF試験ではIIOタイムアウトは解消した。このことから、当該IIO障害はPluto内部RX DMAの一時的な停止・固着と判断した。

IIOエラーが発生した測定値はRFのNO LOCKとして扱わず、Pluto再起動後に再測定する必要がある。

# 5. 基準RF・映像試験

項目 | 結果
シンボルレート | 0.5 Msym/s
FEC | 1/2
TXパイロット | OFF
RXパイロット | AUTO
TX出力 | 0 dB
RX | `slow_attack` AGC
DVB-S2ロック | 成功
SNR | 約13.9 dB
FER / PER | 0 / 0
TSサイズ | 約3.67 MB
TS時間 | 約61.97秒
映像 | H.264 1280×720、30 fps
デコードフレーム数 | 1,831

受信開始がH.264 GOP途中だったため、冒頭にPPS未取得と一部マクロブロックエラーが記録されたが、次のキーフレーム以降はデコードできた。

# 6. 72条件試験

次の組み合わせを各条件60秒間測定した。

4 symbol rates × 3 FEC × 2 pilot modes × 3 manual RX gains = 72条件

- シンボルレート: 0.5、1.0、1.5、2.0 Msym/s
- FEC: 1/2、3/5、2/3
- TXパイロット: OFF、ON
- RXゲイン: manual 40、50、60 dB

合格条件は、複数回のLock=True、TSデータ増加、IIOエラーなしとした。正常にロックした条件は、60回のログ取得中59回でLock=Trueを維持した。

## 6.1 シンボルレート別集計

シンボルレート | PASS | NO LOCK | 備考
0.5 Msym/s | 18 | 0 | 全条件成功、最大SNR約13.99 dB
1.0 Msym/s | 18 | 0 | 全条件成功、最大SNR約18.02 dB
1.5 Msym/s | 0 | 18 | 全条件で60/60回Lock=False
2.0 Msym/s | 0 | 18 | 全条件で60/60回Lock=False
合計 | 36 | 36 | 72条件すべて確定

## 6.2 0.5～2.0 Msym/s全条件一覧

記号: PASS=60秒間の継続ロックとTS受信を確認、NO LOCK=60回すべてLock=False

FEC | Pilot | RX gain | 0.5M | 1.0M | 1.5M | 2.0M
1/2 | OFF | 40 dB | PASS | PASS | NO LOCK | NO LOCK
1/2 | OFF | 50 dB | PASS | PASS | NO LOCK | NO LOCK
1/2 | OFF | 60 dB | PASS | PASS | NO LOCK | NO LOCK
1/2 | ON | 40 dB | PASS | PASS | NO LOCK | NO LOCK
1/2 | ON | 50 dB | PASS | PASS | NO LOCK | NO LOCK
1/2 | ON | 60 dB | PASS | PASS | NO LOCK | NO LOCK
3/5 | OFF | 40 dB | PASS | PASS | NO LOCK | NO LOCK
3/5 | OFF | 50 dB | PASS | PASS | NO LOCK | NO LOCK
3/5 | OFF | 60 dB | PASS | PASS | NO LOCK | NO LOCK
3/5 | ON | 40 dB | PASS | PASS | NO LOCK | NO LOCK
3/5 | ON | 50 dB | PASS | PASS | NO LOCK | NO LOCK
3/5 | ON | 60 dB | PASS | PASS | NO LOCK | NO LOCK
2/3 | OFF | 40 dB | PASS | PASS | NO LOCK | NO LOCK
2/3 | OFF | 50 dB | PASS | PASS | NO LOCK | NO LOCK
2/3 | OFF | 60 dB | PASS | PASS | NO LOCK | NO LOCK
2/3 | ON | 40 dB | PASS | PASS | NO LOCK | NO LOCK
2/3 | ON | 50 dB | PASS | PASS | NO LOCK | NO LOCK
2/3 | ON | 60 dB | PASS | PASS | NO LOCK | NO LOCK

## 6.3 0.5 Msym/s再測定結果

初回にIIOエラー、パイロット不一致、またはロックログ未取得だった8条件を、IIOプリフライトと実パイロット確認後に再測定した。全条件が1回目の再測定でPASSした。

元条件 | FEC | Pilot | Gain | Lock | 最大SNR | TS byte | 結果
1 | 1/2 | OFF | 40 | 59/60 | 13.84 dB | 3,574,068 | PASS
2 | 1/2 | OFF | 50 | 59/60 | 13.98 dB | 3,594,184 | PASS
3 | 1/2 | OFF | 60 | 59/60 | 13.97 dB | 3,598,320 | PASS
4 | 1/2 | ON | 40 | 59/60 | 13.97 dB | 3,509,772 | PASS
5 | 1/2 | ON | 50 | 59/60 | 13.99 dB | 3,533,836 | PASS
6 | 1/2 | ON | 60 | 59/60 | 13.98 dB | 3,529,888 | PASS
7 | 3/5 | OFF | 40 | 59/60 | 13.99 dB | 4,290,160 | PASS
8 | 3/5 | OFF | 50 | 59/60 | 13.97 dB | 4,319,112 | PASS

## 6.4 1.0 Msym/s結果

FEC 1/2・3/5・2/3、パイロットON/OFF、RXゲイン40/50/60 dBの18条件すべてでPASSした。

- Lock: 各条件59/60
- 最大SNR: 17.47～18.02 dB
- TSサイズ: 約7.04～9.62 MB/60秒
- PER: 多くの条件で0、一部最大約2.2e-4

今回の72条件範囲では、1.0 Msym/sが最も広い条件で安定してロックした。

## 6.5 1.5および2.0 Msym/s結果

1.5 Msym/sと2.0 Msym/sは、それぞれ18条件すべてで60回のログが取得されたが、全回Lock=False、FECFRAME 0、TS 0 byteだった。RXゲイン、FEC、パイロットのいずれを変更してもロックしなかった。

これはIIOタイムアウトではなく、IQ受信は動作している状態でのDVB-S2 NO LOCKである。高シンボルレート時の送受信サンプルレート、Pluto FIR/帯域、dvbs2-rx同期条件を追加調査する必要がある。

# 7. 結論

1. Pluto RX DMA固着を再起動で解消後、0.5 Msym/s・QPSK 1/2・TX 0 dB・40 dB外部アッテネータでRFロックし、HD映像1,831フレームをデコードできた。

2. 1.0 Msym/sはFEC、パイロット、RXゲインの全18条件で安定してロックした。

3. 0.5 Msym/sは再測定を含む全18条件で安定してロックした。

4. 1.5および2.0 Msym/sは全36条件で正常な60秒測定を行ったが、ロックしなかった。

5. 最終集計はPASS 36、NO LOCK 36で、72条件すべて確定した。

# 8. 追加調査・対策結果

- 1.5/2.0 Msym/sの実サンプルレート、RF帯域、FIR設定、受信スペクトラムを確認済み（詳細は10章）。
- GUI受信開始時の短いIIOプリフライトを実装済み。RX DMA固着をRF NO LOCKと区別する。
- H.264のSPS/PPS受信後、最初のIDRフレーム検出以降を映像表示可能と判定する処理を実装・実機確認済み。

# 9. 生データ

- 72条件初回結果: Pi5 /home/pi/rf_sweep_72_results.csv
- 条件1・6・8再測定: Pi5 /home/pi/rf_retest_1_6_8.csv
- 条件2・3・4・5・7再測定: Pi5 /home/pi/rf_retest_remaining5.csv

# 10. 追加調査・実装確認

## 10.1 1.5/2.0 Msym/s受信設定

Symbol rate | RX sample rate | RX RF BW | FIR | Spectrum (-30 dB) | Result
1.5 Msym/s | 3.0 MS/s | 2.025 MHz | ON | 約3.0 MHz | NO LOCK
2.0 Msym/s | 4.0 MS/s | 2.700 MHz | ON | 約4.0 MHz | NO LOCK

指定値はPlutoへ正しく反映され、IQも各4,194,304 byte取得できた。いずれもフレーム同期候補には一時到達するが同期を維持できず、スペクトラムはほぼNyquist幅を占有した。未設定やIIO停止ではなく、高レート時の波形品質または同期処理が今後の調査対象である。

## 10.2 IIOプリフライト

GUIの受信開始前に短いIIO DMA読出しを追加した。4,096 byteを6秒以内に取得できない場合は受信処理を開始せず、RF NO LOCKではなくPluto RX DMA/IIO異常として通知する。実機では4,096 byte取得に成功した。

## 10.3 H.264映像表示判定

MPEG-TS内のH.264 Annex-B NALを監視し、SPS (NAL 7) とPPS (NAL 8) の受信後、最初のIDR (NAL 5)を検出した時点でvideo_ready=1をGUIへ通知するよう変更した。RFループ試験（0.5 Msym/s、QPSK 1/2、pilot OFF、RX gain 40 dB）では、受信開始約2秒後にSPS/PPS/IDRを検出し、DVB-S2 Lock=True、20秒で約1.02 MBのTS受信を確認した。

# 11. 無印ADALM-Pluto Rev.C 72条件再試験

## 11.1 試験対象

- 機種: 無印ADALM-Pluto Rev.C (Z7010/AD9363、IIO稼働時AD9364表示)
- IPアドレス: 192.168.0.136
- RF接続: TX - 40 dB外部アッテネータ - RX、TX出力: 0 dB、周波数: 437 MHz
- 判定時間: 各条件60秒（送信安定待ち10秒を別途確保）

## 11.2 再試験結果

Symbol rate | PASS | NO LOCK | IIO ERROR | Result
0.5 Msym/s | 18 | 0 | 0 | 全条件PASS
1.0 Msym/s | 18 | 0 | 0 | 全条件PASS
1.5 Msym/s | 0 | 18 | 0 | 全条件NO LOCK
2.0 Msym/s | 0 | 18 | 0 | 全条件NO LOCK
合計 | 36 | 36 | 0 | 72条件確定

FEC 1/2・3/5・2/3、Pilot ON/OFF、RX gain 40/50/60 dBを組み合わせた72条件をすべて再試験した。各条件でPilot要求値と実際のpluto_dvb設定が一致し、不一致は0件だった。0.5/1.0 Msym/sのPASS条件では継続したLock=TrueとTS byte増加を確認した。1.5/2.0 Msym/sは全判定でLock=False、TS 0 byteだったが、IIOプリフライト異常は発生していない。

## 11.3 再試験データ

CSV: pi5/docs/rf_sweep_72_rerun_2026-08-11.csv

72行、条件番号1～72（一意）。PASS 36、NO LOCK 36、IIO ERROR 0、Pilot不一致 0。

TANZAWA PI5 | DVB-S2 RF VALIDATION

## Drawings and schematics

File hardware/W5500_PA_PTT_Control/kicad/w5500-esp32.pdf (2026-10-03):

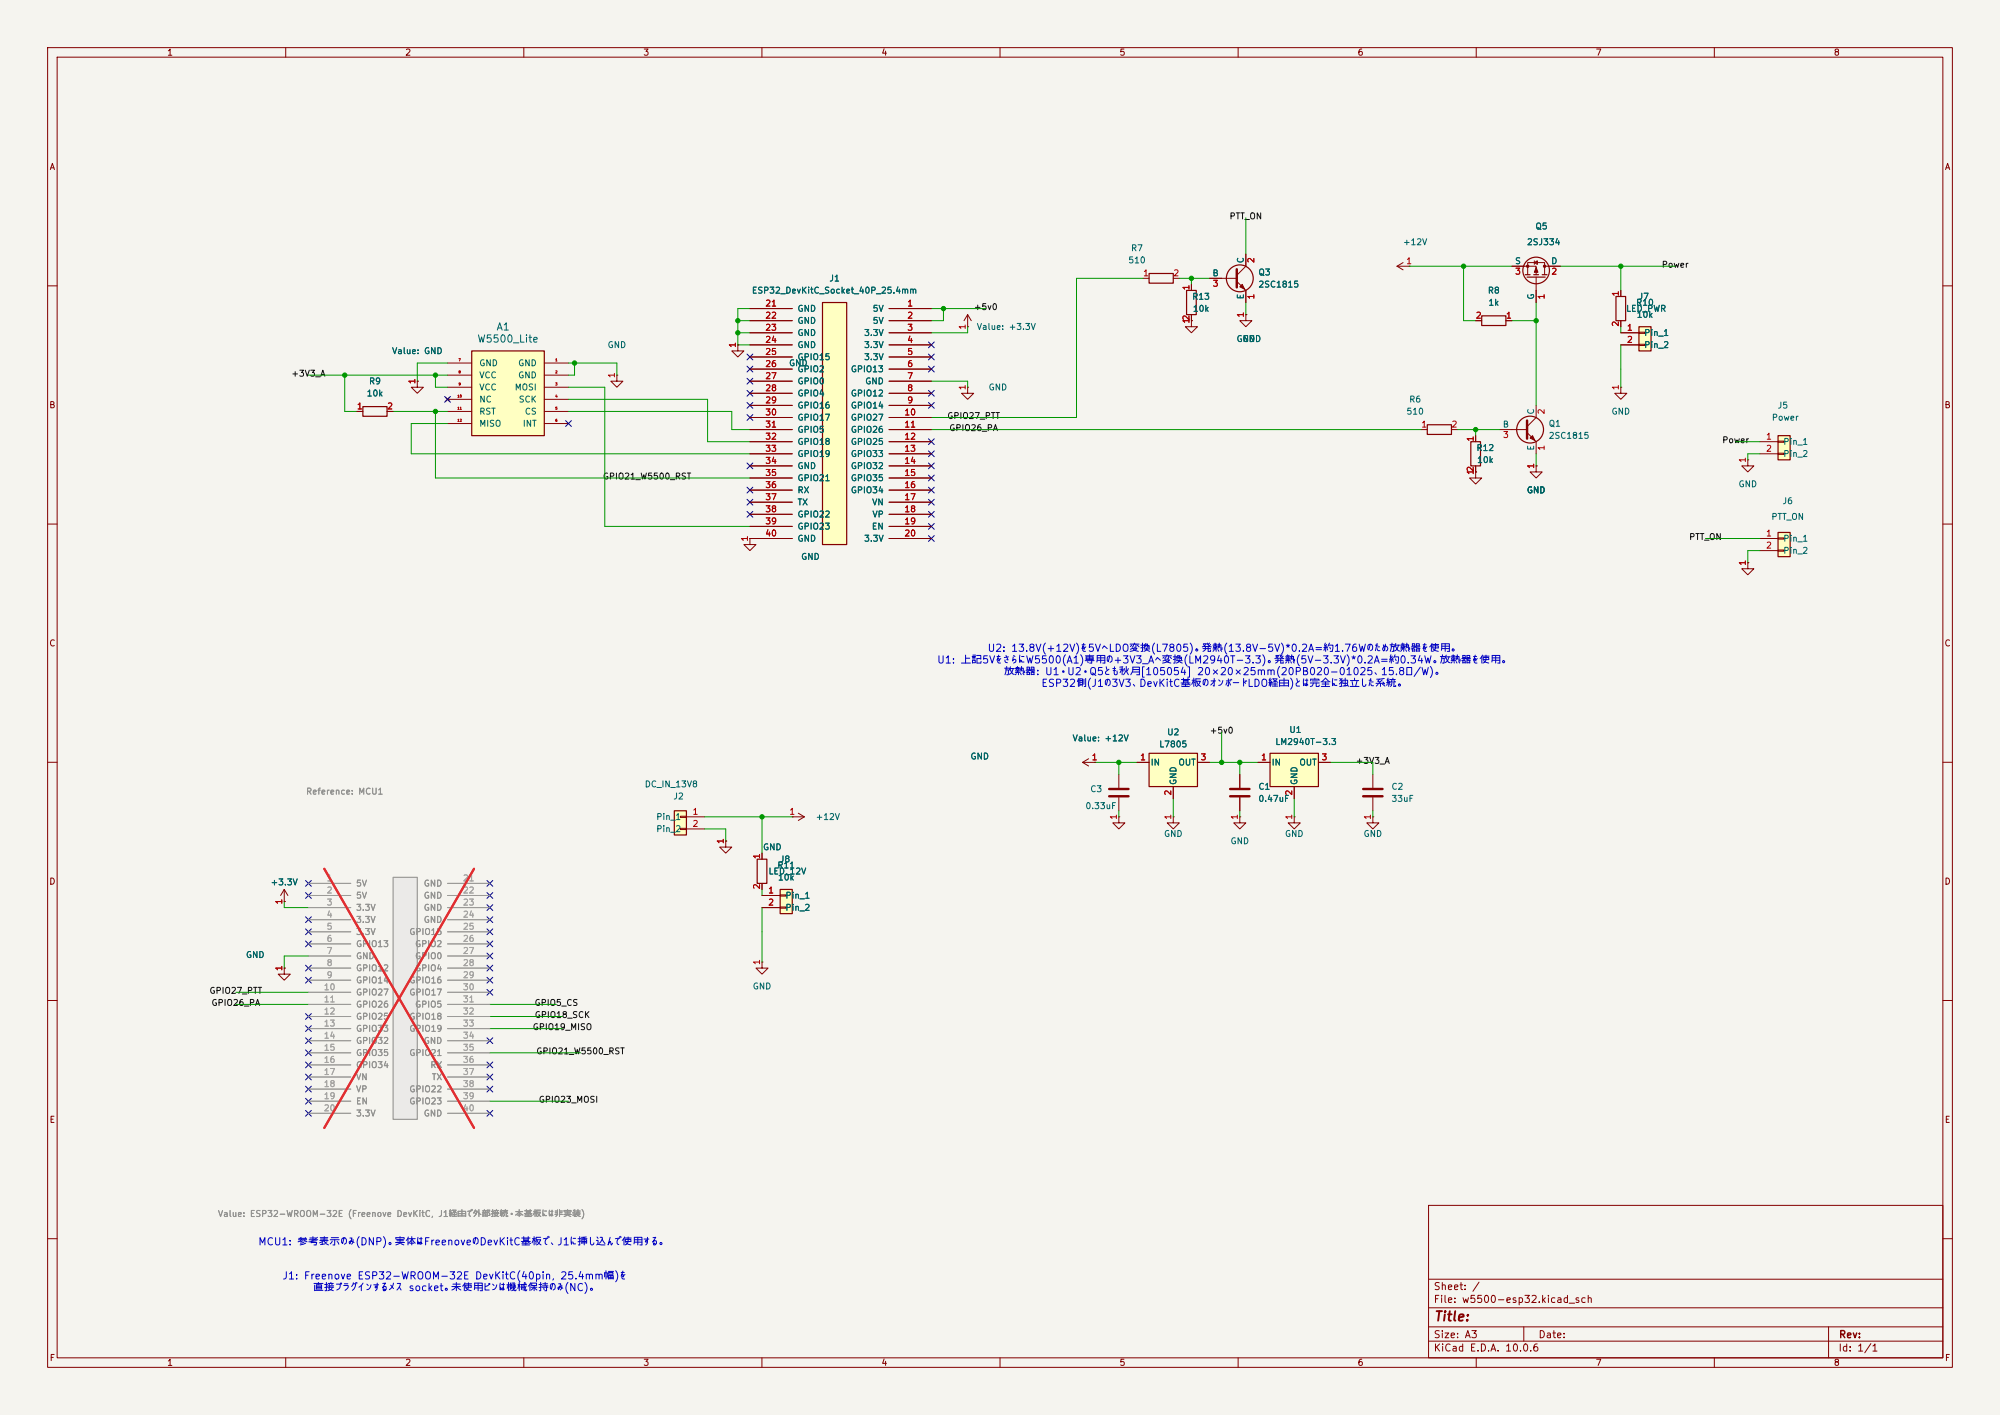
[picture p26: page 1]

U1: 上記5VをさらにW5500(A1)専用の+3V3_Aへ変換(LM2940T-3.3)。発熱(5V-3.3V)*0.2A=約0.34W。放熱器を使用。 放熱器: U1・U2・Q5とも秋月[105054] 20×20×25mm(20PB020-01025、15.8℃/W)。

Value: ESP32-WROOM-32E (Freenove DevKitC, J1経由で外部接続・本基板には非実装) 5V 1
Value: ESP32-WROOM-32E (Freenove DevKitC, J1経由で外部接続・本基板には非実装) 1 +3.3V

J1: Freenove ESP32-WROOM-32E DevKitC(40pin, 25.4mm幅)を 直接プラグインするメス socket。未使用ピンは機械保持のみ(NC)。

Size: A3 | Rev: | F Date:
KiCad E.D.A. 10.0.6 | Id: 1/1

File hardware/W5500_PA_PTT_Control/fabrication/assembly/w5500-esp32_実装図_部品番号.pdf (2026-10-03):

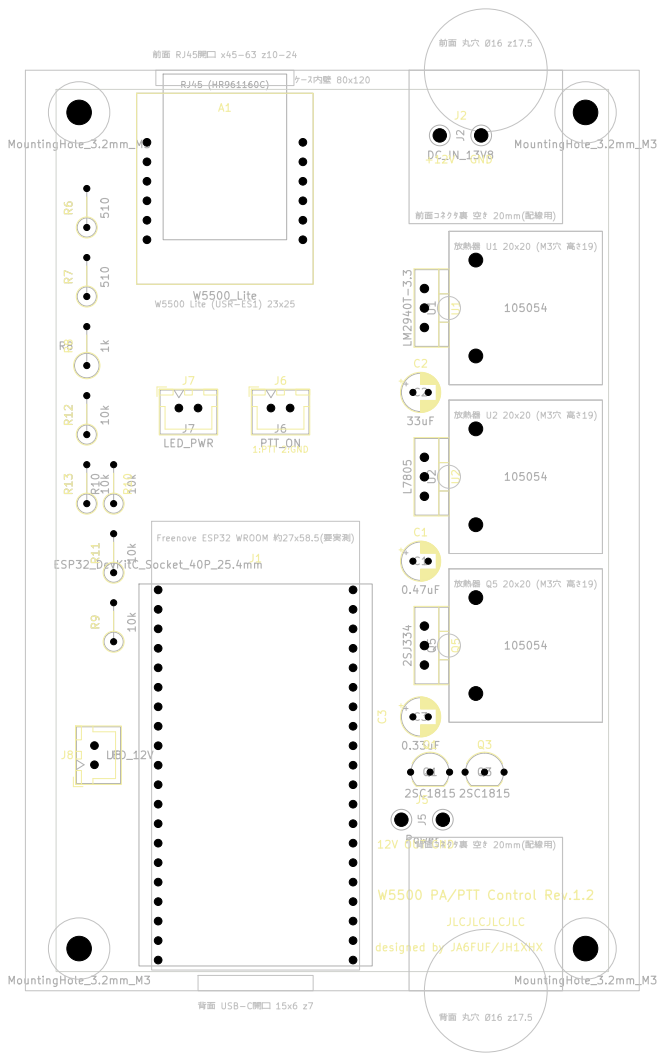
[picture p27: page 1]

Freenove ESP32 WROOM 約27x58.5(要実測) 背面 USB-C開口 15x6 z7

J2 前面コネクタ裏 空き 20mm(配線用) 背面コネクタ裏 空き 20mm(配線用)
+12V GND
放熱器 U1 20x20 (M3穴 高さ19) 放熱器 U2 20x20 (M3穴 高さ19) 放熱器 Q5 20x20 (M3穴 高さ19)

JLCJLCJLCJLC W5500 PA/PTT Control Rev.1.2

Size: A4 | Rev:
KiCad E.D.A. 10.0.6 | Id: 1/1

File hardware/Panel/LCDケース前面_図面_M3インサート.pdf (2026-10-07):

# LCDケース 図面（ベゼル縁15mm・裏蓋・1mmパネル）

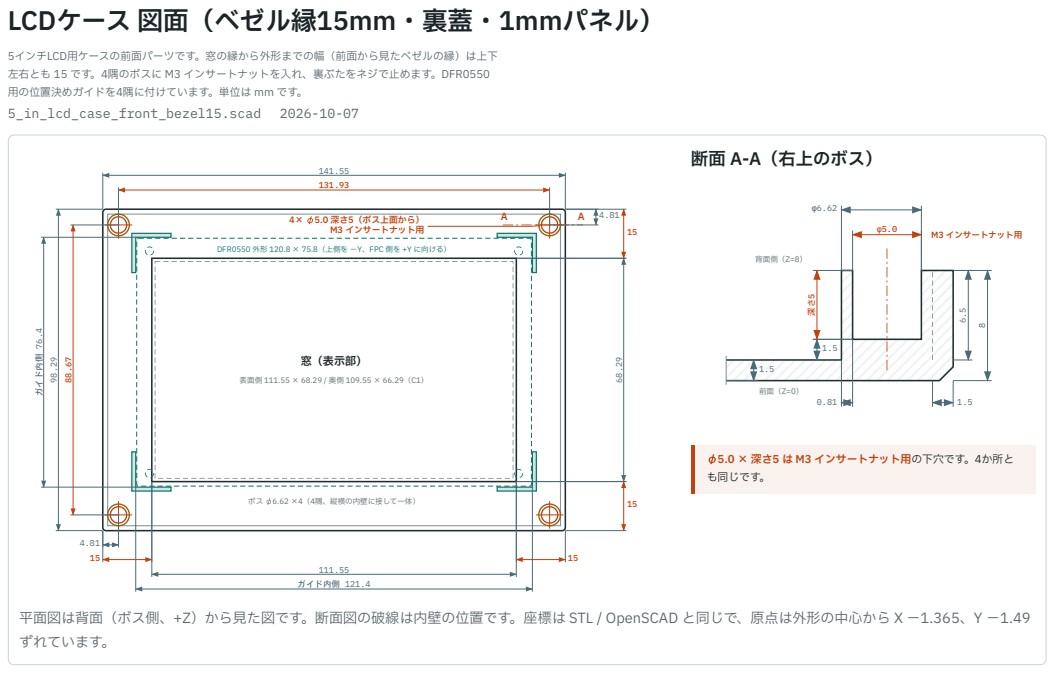
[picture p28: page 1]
窓（表示部）; 表面側 111.55 × 68.29 / 奥側 109.55 × 66.29（C1）; 4× φ5.0 深さ5（ボス上面から） M3 インサートナット用; ボス φ6.62 ×4（4隅、縦横の内壁に接して一体）; ガイド内側 121.4; イド内; 断面 A-A（右上のボス）; M3 インサートナット用; 背面側（Z=8）; φ5.0 × 深さ5 は M3 インサートナット用の下穴です。4か所と も同じです。

5インチLCD用ケースの前面パーツです。窓の縁から外形までの幅（前面から見たベゼルの縁）は上下
左右とも 15 です。4隅のボスに M3 インサートナットを入れ、裏ぶたをネジで止めます。DFR0550
用の位置決めガイドを4隅に付けています。単位は mm です。
5_in_lcd_case_front_bezel15.scad 2026-10-07

DFR0550 外形 120.8 × 75.8（上側を −Y、FPC 側を +Y に向ける）

平面図は背面（ボス側、+Z）から見た図です。断面図の破線は内壁の位置です。座標は STL / OpenSCAD と同じで、原点は外形の中心から X −1.365、Y −1.49
ずれています。

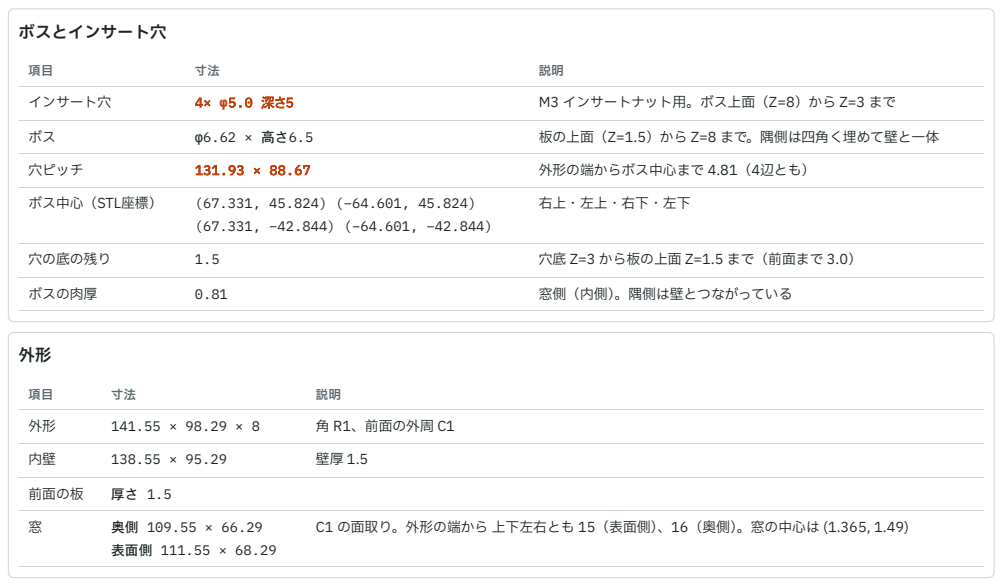
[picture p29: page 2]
ボスとインサート穴; インサート穴; M3 インサートナット用。ボス上面（Z=8）から Z=3 まで; 板の上面（Z=1.5）から Z=8 まで。隅側は四角く埋めて壁と一体; 穴ピッチ; 外形の端からボス中心まで 4.81（4辺とも）; ボス中心（STL座標）; 穴の底の残り; 穴底 Z=3 から板の上面 Z=1.5 まで（前面まで 3.0）; ボスの肉厚; 窓側（内側）。隅側は壁とつながっている; 角 R1、前面の外周 C1; 前面の板; 表面側 111.55 × 68.29

C1 の面取り。外形の端から 上下左右とも 15（表面側）、16（奥側）。窓の中心は (1.365, 1.49)

### DFR0550 位置決めガイド

DFRobot DFR0550（5インチ DSI タッチスクリーン）を窓に合わせて置くための L 字のガイドです。DFR0550 の取付穴（113 × 68、M2.5）は表側が液晶で覆われ、片側の2つは表示領域にかかるため、パネ ルには穴をあけていません。取付穴は裏側の支柱から使います。

項目 | 寸法 | 説明
ガイド | L字 ×4 腕12 / 厚さ1.2 / 高さ4 | DFR0550 の4隅。板の上面（Z=1.5）から Z=5.5 まで。液晶部の厚さ 5.7 より低い
ガイドの内側 | 121.4 × 76.4 | X −59.335 〜 62.065、Y −34.35 〜 42.05。DFR0550 外形 120.8 × 75.8 に片側 0.3 のすき間
DFR0550 の中心 | (1.365, 3.85) | 取付穴 113 × 68 の中心。表示領域 108 × 64.8 が窓の中央に来る（余白 約0.75）
向き | 上側 → −Y | 表示領域の上の余白が狭い側（3.14）を −Y に、FPC・コネクタ側を +Y に向ける
FPC・コネクタ | 左端から 27〜94 | +Y 側の辺から最大 1.2 出る。ガイドは隅だけなので当たらない
DFR0550 の取付穴（参 考） | X −55.135 / 57.865 Y −30.15 / 37.85 | 図の点線の丸。パネルには穴なし

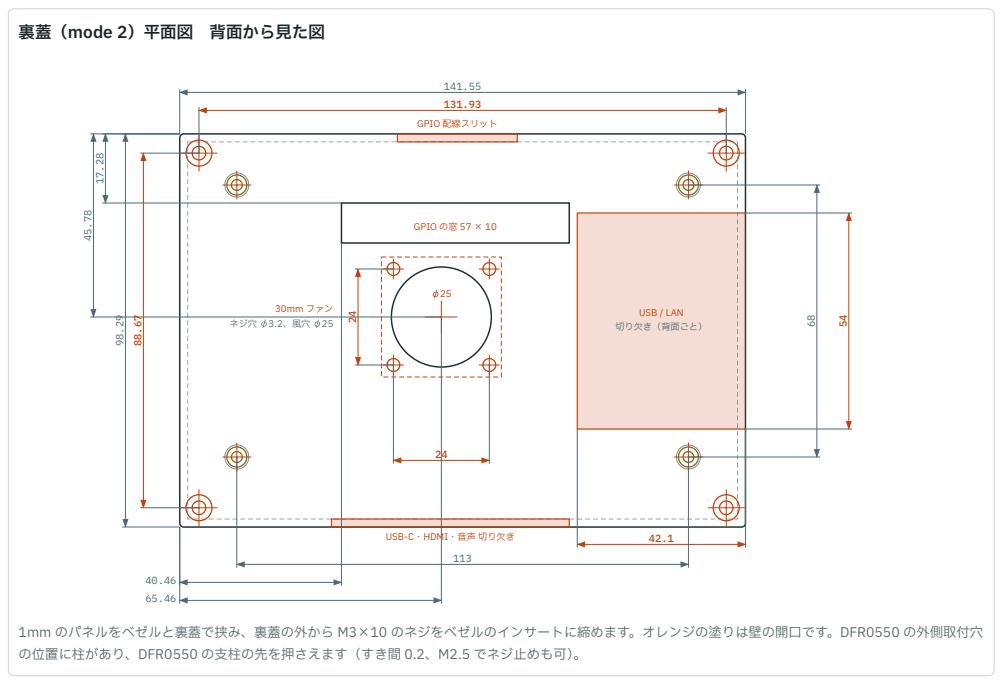
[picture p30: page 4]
GPIO の窓 57 × 10; 30mm ファン ネジ穴 φ3.2、風穴 φ25; USB / LAN 切り欠き（背面ごと）; GPIO 配線スリット

裏蓋（mode 2）平面図 背面から見た図

USB-C・HDMI・音声 切り欠き

1mm のパネルをベゼルと裏蓋で挟み、裏蓋の外から M3×10 のネジをベゼルのインサートに締めます。オレンジの塗りは壁の開口です。DFR0550 の外側取付穴
の位置に柱があり、DFR0550 の支柱の先を押さえます（すき間 0.2、M2.5 でネジ止めも可）。

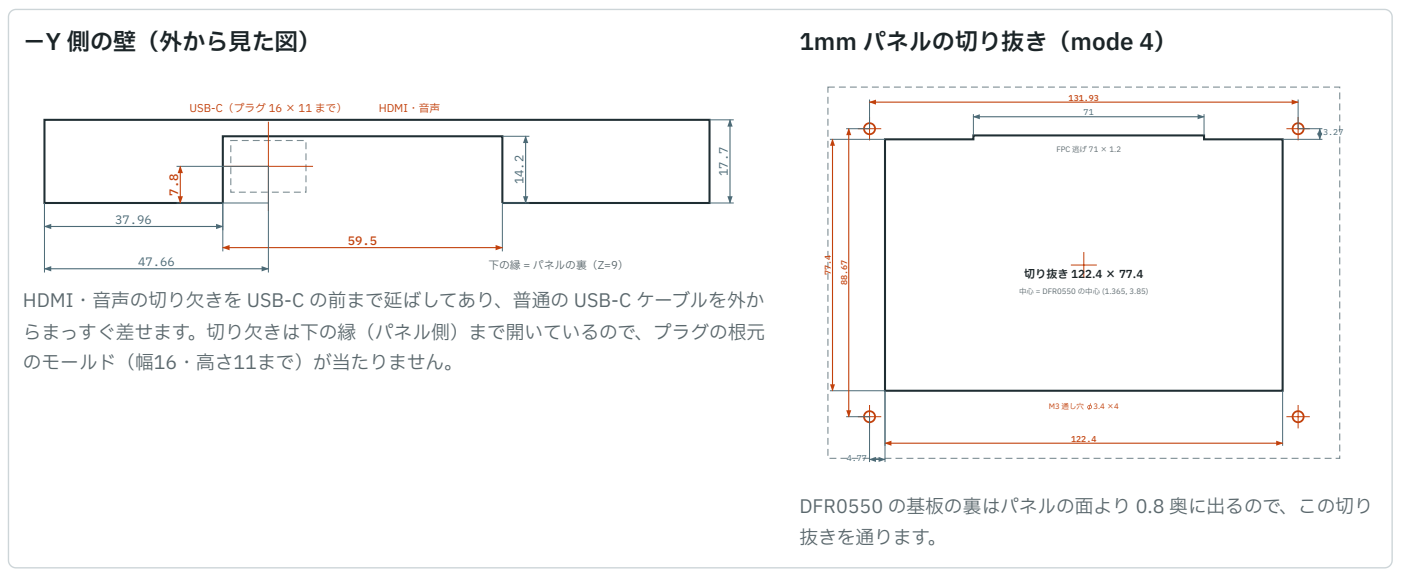
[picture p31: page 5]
−Y 側の壁（外から見た図）; USB-C（プラグ 16 × 11 まで）; HDMI・音声; 下の縁 = パネルの裏（Z=9）; 1mm パネルの切り抜き（mode 4）; 切り抜き 122.4 × 77.4; 中心 = DFR0550 の中心 (1.365, 3.85); FPC 逃げ 71 × 1.2; M3 通し穴 φ3.4 ×4

HDMI・音声の切り欠きを USB-C の前まで延ばしてあり、普通の USB-C ケーブルを外か
らまっすぐ差せます。切り欠きは下の縁（パネル側）まで開いているので、プラグの根元
のモールド（幅16・高さ11まで）が当たりません。

DFR0550 の基板の裏はパネルの面より 0.8 奥に出るので、この切り
抜きを通ります。

### 裏蓋と組み立て

項目 | 寸法 | 説明
裏蓋の外形 | 141.55 × 98.29 × 17.7 | ベゼルと同じ外形。壁厚 2、背面の板 2。深さは GPIO ヘッダーで決まる
M3 ネジ穴 | φ3.4、座ぐり φ6.5 | 131.93 × 88.67。座ぐりの底の厚さ 5、座ぐりの深さ 12.7
M3 ネジ（裏蓋 → ベゼル） | M3 × 10（最長 11） | 座ぐりの底 5 + パネル 1 + インサートに 4 かかる。12 以上はインサート穴の底（深
さ5）に当たる

M2.5 ネジ（DFR0550 押さ
え、任意）
M2.5 × 6 | 柱の底 3 + すき間 0.2 + DFR0550 の支柱に約 2.8 かかる。座ぐり φ5・深さ 9.7
DFR0550 押さえの柱 | φ6、穴 φ2.7、座ぐり φ5 | 113 × 68。柱の先は DFR0550 の支柱の先（Z=13.8）から 0.2 離す
USB-C・HDMI・音声 | 59.5 × 14.2 | −Y の壁。下の縁まで切り欠き。USB-C は外からまっすぐ差せる（中心 X
−21.755、Z 16.8、ポートまで約22）
USB / LAN | 42.1 × 54 の切り欠き | +X の縁から背面の板・壁ごと切り欠く（Y −23.15 〜 30.85）。USB/LAN は背面か
ら約4.5出る
GPIO の窓 | 57 × 10 | 背面の板。ヘッダーの真上で、裏蓋を付けたまま外からコネクタを差せる
30mm ファン | ネジ穴 φ3.2 × 4、ピッチ 24 | 背面の外側に付ける。中心 (−3.955, 4.85)＝Pi4 の CPU の上。ファンの下に風を通
す φ25 の穴
GPIO 配線スリット | 30 × 6.5 | +Y の壁（Z 17.7〜24.2）
パネルの切り抜き | 122.4 × 77.4 | 中心 (1.365, 3.85)。+Y 辺に FPC 逃げ 71 × 1.2、M3 通し穴 φ3.4 ×4
高さ（前面 Z=0 から） | Z | 説明
ベゼルの縁・パネルの表面 | 8
パネルの裏・裏蓋の当たり面 | 9 | パネル厚 1
DFR0550 の基板の裏 | 8.8 | 液晶部 5.7 + 基板 1.6（DFRobot 公式 CAD の値）

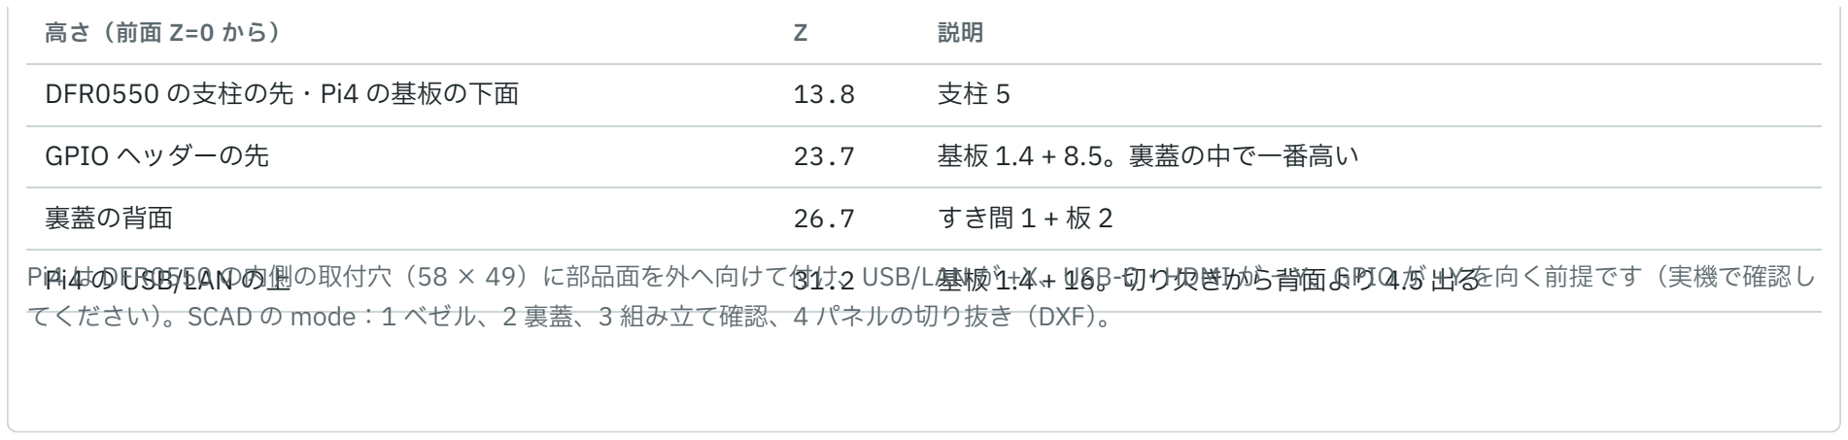
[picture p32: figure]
DFR0550 の支柱の先・Pi4 の基板の下面; GPIO ヘッダーの先; 基板 1.4 + 8.5。裏蓋の中で一番高い; 裏蓋の背面; すき間 1 + 板 2

PiP4i4はのDFURS0B5/5L0ANのの内上側の取付穴（58 × 49）に部品面を外へ向けて付31け.、2 USB/LA基N板が1+.4X、+ U16SB。-切C・りH欠DきMIかがら−背Y面、よGPりIO4.が5 出+Yるを向く前提です（実機で確認し てください）。SCAD の mode：1 ベゼル、2 裏蓋、3 組み立て確認、4 パネルの切り抜き（DXF）。

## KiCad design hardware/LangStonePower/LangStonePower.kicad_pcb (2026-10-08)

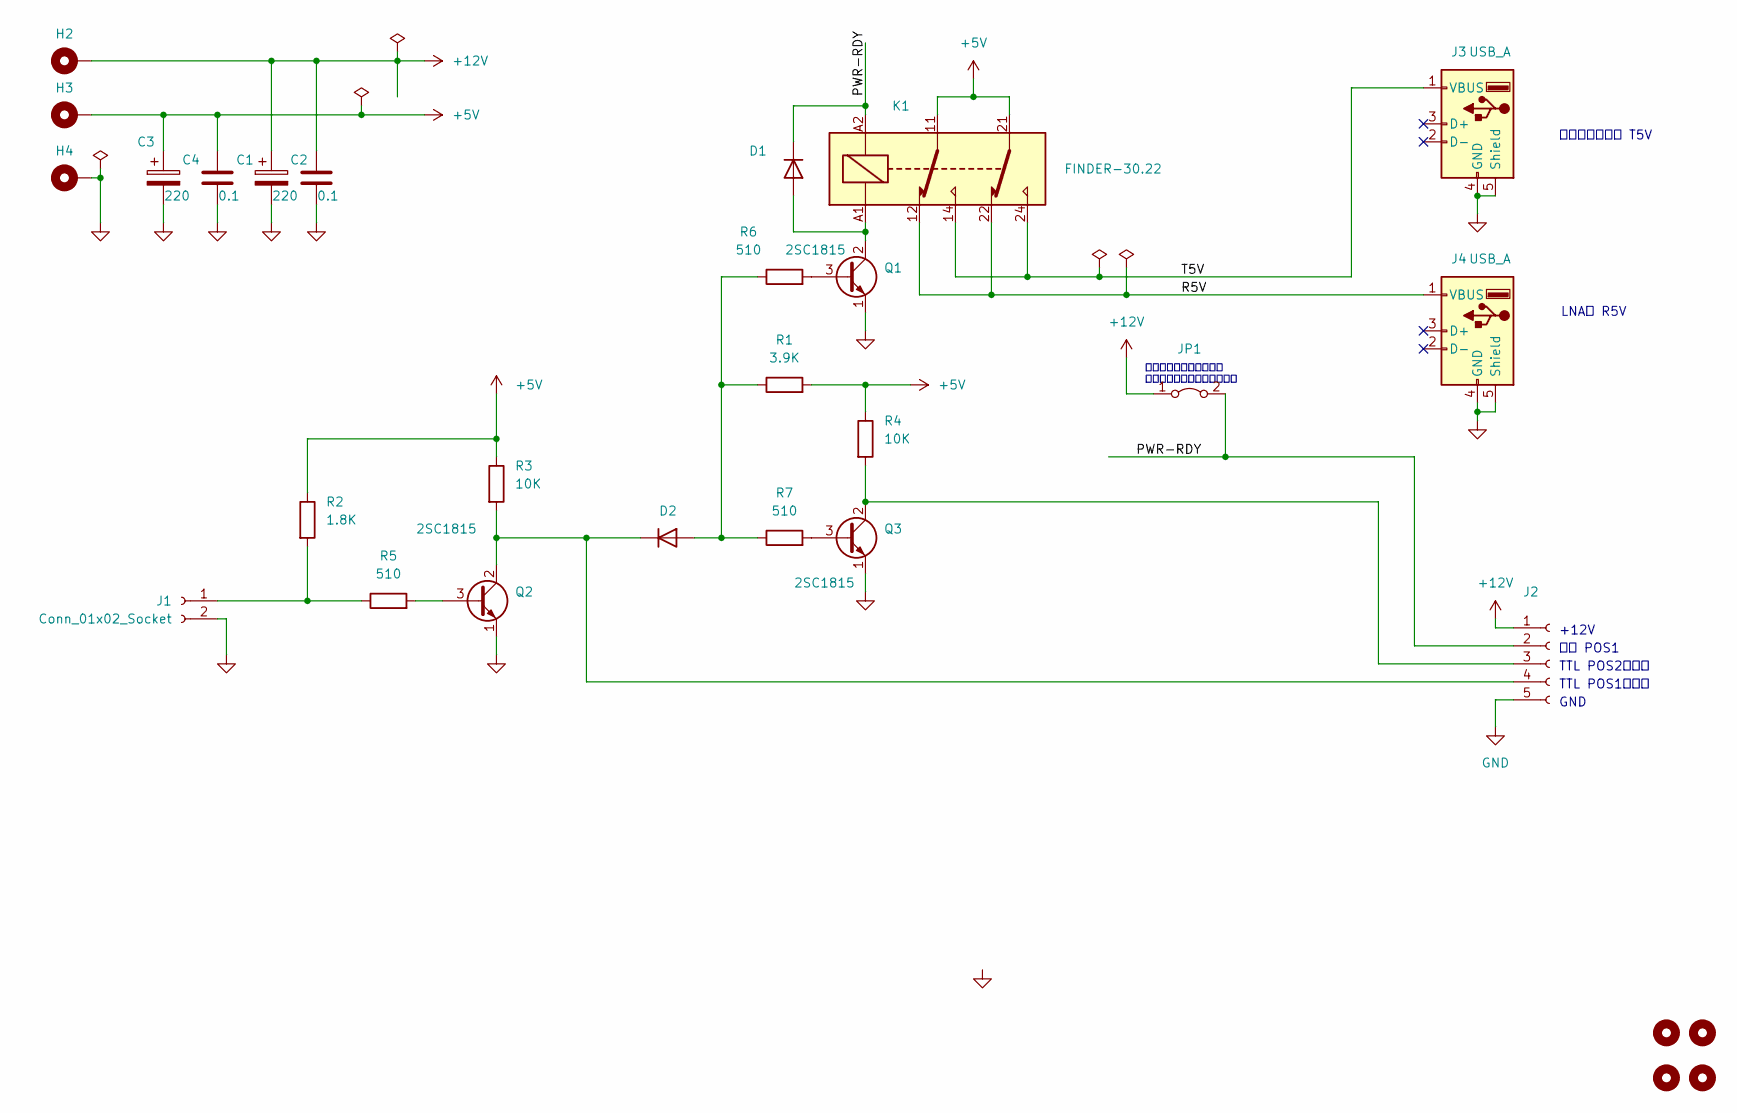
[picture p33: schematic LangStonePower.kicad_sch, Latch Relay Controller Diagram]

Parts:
C1, C3: 220; CP_Radial_D6.3mm_P2.50mm
C2, C4: 0.1; C_Disc_D4.3mm_W1.9mm_P5.00mm
D1, D2: 1N4448; D_DO-35_SOD27_P7.62mm_Horizontal
H1, H5, H6, H7: MountingHole; MountingHole_3.2mm_M3
H2, H3, H4: MountingHole_Pad; MountingHole_2.2mm_M2_DIN965_Pad_TopBottom
J1: Conn_01x02_Socket; Molex_KK-254_AE-6410-02A_1x02_P2.54mm_Vertical
J2: Conn_01x05_Female; Molex_KK-254_AE-6410-05A_1x05_P2.54mm_Vertical
J3, J4: USB_A; USB_A_Molex_67643_Horizontal
JP1: Jumper_2_Bridged; PinSocket_1x02_P2.54mm_Vertical
K1: FINDER-30.22; Relay_DPDT_Finder_30.22
Q1, Q2, Q3: 2SC1815; TO-92_Inline_Wide
R1: 3.9K; R_Axial_DIN0207_L6.3mm_D2.5mm_P5.08mm_Vertical
R2: 1.8K; R_Axial_DIN0207_L6.3mm_D2.5mm_P5.08mm_Vertical
R3, R4: 10K; R_Axial_DIN0207_L6.3mm_D2.5mm_P5.08mm_Vertical
R5, R6, R7: 510; R_Axial_DIN0207_L6.3mm_D2.5mm_P5.08mm_Vertical

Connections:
+5V: C3.1, C4.1, H3.1, K1.11, K1.21, R1.2, R2.1, R3.1, R4.1
+12V: C1.1, C2.1, H2.1, J2.1, JP1.1 (A)
/PWR-RDY: D1.1 (K), J2.2, JP1.2 (B), K1.A2
/R5V: J4.1 (VBUS), K1.12, K1.22
/T5V: J3.1 (VBUS), K1.14, K1.24
GND: C1.2, C2.2, C3.2, C4.2, H4.1, J1.2, J2.5, J3.4 (GND), J3.5 (Shield), J4.4 (GND), J4.5 (Shield), Q1.1 (E), Q2.1 (E), Q3.1 (E)
unnamed: D1.2 (A), K1.A1, Q1.2 (C)
unnamed: D2.2 (A), R1.1, R6.1, R7.1
unnamed: D2.1 (K), J2.4, Q2.2 (C), R3.2
unnamed: J1.1, R2.2, R5.1
unnamed: J2.3, Q3.2 (C), R4.2
unnamed: Q1.3 (B), R6.2
unnamed: Q2.3 (B), R5.2
unnamed: Q3.3 (B), R7.2

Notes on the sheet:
テスト時ジャンパー接続 通常使用時はジャンパー除去
表示 POS1
TTL POS1 送信
TTL POS2 受信
+12V
GND
パワーアンプ用 T5V
LNA用 R5V

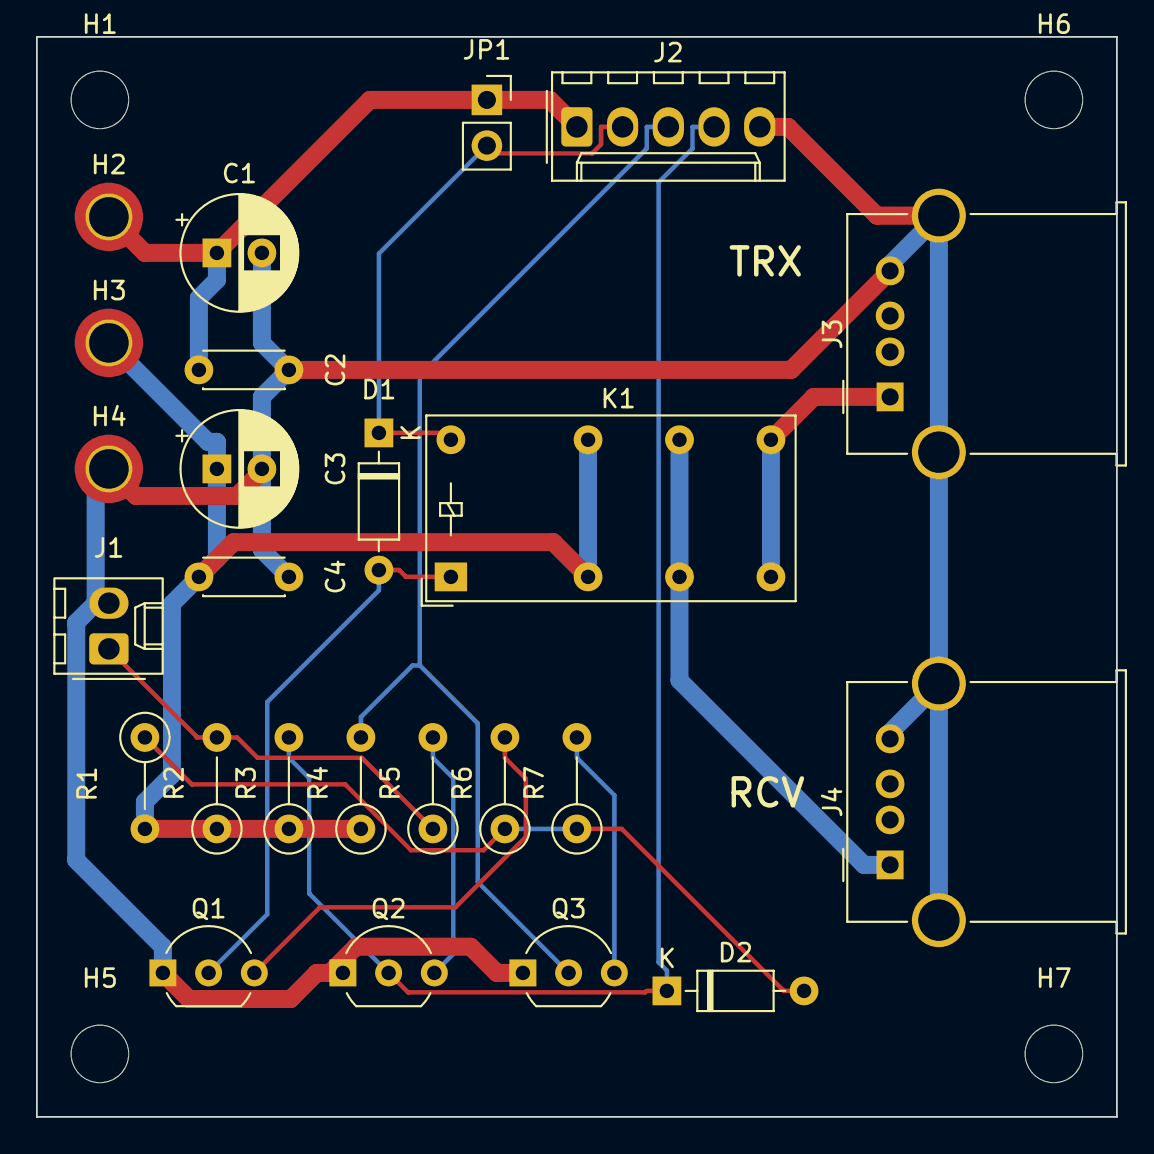
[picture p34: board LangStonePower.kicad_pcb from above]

Board: 2 copper layers, 60.0 x 60.0 mm, 29 parts (0 on the bottom side), 14 nets.

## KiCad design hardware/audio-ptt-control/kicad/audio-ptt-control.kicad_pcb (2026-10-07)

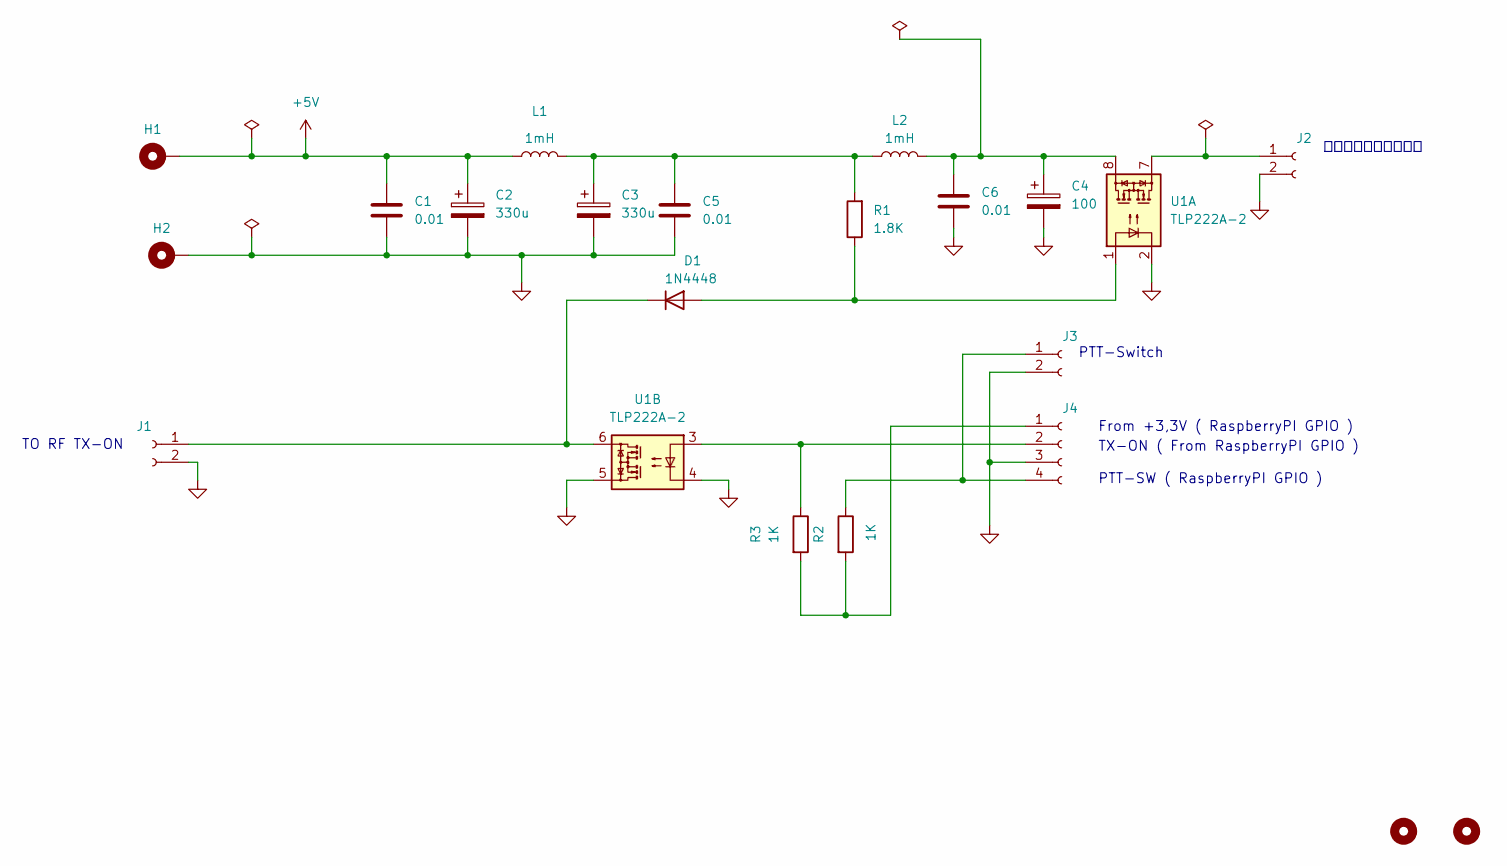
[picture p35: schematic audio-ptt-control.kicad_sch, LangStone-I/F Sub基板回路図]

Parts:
C1, C5, C6: 0.01; C_Disc_D4.3mm_W1.9mm_P5.00mm
C2, C3: 330u; CP_Radial_D8.0mm_P5.00mm
C4: 100; CP_Radial_D6.3mm_P2.50mm
D1: 1N4448; D_DO-35_SOD27_P7.62mm_Horizontal
H1, H2: MountingHole_Pad; MountingHole_2.5mm_Pad
H3, H4: MountingHole; MountingHole_3.2mm_M3
J1, J2, J3: Conn_01x02_Female; Molex_KK-254_AE-6410-02A_1x02_P2.54mm_Vertical
J4: Conn_01x04_Female; Molex_KK-254_AE-6410-04A_1x04_P2.54mm_Vertical
L1, L2: 1mH; L_Radial_D10.5mm_P5.00mm_Abacron_AISR-01
R1: 1.8K; R_Axial_DIN0207_L6.3mm_D2.5mm_P5.08mm_Vertical
R2, R3: 1K; R_Axial_DIN0207_L6.3mm_D2.5mm_P5.08mm_Vertical
U1: TLP222A-2; DIP-8_W7.62mm

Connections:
+5V: C1.1, C2.1, H1.1, L1.1
GND: C1.2, C2.2, C3.2, C4.2, C5.2, C6.2, H2.1, J1.2, J2.2, J3.2, J4.3, U1.2, U1.4, U1.5
unnamed: C3.1, C5.1, L1.2, L2.1, R1.2
unnamed: C4.1, C6.1, L2.2, U1.8
unnamed: D1.2 (A), R1.1, U1.1
unnamed: D1.1 (K), J1.1, U1.6
unnamed: J2.1, U1.7
unnamed: J3.1, J4.4, R2.1
unnamed: J4.1, R2.2, R3.2
unnamed: J4.2, R3.1, U1.3

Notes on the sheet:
TO RF TX-ON
オーディオアンプ電源
TX-ON ( From RaspberryPI GPIO )
PTT-Switch
From +3,3V ( RaspberryPI GPIO )
PTT-SW ( RaspberryPI GPIO )

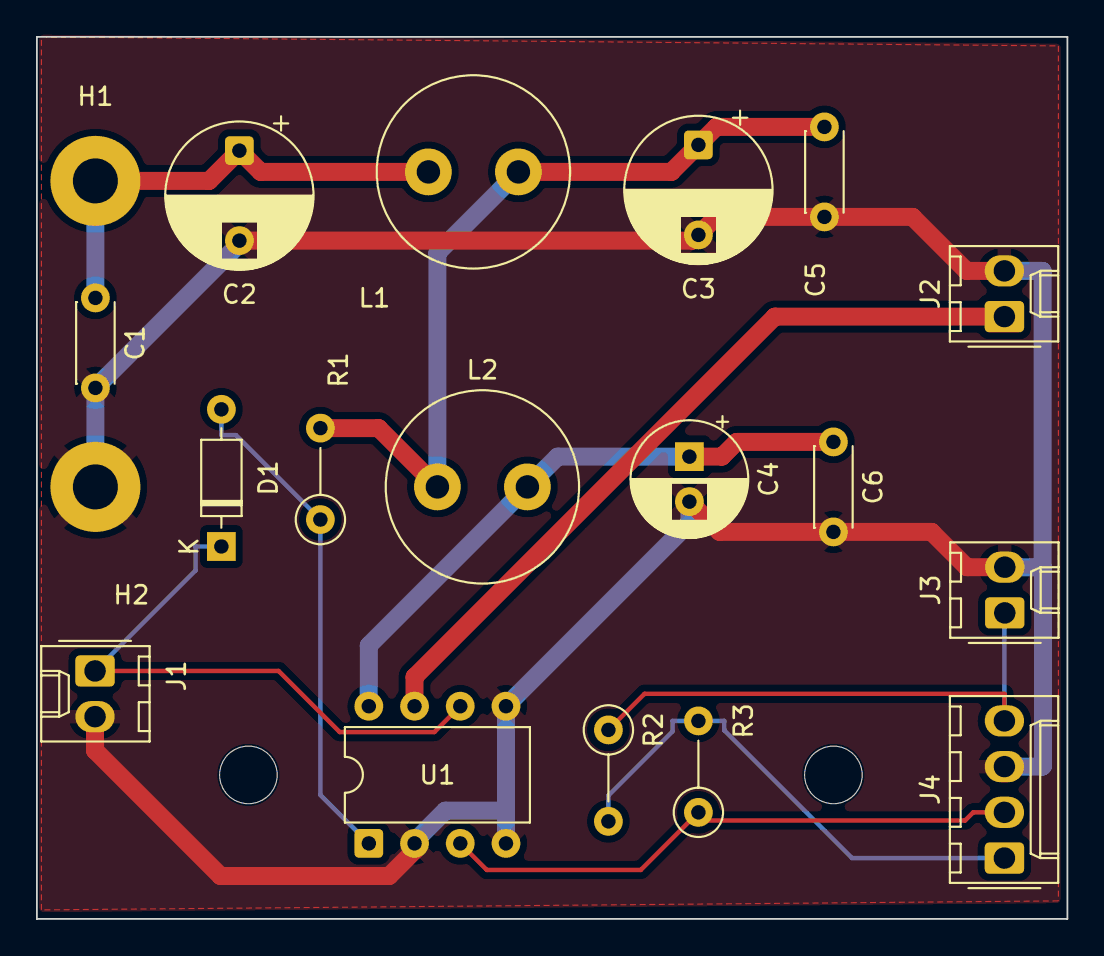
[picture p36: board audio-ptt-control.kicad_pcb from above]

Board: 2 copper layers, 57.2 x 49.0 mm, 21 parts (0 on the bottom side), 10 nets.

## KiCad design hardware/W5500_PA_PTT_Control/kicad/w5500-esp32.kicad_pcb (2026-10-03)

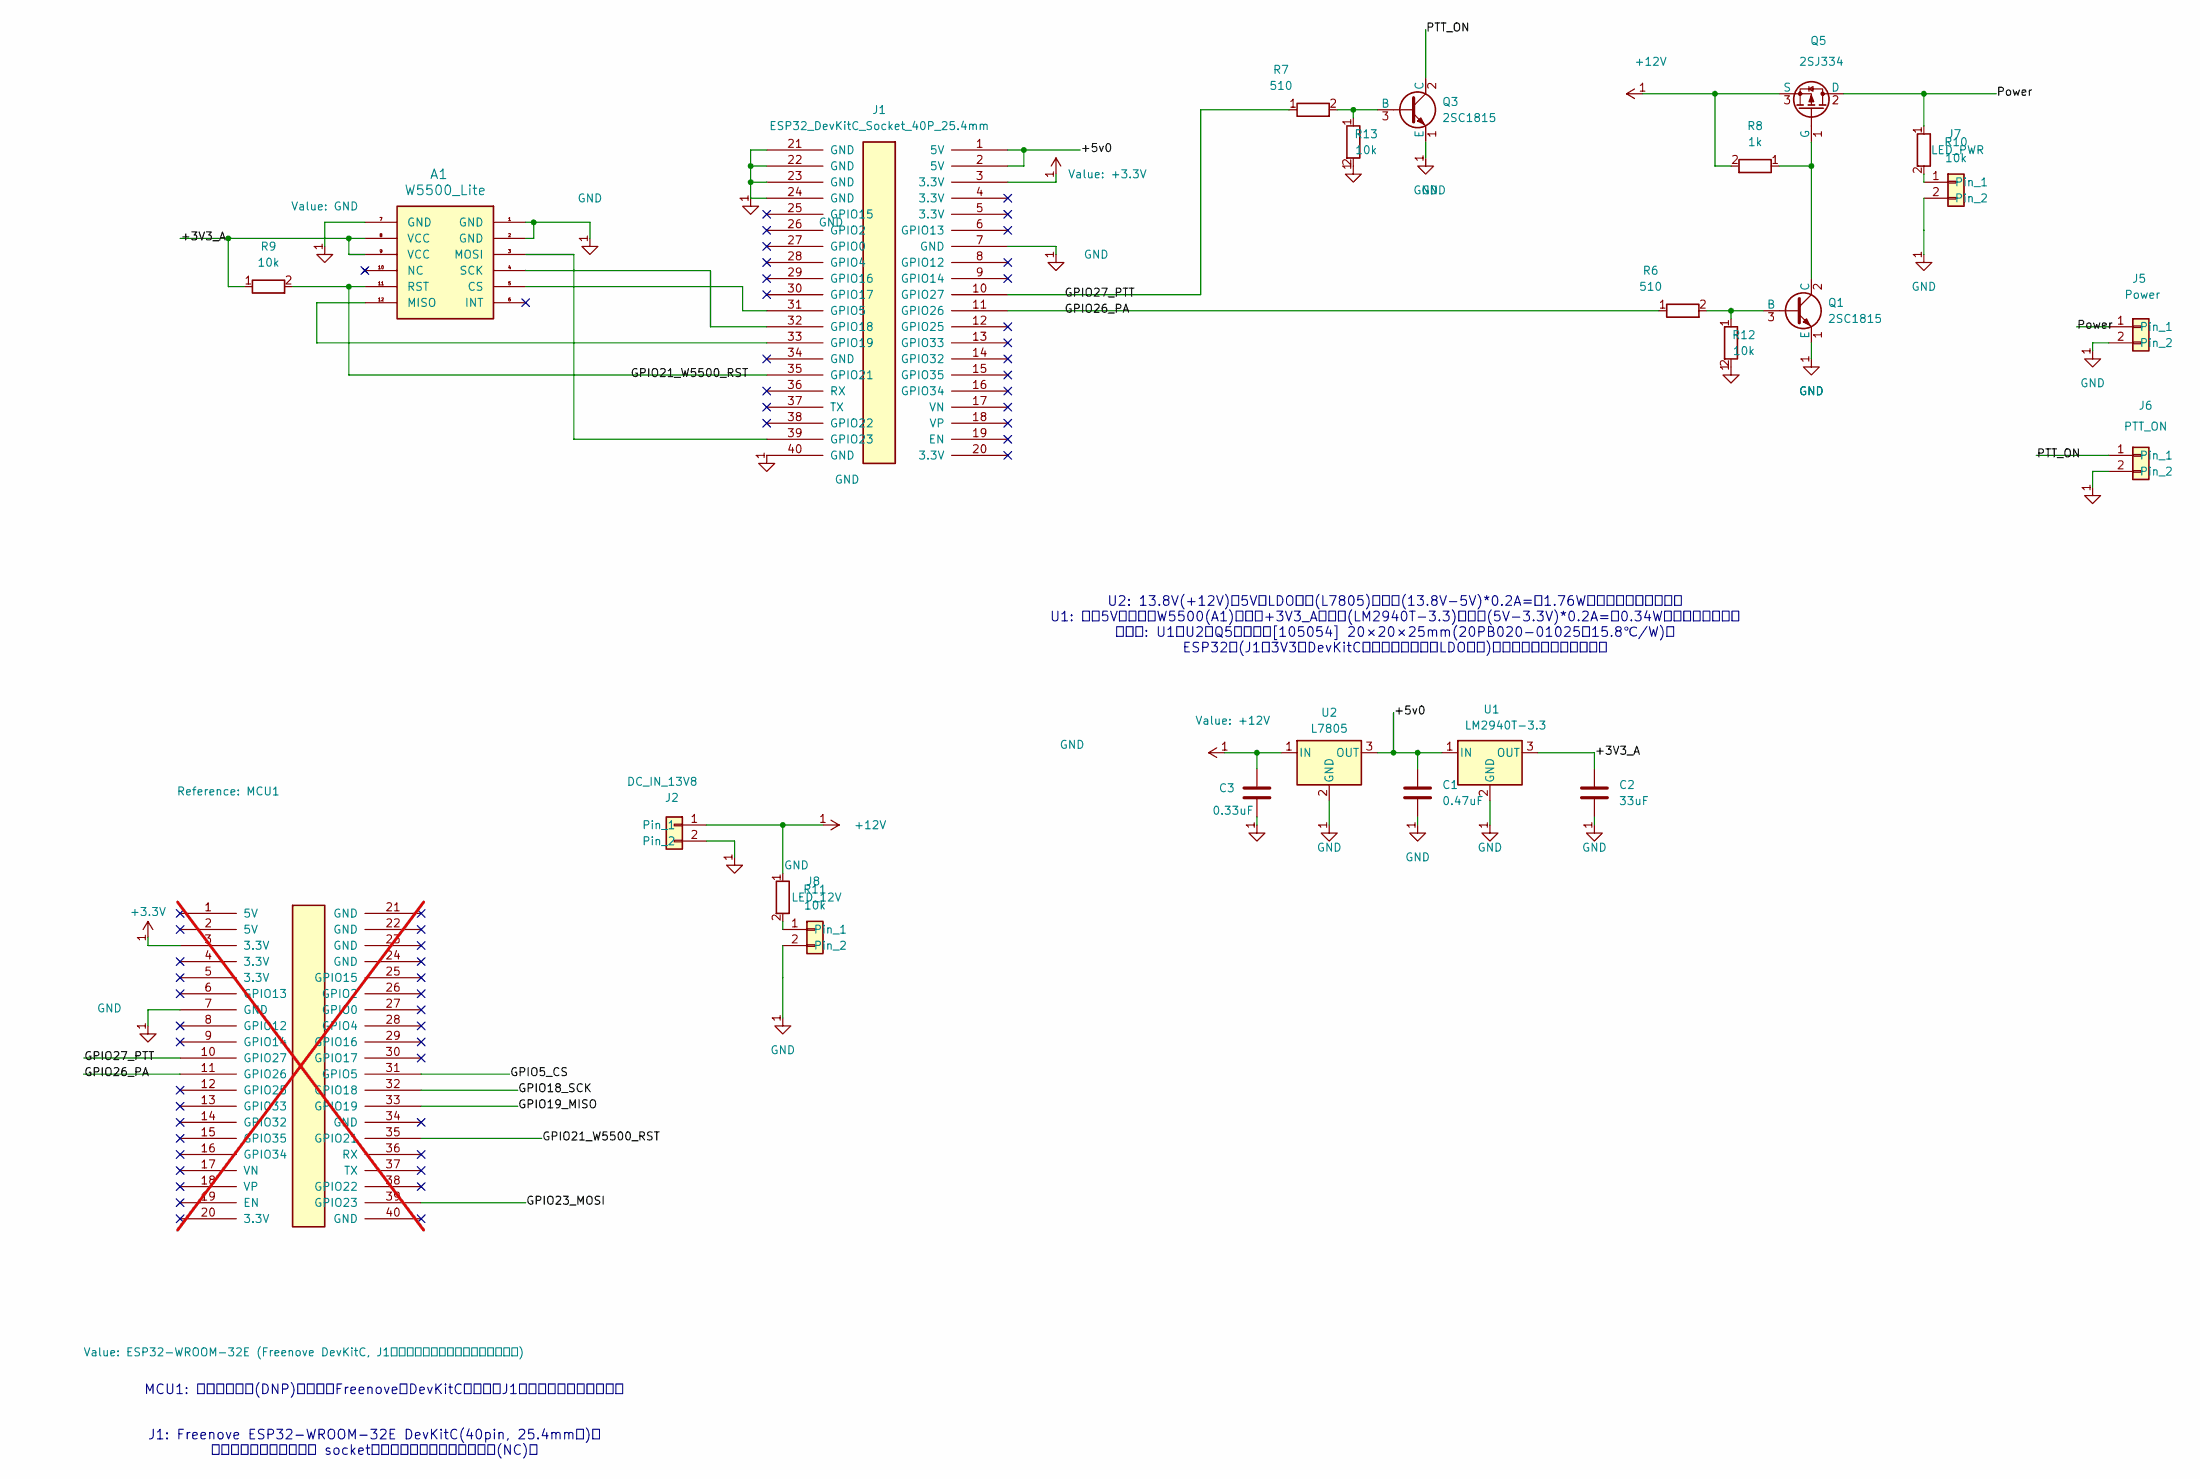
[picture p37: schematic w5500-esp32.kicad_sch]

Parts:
A1: W5500_Lite; W5500_Lite_USR-ES1_2x06_P2.54mm_20.32mm
C1: 0.47uF; CP_Radial_D5.0mm_P2.00mm
C2: 33uF; CP_Radial_D5.0mm_P2.00mm
C3: 0.33uF; CP_Radial_D5.0mm_P2.00mm
J1: ESP32_DevKitC_Socket_40P_25.4mm; Socket_2x20_P2.54mm_25.4mm_DevKitC
J2: DC_IN_13V8; SolderWire-1sqmm_1x02_P5.4mm_D1.4mm_OD2.7mm
J5: Power; SolderWire-1sqmm_1x02_P5.4mm_D1.4mm_OD2.7mm
J6: PTT_ON; JST_XH_B2B-XH-A_1x02_P2.50mm_Vertical
J7: LED_PWR; JST_XH_B2B-XH-A_1x02_P2.50mm_Vertical
J8: LED_12V; JST_XH_B2B-XH-A_1x02_P2.50mm_Vertical
MCU1: ESP32-WROOM-32E (Freenove DevKitC, J1経由で外部接続・本基板に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; not fitted
Q1, Q3: 2SC1815; TO-92_Inline_Wide
Q5: 2SJ334; TO-220-3_Vertical
R6, R7: 510; R_Axial_DIN0207_L6.3mm_D2.5mm_P5.08mm_Vertical
R8: 1k; R_Axial_DIN0309_L9.0mm_D3.2mm_P5.08mm_Vertical
R9, R10, R11, R12, R13: 10k; R_Axial_DIN0207_L6.3mm_D2.5mm_P5.08mm_Vertical
U1: LM2940T-3.3; TO-220-3_Vertical
U2: L7805; TO-220-3_Vertical

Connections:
+3.3V: J1.3 (3.3V), MCU1.3 (3.3V)
+12V: C3.1, J2.1, Q5.3 (S), R8.2, R11.1, U2.1 (IN)
/+3V3_A: A1.8 (VCC), A1.9 (VCC), C2.1, R9.1, U1.3 (OUT)
/+5v0: C1.1, J1.1 (5V), J1.2 (5V), U1.1 (IN_1), U2.3 (OUT)
/GPIO21_W5500_RST: A1.11 (RST), J1.35 (GPIO21), MCU1.35 (GPIO21), R9.2
/GPIO26_PA: J1.11 (GPIO26), MCU1.11 (GPIO26), R6.1
/GPIO27_PTT: J1.10 (GPIO27), MCU1.10 (GPIO27), R7.1
/PTT_ON: J6.1, Q3.2 (C)
/Power: J5.1, Q5.2 (D), R10.1
GND: A1.1 (GND), A1.2 (GND), A1.7 (GND), C1.2, C2.2, C3.2, J1.7 (GND), J1.21 (GND), J1.22 (GND), J1.23 (GND), J1.24 (GND), J1.40 (GND), J2.2, J5.2, J6.2, J7.2, J8.2, MCU1.7 (GND), Q1.1 (E), Q3.1 (E), R12.2, R13.2, U1.2 (GND), U2.2 (GND)
unnamed: A1.5 (CS), J1.31 (GPIO5)
unnamed: A1.12 (MISO), J1.33 (GPIO19)
unnamed: A1.3 (MOSI), J1.39 (GPIO23)
unnamed: A1.4 (SCK), J1.32 (GPIO18)
unnamed: J7.1, R10.2
unnamed: J8.1, R11.2
unnamed: Q1.3 (B), R6.2, R12.1
unnamed: Q1.2 (C), Q5.1 (G), R8.1
unnamed: Q3.3 (B), R7.2, R13.1

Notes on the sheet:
MCU1: 参考表示のみ(DNP)。実体はFreenoveのDevKitC基板で、J1に挿し込んで使用する。
J1: Freenove ESP32-WROOM-32E DevKitC(40pin, 25.4mm幅)を 直接プラグインするメス socket。未使用ピンは機械保持のみ(NC)。
U2: 13.8V(+12V)を5VへLDO変換(L7805)。発熱(13.8V-5V)*0.2A=約1.76Wのため放熱器を使用。 U1: 上記5VをさらにW5500(A1)専用の+3V3_Aへ変換(LM2940T-3.3)。発熱(5V-3.3V)*0.2A=約0.34W。放熱器を使用。 放熱器: U1・U2・Q5とも秋月[105054] 20×20×25mm(20PB020-01025、15.8℃/W)。 ESP32側(J1の3V3、DevKitC基板のオンボードLDO経由)とは完全に独立した系統。

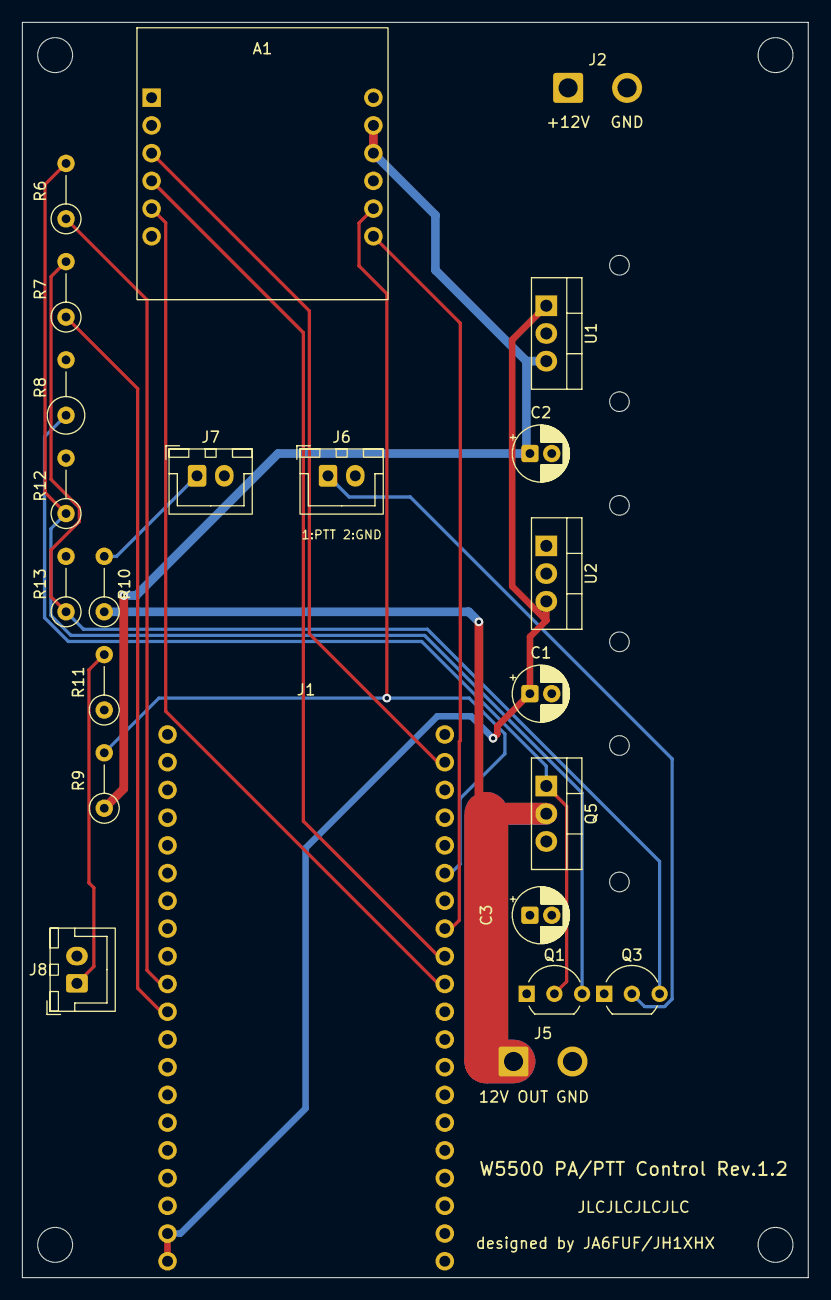
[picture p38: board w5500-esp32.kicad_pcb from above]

Board: 4 copper layers, 72.0 x 115.0 mm, 30 parts (0 on the bottom side), 18 nets.

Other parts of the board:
H1, H2, H3, H4: MountingHole_3.2mm_M3
HS1, HS2, HS3: 105054; Heatsink_GEC_20PB020_Pins_P12.5mm

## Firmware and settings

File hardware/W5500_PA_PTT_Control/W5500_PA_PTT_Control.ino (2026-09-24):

// ============================================================
//  W5500_PA_PTT_Control.ino
//  ESP32 + W5500 イーサネット経由 GPIO25/26/27 電源制御
//  - PTT / PA用電源のON/OFFをブラウザから制御（ラッチ式）
//  - DHCPでIPアドレス取得
//  - Arduino公式 Ethernet ライブラリ（W5500対応）を使用
//
//  【配線】
//  W5500      ESP32 (VSPI)
//  --------   ------------
//  SCK        GPIO 18
//  MISO       GPIO 19
//  MOSI       GPIO 23
//  CS(SS)     GPIO 5
//  RST        (未使用。EN/3.3Vへ配線 or 未接続可)
//  VCC        3.3V
//  GND        GND
//
//  出力（ラッチ式ON/OFF、いずれもactive-HIGH想定）
//  LNA: GPIO 25 （受信プリアンプ。起動時はON＝受信状態）
//  PTT: GPIO 26 （起動時はOFF）
//  PA : GPIO 27 （起動時はOFF）
//
//  【shonan-android 連携】
//  送信ボタンON  : GET /tx?state=on
//    → LNA off → 100ms待機 → PTT/PA を同時にon
//  送信ボタンOFF : GET /tx?state=off
//    → PA/PTT を同時にoff → 100ms待機 → LNA on
// ============================================================

#include <SPI.h>
#include <Ethernet.h>

// ============================================================
//  設定
// ============================================================

// W5500にはMACアドレスが内蔵されていないため任意の値を設定
// （同一ネットワーク内で他機器と重複しないこと）
static byte mac[] = { 0x02, 0xAA, 0xBB, 0xCC, 0xDE, 0x01 };

const int PIN_CS  = 5;

const int IDX_LNA = 0;
const int IDX_PTT = 1;
const int IDX_PA  = 2;

const int PIN_OUT[3] = { 25, 26, 27 };
const char* OUT_LABEL[3] = { "LNA (GPIO25)", "PTT (GPIO26)", "PA (GPIO27)" };

// 基板搭載LED（PTT ON中に点灯）
const int PIN_ONBOARD_LED = 2;

// 起動時はLNA=ON（受信状態）、PTT/PA=OFF
bool outState[3] = { true, false, false };

bool txActive = false;

EthernetServer server(80);
bool linkUp = false;

// ============================================================
//  出力制御
// ============================================================

void applyOutput(int idx) {
    digitalWrite(PIN_OUT[idx], outState[idx] ? HIGH : LOW);
    Serial.printf("[OUT] %s -> %s\n", OUT_LABEL[idx], outState[idx] ? "ON" : "OFF");
    if (idx == IDX_PTT) {
        digitalWrite(PIN_ONBOARD_LED, outState[IDX_PTT] ? HIGH : LOW);
    }
}

void setOutput(int idx, bool on) {
    if (idx < 0 || idx > 2) return;
    outState[idx] = on;
    applyOutput(idx);
}

void toggleOutput(int idx) {
    if (idx < 0 || idx > 2) return;
    setOutput(idx, !outState[idx]);
}

// ============================================================
//  TX/RX シーケンス（shonan-android 連携）
// ============================================================

void txStart() {
    if (txActive) return;
    txActive = true;
    Serial.println("[TX] 送信シーケンス開始");
    setOutput(IDX_LNA, false);   // LNAを先にOFF
    delay(100);                  // 100ms待機
    setOutput(IDX_PTT, true);    // PTTとPAを同時にON
    setOutput(IDX_PA, true);
    Serial.println("[TX] 送信シーケンス完了 (LNA off -> 100ms -> PTT/PA on)");
}

void txStop() {
    if (!txActive) return;
    txActive = false;
    Serial.println("[TX] 受信復帰シーケンス開始");
    setOutput(IDX_PA, false);    // PAとPTTを先に同時にOFF
    setOutput(IDX_PTT, false);
    delay(100);                  // 100ms待機
    setOutput(IDX_LNA, true);    // LNAをON
    Serial.println("[TX] 受信復帰シーケンス完了 (PA/PTT off -> 100ms -> LNA on)");
}

// ============================================================
//  HTTPリクエスト処理（簡易パーサ）
//  対応パス:
//    GET /               ステータスページ
//    GET /toggle?ch=0..2 指定チャンネルをトグルして / へリダイレクト
//    GET /api/status     JSON形式で現在状態を返す
// ============================================================

void sendStatusPage(EthernetClient& client) {
    client.println("HTTP/1.1 200 OK");
    client.println("Content-Type: text/html; charset=UTF-8");
    client.println("Connection: close");
    client.println();

    client.println("<!DOCTYPE html><html lang='ja'><head><meta charset='UTF-8'>");
    client.println("<meta name='viewport' content='width=device-width,initial-scale=1'>");
    client.println("<title>PA/PTT 電源制御</title>");
    client.println("<style>");
    client.println("body{margin:0;font-family:sans-serif;background:#000;color:#eee;text-align:center;padding-top:30px}");
    client.println("h1{color:#aaa;font-size:1.3em}");
    client.println(".card{display:inline-block;margin:12px;background:#111;border-radius:12px;padding:20px 28px;min-width:180px}");
    client.println(".label{color:#888;font-size:.9em;margin-bottom:10px}");
    client.println(".state{font-size:1.6em;font-weight:bold;margin-bottom:14px}");
    client.println(".on{color:#4c9}.off{color:#c66}");
    client.println("a.btn{display:inline-block;padding:10px 26px;border-radius:8px;text-decoration:none;font-size:1em}");
    client.println(".btn-on{background:#1a4;color:#fff}.btn-off{background:#a11;color:#fff}");
    client.println("</style></head><body>");
    client.println("<h1>&#9889; PA/PTT 電源制御</h1>");
    client.print("<p style='font-size:1.1em'>状態: <b style='color:");
    client.print(txActive ? "#f66'>送信中(TX)" : "#6c9'>受信中(RX)");
    client.println("</b></p>");

    for (int i = 0; i < 3; i++) {
        client.print("<div class='card'><div class='label'>");
        client.print(OUT_LABEL[i]);
        client.print("</div><div class='state ");
        client.print(outState[i] ? "on'>ON" : "off'>OFF");
        client.print("</div><a class='btn ");
        client.print(outState[i] ? "btn-off" : "btn-on");
        client.print("' href='/toggle?ch=");
        client.print(i);
        client.print("'>");
        client.print(outState[i] ? "OFFにする" : "ONにする");
        client.println("</a></div>");
    }

    client.print("<p style='color:#555;margin-top:20px;font-size:.8em'>IP: ");
    client.print(Ethernet.localIP());
    client.println("</p>");
    client.println("</body></html>");
}

void sendStatusJson(EthernetClient& client) {
    client.println("HTTP/1.1 200 OK");
    client.println("Content-Type: application/json");
    client.println("Connection: close");
    client.println();
    client.print("{\"out1\":");
    client.print(outState[0] ? "true" : "false");
    client.print(",\"out2\":");
    client.print(outState[1] ? "true" : "false");
    client.print(",\"out3\":");
    client.print(outState[2] ? "true" : "false");
    client.print(",\"tx_active\":");
    client.print(txActive ? "true" : "false");
    client.println("}");
}

void sendRedirectRoot(EthernetClient& client) {
    client.println("HTTP/1.1 303 See Other");
    client.println("Location: /");
    client.println("Connection: close");
    client.println();
}

void handleClient(EthernetClient& client) {
    String reqLine;
    while (client.connected() && client.available() == 0) delay(1);
    if (client.available()) {
        reqLine = client.readStringUntil('\n');
    }
    // ヘッダー残りを読み捨てる
    while (client.connected()) {
        String line = client.readStringUntil('\n');
        if (line == "\r" || line.length() == 0) break;
    }

    Serial.println("[HTTP] " + reqLine);

    if (reqLine.startsWith("GET /tx")) {
        // shonan-android からのTX開始/終了通知
        if (reqLine.indexOf("state=on") >= 0) {
            txStart();
        } else if (reqLine.indexOf("state=off") >= 0) {
            txStop();
        }
        client.println("HTTP/1.1 200 OK");
        client.println("Content-Type: text/plain");
        client.println("Connection: close");
        client.println();
        client.println(txActive ? "TX" : "RX");
    } else if (reqLine.startsWith("GET /toggle")) {
        // 手動デバッグ用（個別チャンネルのトグル）
        int chIdx = reqLine.indexOf("ch=");
        if (chIdx >= 0) {
            int ch = reqLine.substring(chIdx + 3, chIdx + 4).toInt();
            toggleOutput(ch);
        }
        sendRedirectRoot(client);
    } else if (reqLine.startsWith("GET /api/status")) {
        sendStatusJson(client);
    } else {
        sendStatusPage(client);
    }

    delay(1);
    client.stop();
}

// ============================================================
//  setup / loop
// ============================================================

void setup() {
    Serial.begin(115200);
    delay(3000);
    Serial.println("=== W5500_PA_PTT_Control 起動 ===");

    pinMode(PIN_ONBOARD_LED, OUTPUT);
    digitalWrite(PIN_ONBOARD_LED, LOW);

    for (int i = 0; i < 3; i++) {
        pinMode(PIN_OUT[i], OUTPUT);
        applyOutput(i);   // 起動時状態を反映（LNA=ON, PTT/PA=OFF、LED=OFF）
    }

    Ethernet.init(PIN_CS);

    Serial.print("DHCPでIP取得中...");
    if (Ethernet.begin(mac, 15000, 4000) == 0) {
        Serial.println(" 失敗（DHCPサーバー未応答）");
        if (Ethernet.hardwareStatus() == EthernetNoHardware) {
            Serial.println("W5500が検出できません。配線を確認してください。");
        }
    } else {
        Serial.println(" 成功");
    }

    Serial.print("IPアドレス: ");
    Serial.println(Ethernet.localIP());

    server.begin();
    Serial.println("Webサーバー起動 (port 80)");
}

void loop() {
    // リンク状態の監視
    bool nowUp = (Ethernet.linkStatus() != LinkOFF);
    if (nowUp != linkUp) {
        linkUp = nowUp;
        Serial.println(linkUp ? "[LINK] イーサネット接続" : "[LINK] イーサネット切断");
    }

    // DHCPリース更新
    Ethernet.maintain();

    EthernetClient client = server.available();
    if (client) {
        handleClient(client);
    }
}

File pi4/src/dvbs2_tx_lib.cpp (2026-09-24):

// aff3ct/dvbs2自体のdvbs2_tx main()をextern "C"関数化しただけの薄いラッパー。
#include <atomic>
#include <fstream>
#include <aff3ct.hpp>
#include <streampu.hpp>

#include "Factory/DVBS2/DVBS2.hpp"
#ifdef DVBS2_LINK_UHD
#include "Module/Radio/Radio_USRP/Radio_USRP.hpp"
#endif

using namespace aff3ct;
using namespace aff3ct::module;

// ★dvbs2_rx_lib.cppと同じ理由(FIFOを閉じるだけでは内部のブロッキング実行ループが
// 止まらずCPU/メモリを消費し続ける)で、外部から停止要求できるフラグを追加する。
static std::atomic<bool> g_dvbs2_tx_stop_requested{false};

extern "C" void datv_dvbs2_tx_request_stop()
{
	g_dvbs2_tx_stop_requested.store(true);
}

// ★スレッド数を8→4に削減してもTx/Rx同時実行時にRx側のwaiting phaseが8秒→22秒に
// 遅延する(CPU競合が残る)ことを確認した(Android/iOS版での知見)。まずはシングル
// スレッドで動作確認する(DVBS2_iOS_Port_PoC.md 12.11続報、Pi4ではスレッドピニング
// 制約が無いためMULTI_THREADED再有効化は動作確認後に検討)。
// #define MULTI_THREADED // comment this line to disable multi-threaded TX

// global parameters
constexpr bool enable_logs = false;
#ifdef MULTI_THREADED
const bool thread_pinnig = false;
const bool active_waiting = false;
#endif

// aliases
template<class T> using uptr = std::unique_ptr<T>;

// 元は int main(int argc, char** argv)。tx_main.cppからライブラリ関数として呼び出せる
// ように extern "C" 関数へ変更した(名前修飾を避けCブリッジ層から呼べるようにするため)。
// argc/argvはコマンドライン相当のパラメータをそのまま渡す想定(--mod-cod, --src-path等)。
extern "C" int datv_dvbs2_tx_run(int argc, char** argv)
{
// aff3ct/streampu側が投げるC++例外(コンステレーションファイル未検出等)をキャッチせずに
// 素通しすると terminate() 経由でSIGABRTしプロセスごと即死する。呼び出し側にエラーとして
// 伝播できるよう、関数全体を例外境界で囲む。
try
{
	g_dvbs2_tx_stop_requested.store(false);
#ifdef MULTI_THREADED
	if (thread_pinnig)
	{
		spu::tools::Thread_pinning::init();
		// spu::tools::Thread_pinning::set_logs(enable_logs);
	}
#endif /* MULTI_THREADED */

	// setup signal handlers
	spu::tools::Signal_handler::init();

	// get the parameter to configure the tools and modules
	auto params = factory::DVBS2(argc, argv);

	std::map<std::string,tools::header_list> headers;
	std::vector<factory::Factory*> param_vec;
	param_vec.push_back(&params);
	tools::Header::print_parameters(param_vec, true, std::cout);

	// construct tools
	uptr<tools::Constellation<R>> cstl(new tools::Constellation_user<R>(params.constellation_file));
	uptr<tools::Interleaver_core<>> itl_core(factory::DVBS2::build_itl_core<>(params));
	tools::BCH_polynomial_generator<B> poly_gen(params.N_bch_unshortened, 12, params.bch_prim_poly);

	// construct modules
	uptr<spu::module::Source<>> source        (factory::DVBS2::build_source      <>(params, 0         ));
	uptr<Scrambler<>          > bb_scrambler  (factory::DVBS2::build_bb_scrambler<>(params            ));
	uptr<Encoder<>            > BCH_encoder   (factory::DVBS2::build_bch_encoder <>(params, poly_gen  ));
	uptr<tools::Codec<>       > LDPC_cdc      (factory::DVBS2::build_ldpc_cdc    <>(params            ));
	uptr<Interleaver<>        > itl           (factory::DVBS2::build_itl         <>(params, *itl_core ));
	uptr<Modem<>              > modem         (factory::DVBS2::build_modem       <>(params, cstl.get()));
	uptr<Framer<>             > framer        (factory::DVBS2::build_framer      <>(params            ));
	uptr<Scrambler<float>     > pl_scrambler  (factory::DVBS2::build_pl_scrambler<>(params            ));
	uptr<Filter<>             > shaping_filter(factory::DVBS2::build_uprrc_filter<>(params            ));
	uptr<Radio<>              > radio         (factory::DVBS2::build_radio       <>(params            ));

	auto* LDPC_encoder = &LDPC_cdc->get_encoder();

	// add custom name to some modules
	BCH_encoder ->set_custom_name("Encoder BCH" );
	LDPC_encoder->set_custom_name("Encoder LDPC");

	// the full transmission chain binding
	(*bb_scrambler  )[scr::sck::scramble  ::X_N1] = (*source        )[spu::module::src::sck::generate  ::out_data];
	(*BCH_encoder   )[enc::sck::encode    ::U_K ] = (*bb_scrambler  )[             scr::sck::scramble  ::X_N2    ];
	(*LDPC_encoder  )[enc::sck::encode    ::U_K ] = (*BCH_encoder   )[             enc::sck::encode    ::X_N     ];
	(*itl           )[itl::sck::interleave::nat ] = (*LDPC_encoder  )[             enc::sck::encode    ::X_N     ];
	(*modem         )[mdm::sck::modulate  ::X_N1] = (*itl           )[             itl::sck::interleave::itl     ];
	(*framer        )[frm::sck::generate  ::Y_N1] = (*modem         )[             mdm::sck::modulate  ::X_N2    ];
	(*pl_scrambler  )[scr::sck::scramble  ::X_N1] = (*framer        )[             frm::sck::generate  ::Y_N2    ];
	(*shaping_filter)[flt::sck::filter    ::X_N1] = (*pl_scrambler  )[             scr::sck::scramble  ::X_N2    ];
	(*radio         )[rad::sck::send      ::X_N1] = (*shaping_filter)[             flt::sck::filter    ::Y_N2    ];

	// first stages of the whole transmission sequence
	const std::vector<spu::runtime::Task*> firsts_t = { &(*source)[spu::module::src::tsk::generate] };
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

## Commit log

2026-09-24 Shonan_Lite for RasPI4 (Raspberry Pi 4 + ADALM-Pluto DVB-S2 DATV送受信タッチGUI)
    Raspberry Pi 4 + DFRobot DFR0550(または公式DSIタッチ画面)とADALM-Plutoによる
    DVB-S2 DATV送受信アプリ。送信(Pluto内蔵変調器pluto_dvb、H.264ハードウェアエンコード)、
    受信(外部復調/gr-dvbs2rxによるオンデバイス復調)、RSSI測定、映像ソース(カメラ/画像/
    テストパターン、コールサイン焼き込み)、プリセット、機器試験、Pluto自動検出、日英表示、
    アプリ内Help・操作説明書、起動時のShonan_Lite/Langstone V2Modify切替を含む。
    [rf_sweep_72_rerun_2026-08-11.csv]
2026-09-24 Pi5版の配色変更・映像ソース/プリセット画面の改善・起動時オンデバイス復調OFFを移植
    Shonan_Lite-RasPI5の8f3656e/de4dad8と撮影後キーボード問題の修正をPi4へ移植した。
    - 配色(ホーム画面は対象外): 各画面の背景を暗くし、ボタンを青に統一(通常 #1d4388、
    主要操作 #1677ff、押下中 #102a5c)。選択式ボタンの未選択側はグレー(#303538)。
    送信停止・受信停止は赤のまま。上部バーの色指定がバー内ボタンへ波及しないようにした
    - 映像ソース: 撮影ボタンはカメラ選択時だけ表示し、半分の幅にして撮影画像の全削除
    ボタン(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
    [boot_menu.py, fec.py, frequency.py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]
2026-09-24 オンスクリーンキーボードのシフトキーが使えない不具合を修正
    キーボードはQQuickWidgetとして独自に出し入れしているため、Qt側(QInputMethod)は
    キーボードが表示中だと認識していなかった。Qt Virtual KeyboardのShiftHandlerは
    表示中になったときにだけシフト可否を初期化するため、シフトキーが無効(灰色)のまま
    で大文字が打てなかった。キーボードの表示/非表示時にQInputMethodのshow()/hide()を
    呼んでQtへ伝える(Pi5実機でコールサイン・備考欄の大文字入力を確認)。
    [main.py]
2026-09-25 新しいOS(2026-09版)へのPi4新規インストールで起きた問題を修正
    - .gitattributesを追加し、改行コードをLFに固定する(Windowsから転送した
    スクリプトがCRLFになり、set -o pipefailで失敗していた)
    - install.sh/install_drf0550.shの冒頭で、DFR0550をfirmwareのレガシーDSI表示で
    動かすためにconfig.txtのvc4-kms-v3d・display_auto_detect・disable_fw_kms_setupを
    コメントアウトし、dtparam=i2c_arm=onを追記する。変更した場合は再起動を求めて
    終了する(KMS有効のままだと画面・タッチが使えず、ビルド中に実機が再起動して
    パッケージが破損した)
    - Langston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
2026-09-30 Pi5版の9/25以降の変更を移植
    - 送信中にPi4のGPIO21(40番ピン)をHIGHにし、ESP32 W5500なしでもPA/LNAを制御可能に
    - 周波数画面の10GHz帯でLNB使用を選択可能に(表示10.2365GHz、Pluto受信486.5MHz、受信専用)
    - 設定画面に「ESP32 W5500を使用する」を追加(OFFでもIPアドレスを保持)
    - Home画面の衛星タップでLangstoneを10GHz受信用バンド(受信専用bandRxOnly)で開く
    - Langstone V2Modifyとの切替でPlutoを再起動しない(送信LOは復元)
    - プリセット登録の異常終了修正、機器試験中のボタン赤表示
    - README日英併記化、操作説明書(Help/DOCX)を日英併記にし新機能を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
    [backend.py, boot_menu.py, frequency.py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]
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2026-09-30 英語表示でエラーメッセージが日本語のままになる箇所を英語化
    LNB使用中の送信エラー、Langstone設定/起動失敗、PTTコントローラ未設定、
    Pluto電源ON/OFF失敗、シャットダウン失敗を翻訳辞書に追加(error_dialogで英語化される)。
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2026-09-30 ハードウェア文書をPi5版にそろえ、インストールガイドを実装に合わせて修正(日英)
    - ESP32ファームウェア(W5500_PA_PTT_Control.ino、WiFiTest版)・接続一覧・回路図SVG・
    作業ログをPi5版から取り込み(旧Rev.1.0の3ch版を置き換え)。KiCadと命令(/ch?idx・/tx?state)に一致
    - 仕様書: Pi5版Rev.2.3をもとにShonan_lite-PI4向けの連携(4.4)に置き換え
    - install_script_guide: 現行install.sh(表示設定確認・1/9〜9/9、Langstone V2Modify、
    linuxfb、起動メニュー、sudoers)に合わせて書き直し
    - Word/PDF版を生成・再生成。MarkdownからWord/PDFを作るtools/build_docs.pyを追加
    Co-Auth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
    [W5500_PA_PTT_Control_WiFiTest.ino]
2026-09-30 W5500制御基板: R8を1kΩに、R12(Q1ベースのプルダウン)追加、Q5の足番号修正、放熱器を追加
    - R8(Q5ゲートのプルアップ)を100Ωから1kΩ(1/2W推奨)へ。Q1 ON中の電流を約12〜14mAに抑える
    - Q1のベースをGNDへプルダウンするR12(10kΩ)を追加(GPIO26が確定しない間もQ1をOFFに保つ)
    - Q5のシンボルを端子番号1=G・2=D・3=Sのproject_symbols:2SJ334に変更
    (従来のDevice:Q_PMOSは端子番号D/G/Sで、基板データ上Q5が未接続になっていた)
    - U1・U2・Q5に放熱器(秋月[105054] 20×20×25mm)。基板データでTO-220の3部品を25mm間隔に配置
    - 仕様書(Rev.2.4)・接続一覧(日英・Wor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
    [w5500-esp32.kicad_pcb, w5500-esp32.kicad_sch]
2026-09-30 W5500制御基板の外形を115×72mmにして部品を配置
    - Edge.Cutsに115×72mmの外形線を追加
    - 全部品を外形内に配置。TO-220(U1・U2・Q5)は下辺に沿って23mm間隔、放熱タブを下端側に向け、
    放熱器(20×20mm)の範囲をDwgs.Userに記入。J2/J5/J6用の場所を右端に確保(フットプリント未指定)
    - DRC違反0件(未配線とJ2/J5/J6未指定、既存のGND<NO NET>を除く)
    - 仕様書(日英・Word・PDF)の放熱器の節に基板外形と配置を追記
    [w5500-esp32.kicad_pcb]
2026-09-30 W5500制御基板を縦72×115mmにし、従来基板と同じくW5500を上・ESP32を下に配置
    - 外形を横72mm×縦115mm(従来の手配線基板95×72mmを縦に20mm延長)に変更
    - 左上にW5500モジュール(RJ45は上端側)、その下にJ1(ESP32 DevKitC、USBは下端側)、
    右側にTO-220(U1・U2・Q5)を縦に23mm間隔で並べ放熱器を右端側に、右下に小物部品とJ2/J5/J6の場所
    - W5500モジュール・DevKitC・放熱器・J2/J5/J6の範囲をDwgs.Userに記入(寸法は実物のデータで更新予定)
    - DRC違反0件(未配線・J2/J5/J6未指定・既存のGND<NO NET>を除く)。仕様書の配置説明を更新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
    [w5500-esp32.kicad_pcb]
2026-09-30 W5500制御基板にM3取付穴を追加し、ケース(LAN_PTT.scad)の開口に合わせて配置
    - 取付穴H1〜H4(M3用φ3.2mm、基板専用)をケースのボスと同じ66×109mm間隔(各辺から3mm内側)に追加
    - W5500(RJ45)とDevKitC(USB)を前面・背面の開口位置に合わせて左の列へ、抵抗は左端、
    コンデンサはTO-220の間、トランジスタ・LEDは右下へ移動
    - ケース内壁・開口部・ボス外径(φ8)・各部品の範囲をDwgs.Userに記入
    - DRC違反0件(未配線・J2/J5/J6未指定・既存のGND<NO NET>を除く)。仕様書にケースと取付穴を追記
    [w5500-esp32.kicad_pcb]
2026-09-30 W5500とDevKitCのフットプリントを実物の資料に合わせて修正し、ケースの開口に合わせて配置
    - A1(W5500 Lite): USR-ES1データシートに合わせ、ピン列間隔を15.24→20.32mm、7〜12番をRJ45側から数える順に修正
    (従来は右列の信号が逆につながる配置だった)。新フットプリントW5500_Lite_USR-ES1_2x06_P2.54mm_20.32mm
    - J1(DevKitCソケット): Freenove公式ピン配置図に合わせ、ピンの並びを上下反転(1番5V・21番GNDがUSB-C側)。
    従来は鏡像の並びで、5Vが3V3/GNDのピンにつながる配置だった
    - RJ45をケース前面の角穴(基板x=122)、USB-Cを背面の角丸穴(x=126)に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
    [w5500-esp32.kicad_pcb, w5500-esp32.kicad_sch]
2026-09-30 J2(+12V入力)・J5(12V出力)・J6(PTT出力)を電線はんだ付け用パッドとして配置
    - ケースの丸型コネクタ(WTN-11-1253 8P)へ電線でつなぐ前提で、回路図にフットプリントを指定
    (J2・J5: Connector_Wire SolderWire-1sqmm、J6: SolderWire-0.5sqmm)
    - J2は前面の丸型コネクタ側(右上)、J5・J6は背面の丸型コネクタ側(右下)に配置
    - 「フットプリントが見つからない」3件を解消。DRC違反0件、ERCは変更前と同じ15件
    - 仕様書(日英・Word・PDF)の配置説明を更新、回路図PDF/SVGを再出力
    [w5500-esp32.kicad_pcb, w5500-esp32.kicad_sch]
2026-09-30 W5500制御基板: 丸型コネクタ裏に配線用の空き20mmを確保し4層化
    - 放熱器の列を22mm間隔にして下へ移動、Q1/Q3/D1/D2/J5/J6を背面側の空きの手前へ移動
    - 前面・背面の丸型コネクタ裏の空き範囲をDwgs.Userに記入
    - 4層基板に変更(In1=GND、In2=電源、層設定のみ)
    - 仕様書(日英)をRev.2.5に更新、Word/PDFを再生成
    [w5500-esp32.kicad_pcb]
2026-09-30 W5500制御基板: 放熱器の枠を部品位置に合わせ取付穴位置を反映
    - 放熱器の枠(Dwgs.User)が旧位置に残っていたのを修正し、TO-220のタブ裏にそろえて中央の足に穴の中心を合わせた
    - 放熱器の取付穴(下端から18mm・幅の中央)の印を追加
    - 仕様書(日英)に取付穴位置と部品の取付高さを追記、Word/PDFを再生成
    [w5500-esp32.kicad_pcb]
2026-09-30 W5500制御基板: 自動配線・12V系統強化・外付けLED/XHコネクタ化と総点検の修正
    - 回路図のGND記号の値が空で別ネットになっていたのを修正
    - 内層をGND・+12Vの全面ベタにし、12V出力(/Power)を表裏4mmで配線、残りをFreeroutingで自動配線
    - Q1/Q3を2.54mmピッチのTO-92に、R8を1/2W抵抗用フットプリントに変更
    - D1/D2を外付けにしてJ7/J8で接続、J6/J7/J8をJST XH(B2B-XH-A)に変更
    - C2をTA48033Sデータシートどおり33µF、C1/C3を0.33µFに変更
    - Q3ベースにプルダウンR13(10k)を追加、J1のGNDピン21〜24・40を接続
    - 仕様書・接続一覧(日英)を更新しWord/PDF・回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
    [w5500-esp32.kicad_pcb, w5500-esp32.kicad_sch]
2026-09-30 W5500制御基板: JLCPCB発注データ・実装図を追加、J6/J7を放熱器から離す
    - fabrication/jlcpcb: ガーバー・ドリル(ZIP)、部品表、発注設定のREADMEを追加
    - fabrication/assembly: 部品配置図PDFと3D実装図(放熱器・W5500・ESP32の簡易モデル付き)を追加
    - シルクに端子名・基板名・注文番号位置を追加、はみ出していた部品番号を修正
    - J6/J7をQ5の放熱器から5mm以上離して再配線
    - 仕様書(日英)の配置説明を更新
    [w5500-esp32-B_Cu.gbl, w5500-esp32-B_Mask.gbs, w5500-esp32-B_Silkscreen.gbo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]
2026-09-30 W5500制御基板: J6/J7をW5500とESP32の間へ移動、シルクに設計者名を追加
    - J7(左)・J6(右)をW5500モジュールとESP32ソケットの間に横並びで配置し再配線
    - シルクに「designed by JA6FUF/JH1XHX」を追加
    - 仕様書(日英)の配置説明、JLCPCB発注データ(ガーバーZIP・README)、実装図を更新
    [w5500-esp32-B_Cu.gbl, w5500-esp32-B_Mask.gbs, w5500-esp32-B_Silkscreen.gbo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]
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2026-09-30 W5500制御基板: +5Vを信号線から離し、J1のピン間に配線を通さないよう再配線、J1の12番ピンを未接続に
    - J1の35番ピン(W5500 RST)の配線が+5Vのビアに0.3mmまで近づいていたため、+5V(/+5v0)を
    ネットクラスSupply5V(間隔0.5mm、線幅0.6mm)に分けて再配線した。C1自身の足の間(0.4mm)だけは
    w5500-esp32.kicad_druの例外ルールで0.25mmとする。
    - はんだブリッジを避けるため、J1のピンとピンの間に表裏とも配線禁止領域を置いた
    (同じ+5Vの1番・2番の間を除く)。ピン間を突き抜ける配線は0本。
    - 回路図でJ1の12番ピン(GPIO25)を未接続(×)にし、MC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
    [w5500-esp32.kicad_pcb, w5500-esp32.kicad_sch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]
2026-09-30 W5500制御基板: シルクの版数をRev.1.0にし、仕様書との版数の対応表を追加
    - 基板のシルクを「W5500 PA/PTT Control Rev.2.6」から「Rev.1.0」に変更(最初に製造する基板)。
    ガーバーは表面シルクのみ更新。
    - 仕様書の版数(Rev.2.6)と基板の版数は別番号で管理し、仕様書冒頭に「版数の対応表」を追加
    (仕様書Rev.2.6=基板Rev.1.0)。README・発注用READMEの版数表記も更新。
    [w5500-esp32.kicad_pcb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]
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2026-10-01 W5500制御基板 Rev.1.1: 放熱器の取付ピン用のめっき無し穴を追加
    - 秋月105054(GEC 20PB020)のピン(φ1.4mm、間隔12.5mm、取付面から3.5mm奥)用にφ1.8mmのめっき無し穴をU1・U2・Q5の放熱器ごとに2個(HS1〜HS3)
    - 金属ピンが内層のGND・+12Vベタや配線とショートしないよう、穴の縁から1mm以内は全層で銅箔なし
    - 穴にかかっていたPTT_ONの配線を移動。DRC違反0・未接続0
    - M3穴の高さを基板から19mmに訂正(仕様書・基板の注記)
    - シルクの版数をRev.1.1、仕様書をRev.2.7にし、版数の対応表に追記
    - ガーバー・ドリル・ZIPとREADMEを更新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
    [w5500-esp32-B_Cu.gbl, w5500-esp32-B_Mask.gbs, w5500-esp32-B_Silkscreen.gbo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]
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2026-10-01 ケース: 蓋に盛り上げ文字(+12V IN / PA/PTT Control / +12V OUT)を追加
    [LAN_PTT .scad]
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2026-10-02 W5500制御基板: Shonan_Lite-RasPI5版の最新(基板Rev.1.1・仕様書Rev.2.7)に合わせる
    KiCadデータ(放熱器の取付ピン穴・3Dモデル)、JLCPCB発注データ、実装図・3D画像、
    ケース(RJ45角穴の実測修正・蓋の文字)、接続一覧をPi5版からコピー。
    仕様書は連携部分を残し、Rev.2.7の変更だけを反映してWord/PDFを作り直した。
    [LAN_PTT .scad]
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2026-10-03 W5500制御基板 Rev.1.2: 3.3VレギュレータU1をLM2940T-3.3に変更
    - U1をTA48033SからLM2940T-3.3(TO-220、1=IN・2=GND・3=OUT)に変更。足の並びが違うため
    U1の2番をGND、3番を+3V3_Aにつなぎ替え、裏面の+3V3_Aの配線を引き直してベタを再充填
    - C1をLM2940のデータシートどおり0.47µFに変更(C2の33µFは22µF以上・ESR 0.1〜1Ωの条件を満たす)
    - U1のシンボルをproject_symbolsに追加。DRC違反0・未接続0
    - シルクの版数をRev.1.2、仕様書をRev.2.8にし、版数の対応表・接続一覧を更新
    - ガーバー・ドリル・ZIP・BOM・README、回路図PDF/SVG、実装図PDF、基板レイアウト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
    [w5500-esp32-B_Cu.gbl, w5500-esp32-B_Mask.gbs, w5500-esp32-B_Silkscreen.gbo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]
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2026-10-07 5インチLCD用パネルにDFR0550の位置決めガイドと裏蓋を追加する
    - ベゼルの内側にDFR0550用のL字の位置決めガイドを4隅に付けた(高さ4、すき間0.3)。
    - 1mmのパネルをベゼルと挟んでM3で締める裏蓋を追加した。DFR0550の裏にPi4を載せる
    前提で、USB/LAN・HDMI・音声の開口、Pi4のUSB-Cへ外からまっすぐ差せる筒、
    GPIOの窓と配線スリット、DFR0550の支柱を押さえる柱、通気スリットを付けた。
    - OpenSCADのmodeで出力を切り替える(1 ベゼル、2 裏蓋、3 組み立て確認、
    4 パネルの切り抜き)。ベゼル・裏蓋のSTLとパネル切り抜きのDXFを入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
    [5_in_lcd_case_back_cover.stl, 5_in_lcd_case_front_bezel15.scad, 5_in_lcd_case_front_bezel15.stl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]
2026-10-07 5インチLCD用パネルの裏蓋を浅くし、USB/LANの切り欠きと30mmファンの穴を付ける
    - 裏蓋の深さを26.2から17.7にした(GPIOヘッダーの高さで決める)。背の高いUSB/LANの
    上は背面の板と壁ごと切り欠き、外へ出す。
    - USB-Cは筒をやめ、HDMI・音声の切り欠きを延ばして外からまっすぐ差せるようにした。
    - 背面に30mmファンの穴(ネジ穴φ3.2・ピッチ24、風穴φ25)を付け、通気スリットは
    なくした。
    - 裏蓋からベゼルへのネジをM3×10にした(座ぐりの底を5にした)。
    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
    [5_in_lcd_case_back_cover.stl, 5_in_lcd_case_front_bezel15.scad]
2026-10-07 hardware: Langstone用 audio-ptt-control 基板を追加
    - 回路図に合わせて基板を更新(USBコネクタ削除・J6ピン入替)
    - C2/C3を5mmピッチ(CP_Radial_D8.0mm_P5.00mm)に変更、C2・L1・C3の間隔を確保
    - 部品番号を位置順に振り直し、Freeroutingで全配線をやり直し
    - シルク文字の重なりを修正
    - JLCPCB用ガーバー・ドリル・zipを追加
    [audio-ptt-control-B_Cu.gbl, audio-ptt-control-B_Mask.gbs, audio-ptt-control-B_Paste.gbp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]
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2026-10-16 W5500_PA_PTT_Control: ESP32・W5500はピンソケットを使わず直接はんだ付けする記述に訂正
    仕様書・接続一覧(md/docx/pdf)・JLCPCB用README・BOM.csvを修正。基板は変更なし。
2026-11-11 RX: size the IIO buffer to about one second of samples
    With 0x40000 samples the IIO buffer overflowed while LDPC decoding heavy
    MOD-CODs such as 32APSK on a Pi 5, and reception stopped about three seconds
    after start even though recorded IQ decodes fine. One second of samples
    (rounded up to a power of two, minimum 0x40000) fixes it: 32APSK 5/6 runs
    without errors and 8/9, 9/10 drop to about 3-4 %.
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
